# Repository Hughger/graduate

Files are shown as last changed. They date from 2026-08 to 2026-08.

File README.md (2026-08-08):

# FLOOD Accelerator — Graduate Workspace

`graduate` 是从现有 FLOOD 工作目录中提取的加速器维护副本，建立于 2026-08-07。原文件均保留在原位；这里不包含原仓库的 Git 历史、完整 SDK 工具链、IDE/综合缓存或历史压缩包。

> 当前内容来自带有本地提交和未提交改动的工作树，不是正式 release。首次提交或对外分发前，请先阅读 [SOURCE_STATE.md](./SOURCE_STATE.md)。

## 当前研究方向（2026-08-08）

本工作区当前以 **Stable Diffusion 1.5 U-Net ResNetBlock 的 AXKU15 FPGA 原型**为研究主线，复用 FLOOD 的 INT8 计算结构，重点研究片上驻留、算子融合和双缓冲数据流。目标不是一次性硬化完整 SD，而是先完成可验证、可综合、可上板的真实 ResNetBlock 加速器。

- 正式设计规格：[SD1.5 ResNetBlock 加速器设计](./docs/superpowers/specs/2026-08-08-sd15-resnetblock-accelerator-design.md)
- 实施计划：[SD1.5 ResNetBlock AXKU15 加速器实施计划](./docs/superpowers/plans/2026-08-08-sd15-resnetblock-accelerator-implementation.md)
- 板卡用户手册：[AXKU15 V1.2 用户手册](./AXKU15_V1.2_UG.pdf)
- 板级原理图：[AXKU15 扩展板原理图](./01_原理图PCB结构图等硬件资料/AXKU15原理图V1.0.pdf)、[ACKU15 核心板原理图](./01_原理图PCB结构图等硬件资料/ACKU15核心板.pdf)

现有 CNN Demo、MacMachine 和六周执行计划继续保留，作为 FLOOD 基线、接口审计和回归验证资料；其历史参数与任务优先级不覆盖上述正式设计规格。

## 目录

```text
graduate/
├─ accelerator/                  # FLOOD 加速器主体，保留原工程相对结构
│  ├─ src/                       # Chisel/Scala、Python、C 辅助代码与测试
│  ├─ rtl/                       # E203/FLOOD RTL
│  ├─ c/                         # APB/AXI/UART 测试与 CNN 示例
│  ├─ tb/                        # Verilog testbench 与测试向量
│  ├─ tests/                     # 单元/公共测试框架
│  ├─ tools/                     # 量化与数据生成工具
│  ├─ vsim/                      # 仿真入口
│  ├─ fpga/                      # FPGA 源码、约束和构建脚本
│  ├─ doc/                       # Sphinx/参考文档
│  └─ pics/                      # README/文档图片
├─ integrations/
│  ├─ chip-test-vivado/          # 精简后的 Vivado 芯片测试工程
│  ├─ hbird-sdk-overlay/         # 需要应用到指定 hbird-sdk 的本地定制层
│  └─ board-interface/           # 引脚、连接器、转接板和 PCB 约束输入
├─ validation/
│  ├─ plans/                     # HPCA/PyTorchSim 测试方案与结果清单
│  └─ netlists/                  # Fan-out 网络表
├─ docs/superpowers/{specs,plans}/ # 正式设计规格与实施计划
├─ 01_原理图PCB结构图等硬件资料/ # AXKU15/ACKU15 原理图与结构资料
└─ planning/                     # 历史计划与后续任务拆分
```

## 主要入口

- 当前正式设计规格：[docs/superpowers/specs/2026-08-08-sd15-resnetblock-accelerator-design.md](./docs/superpowers/specs/2026-08-08-sd15-resnetblock-accelerator-design.md)
- 当前实施计划：[docs/superpowers/plans/2026-08-08-sd15-resnetblock-accelerator-implementation.md](./docs/superpowers/plans/2026-08-08-sd15-resnetblock-accelerator-implementation.md)
- 加速器说明：[accelerator/README.md](./accelerator/README.md)
- Chisel/Scala 主源码：[accelerator/src/main](./accelerator/src/main/)
- RTL：[accelerator/rtl/e203](./accelerator/rtl/e203/)
- AXI 软件测试：[accelerator/c/axi_test](./accelerator/c/axi_test/)
- 仿真入口：[accelerator/vsim/README.md](./accelerator/vsim/README.md)
- FPGA 工程：[accelerator/fpga/README.md](./accelerator/fpga/README.md)
- AXKU15 集成：[accelerator/fpga/AXKU15](./accelerator/fpga/AXKU15/)
- Vivado 芯片测试工程：[integrations/chip-test-vivado/system_chip_test.xpr](./integrations/chip-test-vivado/system_chip_test.xpr)
- SDK 覆盖层：[integrations/hbird-sdk-overlay](./integrations/hbird-sdk-overlay/)
- PyTorchSim 测试执行方案：[validation/plans/FLOOD_PyTorchSim测试执行方案.md](./validation/plans/FLOOD_PyTorchSim测试执行方案.md)

## 使用方式

### 1. 加速器 RTL/Chisel

进入 `accelerator`，先阅读原工程 README、`build.sbt`、`e203_core.core` 和 `e203_soc.core`。本副本保留了当前工作树中的 Scala、RTL、C、测试和工具文件，但没有复制原来的 `.git` 和 SBT/IDE 缓存。

### 2. 软件与 SDK

完整 hbird-sdk 未复制。请准备远端 `https://gitee.com/riscv-mcu/hbird-sdk.git` 在提交 `321ecb29f64197748a4a4bdb9f42c0961cb8145b` 附近的工作树，再审查并应用 `integrations/hbird-sdk-overlay/hbird-sdk` 中的覆盖文件。覆盖层包含当前本地修改，不能无审查覆盖到其他 SDK 版本。

### 3. FPGA/Vivado

`accelerator/fpga` 保留 FPGA 源码、约束和脚本，但删除了两个约 26.1 MB 的预生成 MCS。`integrations/chip-test-vivado` 保留 `.xpr`、约束、XCI、RTL、C 和初始化数据，未复制 Vivado cache/runs、可执行文件、DCP 和结果文本。工程原目录显示使用过 Vivado 2022.2；在其他版本打开时先备份并检查升级提示。

### 4. 验证

`validation/plans` 是测试目标和执行流程，`validation/netlists` 是板级网络数据。新增实验结果时建议按“日期—配置—提交—结果”命名，并记录对应 RTL、软件、bitstream 和模型版本。

## 维护规则

1. 将 `graduate` 视为独立维护副本；不要假设它会与原目录自动同步。
2. 首次建立 Git 历史前，先确认 `SOURCE_STATE.md` 中列出的本地改动均已纳入或明确放弃。
3. 不提交工具链、虚拟机、Vivado cache/runs、SBT target、波形和临时压缩包。
4. 生成物放入独立 `artifacts/<date-or-revision>/`，并附提交号、工具版本和校验值。
5. SDK 修改优先以 overlay/patch 维护，不再复制整套 3.47 GiB 工具链。
6. 对外发布时另建 release 包；本目录本身不是 PCB/SMT 或 FPGA 生产交付包。

## 本次未复制

- 所有 `.git` 历史及 Git 对象。
- 完整 `hybird_sdk`/`NUCLEI_TOOL_ROOT`。
- Vivado `.Xil`、cache、runs、gen、hw、sim、IP user files 和既有 bitstream。
- `fpga.zip`、`src/main/scala.zip`、根目录工程压缩包及虚拟机/IDE 环境。
- 两个 `prebuilt_mcs/system.mcs`。
- HPCA 论文调研模板、旧版周任务、旧执行计划和与加速器维护无直接关系的历史材料。

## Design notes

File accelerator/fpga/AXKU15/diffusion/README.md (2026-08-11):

# AXKU15 board flow

This folder separates two bring-up stages deliberately:

1. `rtl/axku15_diffusion_bringup.v` + `constrs/axku15_bringup.xdc` creates a
   no-DDR smoke bitstream.  It proves the selected XCKU15P part, JTAG download,
   200 MHz system clock (`G12/G11`), reset and four LEDs before a large design
   is introduced.
2. `scripts/extract_ddr4_pins.py` emits the DDR4 package-pin XDC from the
   checked-in AXKU15 manual.  It captures the complete 80-bit memory interface
   without hand-copying pins.  A future Vivado DDR4 MIG must provide the same
   port names and own IOSTANDARD/termination settings.

## Build the smoke bitstream

From this directory, run:

```powershell
vivado -mode batch -source scripts/build_bringup.tcl
```

The bitstream is written below `build/bringup_nonproject/`.  Program it through
Vivado Hardware Manager.  LED2 stays on after configuration; LED1 and LED4
blink, and LED3 reflects release of `KEY1` reset.

## Generate and verify DDR4 pin constraints

```powershell
python scripts/extract_ddr4_pins.py --output constrs/axku15_ddr4_pins.xdc
python -m unittest discover -s tests -v
```

The script requires exactly 80 distinct DQ pins and emits all DQ, DM/DBI,
DQS, address, bank and command pins.  It intentionally does **not** generate a
MIG `.xci`: MIG electrical settings and board timing must be created and
validated with the installed Vivado version before synthesis.  The documented
DDR4 reference clock is `AR32/AT32`; it is emitted as `ddr4_ref_clk_p/n` and is separate from the bring-up logic clock at `G12/G11`.

## Verified implementation evidence

The bring-up flow was run with Vivado 2024.2 on this repository revision. It completed synthesis, implementation and bitstream generation for `xcku15p-ffve1517-2-i` with zero DRC errors. At a 200 MHz constraint, the post-route setup WNS was **4.220 ns** (TNS 0.000 ns); the generated bitstream was 36,343,241 bytes. These numbers apply only to the small clock/LED smoke top, not to the future DDR4/MIG accelerator implementation. See [DDR4 MIG compatibility](docs/ddr4_mig_compatibility.md) before using the 64-bit candidate constraints; an 80-bit AXKU15 MIG remains unclosed. See also [the official DDR4 demo assessment](docs/OFFICIAL_DDR4_DEMO_ASSESSMENT.md): its vendor bitstream is a useful 64-bit baseline, not proof of 80-bit closure.
## Actual accelerator RTL validation

`GenerateDiffusionAccelTopVerilog` emits the real `DiffusionAccelTop` rather
than the lightweight `DiffusionContractTop`. The resulting Verilog keeps the
AXI-Lite, DMA and MIG application-port seams and is intended for the board
wrapper once the physical DDR4 controller is qualified.

A bounded Vivado 2024.2 `synth_design -rtl` check on
`xcku15p-ffve1517-2-i` completed RTL elaboration in 7 minutes 08 seconds at a
5,256 MB peak memory footprint, then entered RTL optimization. It was stopped
at the 10-minute safety limit, so it is evidence of successful RTL parsing and
hierarchy elaboration only—not a completed synthesis, timing result or resource
closure. The corresponding full OOC synthesis reached RTL component statistics
but did not finish within a 30-minute limit. Use the checked-in scripts to
repeat those bounded checks; do not claim AXKU15 implementation closure from
these partial results.

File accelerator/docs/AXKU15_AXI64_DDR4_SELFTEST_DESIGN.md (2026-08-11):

# AXKU15 AXI64 DDR4 self-test harness design

## Objective

Create a board-oriented harness that tests the newly integrated 512-bit to
64-bit AXI bridge through the official DDR4 core without modifying the vendor
demo.  The harness runs autonomously after DDR4 calibration: it writes one
known 512-bit word, reads the same address back, and exposes calibration,
active, pass, and fail status for LEDs or external observation.

This is a DDR4 transport-validation increment, not a Stable Diffusion inference
demo.  It deliberately avoids pretending that the official demo has a host
control plane for the full accelerator.

## Architecture

1. `Axi64DdrSelfTest` is a small Chisel module.  It instantiates the existing
   `MigAppToAxi64Bridge`, waits for `calibrated`, issues one 512-bit write,
   waits for an OKAY B response, issues the matching 512-bit read, and compares
   all 512 bits.
2. It has no external request input.  The fixed address is 64-byte aligned and
   the fixed data contains eight distinct 64-bit words, so both AXI burst order
   and bridge read reassembly are exercised.
3. `GenerateAxi64DdrSelfTestVerilog` emits that module independently of
   `DiffusionAccelTop`.
4. `axku15_axi64_ddr4_selftest.v` is a thin SystemVerilog wrapper.  It
   instantiates the unmodified vendor `ddr4_core` and the generated self-test,
   maps the complete AXI channels, and maps statuses to the existing four LED
   pins: `led[0]=calibrated`, `led[1]=active`, `led[2]=passed`,
   `led[3]=failed`.
5. A parameterized non-project Vivado Tcl flow reads the user-selected vendor
   XCI and its matching XDC by path; it writes outputs only under this
   repository's `build/` directory.

## Reset and calibration rules

- The harness clock is `c0_ddr4_ui_clk`; reset is asserted by
  `c0_ddr4_ui_clk_sync_rst` or deasserted `c0_ddr4_aresetn`.
- `c0_init_calib_complete` is an input to the harness state machine.  No AXI
  request is issued until it is high.
- A non-OKAY B/R response or a 512-bit read mismatch sets sticky `failed`.
- `passed` and `failed` are mutually exclusive and remain asserted until reset.
- The vendor core's `c0_alert_n` is exposed by the wrapper but is not treated as
  a substitute for an AXI data-integrity result.

## Source ownership and constraints

The wrapper never edits, copies into place, or regenerates the official demo's
XCI/RTL/XDC.  The build command takes absolute or relative paths to those
artifacts.  The existing 64/80-bit and DRAM-part mismatch remains a physical
validation risk; a successful tool build alone is not a calibration or memory
test result.

## Acceptance tests

1. Unit simulation demonstrates no request before `calibrated`, eight ordered
   write beats, eight ordered read beats, and sticky pass after a matching read.
2. Separate simulations demonstrate sticky fail for a read mismatch and an
   AXI error response.
3. The self-test Verilog generator exits successfully and its output contains
   all AXI64 channel groups plus status outputs.
4. The wrapper is linted/elaborated only when the user supplies a matching
   vendor XCI/XDC.  A successful bitstream is documented as implementation
   evidence, while physical programming/calibration is a separately authorized
   lab action.

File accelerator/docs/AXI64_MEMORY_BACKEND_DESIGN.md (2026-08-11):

# AXI64 memory-backend integration design

## Goal

Allow the existing diffusion top to use either its current 512-bit MIG
application-port backend or the new 64-bit AXI4 bridge.  The default generated
top must preserve the current MIG seam and behavior.  A second generated top
must expose AXI64 so it can be connected to the official AXKU15 DDR4 demo in a
later Verilog wrapper.

## Confirmed interface boundary

`DiffusionAccelTop` currently connects `MigAppRequestArbiter` to a single
`MigAppTransfer`, then exposes the transfer's raw `MigAppPort`.  In contrast,
`MigAppToAxi64Bridge` consumes the request/response/done side of that
connection.  Therefore the bridge must replace `MigAppTransfer` *inside* the
diffusion top; placing it after `io.mig` would mismatch protocols and duplicate
serialization.

The official demo supplies a 64-bit AXI4 slave with `AW`, `W`, `B`, `AR`, and
`R`, a UI clock/reset pair (`c0_ddr4_ui_clk`, `c0_ddr4_aresetn`), and
`c0_init_calib_complete`.

## Alternatives

1. Add a raw `MigAppPort` to AXI converter outside the top.  It would retain
   the current serializer, but duplicates the already tested request-level
   bridge and creates two incompatible conversion boundaries.  Not selected.
2. Fork the complete diffusion top for the AXI path.  This gives a direct
   interface but would duplicate a large evolving data path.  Not selected.
3. Select the backend at `DiffusionAccelTop` construction.  Both backend
   choices share one `MigAppRequestArbiter`; the original is the default and
   the alternate instantiates `MigAppToAxi64Bridge`.  This is selected.

## Selected architecture

`DiffusionAccelTop` receives a constructor parameter:

```scala
class DiffusionAccelTop(
    resultDepth: Int = 128,
    memoryBackend: DiffusionMemoryBackend = DiffusionMemoryBackend.MigApp
) extends Module
```

`DiffusionMemoryBackend` has exactly `MigApp` and `Axi64` values.  The IO keeps
both named seams (`mig` and `axi64`) so either generated RTL variant has stable
port names.  Only the selected backend is live:

- `MigApp`: preserve the current `MigAppTransfer` connections and tie AXI64
  master outputs inactive; AXI64 return channels are ignored.
- `Axi64`: connect the arbiter's request/response/done interface directly to
  `MigAppToAxi64Bridge`; tie MIG command outputs inactive and ignore its return
  inputs.

The performance monitor's memory-stall term is selected with the backend:
MIG uses app ready signals; AXI64 uses any active AXI channel with its ready
low, including B/R response waiting.  The existing one-cycle-per-cycle stall
definition remains unchanged.

`GenerateDiffusionAccelTopVerilog` continues to emit the default MIG variant.
`GenerateDiffusionAccelAxi64TopVerilog` emits the alternate variant to
`target/generated/diffusion-accel-axi64-top`.

## Board-wrapper boundary

The follow-on SystemVerilog wrapper will instantiate the vendor `ddr4_core`
unchanged and an AXI64 generated top.  It uses the MIG UI clock as the
accelerator clock and asserts accelerator reset until both `c0_ddr4_aresetn`
and `c0_init_calib_complete` are high.  The wrapper maps only the complete
official AXI4 channel fields, adding fixed AXI fields (`burst=INCR`, cache/prot/
qos/user zero) that are not modelled by the Chisel bridge.

This design does not copy vendor files, regenerate an XCI, connect physical
DDR pins, or claim DDR4 calibration.  Those activities occur only after the
alternate top passes its simulation and generation tests.

## Acceptance tests

1. Existing `DiffusionAccelTop` tests and default Verilog generation preserve
   MIG behavior.
2. An AXI64-backend top test submits a request through the existing external
   memory port and observes the eight-beat bridge transaction.
3. AXI64-backend tests prove that MIG outputs remain inactive and that an AXI
   response drives the existing memory response/done path.
4. The AXI64 generated RTL contains the `axi64_aw`, `axi64_w`, `axi64_b`,
   `axi64_ar`, and `axi64_r` signals.
5. No test, source file, XCI, or constraint is written under the user-provided
   official demo directory.

## Verification record

On 2026-08-11, `DiffusionAccelTopAxi64Spec` verified that the default top still
uses MIG with AXI64 idle and that the AXI64 variant keeps MIG commands inactive
while reassembling an eight-beat read into the existing memory response.  The
selected default-top, AXI64-top, and bridge test scope passed 10/10 cases.

Both `GenerateDiffusionAccelTopVerilog` and
`GenerateDiffusionAccelAxi64TopVerilog` completed successfully.  The latter
emits all five AXI64 channel groups (`axi64_aw`, `axi64_w`, `axi64_b`,
`axi64_ar`, and `axi64_r`).  No vendor source, XCI, constraint, physical pin,
or board-calibration claim is included in this result.

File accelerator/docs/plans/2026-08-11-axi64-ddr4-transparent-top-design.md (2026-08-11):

# AXKU15 AXI64 DDR4 Transparent Accelerator Top Design

**Date:** 2026-08-11  
**Status:** Approved design; implementation deferred pending accelerator verification

## Goal

Define a project-owned AXKU15 top-level integration that will connect the
`DiffusionAccelTop` AXI64 memory backend to the already validated, project-owned
copy of the official DDR4 controller IP.  This milestone proves that the
accelerator's 64-bit AXI4 memory boundary can be elaborated with the board DDR4
controller without modifying the official demo or its source IP.  The user has
chosen to defer this integration until the accelerator design and verification
work is complete.

## Deferred implementation scope

The integration adds:

- a Chisel generation entry point that instantiates
  `DiffusionAccelTop(memoryBackend = DiffusionMemoryBackend.Axi64)`;
- a transparent Verilog board wrapper that instantiates that generated module
  and `ddr4_core`;
- a Vivado RTL-elaboration Tcl script that attaches the project-owned DDR4 DCP
  and generated DDR4 constraints explicitly; and
- build and design documentation.

The wrapper connects the accelerator AXI4 master channels directly to
`ddr4_core`'s 64-bit AXI4 slave interface:

| Accelerator channel | DDR4 IP channel |
| --- | --- |
| AW | `c0_ddr4_s_axi_aw*` |
| W | `c0_ddr4_s_axi_w*` |
| B | `c0_ddr4_s_axi_b*` |
| AR | `c0_ddr4_s_axi_ar*` |
| R | `c0_ddr4_s_axi_r*` |

All accelerator controls and data-plane interfaces that do not belong to DDR4
remain wrapper top-level ports.  They are deliberately neither tied off nor
replaced by an autonomous controller.

## Clock and reset

`c0_ddr4_ui_clk` clocks the generated accelerator.  The accelerator reset is
asserted while the DDR4 UI reset is asserted or its active-low UI reset output
is inactive.  `c0_init_calib_complete` is exported as an observation signal;
the integration does not claim memory is usable before calibration completes.

The board-facing DDR4 clock, reset, pin signals, and board XDC remain those of
the official AXKU15 DDR4 demo.  The integration uses the repository-owned
upgraded controller copy and its matching DCP/XDC artifacts.

## Deferred validation

The implementation must:

1. pass the focused Scala/Chisel tests for the AXI64 backend;
2. generate the AXI64-backend accelerator Verilog;
3. complete Vivado `synth_design -rtl` with the project-owned controller DCP
   attached explicitly; and
4. leave the official demo and official source IP unmodified.

The existing autonomous DDR4 self-test remains the physical-link baseline.  It
is not replaced by this structural integration test.

## Explicit exclusions

This milestone does not add UART, PCIe, a soft processor, or another host
control plane.  It does not execute a complete SD1.5 workload, run placement or
routing, generate a bitstream, or program the FPGA.

The official demo's 64-bit DDR4 configuration is accepted as the current
project baseline.  The separately observed 64/80-bit board-document mismatch
is deferred to hardware-validation and thesis-limitations work; acceptance of
this baseline is not evidence that 80-bit hardware operation has been proven.

## Prerequisite and follow-on work

Before implementation of this wrapper, the project will complete functional
design and simulation-based verification of one SD1.5 ResNetBlock, including
its scheduler, convolution, GroupNorm, residual path, DMA, and AXI64
behavioural-memory interactions.  The resulting verification evidence becomes
the prerequisite for restoring this board-integration milestone.

Host control, SD1.5 workload submission, and implementation/timing/bitstream
work are separate follow-on milestones.  Keeping them separate preserves this
milestone as a narrow, reproducible accelerator-to-DDR4 integration boundary.

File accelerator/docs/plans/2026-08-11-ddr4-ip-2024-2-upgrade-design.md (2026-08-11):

# AXKU15 DDR4 IP 2024.2 upgrade-copy design

## Objective

Create a project-owned Vivado 2024.2-compatible copy of the official AXKU15
DDR4 IP so the AXI64 DDR4 self-test can be built reproducibly without editing
the vendor demo.

## Scope and ownership

- Copy, never modify, the official `ddr4_core.xci` and only the generated
  artifacts Vivado requires for the project copy.
- Keep the vendor demo directory read-only throughout the workflow.
- Place the owned IP and a manifest under `accelerator/fpga/AXKU15/diffusion`.
- Update the self-test Tcl flow to consume only the owned 2024.2 XCI.
- Do not run implementation, generate a bitstream, or program the board in
  this slice.

## Architecture

The existing `axku15_axi64_ddr4_selftest` wrapper remains the only RTL client.
It exposes the self-test's 64-bit AXI4 master directly to the copied DDR4 IP.
The copied IP preserves the official 64-bit DQ and eight-DQS interface plus
the existing 64-bit AXI4 interface. Vivado 2024.2 upgrades and generates the
project copy; its upgraded XCI becomes the build input. The official 2022.2
XCI and DCP are provenance artifacts only and are not read by the upgraded
build path.

## Validation and failure handling

The build performs RTL elaboration and a synthesis pass only. It fails if the
copied XCI remains locked, if the wrapper/IP interfaces do not elaborate, or
if synthesis reports errors or critical warnings. The build report records the
source and generated tool versions, part, IP configuration, and generated
file hashes so the copy is auditable.

The known physical-interface discrepancy is deliberately not hidden: the
official core has `c0_ddr4_dq[63:0]` and eight DQS pairs, while the currently
available board constraint references 80 DQ bits and ten DQS pairs. Therefore
implementation and programming remain prohibited until the AXKU15 schematic
and DDR4 topology are reconciled.

## Acceptance criteria

1. The official demo directory is unchanged.
2. Vivado 2024.2 reports the project-owned IP as unlocked after upgrade.
3. The AXI64 DDR4 self-test elaborates and synthesizes against the owned IP
   without errors or critical warnings.
4. A checked-in manifest makes the source, version, configuration, and hashes
   of the copied IP explicit.
5. No bitstream is written and no board is programmed.
## Execution update

The project-owned copy was upgraded by Vivado 2024.2 from DDR4 IP revision 17
to revision 24. Its local OOC DCP was generated with `synth_ip`; the generated
files are ignored while the XCI and manifest remain versioned. The official
demo directory was not modified.

Vivado 2024.2 stalled when the non-project self-test flow used `read_ip` to
automatically attach the upgraded DCP. The accepted elaboration-only path now
requires the co-located manifest, DCP, and generated IP XDC, explicitly
attaches the DCP to `u_ddr4_core/inst`, and reads the IP XDC after the board
XDC. It has completed RTL elaboration with zero critical warnings and zero
errors. This does not authorize implementation, bitstream generation, or board
programming, and it does not resolve the physical 64/80-bit mismatch.

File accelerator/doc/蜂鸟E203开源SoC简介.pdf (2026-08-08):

# 蜂鸟 E203 开源 SoC 介绍

蜂鸟 E203 开源 SoC 简介

2

## Content

3

4

## Tables

5

## Figures

- 6 -

## 1 Preface

## 1.1 Revision History

Date | Version | Author | Change Summary
Oct 20,2018 | 1.0 | Bob Hu | Initial Version

## 1.2 Reference Documentation

https://github.com/SI-RISCV/e200_opensource/tree/master/doc/SiFive-E300-platform-reference-manual-v1.0.1. pdf
https://github.com/SI-RISCV/e200_opensource/tree/master/doc/SiFive-E310-G000-manual-v1.0.1.pdfhttps://github.com/SI-RISCV/e200_opensource/tree/master/doc/SiFive-E3-C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 mentation.pdf
中文书籍《手把手教你设计 CPU：RISC-V 处理器篇》
中文书籍《RISC-V 架构与嵌入式开发快速入门》

- 7 -

## 2 总体介绍

本文介绍全开源的蜂鸟 E203 RISC-V 处理器核以及配套开源 SoC，为了方便描述，本文档中将此 SoC 简称为“蜂鸟 E203 SoC”。
注意：
■ | 本文档对蜂鸟 E203 内核以及 RISC-V 指令集架构的介绍尚不够详细，在中文书籍《手把手教你设
| 计 CPU：RISC-V 处理器篇》或者《RISC-V 架构与嵌入式开发快速入门》中对其进行深入浅出地系
| 统的讲解，感兴趣的用户可以自行搜索书籍。
■ | 本文档对 SoC 的各外设的介绍尚不够详细，在中文书籍《RISC-V 架构与嵌入式开发快速入门》
| 中进行了深入浅出的系统讲解。感兴趣的用户可以自行搜索此书。

注意：
■ | 本 SoC 的代码全开源，有关其代码结构的详情，请参见《蜂鸟 E203 快速上手介绍》。
■ | 本开源 SoC 主要面向教育教学和爱好者领域，源代码全部开放。理论上可以用于商业目的，但
| 是不保证其商用质量和服务。
■ | The main purpose of this open-sourced core is to be used by students/university/research and entry-level-beginners, hence, the commercial quality (bug-free) and service of this core is not not not warranted!!!

## 2.1 总体特性

本 SoC 总体特性如下：
■ | 使用全开源的蜂鸟 E203 处理器核，此处理器核包括如下特性：
| 超低功耗 2 级流水线处理器核
| 64KB ITCM，64KB DTCM
| 有关蜂鸟 E203 的更多信息参见第 3 章
■ | 为了尽量的共享当前 RISC-V 的软件生态，将尽可能的复用 SiFive 公司开源的 Freedom 310（HiFive1
| 开发板所使用）SoC，包括：
| 对其已有的 IP 进行复用兼容
| 对其总线地址分配进行兼容
■ | 在兼容 Freedom 310 SoC 的基础上，增加如下 IP，使其 SoC 功能更加丰富：
| I2C Master

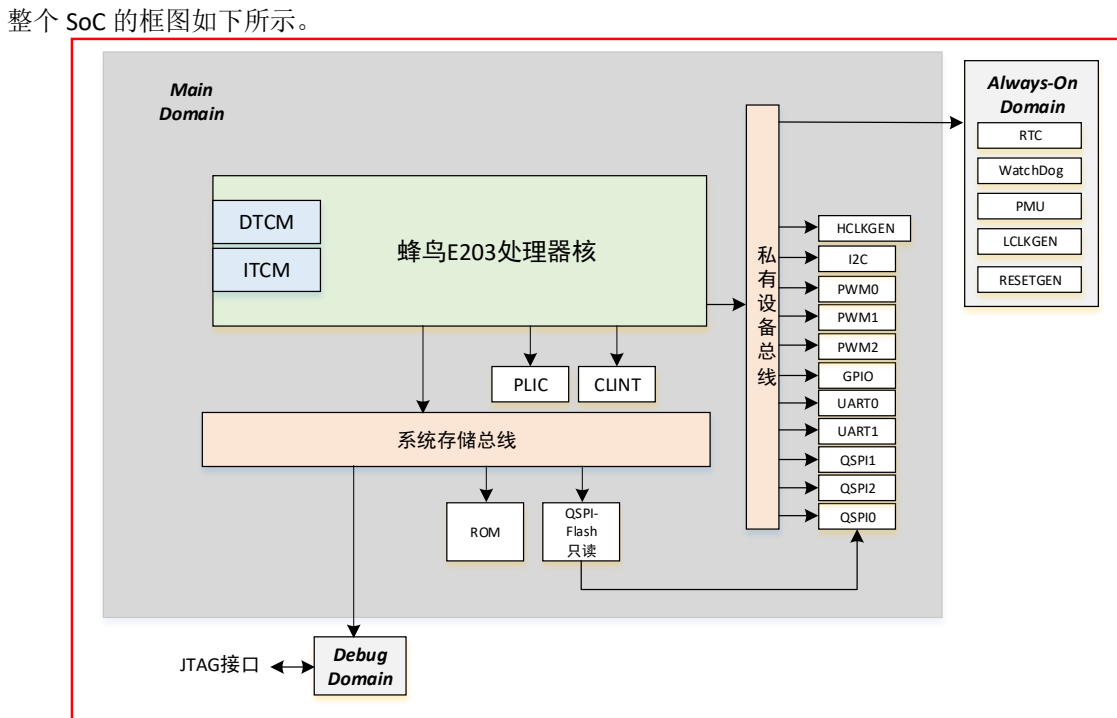
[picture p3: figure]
整个 SoC 的框图如下所示。; 系统存储总线; ROM; Debug Domain; 蜂鸟E203处理器核; DTCM; ITCM; QSPI- Flash 只读; GPIO; QSPI0; UART0; UART1; QSPI1; QSPI2; PWM2; PWM1; PWM0; Always-On Domain; PLIC; CLINT; JTAG接口; Main Domain; RTC; WatchDog; PMU; HCLKGEN; LCLKGEN; RESETGEN

- 8 -

## 2.2 SoC 整体框图

Figure 2-1 SoC 整体框图

上图中除了蜂鸟 E203 处理器核和总线之外，其他的主要外部设备 IP 模块均复用来自 Freedom E310 SoC 平台。图中用红色线框包含的模块为开源 Freedom E310 SoC 平台所不具备的（因为其开源的是 FPGA 平台源代码），需要我们自己设计添加，包括：

■ | I2C Master：使用开源的 I2C Master IP。
■ | HCLKGEN：用于使用 PLL 生成高速时钟（用于 Main Domain）。
■ | LCLKGEN：生成低速时钟（用于 Always-onDomain）。
■ | RESETGEN：用于为 SoC 生成复位逻辑。

## 2.3 总线地址分配

本 SoC 的总线地址分配如下表所示。注意，下表中：

■ | 普通部分为与 Freedom E310 兼容且已经存在的 IP 及其地址分配。
■ | 绿色高亮部分为本项目自研 RISC-V 核特有的部分。

- 9 -
■ | 黄色高亮部分为本项目新定义的系统 IP 及其地址分配区间。
■ | 蓝色高亮部分为 Freedom E310 芯片中存在的 IP 及其地址分配，但是目前本 SoC 中还没有的 IP。

Table 2-1 SoC 地址分配表

总线分组 | 组件 | 地址区间 | 描述
Core 直属 | CLINT | 0x0200_0000 ~ 0x0200_FFFF | Core Local Interrupt Controller 模块寄存器地址 区间
| PLIC | 0x0C00_0000 ~ 0x0CFF_FFFF | Platform Level Interrupt Controller 模块寄存器地址 区间
| ITCM | 0x8000_0000 ~ 0x8001_FFFF | ITCM 地址区间
| DTCM | 0x9000_0000 ~ 0x8001_FFFF | DTCM 地址区间
系统存储总线接口 | Debug Module | 0x0000_0000 ~ 0x0000_0FFF | 注意：Debug Module 主要 用于调试器使用，普通软件 程序不应该使用此区间
| ROM | 0x0000_1000 ~ 0x0000_1FFF | 注意：开源的 E203 项目由 于是 FPGA 原型，因此 Mask-ROM 代码为一行为 模型。 在本 SoC 中考虑将其固化 成为逻辑，而不是真的使用 ROM IP。
| Off-Chip QSPI0 Flash Read | 0x2000_0000 ~ 0x3FFF_FFFF | 外部 SPI Flash 只读地址区 间。 有关 SPI Flash，详见后文介 绍。
私有设备总线接口 （总区间为 0x1000_0000 ~ 0x1FFF_FFFF） | Always-On | 0x1000_0000 ~ 0x1000_7FFF | Always-on 模块包含 PMU，RTC，WatchDog， LCLKGEN。
| HCLKGEN | 0x1000_8000 ~ 0x1000_8FFF | 高速时钟生成模块

- 10 -
GPIO | 0x1001_2000 ~ 0x1001_2FFF | GPIO 地址区间。

有关 GPIO，详见后文介绍。

UART0 | 0x1001_3000 ~ 0x1001_3FFF | 第一个 UART 模块地址区 间。有关 UART，详见后文 介绍。
QSPI0 | 0x1001_4000 ~ 0x1001_4FFF | 第一个 QSPI 模块地址区 间。有关 SPI，详见后文介 绍。
PWM0 | 0x1001_5000 ~ 0x1001_5FFF | 第一个 PWM 模块地址区 间。有关 PWM，详见后文 介绍。
UART1 | 0x1002_3000 ~ 0x1002_3FFF | 第二个 UART 模块地址区 间。
QSPI1 | 0x1002_4000 ~ 0x1002_4FFF | 第二个 QSPI 模块地址区 间。
PWM1 | 0x1002_5000 ~ 0x1002_5FFF | 第二个 PWM 模块地址区 间。
QSPI2 | 0x1003_4000 ~ 0x1003_4FFF | 第三个 QSPI 模块地址区 间。
PWM2 | 0x1003_5000 ~ 0x1003_5FFF | 第三个 PWM 模块地址区 间。
I2C Master | 0x1004_2000 ~ 0x1004_2FFF | IC2 Master
其他地址区间 | 上表中未使用到的地址区间，则均为写忽略，读返回 0

- 11 -

## 3 RISC-V 核介绍

注意：
■ | 本文档对蜂鸟 E203 处理器内核以及 RISC-V 指令集架构的介绍尚不够详细，在中文书籍《手把手
| 教你设计 CPU：RISC-V 处理器篇》中对其进行深入浅出地系统的讲解。感兴趣的用户可以自行
| 搜索此书。

## 3.1 处理器核简介

本 SoC 使用的处理器核为开源的蜂鸟 E203 RISC-V 处理器核。

蜂鸟 E203 内核的特性简介如下：

■ | E203 内核采用 2 级流水线结构，通过一流的处理器架构设计，该 CPU 核的功耗与面积均优于同
| 级 ARM Cortex-M 核，实现业界最高的能效比与最低的成本。
■ | E203 内核能够运行 RISC-V 指令集，支持 RV32IMAC 等指令子集的配置组合，仅支持机器模式
| （Machine Mode Only）。
■ | E203 内核提供标准的 JTAG 调试接口，以及成熟的软件调试工具。
■ | E203 内核提供成熟的 GCC 编译工具链。
参见《手把手教你设计 CPU——RISC-V 处理器篇》了解开源蜂鸟 E203 的详情。

## 3.2 处理器核中断

蜂鸟 E203 内核的中断分为三种类型：

■ | 计时器中断，由 CLINT 模块产生。
■ | 软件中断，由 CLINT 模块产生。
■ | 外部中断，由 PLIC 管理产生。
对于 RISC-V 架构中断的详细介绍，本文档在此不展开赘述，用户参见中文书籍《手把手教你设计 CPU：RISC-V 处理器篇》第 13 章中对其进行深入浅出地系统的讲解。

### 3.2.1 CLINT

本文在此仅对 CLINT 进行中文简述。

有关 CLINT 的详细，用户可以选择中文书籍《手把手教你设计 CPU：RISC-V 处理器篇》第 13 章中 对其进行深入浅出地系统的讲解。

- 12 -

CLINT 全称为 Core Local Interrupts Controller。CLINT 是一个存储器地址映射（Memory Address Mapped）的模块，挂载在处理器核为其实现的专用总线接口上，在蜂鸟 E203 内核配套的 SoC 中其寄存 器的地址区间如下表所示。CLINT 的寄存器只支持 size 为 32 位的读写访问。

Table 3-1 CLINT 寄存器的 Memory Mapped Address

地址 | 寄存器名称 | 功能描述
0x0200_0000 | msip | 生成软件中断
0x0200_4000 | mtimecmp | 配置计时器的比较值
0x0200_BFF8 | mtime | 反映计时器的值

CLINT 可以用于生成软件中断，其要点如下：

■ | CLINT 中实现了一个 32 位的 msip 寄存器，该寄存器只有最低位为有效位，该寄存器有效位直
| 接作为软件中断（Software Interrupt）信号通给处理器核。
■ | 当软件写 1 至 msip 寄存器触发了软件中断之后，前文中介绍的 CSR 寄存器 mip 中的 MSIP 域便
| 会置高指示当前中断 pending 状态。
■ | 软件可通过写 0 至 msip 寄存器来清除该软件中断。

CLINT 可以用于生成计时器中断，其要点如下：

■ | CLINT 中实现了一个 64 位的 mtime 寄存器，该寄存器反映了 64 位计时器的值。计时器根据低
| 速的输入节拍信号进行计时。
■ | CLINT 中实现了一个 64 位的 mtimecmp 寄存器，该寄存器作为计时器的比较值，假设计时器的
| 值 mtime 大于或者等于 mtimecmp 的值时，则产生计时器中断。软件可以通过改写 mtimecmp 的
| 值来清除计时器中断。

### 3.2.2 PLIC

本文在此仅对 PLIC 进行中文简述。

有关 PLIC 的详细，用户可以参见中文书籍《手把手教你设计 CPU：RISC-V 处理器篇》第 13 章中 对其进行深入浅出地系统的讲解。

PLIC 全称为 Platform Level Interrupt Controller。PLIC 是 RISC-V 架构标准定义的系统中断控制器， 主要用于多个外部中断源的优先级仲裁和派发。

- 13 -

如图 2-1 中所示，PLIC 是一个存储器地址映射（Memory Address Mapped）的模块，挂载在处理器核 为其实现的专用总线接口上，在蜂鸟 E203 内核配套的 SoC 中其寄存器的地址区间如下表所示。PLIC 的 寄存器只支持 size 为 32 位的读写访问。

Table 3-2 PLIC 寄存器的 Memory Mapped Address

地址 | 寄存器名称 | 功能描述
0x0C00_0004 | Source 1 priority | 中断源 1 的优先级
0x0C00_0008 | Source 2 priority | 中断源 2 的优先级
…… | …… | ……
0x0C00_0FFC | Source 1023 priority | 中断源 1023 的优先级
…… | …… | ……
0x0C00_1000 | Start of pending array （read-only） | 中断等待标志的起始地址
…… | …… | ……
0x0C00_107C | End of pending array | 中断等待标志的结束地址
0x0C00_2000 | Target 0 enables | Target 0 的使能位
…… | …… | ……
0x0C20_0000 | Target 0 priority threshold | Target 0 的优先级门槛

注意：
- 该 PLIC 理论上可以支持多大 1024 个中断源。
- 该 PLIC 理论上可以支持多个中断目标（Target）。由于蜂鸟 E203 内核是一个单核处理器， 且仅实现了 Machine Mode，因此仅用到 PLIC 的 Target0，表中的 Target0 即为蜂鸟 E203 内核。

PLIC 理论上可以支持高达 1024 个外部中断源，在具体的 SoC 中连接的中断源个数可以不一样。蜂

鸟 E203 内核的 SoC 系统是基于 Sifive 公司开源的 Freedom E310 SoC 开发所得。PLIC 在此 SoC 中连接了 GIPO，UART，PWM 等等多个外部中断源，其中断分配如下表所示。PLIC 将多个外部中断源仲裁为一 个单比特的中断信号送入蜂鸟 E203 内核。

注意：由于本 SoC 增加了 I2C Master，因此增加了 I2C 的中断。

Table 3-3 PLIC 中断分配表

PLIC 源中断号 | 来源
0 | 预留为表示没有中断
1 | wdogcmp
2 | rtccmp

- 14 -

3

4

uart0

uart1

5 6 7 | qspi0 qspi1 qspi2
8 …… 39 | gpio0 …… gpio31
40 …… 43 | pwm0cmp0 …… pwm0cmp3
44 …… 47 | pwm1cmp0 …… pwm1cmp3
48 …… 51 | pwm2cmp0 …… pwm2cmp3
52 | i2c

## 3.3 JTAG 调试模块

蜂鸟 E203 内核采用标准（1149.1）JTAG 连接模块用于连接系统外部调试器（Debugger）与内部的 调试模块（Debug Module）。

如图 2-1 中所示，Debug Module 调试模块，用于支持外部 JTAG 通过该模块调试处理器核，是的处 理器核能够通过 GDB 对其进行交互式调试，譬如设置断点，单步执行等调试功能。

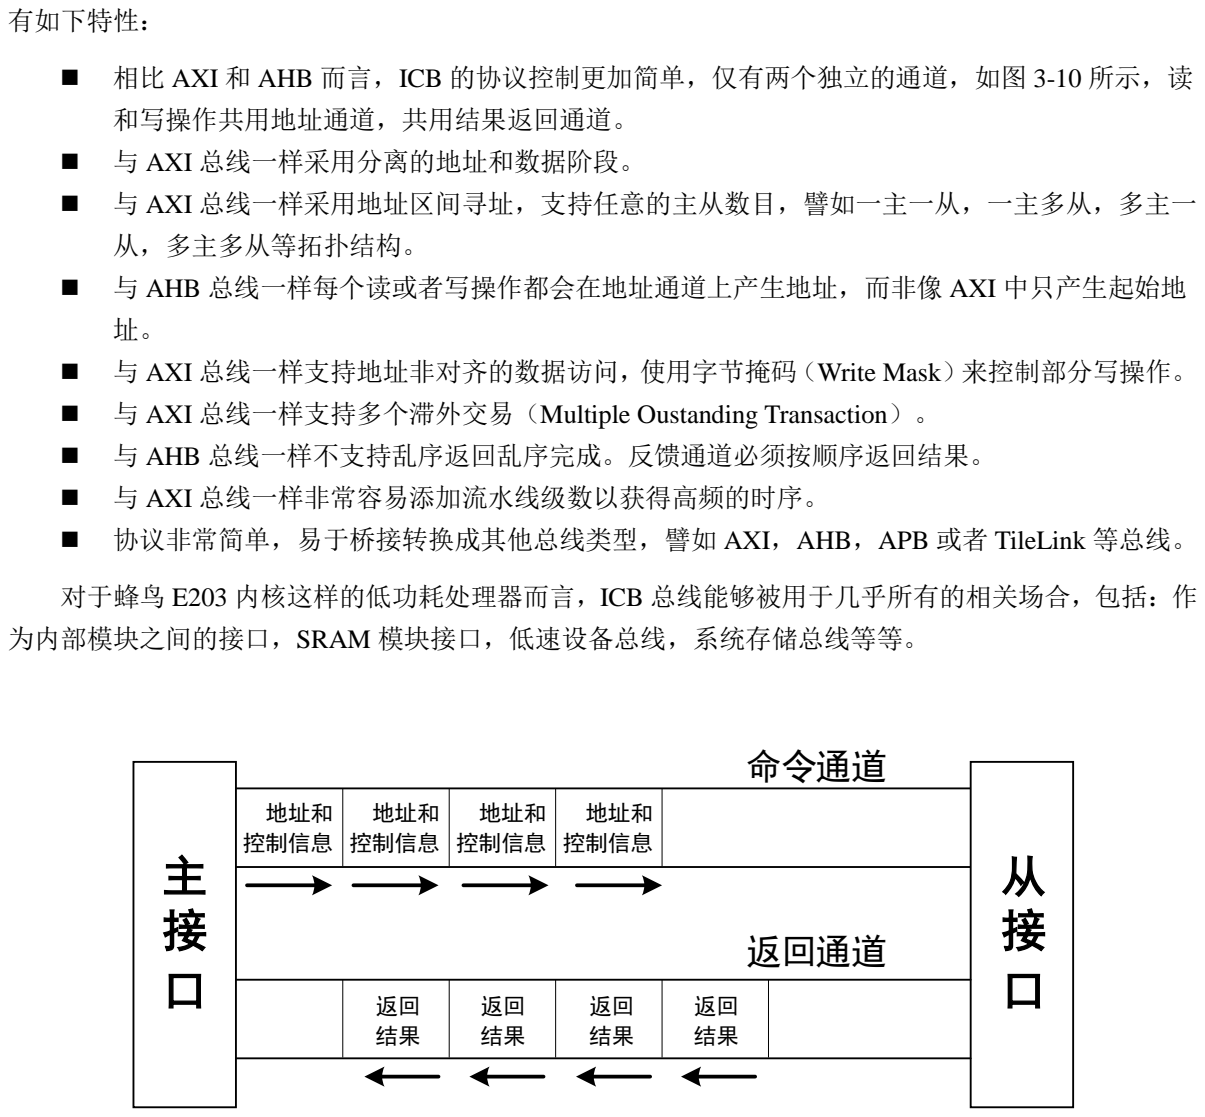
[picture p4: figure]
有如下特性：; 和写操作共用地址通道，共用结果返回通道。; 与 AXI 总线一样采用分离的地址和数据阶段。; 与 AXI 总线一样采用地址区间寻址，支持任意的主从数目，譬如一主一从，一主多从，多主一; 从，多主多从等拓扑结构。; 与 AHB 总线一样每个读或者写操作都会在地址通道上产生地址，而非像 AXI 中只产生起始地; 与 AXI 总线一样支持地址非对齐的数据访问，使用字节掩码（Write Mask）来控制部分写操作。; 与 AXI 总线一样支持多个滞外交易（Multiple Oustanding Transaction）。; 与 AHB 总线一样不支持乱序返回乱序完成。反馈通道必须按顺序返回结果。; 与 AXI 总线一样非常容易添加流水线级数以获得高频的时序。; 协议非常简单，易于桥接转换成其他总线类型，譬如 AXI，AHB，APB 或者 TileLink 等总线。; 对于蜂鸟 E203 内核这样的低功耗处理器而言，ICB 总线能够被用于几乎所有的相关场合，包括：作; 为内部模块之间的接口，SRAM 模块接口，低速设备总线，系统存储总线等等。; 地址和 控制信息; 命令通道; 返回通道

- 15 -

## 4 SoC 总线介绍

本 SoC 采用蜂鸟 E203 内核开发过程中定义了一种自定义总线协议 ICB（Internal Chip Bus），该总线 用于蜂鸟 E203 内核内部使用，同时也可作为 SoC 中的总线使用。

ICB 总线的初衷是为了能够尽可能地结合 AXI 总线和 AHB 总线的优点，兼具高速性和易用性，它具

■ 相比 AXI 和 AHB 而言，ICB 的协议控制更加简单，仅有两个独立的通道，如图 3-10 所示，读

Figure 4-1 ICB 总线通道结构

- 16 -

## 4.1 ICB 总线协议信号

ICB 总线主要包含 2 个通道，如图 4-1 所示。ICB 总线信号列表如下表所示：

■ 命令通道（Command Channel）
Command Channel 主要用于主设备向从设备发起读写请求。

■ 返回通道（Response Channel）
Response Channel 主要用于从设备向主设备返回读写结果。

Table 4-1 ICB 总线信号

通道 | 方向 | 宽度 | 信号名 | 介绍
Command Channel | Output | 1 | icb_cmd_valid | 主设备向从设备发送读写请求信号
| Input | 1 | icb_cmd_ready | 从设备向主设备返回读写接受信号
| Output | 32 | icb_cmd_addr | 读写地址
| Output | 1 | icb_cmd_read | 读或是写操作的指示。读则以总线宽度 （譬如 32 位）为单位读回一个数据。写 则靠字节掩码（icb_cmd_wmask）控制写 数据的大小（Size）。
| Output | 32 | icb_cmd_wdata | 写操作的数据，数据的摆放格式与 AXI 协议一致
| Output | 4 | icb_cmd_wmask | 写操作的字节掩码，掩码的摆放格式与 AXI 协议一致
Reponse Channel | Input | 1 | icb_rsp_valid | 从设备向主设备发送读写反馈请求信号
| Output | 1 | icb_rsp_ready | 主设备向从设备返回读写反馈接受信号
| Input | 32 | icb_rsp_rdata | 读反馈的数据，数据的摆放格式与 AXI 协议一致
| Input | 1 | icb_rsp_err | 读或者写反馈的错误标志

## 4.2 ICB 总线协议时序

本节将描述 ICB 总线的若干典型时序。

■ 如下图所示：主设备向从设备通过 ICB 的 Command Channel 发送写操作请求（icb_cmd_read 为 低），从设备立即接收该请求（icb_cmd_ready 为高）。从设备在同一个周期返回读结果且结果

| 正确（icb_rsp_err 为低），主设备立即接收该结果（icb_rsp_ready 为高）。

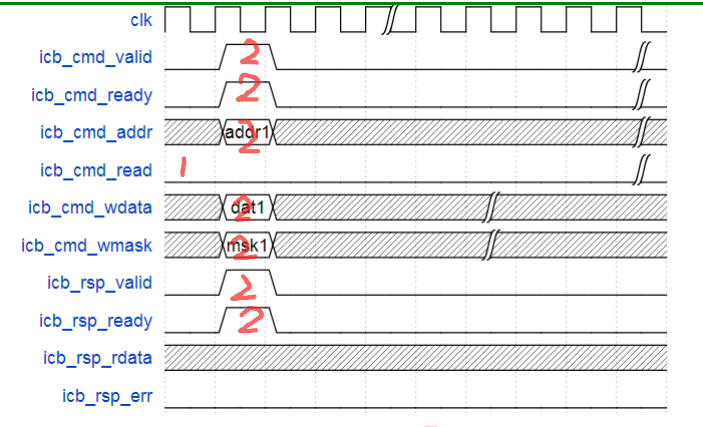
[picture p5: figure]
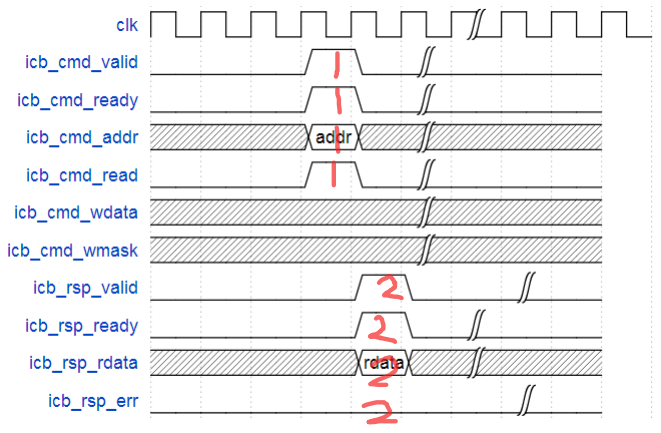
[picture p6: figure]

- 17 -

Figure 4-2 写操作同一周期返回结果

■ 如下图所示：主设备向从设备通过 ICB 的 Command Channel 发送读操作请求（icb_cmd_read 为 高），从设备立即接收该请求（icb_cmd_ready 为高）。从设备在下一个周期返回读结果且结果

| 正确（icb_rsp_err 为低），主设备立即接收该结果（icb_rsp_ready 为高）。

Figure 4-3 读操作下一周期返回结果

■ 如下图所示：主设备向从设备通过 ICB 的 Command Channel 发送写操作请求（icb_cmd_read 为 低），从设备立即接收该请求（icb_cmd_ready 为高）。从设备在下一个周期返回读结果且结果

| 正确（icb_rsp_err 为低），主设备立即接收该结果（icb_rsp_ready 为高）。

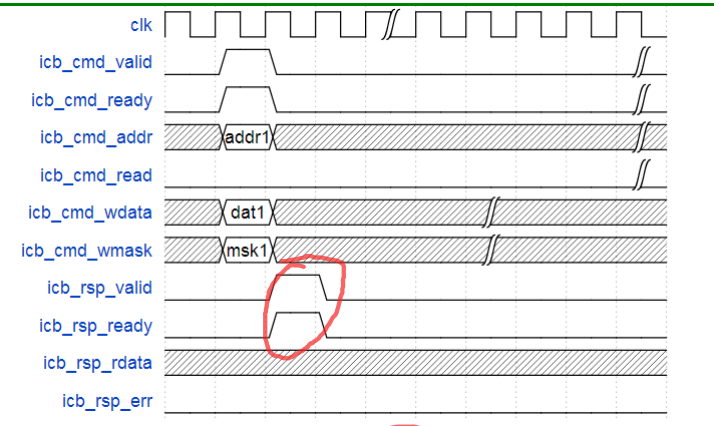
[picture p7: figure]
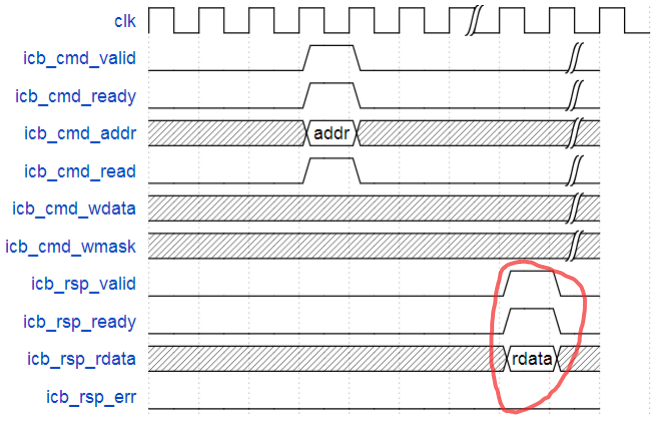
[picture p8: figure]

- 18 -

Figure 4-4 写操作下一周期返回结果

■ 如下图所示：主设备向从设备通过 ICB 的 Command Channel 发送读操作请求（icb_cmd_read 为 高），从设备立即接收该请求（icb_cmd_ready 为高）。从设备在四个周期后返回读结果且结果

| 正确（icb_rsp_err 为低），主设备立即接收该结果（icb_rsp_ready 为高）。

Figure 4-5 读操作四个周期返回结果

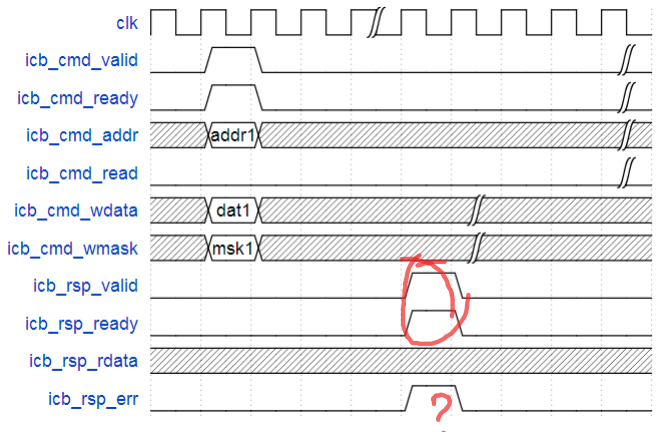
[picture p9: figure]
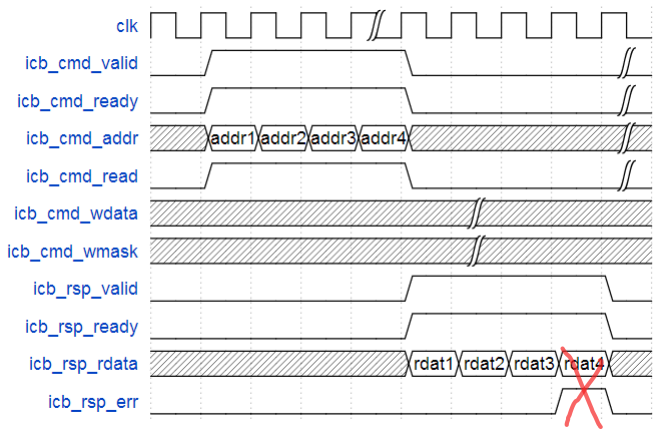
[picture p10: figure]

- 19 -

■ 如下图所示：主设备向从设备通过 ICB 的 Command Channel 发送写操作请求（icb_cmd_read 为 低），从设备立即接收该请求（icb_cmd_ready 为高）。从设备在四个周期后返回结果且结果正

| 确（icb_rsp_err 为低），主设备立即接收该结果（icb_rsp_ready 为高）。

Figure 4-6 写操作四个周期返回结果

■ | 如下图所示：主设备向从设备通过 ICB 的 Command Channel 连续发送四个读操作请求
| （icb_cmd_read 为高），从设备均立即接收该请求（icb_cmd_ready 为高）。从设备在四个周期
| 后连续返回四个读结果，其中前三个结果正确（icb_rsp_err 为低），第四个结果错误（icb_rsp_err
| 为高），主设备均立即接收此四个结果（icb_rsp_ready 为高）。

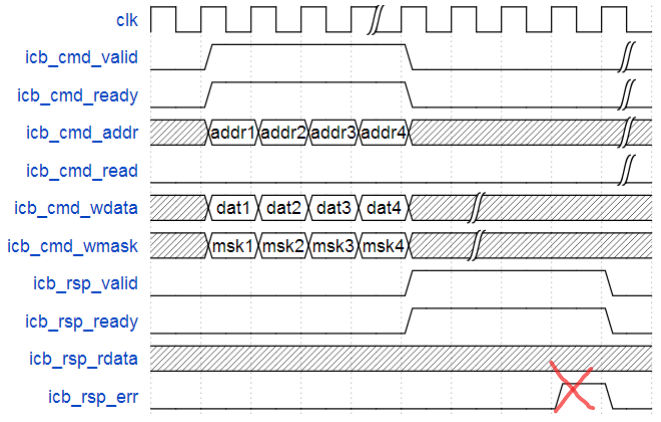
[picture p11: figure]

- 20 -

Figure 4-7 连续四个读操作均四个周期返回结果

■ | 如下图所示：主设备向从设备通过 ICB 的 Command Channel 连续发送四个写操作请求
| （icb_cmd_read 为低），从设备均立即接收该请求（icb_cmd_ready 为高）。从设备在四个周期
| 后连续返回四个写结果，其中前三个结果正确（icb_rsp_err 为低），第四个结果错误（icb_rsp_err
| 为高），主设备均立即接收此四个结果（icb_rsp_ready 为高）。

Figure 4-8 连续四个写操作均四个周期返回结果

■ | 如下图所示：主设备向从设备通过 ICB 的 Command Channel 相继连续发送三个读和写操作请求。
| 从设备立即接收了第一个和第三个请求，但是第二个请求第一个周期并没有立即接受
| （icb_cmd_ready 为低），因此主设备一直将地址控制和写数据信号保持不变，直到下一周期该
| 请求被从设备接受（icb_cmd_ready 为高）。从设备对于第一个和第二个请求都是在同一个周期
| 就返回结果且被主设备立即接受，但是对于第三个请求则是在下一个周期才返回结果，并且主
| 设备还没有立即接受（icb_rsp_ready 为低），因此从设备一直将返回信号保持不变，知道下一周
| 期该返回结果被主设备接受。

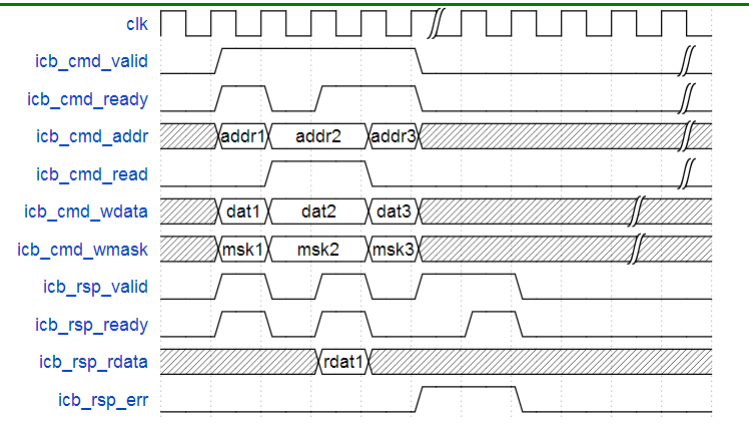
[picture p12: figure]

- 21 -

Figure 4-9 读写混合发生

## 4.3 SoC 总线结构

本 SoC 总线结构如下图所示：

■ | 蜂鸟 E203 内核 BIU 的系统存储接口 ICB 连接系统存储总线，通过其访问 SoC 中的若干存储组
| 件，譬如 ROM，Flash 的只读区间等。
■ | 蜂鸟 E203 内核 BIU 的私有设备接口 ICB 连接私有设备总线，通过其访问 SoC 中的若干设备，
| 譬如 UART，GPIO 等等。

有关 SoC 的结构和组件以及地址分配，请参见第 2.3 节。

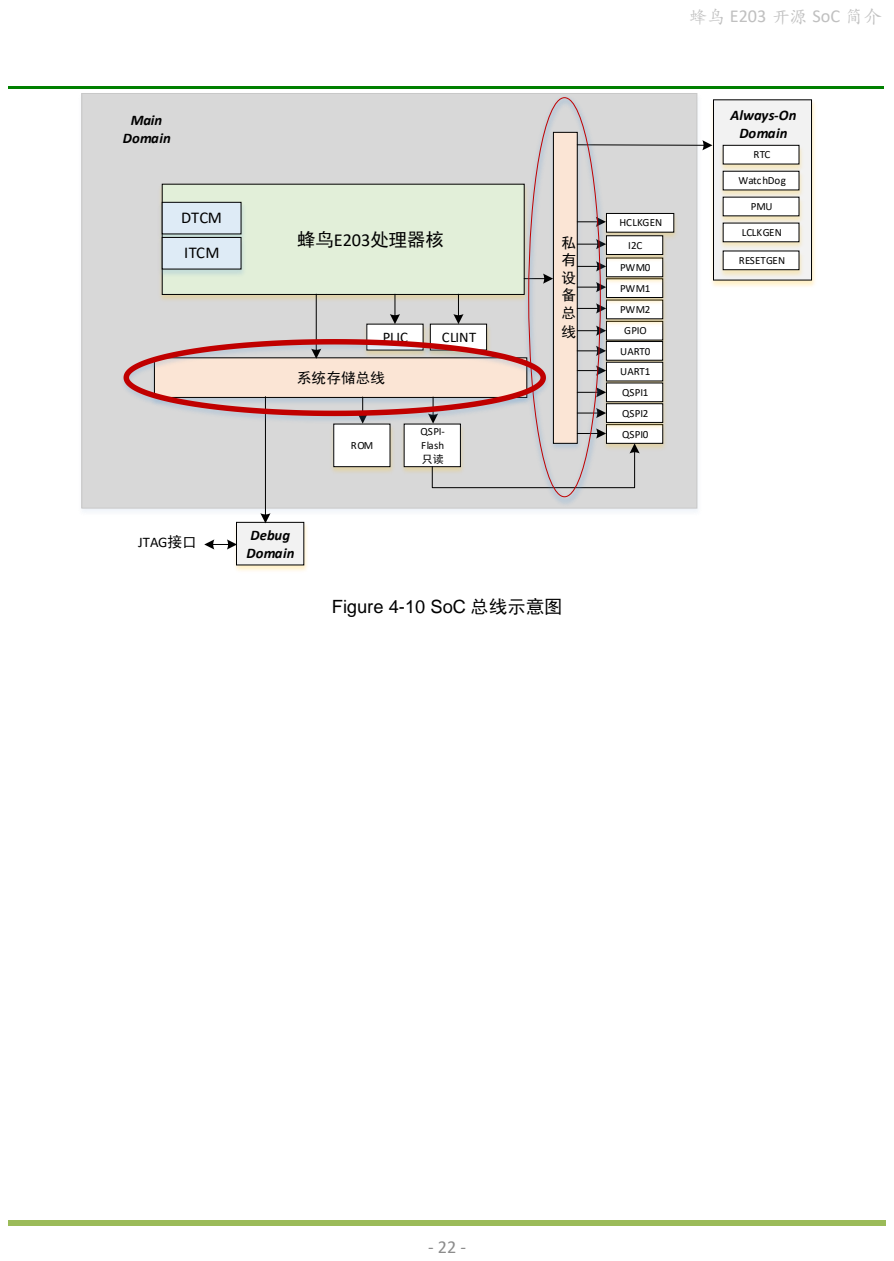
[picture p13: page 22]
系统存储总线; ROM; Debug Domain; 蜂鸟E203处理器核; DTCM; ITCM; QSPI- Flash 只读; GPIO; QSPI0; UART0; UART1; QSPI1; QSPI2; PWM2; PWM1; PWM0; Always-On Domain; PLIC; CLINT; JTAG接口; Main Domain; RTC; WatchDog; PMU; HCLKGEN; LCLKGEN; RESETGEN

Figure 4-10 SoC 总线示意图

- 23 -

## 5 SoC 外设介绍

本章将对挂载在私有设备总线上的外设模块进行介绍。本文在此仅对每个模块功能进行极为简略的 描述。
注意：
■ | 本文档对 SoC 的各外设的介绍尚不够详细，由于本 SoC 中外设模块重用自 Freedom E310 SoC 且软件完全兼容，可以参阅 Freedom E310 SoC 的技术文档了解其细节。分别为 SiFive-E300-platform-reference-manual-v1.0.1.pdf 与 SiFive-E310-G000-manual-v1.0.1.pdf，其中有 对每个模块的详细功能描述与详细配置寄存器描述供参阅。
■ | 或者，在中文书籍《RISC-V 架构与嵌入式开发快速入门》中对英文 SoC 的材料进行了通俗化翻 译，并进行深入浅出的系统讲解。感兴趣的用户可以自行搜索此书。

## 5.1 QSPI Master

有关 QSPI 的详细介绍请参见文档《SiFive-E300-platform-reference-manual-v1.0.1.pdf》或者中文书籍 《RISC-V 架构与嵌入式开发快速入门》。本文在此进行中文简述。

在本 SoC 中，有三个 QSPI Master，分别是 QSPI0，QSPI1 和 QSPI2，均是直接复用来自 Freedom E310 SoC 平台。其中 QSPI0 专用于外部的 Flash，有专用的 Pad 接口，而 QSPI1 和 QSPI2 则通过 GPIO 复用管脚。

■ | Quad-SPI Flash：
| 专用于连接外部 Flash 的 Quad-SPI（QSPI）接口。
- 并且该 QSPI 接口还可以被软件配置成为 eXecute-In-Place 模式，在此模式下，Flash 可以被 当作一段只读区间直接被当做存储器读取。在默认上电之后，QSPI即处于该模式之下，由 于 Flash 掉电不丢失的特性，因此可以将系统的启动程序存放于外部的 Flash 中，然后处理
| 器核通过 eXecute-In-Place 模式的 QSPI 接口直接访问外部 Flash 加载启动程序启动。
■ | QSPI：
- 除了上述专用于 Flash 的 QSPI 接口之外，SoC 还有两个独立的 QSPI 接口控制器。一个 QSPI 使用四个片选信号（Chip Selects），一个 QSPI 使用一个片选信号。两个 QSPI 均使用 GPIO 的 IOF 功能与外界通信。

## 5.2 GPIO

有关 GPIO 的详细介绍请参见文档《SiFive-E300-platform-reference-manual-v1.0.1.pdf》或者中文书籍 《RISC-V 架构与嵌入式开发快速入门》。本文在此进行中文简述。

- 24 -

GPIO 全称为 General Purpose I/O，其要点如下：

■ | GPIO 用于提供一组 32 I/O 的通用输入输出接口。每个 I/O 可用被软件配置为输入或者输出，如 果是输出可以设置具体的输出值。
■ | 每个 I/O 还可以被配置为 IOF（Hardware I/O Functions），也就是将 I/O 供 SoC 内部的其他模块 复用，譬如 SPI，UART，PWM 等等。
■ | 另外，每个 GPIO 的 I/O 均作为一个中断源连接到 PLIC 的中断源上。
■ | GPIO 的 32 个 I/O 被 SoC 内部模块的复用分配如下表所示，其中每个 I/O 均可以供两个内部模 块复用，软件可以通过配置每个 I/O 使其选择 IOF0 或者 IOF1 来选择信号来源。注意：表中黄 色高亮部分为本 SoC 新添加的 IO 映射，其他 IO 均与 Freedom E310 I/O 映射相同。

Table 5-1 GPIO 的接口分配表

GPIO Pin 编号 | IOF0 | IOF1
0 | | PWM0_0
1 | | PWM0_1
2 | QSPI1:SS0 | PWM0_2
3 | QSPI1:SD0/MOSI | PWM0_3
4 | QSPI1:SD1/MISO
5 | QSPI1:SCK
6 | QSPI1:SD2
7 | QSPI1:SD3
8 | QSPI1:SS1
9 | QSPI1:SS2
10 | QSPI1:SS3 | PWM2_0
11 | | PWM2_1
12 | I2C:SDA | PWM2_2
13 | I2C:SCL | PWM2_3
14
15
16 | UART0:RX
17 | UART0:TX
18
19 | | PWM1_1
20 | | PWM1_0
21 | | PWM1_2
22 | | PWM1_3
23
24 | UART1:RX
25 | UART1:TX
26 | QSPI2:SS
27 | QSPI2:SD0/MOSI

- 25 -
28 | QSPI2:SD1/MISO
29 | QSPI2:SCK
30 | QSPI2:SD2
31 | QSPI2:SD3

## 5.3 UART

有关 UART 的详细介绍请参见文档《SiFive-E300-platform-reference-manual-v1.0.1.pdf》或者中文书籍 《RISC-V 架构与嵌入式开发快速入门》。本文在此进行中文简述。
UART 全称为 Universal Asynchronous Receiver-Transmitter（通用异步接收-发射器），本 SoC 有两个 独立的 UART，两个 UART 均使用 GPIO 的 IOF 功能与外界通信。

## 5.4 PWM

有关 PWM 的详细介绍请参见文档《SiFive-E300-platform-reference-manual-v1.0.1.pdf》或者中文书籍 《RISC-V 架构与嵌入式开发快速入门》。本文在此进行中文简述。
PWM 全称为 Pulse-Width Modulator（脉宽调节器）。本 SoC 有三个独立的 PWM，其中两个是 16 比 特的精度，另外一个是 8 比特的精度，均使用 GPIO 的 IOF 功能与外界通信。

## 5.5 Always-On 模块

有关 Always-On 模块的详细介绍请参见文档《SiFive-E300-platform-reference-manual-v1.0.1.pdf》或者 中文书籍《RISC-V 架构与嵌入式开发快速入门》。本文在此进行中文简述。
Always-ON 模块包含了三个主要子模块，分别是 WatchDog，RTC 和 PMU。

### 5.5.1 WatchDog

有关 WatchDog 模块的详细介绍请参见文档《SiFive-E300-platform-reference-manual-v1.0.1.pdf》或者 中文书籍《RISC-V 架构与嵌入式开发快速入门》。本文在此进行中文简述。

WatchDog 全称为 Watch Dog Timer（看门狗计数器），该计数器位于 Always-on Domain 中，因此使用 低速时钟进行计数，并且可以通过配置其计数的目标值产生中断。

- 26 -

### 5.5.2 RTC

有关 RTC 模块的详细介绍请参见文档《SiFive-E300-platform-reference-manual-v1.0.1.pdf》或者中文 书籍《RISC-V 架构与嵌入式开发快速入门》。本文在此进行中文简述。

RTC 全称为 Real-Time Counter（实时计数器），该计数器位于 Always-on Domain 中，因此使用低速 时钟进行计数，并且还能产生中断。

### 5.5.3 PMU

有关 PMU 模块的详细介绍请参见文档《SiFive-E300-platform-reference-manual-v1.0.1.pdf》或者中文 书籍《RISC-V 架构与嵌入式开发快速入门》。本文在此进行中文简述。
PMU 全称为 Power Management Unit（电源管理单元），用于控制 SoC 的电源管理。整个 SoC 除了 WatchDog、RTC、PMU 等模块处于 Always-on Domain 之外，其他 Main Domain 可以在 PMU 的控制下被 置于断电状态以节省功耗，或者重新唤醒等等。

### 5.5.4 LCLKGEN

LCLKGEN 全称为 Low-Speed Clock Generation。LCLKGEN 主要为 Always-On Domain 生成时钟。 Always-On Domain 主要使用低速的实时时钟，频率应为 32.768KHz，可以选择来自片上振荡器、外部晶 振或者直接通过芯片引脚输入。

LCLKGEN 模块的结构取决于具体芯片的工艺和 IP，因此本文在此不做介绍。

注意：在 FPGA 开发板中，LCLKGEN 模块为空模块，直接输出由 FPGA 产生的 32.768KHz 时钟。

### 5.5.5 RESETGEN

RESETGEN 模块主要为整个 SoC 模块产生复位信号，请参见第 9 章了解 SoC 复位管理。

## 5.6 I2C Master

I2C Master 模块是采用开源的并经过测试验证后的 IP core；内部采用 wishbone 总线通信。寄存器列 表如下，关于寄存器的详细介绍请参考《I2CMasterwithWISHBONEBusInterface-Documentation.pdf》或者 中文书籍《RISC-V 架构与嵌入式开发快速入门》。

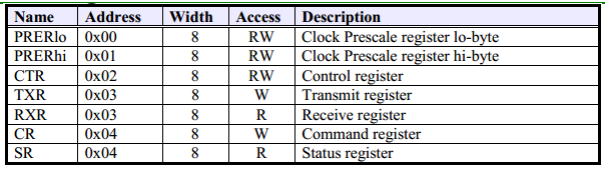
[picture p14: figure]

- 27 -

注意，上表中地址为偏移地址，总线分配的基地址为 0x1004_2000。

## 5.7 HCLKGEN

HCLKGEN 全称为 High-Speed Clock Generation。HCLKGEN 其主要为 Main Domain 生成高速时钟 （譬如频率为 100MHz）。HCLKGEN 可以使用片上振荡器、外部晶振和片上 PLL 产生高速时钟，PLL 也可以通过软件配置将其旁路。HCLKGEN 模块的结构取决于具体芯片的工艺和 IP，因此本文在此不做 介绍。

注意：在 FPGA 开发板中，HCLKGEN 模块为空模块，直接输出由 FPGA 产生的 16MHz 时钟。

HCLKGEN 模块有若干可编程寄存器（地址区间为 0x1000_8000~0x1000_8FFF），其用于控制 HCLKGEN 相关功能。由于 HCLKGEN 模块的结构取决于具体芯片的工艺和 IP，因此本文在此对相关寄 存器不做介绍。

- 28 -

## 6 SoC 片上存储器介绍

## 6.1 ITCM

ITCM 为 RISC-V Core 私有的指令存储器，其特性如下：

■ | 大小为 64KB。
■ | ITCM 数据宽度为 64 位。
■ | ITCM SRAM 虽然主要用于存放指令，但是其地址区间也可以被 Load、Store 指令访问，从而用 来存放数据。

## 6.2 DTCM

DTCM 为 RISC-V Core 私有的数据存储器，其特性如下：

■ | 大小为 64KB。
■ | DTCM SRAM 数据宽度为 32 位。

## 6.3 ROM

在本 SoC 中使用 Verilog 常数逻辑化的 ROM，本质上就是常数逻辑。

- 29 -

## 7 SoC 电源域管理

## 7.1 电源域划分

为了保证芯片能够进入低功耗模式，将整个芯片划分为两个主要的电源域：

■ | Always-On Domain：
| 此 Domain 即第 5 章中介绍的 Always-on 模块，包括子模块 WatchDog，RTC，和 PMU，还 有 Always-On 时钟生成电路。
■ | MOFF Domain：
| MOFF 是 Most-Off 的简称，即芯片中除了 Always-On Domain 之外的所有其他主体部分。

注意：在 FPGA 平台上没有真正的电源域。

## 7.2 低功耗模式

整个芯片分为三个工作模式：

■ | 正常模式：Always-On 和 MOFF 均处于正常供电状态。
■ | 等待模式：Always-On 和 MOFF 均处于正常供电状态。但是 Core 执行了一条 WFI 指令，因此 处理器停止执行，时钟被关闭。直到下次被中断唤醒。
■ | 休眠模式：Always-On 正常供电，但是 MOFF 的外部电源切断。
| 进入休眠模式由 Always-On 的 PMU 模块控制，PMU 模块会通过芯片的 Pad 输出一根控制 信号 AON_PMU_VDDPADEN，该信号会控制芯片外部的 MOFF 供电电路使其切断电源。 注意：在 FPGA 平台上没有真正的电源域和切断电源。
| 退出休眠模式由 PMU 定义的若干唤醒条件唤醒，具体的唤醒条件请参见有关 PMU 模块的 详细介绍请参见文档《SiFive-E300-platform-reference-manual-v1.0.1.pdf》或者中文书籍 《RISC-V 架构与嵌入式开发快速入门》。

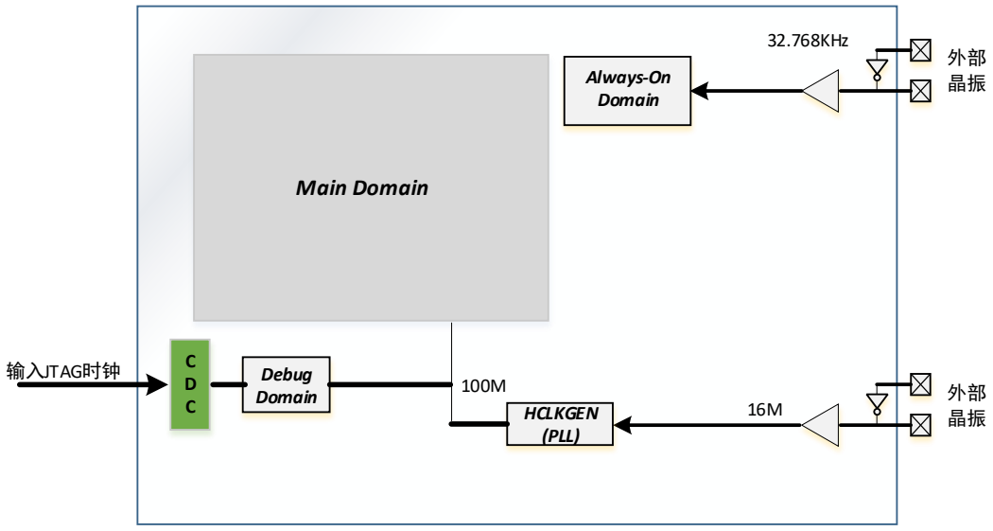
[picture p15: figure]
Debug Domain; Always-On Domain; Main Domain; 32.768KHz; 输入JTAG时钟; HCLKGEN; (PLL)

- 30 -

## 8 SoC 时钟管理

## 8.1 时钟域划分

Figure 8-1 SoC 时钟域划分

如上图所示，将整个芯片划分为三个主要的时钟域：

■ | Always-On Domain：
| 此 Domain 主要使用低速的 Always-on 时钟，频率为 32.768KHz。
- 时钟可以选择来自外部的晶振或者直接通过芯片引脚输入。

■ Main Domain：

- 此 Domain 包含了芯片的主体，在此 Domain 中没有再划分时钟域，因此处理器核和总线以 及外设 IP 均使用同样的时钟。
- 此 Domain 自带 HCLKGEN 时钟生成模块，使用片上 PLL 产生高速时钟。PLL 也可以通过 软件配置旁路其时钟，请参见第 5 章对于 HCLKGEN 模块的详细介绍。

■ Debug Domain：

- 此 Domain 包含了为了支持 JTAG 对 RISC-V 调试功能而添加的相关逻辑。
- 此模块由两个不同的时钟域组成，分别是 JTAG 时钟和 RISC-V Core 时钟（即 Main Domain 的时钟），因此其内部有时钟跨越异步处理。

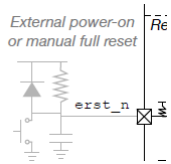
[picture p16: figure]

- 31 -

## 9 SoC 复位管理

## 9.1 芯片复位策略

首先，Always-On Domain 的复位可以来源于三个来源：

■ | 来自于 POR（Power-On-Reset）电路；
■ | 来自于芯片引脚 AON_ERST_N；
■ | 来自于 WatchDog 生成的 Reset；

### 9.1.1 POR 电路 Reset

### 9.1.2 WatchDog Reset

有关 Watchdog 模块的详细介绍请参见文档《SiFive-E300-platform-reference-manual-v1.0.1.pdf》或者 中文书籍《RISC-V 架构与嵌入式开发快速入门》。

### 9.1.3 芯片引脚 AON_ERST_N

此部分与 Freedom E310 完全相同：

Figure 9-1 外部复位电路

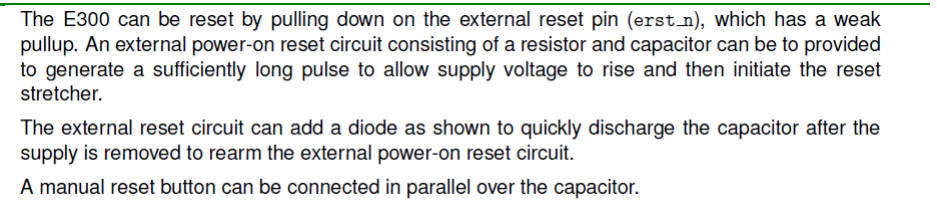
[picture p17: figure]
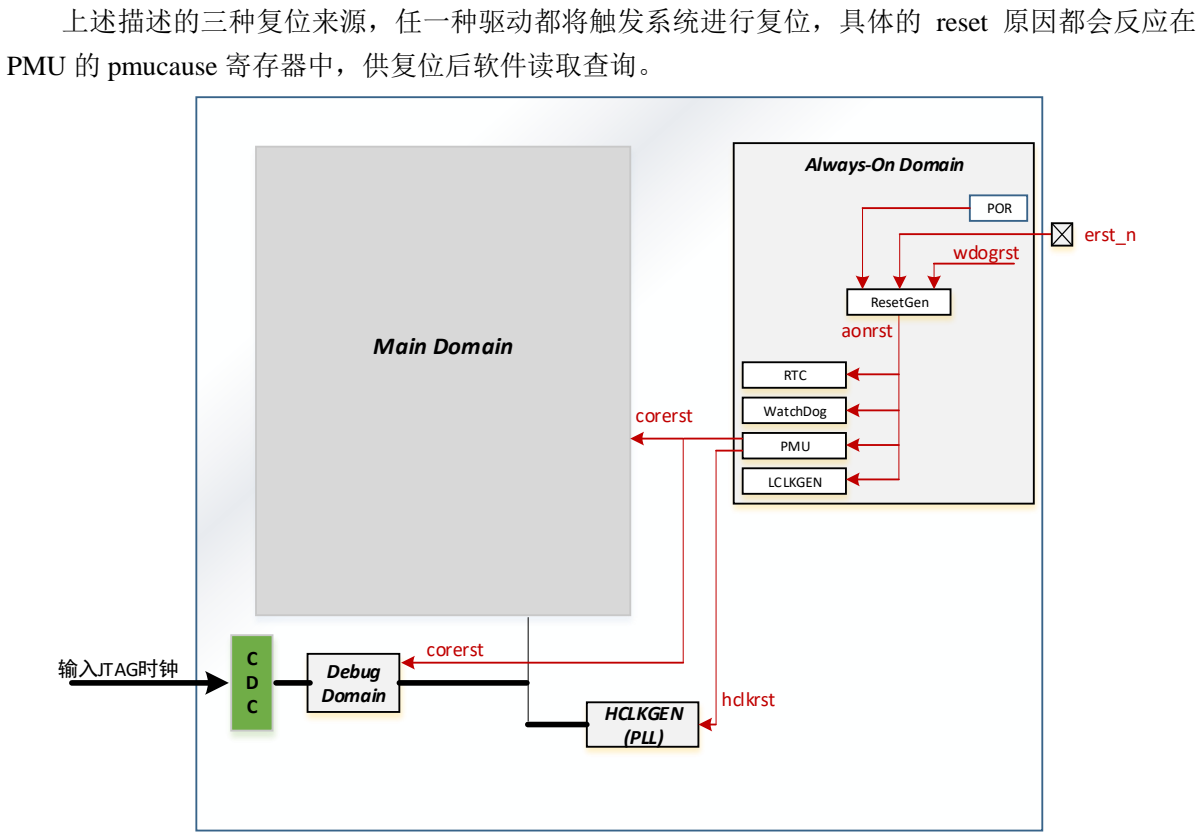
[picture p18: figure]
上述描述的三种复位来源，任一种驱动都将触发系统进行复位，具体的 reset 原因都会反应在; PMU 的 pmucause 寄存器中，供复位后软件读取查询。; Debug Domain; Main Domain; 输入JTAG时钟; D C HCLKGEN (PLL); hclkrst; erst_n; Always-On Domain; RTC; WatchDog; PMU; LCLKGEN; POR; aonrst; wdogrst; ResetGen; corerst

- 32 -

### 9.1.4 复位树关系

Figure 9-2 SoC 复位结构图

经三个来源最终生成的 reset 经过 Always-On Clock 同步成为异步置位、同步释放的 aonrst 信号， 由 aonrst 信号进一步驱动 PMU 复位芯片的其他部分，其复位树的关系如上图所示，要点如下：

■ aonrst 信号将作为 Always-On 模块本身的主复位信号，复位 Always-On 模块的 PMU，WatchDog， RTC 等。

- 33 -

■ PMU 被 aonrst 复位之后，将进入默认的 wakeup sequence，生成 hclkrst 和 corerst 信号：
- hclkrst 信号用于驱动 HCLKGEN 模块（主要包含 PLL 时钟生成）。
| corerst 将用于除了 HCLKGEN 模块之外的所有 Main Domain 中的复位。
注意：每个复位信号都应该在相应的时钟域内进行同步，使之成为异步置位同步释放的复位信 号。

- 34 -

## 10 上电流程控制

## 10.1上电流程

本 SoC 中处理器核上电复位之后，可以从两个不同的地址进行执行程序，分别为：

■ | 从外部 Flash 开始执行。
■ | 从内部 ROM 开始执行。

下文分别予以论述。

### 10.1.1 从外部 Flash 开始执行

如 2.3 节中所述，由于在本 SoC 中外部 Flash 的地址区间位于 0x2000_0000 ~ 0x3FFF_FFFF，因此，如果

从外部 Flash 开始执行，则 RISC-V 处理器核的 PC 复位值为 0x20000000。

如果从 Flash 中启动，软件应该设置上电启动引导程序，将 Flash 中的代码和数据搬运到片上 ITCM 和 DTCM 中，然后跳转到 ITCM 中开始执行。

### 10.1.2 从内部 ROM 开始执行

如 2.3 节中所述，由于在本 SoC 中内部 ROM 的地址区间位于 0x0000_1000 ~ 0x0000_1FFF，因此，

如果从内部 ROM 开始执行，则 RISC-V 处理器核的 PC 复位值为 0x0000_1000。

在 ROM 中存放的代码为固定代码，其直接跳转至 ITCM（地址为 0x8000_0000）中继续执行。

从内部 ROM（继而从 ITCM）开始执行的方式，只有在调试阶段（调试器初始化了 ITCM 之后）才 有意义，否则由于 ITCM 中没有初始化程序，将无法正常执行。

## 10.2 上电地址选择

本 SoC 可以通过顶层引脚的值来选择上电地址，如下表所示。

Table 10-1 SoC 上电控制

芯片引脚 | 值 | 地址区间
BOOTROM_N | 0 | 从内部 ROM 上电执行
| 1 | 从外部 QSPI 上电执行

- 35 -

## 11 SoC 顶层引脚

## 11.1 SoC 顶层引脚分配

本 SoC 的顶层引脚分布如下表所示。

Table 11-1 SoC 顶层引脚分配表

类型 | 方向 | 名称 | 描述
MOFFClock | Input | hfextclk | High speed clock input
Always-On Clock | Input | lfextclk | 32.768KHz clock input
Always-On I/O Connections | Output | PMU_VDDPADEN | Programmable SLEEP control.
| Output | PMU_PADRST | Programmable SLEEP control.
| Input | PMU_DWAKEUP_N | Digital Wake-from-sleep. Activelow.
| Input | AON_ERST_N | External System Reset. Activelow.
上电地址选择 | Input | BOOTROM_N | The boot up PC address selector. When driven low,RISC-V Core boot up from internal ROM (0x00001000). When left unconnected ordriven high, RISC-V Core boot up from QSPI flash (0x20000000).
JTAG 调试 | Input | JTAG TCK | JTAG Clock line for debug interface
| Output | JTAG TDO | JTAG Data Out for debug interface
| Input | JTAG TMS | JTAG Test Mode Select fordebug interface
| Input | JTAG TDI | JTAG Data In for debug interface
QSPI0 外部 Flash | Bidir | QSPI DQ 3 | Quad SPI Data Line
| Bidir | QSPI DQ 2 | Quad SPI Data Line
| Bidir | QSPI DQ 1 | Quad SPI Data Line
| Bidir | QSPI DQ 0 | Quad SPI Data Line
| Output | QSPI CS | Quad SPI Chip Select. ActiveLow.
| Output | QSPI SCK | Quad SPI Clock Signal.
GPIO | Bidir | GPIO_0 | 32 根 GPIO 管脚
| Bidir | GPIO_1
| Bidir | GPIO_2
| Bidir | GPIO_3
| Bidir | GPIO_4
| Bidir | GPIO_5
| Bidir | GPIO_6

- 36 -
Bidir | GPIO_7
Bidir | GPIO_8
Bidir | GPIO_9
Bidir | GPIO_10
Bidir | GPIO_11
Bidir | GPIO_12
Bidir | GPIO_13
Bidir | GPIO_14
Bidir | GPIO_15
Bidir | GPIO_16
Bidir | GPIO_17
Bidir | GPIO_18
Bidir | GPIO_19
Bidir | GPIO_20
Bidir | GPIO_21
Bidir | GPIO_22
Bidir | GPIO_23
Bidir | GPIO_24
Bidir | GPIO_25
Bidir | GPIO_26
Bidir | GPIO_27
Bidir | GPIO_28
Bidir | GPIO_29
Bidir | GPIO_30
Bidir | GPIO_31

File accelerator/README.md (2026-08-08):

# FLOOD 加速器基线说明

> **文档定位（2026-08-08）**：本文描述现有 FLOOD CNN/MacMachine 基线，供代码理解、复用和回归验证使用。当前研究主线是 AXKU15 上的 Stable Diffusion 1.5 ResNetBlock 加速器，范围、接口、精度和完成判据以[正式设计规格](../docs/superpowers/specs/2026-08-08-sd15-resnetblock-accelerator-design.md)为准。

> **参数提示**：下方 `Config` 示例为历史快照，可能落后于源码。当前 `src/main/scala/core/Config.scala` 的关键值为 `rowSize=32`、`colSize=32`、`dataWidth=8`、`pipeline=2`、`tLatency=4`、`compressionFactor=4`、`tileSize=16`。新的 Diffusion 原型首版按 8 Tile 进行综合评估，不能把旧 16 Tile 配置直接视作 AXKU15 可实现结论。

## 项目概述

FLOOD_Accelerator 是一个高效的计算加速器项目，采用多核架构设计，旨在实现高性能的乘累加计算和数据存储管理。该项目采用分层设计，包含以下核心模块：

- **MacMachine**: 多核架构的完整封装结构，集成FSM、Cluster、OutRouter三个模块
- **MacMachineWrapper**: MacMachine的封装层，提供乒乓缓冲和SRAM管理
- **Cluster**: 多核架构的完整封装结构，管理多个Tile和InterNoC
- **Tile**: 多核架构的基本计算单元，封装CIMCore并提供核间通信
- **OutRouterPlanePost**: 带嵌入平面处理功能的Router模块，支持BN、激活函数、池化等后处理
- **DynamicTruncateData**: 动态截位数据模块，支持运行时动态控制截位位数
- **CIMCore**: 计算内存核心，实现乘累加计算
- **SRAM**: 存储管理模块，包括权重SRAM、特征图SRAM、输出SRAM等

## 全局配置

### Config对象配置参数

Config对象定义了整个系统的全局配置参数，位于`src/main/scala/core/Config.scala`：

```scala
object Config {
  // CIMCore参数
  val rowSize = 32        // CIMCore行数
  val colSize = 32        // CIMCore列数

  // 基础参数
  val dataWidth = 8       // 输入数据位宽
  val outputWidth = 2*dataWidth+log2Ceil(rowSize)  // 输出数据位宽
  val weightBandWidth = colSize * dataWidth // CIMCore的权重总线位宽
  val featureMapBandWidth = weightBandWidth // MacMachine的特征图总线位宽
  
  // MACTree参数
  val pipeline = 5        // 流水线级数
  val tLatency = 1        // 每级流水线延迟
  val compressionFactor = 2 // 除乘法流水级之外，每个流水级输入结果相邻与前一级的输入结果的压缩比
  
  // Tile参数
  val maxKernelSize = colSize // Tile内支持的最大卷积2D尺寸k
  val maxWorkMode = 5     // Tile最大的可重构工作模式数量
  
  // Cluster参数
  val tileSize = 16       // Cluster内Tile的总数
  val finalWidth = outputWidth+log2Ceil(tileSize)+log2Ceil(colSize) // 最终Cluster的输出数据位宽

  // 配置总线参数
  val configDataWidth = 32 // 配置数据位宽
  val configAddrWidth = 32 // 配置地址位宽

  // FSM/OutRouter参数
  val maxKernelBlockK = maxKernelSize // 卷积核Block的最大2D尺寸k值
  val maxKernelBlockCout = 32 // 一轮计算中，结果图Block的通道数
  val maxKernelBlockCin = 1024 // 卷积核Block的最大输入通道数
  val maxGroupSize = tileSize // Cluster中，最大可能实现的组内Tile数
  val maxGroupNum = tileSize // Cluster中，最大可能实现的组内Tile数
  val maxResolutionCol = 768 // 特征图的最大W坐标

  // SRAM参数
  val weightSramDataWidth = 8
  val weightSramAddrWidth = 18
  val featureMapSramDataWidth = 8
  val featureMapSramAddrWidth = 18
  val outputBufferDataWidth = 8
  val outputBufferAddrWidth = 18
}
```

### 配置寄存器说明

系统使用32位配置寄存器，包含以下信息域：

1. **Tile配置寄存器**（地址：0-15，32位）：
   ```
   [31:16] - remain (16位) - 预留扩展位
   [15:8]  - featureMapLine (8位) - 特征图行索引
   [7:4]   - workMode (4位) - 工作模式
   [3:0]   - inputId (4位) - 输入ID
   [2:0]   - kernelSize (3位) - 卷积核大小(k-1)
   ```

2. **InterNoC配置寄存器**（地址：16-30，32位）：
   ```
   [31:24] - remain (8位) - 预留扩展位
   [23:16] - workMode (8位) - 工作模式
   [15:8]  - inputId (8位) - 输入ID
   [7:4]   - 预留位
   [3]     - deliver (1位) - 是否发送数据
   [2]     - systolic (1位) - 是否使用systolic模式
   [1:0]   - 预留位
   ```

3. **FSM/OutRouter配置寄存器**：
   - **Normal配置寄存器**（地址：31）：
     ```
     [31:0] - k (5位) + groupSize (4位) + groupNum (4位) + cout (5位) + 预留位
     ```
   - **Special配置寄存器**（地址：32）：
     ```
     [31:28] - truncateBits (4位) - 截位位数控制
     [27:25] - workMode (3位) - 工作模式
     [24:14] - colIdx (11位) - 列索引
     [13:3]  - cinIdx (11位) - 输入通道索引
     [2:0]   - 预留位
     ```

4. **BN参数寄存器**（地址：33-64，32位）：
   ```
   [31:16] - bnMulParam (16位) - BN乘法参数（有符号）
   [15:0]  - bnAddParam (16位) - BN加法参数（有符号）
   ```

5. **全局配置寄存器**（地址：65，32位）：
   ```
   [31]    - pingpong (1位) - 全局乒乓标志
   [30]    - weightPingpong (1位) - 权重乒乓标志
   [29]    - outputPingpong (1位) - 输出乒乓标志
   [7:0]   - actionMode (8位) - 动作模式控制
     [0]   - dataFlowMode - 数据流模式 (0:FLOOD, 1:NVIDIA)
     [1]   - isFinalCinIdx - 是否为最终输入通道索引
     [2]   - bnEn - BN使能
     [3]   - actEn - 激活函数使能
     [4]   - poolEn - 池化使能
   ```

6. **运行控制寄存器**：
   - **runProcess寄存器**（地址：48）：启动一轮计算
   - **interruptFresh寄存器**（地址：49）：清空MacMachine内的中断标志

## 系统架构

### MacMachine（多核架构完整封装）

MacMachine是多核架构的完整封装结构，位于`src/main/scala/machine/MacMachine.scala`，主要功能：

- **模块集成**：集成FSM、Cluster、OutRouter三个核心模块
- **乒乓控制**：提供全局乒乓控制信号
- **SRAM接口**：提供权重SRAM、输出SRAM、Joint SRAM的读写接口
- **配置总线**：统一的配置总线接口
- **特征图总线**：用于特征图数据传输
- **启动控制**：支持启动/完成握手协议

### MacMachineWrapper（封装层）

MacMachineWrapper是MacMachine的封装层，位于`src/main/scala/machine/MacMachineWrapper.scala`，主要功能：

- **乒乓缓冲管理**：
  - 权重SRAM乒乓缓冲（ping/pong）
  - 输出SRAM乒乓缓冲（ping/pong）
  - Joint SRAM独立管理
- **地址映射**：根据地址边界自动选择SRAM
- **中断管理**：done和error中断标志
- **运行控制**：通过配置寄存器控制启动和中断清除

### Cluster（多核架构管理）

Cluster是多核架构的完整封装结构，位于`src/main/scala/cluster/Cluster.scala`，主要功能：

- **Tile管理**：管理16个Tile实例
- **InterNoC管理**：管理15个InterNoC实例，实现Tile间通信
- **输出仲裁**：使用Round-Robin仲裁器管理Tile输出
- **配置分发**：将配置总线和权重总线分发给各个Tile和InterNoC

### Tile（基本计算单元）

Tile是多核架构的基本计算单元，位于`src/main/scala/core/Tile.scala`，主要功能：

- **CIMCore封装**：封装计算内存核心
- **移位相加**：根据kernelSize执行移位相加操作
- **核间通信**：通过InterNoC实现Tile间数据传递
- **状态管理**：管理计算状态和输出状态
- **配置支持**：支持动态配置kernelSize、inputId、workMode等参数

### OutRouterPlanePost（后处理Router）

OutRouterPlanePost是带嵌入平面处理功能的Router模块，位于`src/main/scala/machine/OutRouterPlanePost.scala`，主要功能：

- **平面处理**：支持输入通道补齐、列向拼接、高向拼接
- **后处理流水线**：
  - BN（Batch Normalization）：乘法和加法操作
  - 激活函数：ReLU激活
  - 池化：2x2最大池化
- **动态截位控制**：集成DynamicTruncateData模块，支持运行时动态控制截位位数
- **工作模式**：
  - 初始列向拼接（001）
  - 一般列向拼接（010）
  - 仅输入通道补齐（011/100）
  - 默认模式（000）
- **双SRAM管理**：outputSram和jointSram的读写管理

### DynamicTruncateData（动态截位模块）

DynamicTruncateData是动态截位数据模块，位于`src/main/scala/tools/DynamicTruncateData.scala`，主要功能：

- **动态截位控制**：支持运行时通过寄存器动态控制截位位数
- **位宽自适应**：根据输入输出位宽自动选择处理策略
- **四舍五入**：支持精确的四舍五入算法
- **饱和处理**：防止数据溢出，确保数值稳定性
- **向量化处理**：支持多路数据并行处理

#### 接口定义
```scala
val io = IO(new Bundle {
  val inputData = Input(Vec(vecSize, SInt(inputWidth.W)))
  val outputData = Output(Vec(vecSize, SInt(inputWidth.W)))  // 输出位宽与输入一致
  val truncateBits = Input(UInt(truncateBitsWidth.W))
})
```

#### 位宽处理策略
**重要说明**：`DynamicTruncateData` 的输出位宽与输入位宽一致，`outputWidth` 参数表示有效位宽（只有低 `outputWidth` 位有效）。

1. **inputWidth > outputWidth**：饱和截位，需要截断高位并进行饱和处理，输出位宽保持与输入一致
2. **inputWidth == outputWidth**：直接截位，根据truncateBits进行右移，输出位宽与输入一致
3. **inputWidth < outputWidth**：符号位扩展，补足到目标位宽，输出位宽与输入一致

**参数语义**：
- `inputWidth`：输入数据位宽
- `outputWidth`：有效位宽（只有低 `outputWidth` 位有效，其余位为零或符号扩展）
- `outputData`：输出数据位宽与 `inputData` 一致，但只有低 `outputWidth` 位有效

#### 性能特性
- **时钟频率**：在28nm工艺下可达625MHz
- **硬件资源**：优化的组合逻辑，减少MUX开销
- **延迟**：单周期完成截位操作

#### 使用示例
```scala
val truncateModule = Module(new DynamicTruncateData(
  inputWidth = 16,           // 输入数据位宽
  outputWidth = 8,           // 有效位宽（只有低8位有效）
  vecSize = 4,               // 向量大小
  truncateBitsWidth = 4      // 截位位数寄存器位宽
))

truncateModule.io.inputData := inputData
truncateModule.io.truncateBits := truncateBits
val outputData = truncateModule.io.outputData  // 输出位宽为16位，但只有低8位有效
```

### 配置示例

以下是配置系统的伪代码示例：

```scala
// 1. 配置Tile
def configureTile(tileId: Int, kernelSize: Int, inputId: Int, workMode: Int, featureMapLine: Int) {
  // 设置乒乓信号为false
  pingpong = false
  
  // 配置Tile
  configBus.addr = tileId
  configBus.data = (remain << 16) | (featureMapLine << 8) | (workMode << 4) | inputId
  configBus.en = true
  
  // 写入权重
  for (addr <- 0 until rowSize*colSize) {
    weightBus.tileId = tileId
    weightBus.addr = addr
    weightBus.data = weights(addr)
    weightBus.en = true
  }
  
  // 设置乒乓信号为true使配置生效
  pingpong = true
  wait(5 cycles)
}

// 2. 配置InterNoC
def configureInterNoC(nocId: Int, deliver: Boolean, systolic: Boolean) {
  // 设置乒乓信号为false
  pingpong = false
  
  // 配置InterNoC
  configBus.addr = nocId
  configBus.data = (remain << 24) | (workMode << 16) | (inputId << 8) |
                   (deliver << 3) | (systolic << 2)
  configBus.en = true
  
  // 设置乒乓信号为true使配置生效
  pingpong = true
}

// 3. 配置OutRouterPlanePost
def configureOutRouter(k: Int, groupSize: Int, groupNum: Int, cout: Int, 
                      cinIdx: Int, colIdx: Int, workMode: Int, truncateBits: Int = 0) {
  // 配置Normal寄存器
  configBus.addr = 31 // FSMRouterConfIdStart
  configBus.data = (k << 0) | (groupSize << 5) | (groupNum << 9) | (cout << 13)
  configBus.en = true
  
  // 配置Special寄存器（包含truncateBits字段）
  configBus.addr = 32 // FSMRouterConfIdEnd
  configBus.data = (truncateBits << 24) | (workMode << 21) | (colIdx << 11) | (cinIdx << 0)
  configBus.en = true
}

// 4. 配置BN参数
def configureBNParams(bnParams: Array[(Int, Int)]) {
  for (i <- 0 until colSize) {
    val (mulParam, addParam) = bnParams(i)
    configBus.addr = 33 + i // bnConfIdStart + i
    configBus.data = (mulParam << 16) | addParam
    configBus.en = true
  }
}

// 5. 配置全局参数
def configureGlobal(dataFlowMode: Boolean, isFinalCinIdx: Boolean, 
                   bnEn: Boolean, actEn: Boolean, poolEn: Boolean) {
  configBus.addr = 65 // globalConfId
  configBus.data = (pingpong << 31) | (weightPingpong << 30) | (outputPingpong << 29) |
                   (poolEn << 4) | (actEn << 3) | (bnEn << 2) | (isFinalCinIdx << 1) | dataFlowMode
  configBus.en = true
}

// 6. 启动计算
def startComputation() {
  configBus.addr = 48 // runProcessId
  configBus.data = 1
  configBus.en = true
  
  // 等待计算完成
  while (!interrupts.doneInterrupt) {
    wait(1 cycle)
  }
  
  // 清除中断
  configBus.addr = 49 // interruptFreshId
  configBus.data = 1
  configBus.en = true
}

// 7. 使用示例
// 配置全systolic模式
for (i <- 0 until tileSize) {
  configureTile(i, kernelSize=2, inputId=i, workMode=0, featureMapLine=i)
}

for (i <- 0 until tileSize-1) {
  configureInterNoC(i, deliver=true, systolic=true)
}

// 配置OutRouter（包含截位控制）
configureOutRouter(k=3, groupSize=4, groupNum=4, cout=32, cinIdx=0, colIdx=0, workMode=0, truncateBits=1)

// 配置BN参数（示例）
val bnParams = Array.fill(colSize)((0x1000, 0x0100)) // (mulParam, addParam)
configureBNParams(bnParams)

// 配置全局参数
configureGlobal(dataFlowMode=false, isFinalCinIdx=true, bnEn=true, actEn=true, poolEn=false)

// 启动计算
startComputation()
```

### 配置注意事项

1. **乒乓机制**：
   - 配置前必须设置乒乓信号为false
   - 配置完成后设置乒乓信号为true使配置生效
   - 支持权重SRAM和输出SRAM的独立乒乓控制

2. **地址映射**：
   - Tile配置寄存器地址：0-15
   - InterNoC配置寄存器地址：16-30
   - FSM/OutRouter配置寄存器地址：31-32
   - BN参数寄存器地址：33-64
   - 全局配置寄存器地址：65
   - 运行控制寄存器地址：48-49

3. **工作模式**：
   - OutRouterPlanePost支持5种工作模式（0-4）
   - 模式0：默认情况（不补齐也不拼接）
   - 模式1：初始列向拼接
   - 模式2：一般列向拼接
   - 模式3/4：仅输入通道补齐

4. **数据流模式**：
   - FLOOD模式（dataFlowMode=0）：使用index 0的BN参数应用到所有列
   - NVIDIA模式（dataFlowMode=1）：为每列使用对应的BN参数

5. **后处理流水线**：
   - BN、激活函数、池化仅在isFinalCinIdx有效时执行
   - 池化操作仅在count=0的数据上执行
   - 支持2x2最大池化，stride=2

6. **中断管理**：
   - done中断：计算完成时触发
   - error中断：发生错误时触发
   - 通过interruptFresh寄存器清除中断标志

## 总结

FLOOD_Accelerator是一个高性能的多核计算加速器，采用分层架构设计，支持：

- **多核并行计算**：16个Tile并行处理，支持灵活的核间通信
- **乒乓缓冲机制**：提高数据吞吐量，支持连续计算
- **后处理流水线**：集成BN、激活函数、池化等深度学习后处理操作
- **可重构架构**：支持多种工作模式和通信方式
- **高效存储管理**：多级SRAM管理，优化数据访问模式

该加速器特别适用于深度学习推理任务，能够高效处理卷积、全连接等计算密集型操作。
    4. 精确的握手机制
    5. 可扩展的路由信息

### 5. Cluster 模块

#### 文件: `src/main/scala/cluster/cluster.scala`

- **Cluster 类**
  - 功能: 实现Tile集群的集成管理
  - 参数: 继承Config对象的所有配置参数
  - 接口信息:

    ```scala
    val io = IO(new Bundle {
      // 乒乓控制信号
      val pingpong = Input(Bool())

      // 输入NoC接口
      val inputNoc = Flipped(Decoupled(new Bundle {
        val data = Vec(rowSize, SInt(dataWidth.W))
        val writeId = UInt(tileIdWidth.W)
        val count = UInt(8.W)
        val remain = UInt(16.W)
      }))

      // 输出NoC接口
      val outputNoc = Decoupled(new Bundle {
        val data = Vec(colSize*2, SInt((outputWidth+log2Ceil(tileSize)).W))
        val tileId = UInt(tileIdWidth.W)
        val count = UInt(8.W)
        val remain = UInt(16.W)
      })

      // 配置总线接口
      val configBus = new Bundle {
        val data = Input(UInt(configBusWidth.W))
        val tileId = Input(UInt(tileIdWidth.W))
      }

      // 权重总线接口
      val weightBus = new Bundle {
        val data = Input(UInt(weightBandWidth.W))
        val tileId = Input(UInt(tileIdWidth.W))
        val addr = Input(UInt(log2Ceil(colSize * rowSize).W))
      }
    })
    ```
  - 电路工作原理:

    1. 模块实例化

       - 实例化 `tileSize`个Tile模块，ID从0开始顺序分配
       - 实例化 `tileSize-1`个InterNoC模块，ID从 `tileSize`开始顺序分配
    2. 信号连接

       - 输入NoC广播到所有Tile
       - 输出NoC通过仲裁器(Arbiter)集成多个Tile的输出
       - 配置总线和权重总线并行连接到所有Tile
       - 乒乓控制信号全局广播
    3. 互联逻辑

       - 相邻Tile通过InterNoC模块连接
       - 最下方Tile的nocDown接口保持就绪状态
       - 最上方Tile的nocUp接口保持非就绪状态
    4. 特殊处理

       - 输入NoC的ready信号由目标Tile的ready信号决定
       - 输出NoC使用优先级仲裁器处理多Tile并发输出
  - 关键特性:

    1. 支持大规模Tile集群扩展
    2. 智能总线仲裁机制
    3. 灵活的拓扑结构配置
    4. 统一的全局接口管理
    5. 可靠的边界条件处理

### 6. FSM 模块

#### 文件: `src/main/scala/machine/FSM.scala`

- **FSM 类**
  - 功能: 实现多层嵌套循环的卷积核调度与数据流控制，负责根据配置参数自动完成权重与输入数据的分发、状态管理和异常检测。
  - 参数:
    - `tileId`: 当前FSM的唯一ID号
    - 继承全局Config对象的所有配置参数
  - 接口信息:
    ```scala
    val io = IO(new Bundle {
      val pingpong = Input(Bool())
      val configBus = new Bundle {
        val data = Input(UInt(configBusWidth.W))
        val tileId = Input(UInt(tileIdWidth.W))
      }
      val inputNoc = Decoupled(new Bundle {
        val data = Vec(rowSize, SInt(dataWidth.W))
        val writeId = UInt(tileIdWidth.W)
        val count = UInt(8.W)
        val inputMode = UInt(8.W)
        val cout = UInt(kernelBlockCoutWidth.W)
        val kernelRow = UInt(kernelBlockKWidth.W)
        val remain = UInt(8.W)
      })
      val weightSramRead = new Bundle {
        val readEnable = Output(Bool())
        val readAddress = Output(UInt(log2Ceil(Config.weightSramLength).W))
        val readData = Input(UInt((rowSize * dataWidth).W))
      }
      val error = Output(Bool())
      val start = Flipped(Decoupled(Bool()))
      val done = Decoupled(Bool())
    })
    ```
  - **配置寄存器分配方式（最新版）**：
    - 使用1个配置寄存器，通过`configBus.tileId = tileId`写入。
    - 寄存器参数分配如下：
      **kernelConfig**：
        - `[kernelBlockKWidth-1:0]`：k（卷积核尺寸）
        - `[kernelBlockKWidth+groupSizeWidth-1:kernelBlockKWidth]`：groupSize（每组Tile数量）
        - `[kernelBlockKWidth+groupSizeWidth+groupNumWidth-1:kernelBlockKWidth+groupSizeWidth]`：groupNum（组数）
        - `[kernelBlockKWidth+groupSizeWidth+groupNumWidth+kernelBlockCinWidth-1:kernelBlockKWidth+groupSizeWidth+groupNumWidth]`：cinIdx（当前输入通道组的序号）
        - `[kernelBlockKWidth+groupSizeWidth+groupNumWidth+kernelBlockCinWidth+kernelBlockCoutWidth-1:kernelBlockKWidth+groupSizeWidth+groupNumWidth+kernelBlockCinWidth]`：cout（输出通道数）
        - 其他位预留扩展
    - **注意**：各参数位宽由Config对象定义，需保证configBusWidth足够容纳所有参数。
  - **典型用法**：
    1. 写入kernel配置寄存器：
       ```scala
       // kernelConfig: k, groupSize, groupNum, cinIdx, cout
       val kernelConfig = (cout << (kernelBlockKWidth + groupSizeWidth + groupNumWidth + kernelBlockCinWidth)) |
                          (cinIdx << (kernelBlockKWidth + groupSizeWidth + groupNumWidth)) |
                          (groupNum << (kernelBlockKWidth + groupSizeWidth)) |
                          (groupSize << kernelBlockKWidth) |
                          k
       writeConfig(dut, tileId, kernelConfig)
       ```
    2. 拉高start.valid启动FSM，在FSM拉起start.ready信号后才有效
    3. FSM自动完成多层循环调度，期间自动分发权重和输入数据
    4. 运算完成后拉高done.valid（done.bits恒为true），外部必须拉高done.ready信号完成握手，否则无法发起下一次start握手
    5. 若发生异常，error信号拉高
  - **多层嵌套循环结构**：
    1. **第一层（最内层）循环**：Cluster结构的输入写满（groupSize次写入），对应卷积核参数的输入通道
    2. **第二层循环**：卷积核2D结构一行的遍历（k次写满）
    3. **第三层循环**：卷积核所有行的遍历（k次行遍历）
    4. **第四层循环**：卷积核块的遍历（cout次行遍历）
    5. **特殊处理**：k=1时跳过第2、3层循环结构
  - **注意事项**：
    1. 配置参数必须严格按照上述分配方式拼接和分段，否则FSM无法正确解析
    2. pingpong机制：配置前必须先将pingpong信号设置为false，配置完成后拉高为true，等待2个周期生效
    3. 权重SRAM为同步读，地址提前一拍，FSM内部已自动处理
    4. inputNoc.valid为寄存器结构，ready拉低时valid也拉低，确保数据时序安全
    5. 超时检测：若inputNoc.ready长时间未响应，FSM自动进入error状态
    6. 错误检查：k不能大于2倍groupNum，否则触发errorFlag1
  - **关键特性**：
    1. 支持多层嵌套循环的自动调度
    2. 灵活的可重构参数配置
    3. 乒乓配置寄存器机制
    4. 完善的异常检测与恢复
    5. 兼容Cluster与SRAM等模块的标准接口
    6. 支持卷积核尺寸可重构（1-16）
    7. 权重缓存与输出缓存的乒乓更新解耦合

### 7. MultipleDetector 模块

#### 文件: `src/main/scala/machine/MultipleDetector.scala`

- **MultipleDetector 类**
  - 功能: 快速检测数A+1是否是数B的整数倍的专用模块，用于优化Tile调度和资源分配
  - 参数: 继承全局Config对象的tileSize参数
  - 接口信息:
    ```scala
    val io = IO(new Bundle {
      val A = Input(UInt(tileIdWidth.W))  // 输入数A
      val B = Input(UInt(tileIdWidth.W))  // 输入数B
      val isValid = Output(Bool())      // A+1是否是B的整数倍
      val multiple = Output(UInt(tileIdWidth.W))  // A=1与B之间的倍数关系（如果isValid为true）
    })
    ```
  - **算法原理**：
    1. **特殊情况处理**：
       - B=0时：非法输入，返回false
       - B=1时：任何数都是1的倍数，返回true，倍数为A+1
       - B=2时：检查A+1是否为偶数，通过检查A的第0位实现
    2. **一般情况处理（B≥3）**：
       - 计算TileSize内B的所有倍数
       - 与A+1进行比较
       - 使用优先级编码器找到匹配的倍数
  - **电路工作原理**：
    1. **输入处理**：
       - 计算A+1作为比较基准
       - 根据B的值选择不同的处理路径
    2. **特殊情况检测**：
       - 使用when-elsewhen-otherwise结构处理B=0、B=1、B=2的情况
       - B=2时通过位操作检查奇偶性
    3. **倍数计算**：
       - 生成tileSize个比较器，每个检查一个倍数
       - 使用VecInit创建比较结果向量
    4. **优先级编码**：
       - 使用PriorityEncoder模块找到最高优先级的匹配
       - 输出匹配的倍数和有效性标志
  - **位宽计算**：
    - tileIdWidth = 2 * log2Ceil(tileSize)
    - 高半表示NoCId，低半表示TileId
    - 与Cluster模块的tileIdWidth定义保持一致
  - **关键特性**：
    1. 高效的硬件实现，支持单周期检测
    2. 完整的边界条件处理
    3. 优化的倍数计算算法
    4. 与系统其他模块的位宽兼容
    5. 支持大规模Tile集群的调度优化

- **PriorityEncoder 类**
  - 功能: 优先级编码器，输入n位向量，输出最高位1的位置
  - 参数: n - 输入向量长度
  - 接口信息:
    ```scala
    val io = IO(new Bundle {
      val in = Input(Vec(n, Bool()))
      val out = Output(UInt(log2Ceil(n).W))
    })
    ```
  - **实现方式**：
    - 使用chisel3.util.PriorityEncoder
    - 自动处理位宽计算
    - 支持任意长度的输入向量

### 8. OutRouterPlane 模块

#### 文件: `src/main/scala/machine/OutRouterPlane.scala`

- **OutRouterPlane 类**
  - 功能: 引入嵌入平面处理功能的高级路由模块，使用3级流水线架构进行数据（输入通道）补齐与（列、行向拼接），支持复杂的特征图Block拼接操作。
  - 参数:
    - `tileId`: 当前OutRouterPlane的唯一ID号，与FSM的ID号相同
    - 继承全局Config对象的所有配置参数
  - 接口信息:

    ```scala
    val io = IO(new Bundle {
      val pingpong = Input(Bool())
      val configBus = new Bundle {
        val data = Input(UInt(configBusWidth.W))
        val tileId = Input(UInt(tileIdWidth.W))
      }
      val outputNoc = Flipped(Decoupled(new Bundle {
        val data = Vec(colSize, SInt((outputWidth+log2Ceil(tileSize)+log2Ceil(colSize)).W))
        val featureMapLine = UInt(tileIdWidth.W)
        val count = UInt(8.W)
        val cout = UInt(kernelBlockCoutWidth.W)
        val kernelRow = UInt(kernelBlockKWidth.W)
        val remain = UInt(16.W)
      }))
      val done = Decoupled(Bool())
      
      // 双SRAM接口
      val outputSramWrite = new Bundle {
        val enable = Output(Bool())
        val address = Output(UInt(outputAddrWidth.W))
        val data = Output(Vec(colSize, UInt(outputBufferDataWidth.W))) // 使用Vec格式，数据位宽为outputBufferDataWidth
      }
      val outputSramRead = new Bundle {
        val enable = Output(Bool())
        val address = Output(UInt(outputAddrWidth.W))
        val data = Input(Vec(colSize, UInt(outputBufferDataWidth.W))) // 使用Vec格式，数据位宽为outputBufferDataWidth
      }
      val jointSramWrite = new Bundle {
        val enable = Output(Bool())
        val address = Output(UInt(log2Ceil(Config.jointSramLength).W))
        val writeData = Output(Vec(colSize, UInt(outputBufferDataWidth.W))) // 使用Vec格式，数据位宽为outputBufferDataWidth
      }
      val jointSramRead = new Bundle {
        val enable = Output(Bool())
        val address = Output(UInt(log2Ceil(Config.jointSramLength).W))
        val readData = Input(Vec(colSize, UInt(outputBufferDataWidth.W))) // 使用Vec格式，数据位宽为outputBufferDataWidth
      }
    })
    ```

  - **配置寄存器信息域划分（最新版）**
    
    配置寄存器（32位）按照从低位到高位的顺序包含以下信息域：

    | 位段范围                                                               | 字段名            | 位宽                  | 功能说明                                        |
    |-------------------------------------------------------------------------|------------------|-----------------------|------------------------------------------------|
    | [kernelBlockKWidth-1:0]                                                | k                | kernelBlockKWidth     | 卷积核窗口尺寸，决定高向拼接范围                |
    | [kernelBlockKWidth+groupSizeWidth-1:kernelBlockKWidth]                 | groupSize        | groupSizeWidth        | 一组内的Tile数量，影响输入通道分组                |
    | [kernelBlockKWidth+groupSizeWidth+groupNumWidth-1:kernelBlockKWidth+groupSizeWidth] | groupNum | groupNumWidth | Cluster内组数，决定outputSram存储范围           |
    | [+cinIdxWidth-1:+groupNumWidth]                                        | cinIdx           | cinIdxWidth           | 当前特征图Block的起始通道索引，用于通道补齐      |
    | [+kernelBlockCoutWidth-1:+cinIdxWidth]                                 | cout             | kernelBlockCoutWidth  | 输出结果图Block的通道数，影响地址计算            |
    | [+resolutionColIdxWidth-1:+kernelBlockCoutWidth]                       | resolutionColIdx | resolutionColIdxWidth | 特征图Block在整个图像分辨率中的列索引，用于列向拼接 |
    | [+workModeWidth-1:+resolutionColIdxWidth]                              | workMode         | workModeWidth(=2)     | 工作模式，控制拼接和补齐行为                     |

    **配置寄存器打包示例**：
    ```scala
    val kernelConfig = (workMode << (kernelBlockKWidth + groupSizeWidth + groupNumWidth + cinIdxWidth + kernelBlockCoutWidth + resolutionColIdxWidth)) |
                      (resolutionColIdx << (kernelBlockKWidth + groupSizeWidth + groupNumWidth + cinIdxWidth + kernelBlockCoutWidth)) |
                      (cout << (kernelBlockKWidth + groupSizeWidth + groupNumWidth + cinIdxWidth)) |
                      (cinIdx << (kernelBlockKWidth + groupSizeWidth + groupNumWidth)) |
                      (groupNum << (kernelBlockKWidth + groupSizeWidth)) |
                      (groupSize << kernelBlockKWidth) |
                      k
    ```

  - **工作模式详细说明**
    - **workMode=0**: 默认模式，不进行任何补齐或拼接操作
      - 适用场景：特征图Block为顶端最左侧，且cin=0的Block
      - 数据处理：直接将outputNoc数据写入对应的SRAM
    - **workMode=1**: 初始列向拼接模式
      - 适用场景：特征图Block为非顶端但是最左侧的Block
      - 数据处理：需要进行高向拼接，不进行列向拼接
    - **workMode=2**: 一般列向拼接模式
      - 适用场景：特征图Block为非顶端且非左侧的Block
      - 数据处理：同时进行高向拼接和列向拼接
    - **workMode=3**: 仅输入通道补齐模式
      - 适用场景：特征图Block为cin!=0的Block，需要与之前通道的结果累加
      - 数据处理：从对应位置读取已有数据进行累加

  - **双SRAM缓存结构详细设计**
    
    **outputSram（主要结果缓存）**：
    - **存储内容**: 结果图Block的主体部分（第0~groupNum行）
    - **地址计算**: `outputBaseAddr = (cout * (groupNum + 1)) << 1`
    - **写地址**: `outputWriteAddr = outputBaseAddr + ((k - kernelRow) << 1) + (featureMapLine << 1) + count`
    - **写使能条件**: `position <= groupNum`，其中`position = featureMapLine + (k - kernelRow)`
    - **存储器结构**: `colSize`个SRAM阵列，每个单元32bit位宽，共享地址映射
    - **数据接口**: 使用Vec格式，`Vec(colSize, UInt(outputBufferDataWidth.W))`，数据位宽为outputBufferDataWidth（32位）

    **jointSram（边界拼接缓存）**：
    - **存储内容**: 结果图Block的高向冗余部分（第groupNum+1~groupNum+k行）和列向拼接缓存区
    - **基地址**: `jointBaseAddr = resolutionColIdx * (cout+1) * k + cout * k`
    - **拼接缓存偏移**: `jointBufferBias = (maxResolutionCol/colSize + 1) * (cout + 1) * k`
    - **写地址**: `jointWriteAddr = jointBaseAddr + (position-groupNum-1) + Mux(count === 0, 0, jointBufferBias)`
    - **写使能条件**: `position > groupNum`
    - **双区域设计**: 结果区域和拼接缓存区，支持复杂的列向拼接操作
    - **数据接口**: 使用Vec格式，`Vec(colSize, UInt(outputBufferDataWidth.W))`，数据位宽为outputBufferDataWidth（32位）

  - **3级流水线架构详细功能**
    
    **Stage 0（地址计算与信号缓存级）**：
    - **主要功能**: 
      - 缓存outputNoc输入数据和控制信号
      - 计算所有读写地址（outputWriteAddr, jointWriteAddr, outputReadAddr等）
      - 生成读写使能信号（outputWriteEn, jointWriteEn, outputReadEn等）
      - 数据量化截断（truncateData函数，截断为finalWidth位宽）
    - **关键操作**: 规避行读与列读地址冲突，为后续级准备地址信息
    - **信号传递**: 使用RegNext实现所有信号的时序传递

    **Stage 1（高向拼接读取与累加级）**：
    - **主要功能**:
      - 执行通道补齐和高向拼接的SRAM读取操作
      - 完成高向拼接数据的累加运算
      - 为Stage 2的列向拼接读取做准备
    - **累加逻辑**: `s1_mergedData(i) = s1_currentData(i) + s1_jointReadElements(i) + s1_outputReadElements(i)`
    - **读取条件**:
      - outputSram读取：workMode=3（通道补齐）或workMode=2且position≤groupNum且count=0（列向拼接）
      - jointSram高向读取：workMode=3且position>groupNum（通道补齐）或workMode=1/2且position<k（高向拼接）
    - **数据处理**: 将读取的32bit×colSize数据拆分为独立元素进行累加

    **Stage 2（列向拼接累加与写回级）**：
    - **主要功能**:
      - 执行列向拼接的SRAM读取和累加运算  
      - 完成最终数据的SRAM写回操作
      - 处理数据格式转换（SInt到UInt，向量到总线）
    - **列向拼接逻辑**: `s2_mergedData(i) = s2_currentData(i) + s2_jointReadElements(i)`
    - **列向拼接条件**: workMode=2且position>groupNum且count=0
    - **写回操作**:
      - outputSram写回：s2_valid && s2_outputWriteEn
      - jointSram写回：s2_valid && s2_jointWriteEn
    - **数据转换**: 通过Cat函数将Vec格式转换为总线格式

  - **关键地址计算算法**
    
    **position计算**：`position = featureMapLine + (k - kernelRow)`
    - 作用：确定当前数据在结果图中的绝对行位置
    - 用途：判断数据应写入outputSram还是jointSram

    **读地址计算**：
    - **outputReadAddr**: 用于列向拼接，读取相邻Block的数据
    - **jointHeightReadAddr**: 用于高向拼接和通道补齐
    - **jointWidthReadAddr**: 用于列向拼接的缓存区读取

  - **数据流控制与时序**
    - **流水线特性**: 始终运行，不依赖valid信号驱动
    - **使能控制**: 通过En信号掩码控制有效数据处理
    - **握手机制**: outputNoc.ready始终为true，支持连续数据流
    - **完成检测**: 基于count、kernelRow、cout、featureMapLine的综合判断

  - **优化特性**
    1. **并行处理**: colSize个数据元素同时处理
    2. **流水线化**: 3级流水线支持高吞吐量数据处理
    3. **灵活拼接**: 支持高向和列向的复杂拼接模式
    4. **地址优化**: 预计算地址减少运行时延迟
    5. **错误避免**: Stage 0空级避免读写冲突

---

### MacMachine 模块

#### 文件: `src/main/scala/machine/MacMachine.scala`

- **MacMachine 类**
  - 功能: 实现多核加速器的顶层集成，封装 FSM、Cluster、OutRouterPlane 三大模块，统一管理配置、特征图、权重、输入输出等全流程数据流。
  - 接口信息:

    ```scala
    val io = IO(new Bundle {
      val pingpong = Input(Bool())
      val configBus = new Bundle {
        val data = Input(UInt(Config.configDataWidth.W))
        val addr = Input(UInt(Config.configAddrWidth.W))
        val en = Input(Bool())
      }
      val featureMapBus = new Bundle {
        val data = Input(UInt(Config.featureMapBandWidth.W))
        val tileId = Input(UInt((2*log2Ceil(Config.tileSize)).W))
        val addr = Input(UInt(log2Ceil(Config.colSize * Config.rowSize).W))
        val en = Input(Bool())
      }
      val start = Flipped(Decoupled(Bool())) // 启动信号
      val FSMdone = Decoupled(Bool())        // FSM完成信号
      val OutRouterdone = Decoupled(Bool())  // OutRouter完成信号
      val weightSramRead = new Bundle {
        val readEnable = Output(Bool())
        val readAddress = Output(UInt(weightAddrWidth.W))
        val readData = Input(UInt((rowSize * dataWidth).W))
      }
      val outputSramWrite = new Bundle {
        val writeEnable = Output(Bool())
        val writeAddress = Output(UInt(outputAddrWidth.W))
        val writeData = Output(UInt((colSize * outputBufferDataWidth).W))
      }
      val outputSramRead = new Bundle {
        val readEnable = Output(Bool())
        val readAddress = Output(UInt(outputAddrWidth.W))
        val readData = Input(UInt((colSize * outputBufferDataWidth).W))
      }
      val jointSramWrite = new Bundle {
        val writeEnable = Output(Bool())
        val writeAddress = Output(UInt(log2Ceil(Config.jointSramLength).W))
        val writeData = Output(UInt((colSize * outputBufferDataWidth).W))
      }
      val jointSramRead = new Bundle {
        val readEnable = Output(Bool())
        val readAddress = Output(UInt(log2Ceil(Config.jointSramLength).W))
        val readData = Input(UInt((colSize * outputBufferDataWidth).W))
      }
      val error = Output(Bool())
    })
    ```

  - **全局配置寄存器（非乒乓）**
    
    MacMachine 模块包含一个全局配置寄存器，用于控制整个系统的行为模式。**注意：此寄存器为非乒乓寄存器，与FSM、Cluster、OutRouter等模块的乒乓配置寄存器不同。**

    **寄存器地址**: `Config.maxMachineApbEnd` (0x00411FFF)
    
    **寄存器位域分配（32位）**:
    
    | 位段范围 | 字段名     | 位宽 | 功能说明                           |
    |----------|------------|------|-----------------------------------|
    | [7:0]    | actionMode | 8位  | 全局行为模式控制，用于控制整个系统的计算模式 |
    | [31:8]   | remain     | 24位 | 预留扩展位                         |

    **配置示例**:
    ```scala
    // 写入全局配置寄存器
    configBus.addr := 0x00411FFF.U
    configBus.data := actionModeValue
    configBus.en := true.B
    ```

    **与乒乓配置寄存器的区别**:
    - **乒乓配置寄存器**: 用于FSM、Cluster、OutRouter等子模块的配置，需要先设置pingpong=false，配置完成后设置pingpong=true生效
    - **全局配置寄存器**: 直接写入生效，无需乒乓机制，用于全局行为控制

  - **时序与模块协同**
    - start信号同时驱动FSM和OutRouterPlane，二者均需握手后进入工作状态
    - FSMdone和OutRouterdone分别由FSM和OutRouterPlane拉起
    - 错误信号为FSM和OutRouterPlane的或
    - 配置、特征图、权重、SRAM接口均为直连
    - 全局配置寄存器通过configBus直接写入，无需乒乓机制

---

（其它模块如Cluster、FSM等如无接口/寄存器/时序重大变化可保持原文档描述）

## 测试

测试文件位于 `src/test/scala/core/` 目录下，包括 `CIMCoreTest.scala` 和 `MACTreeTest.scala`，用于验证核心模块的功能和性能。

## 使用说明

1. 克隆项目到本地。
2. 使用 `sbt` 构建工具编译和运行项目。
3. 运行测试以验证模块功能
4. 各个模块的测试代码的命名规则为<模块名>Test.scala
5. 从tmp中拉取对应的测试代码运行run test进行仿真
6. 在顶层目录下执行 sbt相关指令
7. 仿真波形位于test_run_dir目录下
8. 统一：valiid-ready信号，均常闭，一般情况下，ready在识别到valid后才能被拉起，valid识别到ready信号后才能拉低

## 联系信息

- 作者: 陈挺然
- 邮箱: 18073369150@buaa.edu.cn

## 模块更新说明

### SRAM接口格式更新（最新版本）

在最新版本中，所有SRAM接口的数据字段已从UInt格式更新为Vec格式，以提供更好的类型安全性和代码可读性：

#### 主要变化
1. **数据格式统一**: 所有SRAM接口的data字段现在使用`Vec(colSize, UInt(outputBufferDataWidth.W))`格式
2. **位宽标准化**: 数据位宽统一为`outputBufferDataWidth`（32位）
3. **类型安全**: 使用Vec类型提供编译时类型检查，避免运行时错误

#### 受影响的模块
- **OutRouterPlane**: outputSram和jointSram接口
- **MacMachine**: 顶层SRAM接口封装
- **测试代码**: MacMachineTest等测试文件已相应更新

#### 接口示例
```scala
// 旧格式（已废弃）
val data = Output(UInt((outputBufferDataWidth * colSize).W))

// 新格式（当前使用）
val data = Output(Vec(colSize, UInt(outputBufferDataWidth.W)))
```

#### 优势
- **类型安全**: 编译时检查数据类型匹配
- **代码清晰**: 直接反映数据的向量特性
- **性能提升**: 避免不必要的数据打包/解包操作
- **维护性**: 更容易理解和维护的代码结构

### DynamicTruncateData 模块集成

在最新版本中，`OutRouterPlanePost` 模块集成了优化后的 `DynamicTruncateData` 模块，用于动态截位控制：

#### 主要特性
1. **动态截位控制**：通过 `truncateBits` 寄存器字段实现运行时截位位数控制
2. **位宽自适应**：根据输入输出位宽自动选择最优处理策略
3. **性能优化**：在28nm工艺下时钟频率从526MHz提升到625MHz
4. **硬件资源优化**：简化四舍五入逻辑，减少MUX开销

#### 配置寄存器更新
- **Special配置寄存器**新增 `truncateBits` 字段（4位）
- 位域分配：`[31:28] - truncateBits (4位) + [27:25] - workMode (3位) + [24:14] - colIdx (11位) + [13:3] - cinIdx (11位) + [2:0] - 预留位`
- **参数语义更新**：`DynamicTruncateData` 的输出位宽与输入位宽一致，`outputWidth` 表示有效位宽

#### 使用方式
```scala
// 设置截位位数为1
val specialConfig = (BigInt(1) << 24) | (workMode << 21) | (colIdx << 11) | cinIdx
writeConfig(dut, specialConfig, Config.FSMRouterConfIdEnd)
```

### OutRouterPlane 替换 OutRouter

在最新版本中，原始的 `OutRouter` 模块已被功能更强大的 `OutRouterPlane` 模块所替代。主要改进包括：

1. **增强的平面处理功能**：支持输入通道补齐与列、行向拼接操作
   - 高向拼接：处理卷积边界重叠区域的数据累加
   - 列向拼接：实现相邻特征图Block的水平拼接
   - 通道补齐：支持多输入通道的数据累加操作

2. **双SRAM缓存架构**：引入专门设计的双缓存结构
   - **outputSram**：存储主要结果数据（0~groupNum行）
   - **jointSram**：处理边界数据和拼接缓存（groupNum+1~groupNum+k行）
   - 每个SRAM支持colSize个并行存储单元，32bit位宽

3. **3级流水线处理**：采用精心设计的流水线架构
   - **Stage 0**：地址计算与信号缓存，避免读写冲突
   - **Stage 1**：高向拼接读取与累加，处理垂直方向数据融合
   - **Stage 2**：列向拼接累加与写回，完成水平方向数据融合和最终写回

4. **灵活的工作模式**：支持4种精确定义的工作模式
   - **Mode 0**：默认模式，直接数据传递
   - **Mode 1**：初始列向拼接，处理左边界Block
   - **Mode 2**：一般列向拼接，处理中间Block的复杂拼接
   - **Mode 3**：通道补齐模式，处理多通道累加

5. **扩展的配置接口**：增强的配置寄存器设计
   - 新增 `resolutionColIdx` 字段：支持全局坐标定位
   - 新增 `workMode` 字段：精确控制处理模式
   - 完整的 `cout` 和 `kernelRow` 信号：支持复杂卷积操作
   - 32位配置寄存器的精确位域划分

6. **高性能特性**：
   - 并行数据处理：colSize个元素同时处理
   - 预计算地址：减少运行时延迟
   - 连续数据流：支持无暂停的数据处理
   - 智能使能控制：基于工作模式的精确控制逻辑

### FSM 模块接口更新

FSM模块的接口也进行了相应更新：
1. 增加了 `cout` 和 `kernelRow` 信号域
2. 配置寄存器参数扩展，支持 `groupNum` 和 `cinIdx` 参数
3. 权重SRAM接口信号名称统一化

### MacMachine 模块全局配置寄存器

在最新版本中，MacMachine 模块新增了全局配置寄存器功能：

#### 主要变化
1. **新增全局配置寄存器**: 地址为 `Config.maxMachineApbEnd` (0x00411FFF)
2. **非乒乓机制**: 与子模块的乒乓配置寄存器不同，全局配置寄存器直接写入生效
3. **行为模式控制**: 通过 `actionMode` 字段控制整个系统的计算模式
4. **配置总线接口更新**: 增加了 `addr` 和 `en` 信号，支持地址寻址和使能控制

#### 接口变化
```scala
// 旧接口
val configBus = new Bundle {
  val data = Input(UInt(Config.configBusWidth.W))
  val tileId = Input(UInt((2*log2Ceil(Config.tileSize)).W))
}

// 新接口
val configBus = new Bundle {
  val data = Input(UInt(Config.configDataWidth.W))
  val addr = Input(UInt(Config.configAddrWidth.W))
  val en = Input(Bool())
}
```

#### 使用方式
- **全局配置寄存器**: 直接通过 `configBus` 写入，无需乒乓机制
- **子模块配置**: 仍使用乒乓机制，先设置 `pingpong=false`，配置完成后设置 `pingpong=true`

#### 优势
- **简化配置流程**: 全局配置无需乒乓机制，配置更简单
- **灵活控制**: 支持运行时动态调整系统行为模式
- **统一管理**: 在顶层统一管理全局配置，便于系统级控制

## 可能存在的问题

### 1. Cluster的inputNoc.ready逻辑问题

当前Cluster模块中inputNoc.ready信号的生成逻辑为：
```scala
io.inputNoc.ready := tiles.map(tile => tile.io.inputNoc.ready && (tile.io.inputId === io.inputNoc.bits.writeId)).reduce(_ || _)
```

这种实现存在以下潜在问题：
1. 使用或逻辑（`reduce(_ || _)`）可能导致数据丢失
   - 当多个Tile的inputId与writeId匹配时，只要有一个Tile ready就会拉高inputNoc.ready
   - 这可能导致数据被发送到未完全准备好的Tile
2. 可能引发数据竞争
   - 不同Tile的ready信号状态可能不一致
   - 使用或逻辑可能导致数据在错误的时机被发送
3. 建议修改为与逻辑
   - 只有当所有匹配的Tile都ready时，才拉高inputNoc.ready
   - 确保数据能够被所有目标Tile正确接收

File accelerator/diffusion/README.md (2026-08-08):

# SD1.5 ResNetBlock Accelerator Tooling

This directory contains the Python-side reference tooling for the AXKU15
Stable Diffusion 1.5 U-Net ResNetBlock accelerator. Task 1 freezes the
legacy FLOOD configuration and records the local toolchain rather than
changing the existing CNN accelerator behavior.

## Environment baseline

Use Python 3.10 or newer. Install the base test/runtime dependencies and,
when local SD1.5 tensor capture is required, the optional model dependencies:

```powershell
python -m pip install -e .
python -m pip install -e ".[model]"
```

Run the environment contract test and write the local baseline report:

```powershell
python -m pytest tests/test_environment.py -v
python scripts/check_environment.py
```

The report is written to `results/baseline/environment.json`. It captures
Python, NumPy, PyTorch, Java, SBT, and Vivado versions. Missing external
tools are represented as `"unavailable"`; they do not make the collector
non-deterministic or prevent later software-only work.

The frozen legacy FLOOD settings are read directly from
`../src/main/scala/core/Config.scala`: `rowSize=32`, `colSize=32`,
`dataWidth=8`, `pipeline=2`, `tLatency=4`, `compressionFactor=4`, and
`tileSize=16`.

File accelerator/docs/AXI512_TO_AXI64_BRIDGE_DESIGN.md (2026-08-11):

# 512-bit MIG application to 64-bit AXI4 bridge design

## Purpose and scope

This document defines the first integration seam between the diffusion
accelerator's 512-bit `MigAppPort` and the official AXKU15 DDR4 demo's 64-bit
AXI4 slave.  It is a simulation-first bridge: it neither changes the vendor
`ddr4_core.xci` nor asserts that the board's physical DDR4 interface has
already passed calibration.

The bridge accepts one `MigAppRequest` at a time, which matches the existing
`MigAppTransfer` serialization contract.  It expands a 512-bit request into
eight 64-bit AXI beats and returns one 512-bit response for a read.

## Alternatives considered

1. **Directly modify the vendor demo's `mem_test` traffic generator.** This
   would make early hardware experiments quick, but mixes board-specific
   vendor sources with accelerator protocol logic and is difficult to unit
   test.  It is not selected.
2. **Use the vendor IP's 512-bit app interface.** The generated demo exposes a
   64-bit AXI4 slave at its top level; reaching a private/generated app port
   would bind the accelerator to IP internals and prevent use of the known
   wrapper.  It is not selected.
3. **Create a standalone, Chisel-tested 512-to-64 AXI4 master bridge.** This
   isolates protocol conversion, allows deterministic simulation with AXI
   handshakes, and leaves the vendor project intact.  This is the selected
   approach.

## Interface and transfer rules

- The bridge input is `Decoupled[MigAppRequest]`; it is ready only while no
  request is active.
- A write accepts exactly one 512-bit request and issues one AXI write address
  plus eight 64-bit write-data beats.  Byte strobes are the corresponding
  eight slices of `writeMask`; an asserted MIG mask bit disables the matching
  AXI byte strobe.
- A read issues one AXI read address for eight 64-bit beats and collects them
  in increasing beat order: AXI beat 0 becomes response bits `[63:0]`, and
  beat 7 becomes `[511:448]`.
- The accelerator's current 29-bit app address is treated as a byte address;
  the eight AXI beats use `address + 8 * beatIndex`.  The bridge rejects no
  address in the first version, but test vectors will use 64-byte-aligned
  inputs.
- AXI `AW`, `W`, `B`, `AR`, and `R` each obey Decoupled semantics.  Address,
  data, and response state must remain stable while the corresponding ready
  signal is low.
- Exactly one request is outstanding.  This preserves the ordering and
  completion behavior expected by `MigAppRequestArbiter` and avoids assigning
  AXI IDs or reordering rules in the initial milestone.

## Error and reset handling

- The first bridge milestone treats non-OKAY AXI `BRESP`/`RRESP` as a sticky
  error output while still draining the response channel.  It must not report
  a successful `done` for a failed write, nor a valid read response for a
  failed read.
- Reset drops an unfinished transaction and returns the request port to idle.
- Board traffic must remain externally gated by the vendor
  `c0_init_calib_complete` signal; that signal is outside this unit and is
  connected in the later AXKU15 wrapper milestone.

## Tests and acceptance criteria

The implementation is test-first and must demonstrate each of the following:

1. A 512-bit write produces one aligned AXI write address and eight ordered
   64-bit data beats with correctly inverted byte-enable bits.
2. Independent `AWREADY` and `WREADY` backpressure does not duplicate or drop
   an address or data beat.
3. Eight ordered AXI read beats are reassembled into the original 512-bit
   word and presented through a retained response handshake.
4. A response error prevents normal completion and raises the sticky error.
5. The focused Chisel test suite and Verilog generation both pass before the
   bridge is connected to the vendor project.

## Deferred work

- Copying or regenerating the vendor XCI/constraints.
- A board wrapper that connects `c0_init_calib_complete`, clocks, resets, and
  AXI physical pins.
- On-board calibration and read/write validation, which are required before
  treating the 64-bit demo configuration as usable hardware.
- Multiple outstanding transactions and bandwidth optimization.

## Verification record

The standalone bridge was verified in simulation on 2026-08-11 with six
`MigAppToAxi64BridgeSpec` cases: write split/masking, independent write-channel
backpressure, AXI write error, eight-beat read reassembly with a retained
response, AXI read error, and read-error draining through RLAST.  The combined
bridge, `MigAppTransfer`, and `MigAppRequestArbiter` scope passed 10/10 tests.  The real
`GenerateDiffusionAccelTopVerilog` generator also completed successfully.

This evidence covers the Chisel bridge only.  It does not modify the vendor
XCI, establish a board clock/reset wrapper, or prove DDR4 calibration or data
integrity on AXKU15 hardware.

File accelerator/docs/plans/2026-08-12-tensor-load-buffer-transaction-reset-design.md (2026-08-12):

# Tensor Load Buffer Transaction Reset Design

**Date:** 2026-08-12  
**Status:** Implemented and simulation-validated

## Problem

`TensorLoadBuffer` resets its write address when a new DMA load begins, but
does not clear the underlying `TensorTileBuffer` occupancy counter.  Tensor
reads also do not decrement that counter.  Consequently, a completed
ResNetBlock transaction can leave a nonzero `tensorBufferOccupancy`, which
makes its transaction boundary ambiguous and eventually risks artificial
buffer-full backpressure across repeated runs.

## Goal

Give every accepted tensor-DMA transaction a fresh logical tile-buffer state.
When `TensorLoadBuffer.io.start` begins a new load, the tile buffer's write
address and occupancy must be reset before the first incoming lane is stored.
The first transaction's data need not be physically erased because the next
load overwrites the addressed range; only its logical visibility and capacity
must reset.

## Design

Add a synchronous `clear` input to `TensorTileBuffer`.  On `clear`, it resets
its write address and occupancy to zero; it must not issue a read or write
handshake in that cycle.  Connect `TensorLoadBuffer.io.start` directly to this
new `clear` input.

`TensorLoadBuffer` already resets `address` to zero on `start` and does not
accept DMA data until its following active cycle.  Thus the clear cycle cannot
drop an accepted input lane.  The existing buffer RAM contents remain intact
and become inaccessible until rewritten by the new transaction.

No external port on `DiffusionAccelTop` changes.  The visible effect is that
`tensorBufferOccupancy` becomes zero in the clear cycle induced by an accepted
new tensor-DMA transaction, before its first DMA beat is stored, then begins
counting only that transaction's lanes.

## Verification

1. Extend `TensorTileBufferSpec` with a failing test that writes data, asserts
   nonzero occupancy, pulses `clear`, then requires zero occupancy and no
   data handshake during clear.
2. Extend `TensorLoadBufferSpec` with a failing test that completes one load,
   starts a second load, and requires occupancy to return to zero before the
   second DMA beat is accepted.
3. Complete the consecutive AXI64 ResNetBlock E2E test.  It must require zero
   `tensorBufferOccupancy` between the two runs, verify transaction B's
   distinct statistics/output/writeback, preserve transaction A writeback,
   and observe all four read and write burst bases in order.
4. Run focused buffer, E2E, AXI64, compute, and rsqrt regressions, then
   elaborate the unchanged AXI64 top through Chisel.

## Recorded evidence

On 2026-08-12, the focused command below completed with 26 passing tests in
11 suites and no failures:

```powershell
sbt 'testOnly FLOOD_Accelerator.diffusion.TensorTileBufferSpec FLOOD_Accelerator.diffusion.TensorLoadBufferSpec FLOOD_Accelerator.diffusion.ResNetBlockE2ETestSupportSpec FLOOD_Accelerator.diffusion.DiffusionAccelTopResNetBlockE2ESpec FLOOD_Accelerator.diffusion.Axi64MemoryModelSpec FLOOD_Accelerator.diffusion.DiffusionAccelTopAxi64Spec FLOOD_Accelerator.diffusion.MigAppToAxi64BridgeSpec FLOOD_Accelerator.diffusion.ConvToGroupNormStatsPathSpec FLOOD_Accelerator.diffusion.Conv2ResidualPathSpec FLOOD_Accelerator.diffusion.GroupNormActivationPathSpec FLOOD_Accelerator.diffusion.RsqrtUnitReferenceSpec'
```

The direct tile-buffer test confirms that `clear` accepts neither a read nor a
write, clears logical valid/occupancy/high-water/pending state, and lets the
same address be written again as the first lane of a new transaction.  The
load-buffer test confirms that the `start`/clear cycle holds DMA input
`ready` low, exposes zero occupancy, and then accepts the second load; its
32 lanes become the new logical contents.

The consecutive top-level test checks the same boundary after the second
transaction's tensor-read command is accepted and before its first payload is
accepted.  At that point `tensorBufferOccupancy` is zero.  It does not claim
that occupancy is zero during the idle interval before the new command.

`sbt 'runMain FLOOD_Accelerator.diffusion.GenerateDiffusionAccelAxi64TopVerilog'`
also completed successfully.  The elaboration generated no tracked source
change.
## Constraints and exclusions

- The change is restricted to `TensorTileBuffer`, its direct
  `TensorLoadBuffer` connection, and tests/evidence.
- It must not alter AXI64 protocol, fixed-point arithmetic, compute phase
  ordering, vendor AXKU15 demo/IP, Vivado flow, bitstream generation, or FPGA
  programming.
- This establishes a resettable logical tensor-buffer boundary, not RAM data
  sanitization, floating-point SD1.5 equivalence, arbitrary-shape support, or
  hardware performance/timing closure.

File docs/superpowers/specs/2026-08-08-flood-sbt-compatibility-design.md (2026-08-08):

# FLOOD SBT 兼容性与动态验证修复设计

## 背景

FLOOD 基线仅包含 `build.sbt`，没有 `project/build.properties`。安装的 SBT 2.0.6 因此在首次运行时自动创建 `sbt.version=2.0.6`，并在 Windows 的 `(Compile / packageBin)` 阶段持续失败：临时 JAR 无法原子替换为 `accelerator_2.12-0.1.0-SNAPSHOT.jar`。该失败发生在 `MACTreeFloodSpec` 仿真启动前，导致 RTL 动态验证无法执行。

工程依赖 Scala 2.12.13、Chisel 3.5.3 和 chiseltest 0.5.3，属于 SBT 1.x 时代的构建组合。

## 目标

为 FLOOD 工程加入显式、可复现的 SBT 1.12.15 版本锁定，并在 JDK 17 下重新运行已新增的 `MACTreeFloodSpec` 动态回归。

## 非目标

- 不修改 RTL、测试逻辑、默认 Config 或 Diffusion 设计。
- 不卸载系统 SBT 2.0.6；SBT runner 根据工程锁定文件选择 1.12.15。
- 不修改全局 SBT 安装目录或用户级 JVM 配置。

## 方案比较

1. **推荐：提交 `accelerator/project/build.properties`，内容仅为 `sbt.version=1.12.15`。** 让每个开发者和 CI 使用同一兼容 SBT 1.x，变更最小且可审计。
2. 保持 SBT 2.0.6 并绕过 `packageBin`。需要临时 SBT 2 设置或复杂的 Windows 转义，构建不可复现，且未解决默认路径失败。
3. 卸载并全局降级 SBT。会影响其他项目，且仍无法在仓库中表达版本契约。

采用方案 1。

## 实施与验证

- 新增 `accelerator/project/build.properties`，UTF-8 文本且仅一行：`sbt.version=1.12.15`。
- 以 JDK 17、8 GB 临时 `JAVA_OPTS` 在前台运行 `testOnly MACTreeFloodSpec`。
- 成功标准：SBT 报告 1.12.15；新的 FIFO 满载回归通过；不出现 `packageBin` 的 JAR `AccessDeniedException`。
- 若首次启动需下载 SBT 1.12.15，允许下载官方构建组件；不得添加未审查依赖。
- 若仍失败，保留完整命令与输出，将问题归类为 Windows 文件锁而非 RTL 失败。

## 风险控制

`build.properties` 是项目本地锁定文件，不影响系统的 SBT 2.0.6。固定版本后先只运行单一 MACTreeFlood 回归；确认通过后再考虑扩展到 CIMCoreSpec 或全量测试。

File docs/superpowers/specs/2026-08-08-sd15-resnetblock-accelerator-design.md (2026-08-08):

# 基于 FLOOD 与 AXKU15 的 Stable Diffusion 1.5 ResNetBlock 加速器设计

## 文档状态

- 日期：2026-08-08
- 状态：正式规格已于 2026-08-08 确认；实施计划已建立，尚未开始 RTL 修改
- 目标：研究生毕业设计与 AXKU15 FPGA 原型
- 设计主线：以片上驻留、跨算子融合和双缓冲调度降低 Stable Diffusion U-Net ResNetBlock 的 DDR 访问

本文档是当前 Diffusion 加速器研究方向的正式设计规格。原 FLOOD CNN 文档继续作为基线架构和历史验证资料保留；二者发生差异时，FLOOD 现有实现以源码为准，Diffusion 扩展以本文档为准。

## 1. 研究问题与论证链

Stable Diffusion 1.5 在潜空间中迭代执行 U-Net。ResNetBlock 内连续出现 GroupNorm、SiLU、卷积、时间步嵌入和残差相加。若每个算子都把中间特征写回 DDR，再由下一个算子读回，数据搬运会削弱 MAC 阵列带来的收益。

本设计要回答的问题是：

> 在 AXKU15 的片上存储和 DSP 约束下，能否复用 FLOOD 的可重构 INT8 MAC 阵列，通过分块映射、跨算子片上驻留与 DMA/计算重叠，显著减少 SD 1.5 ResNetBlock 的 DDR 流量并提高阵列利用率？

论文证据链为：

```text
真实工作负载分析
  -> 分块与融合数据流
  -> 定点黄金模型和 RTL
  -> AXKU15 原型
  -> 正确性、流量、性能、资源与功耗实验
  -> 消融与局限性分析
```

## 2. 已确认范围

### 2.1 目标工作负载

- 模型：Stable Diffusion 1.5。
- 硬件对象：U-Net 中的 ResNetBlock。
- 第一阶段不硬化 Cross-Attention；进度允许时将其作为扩展。
- 主验证形状：
  - `64 x 64 x 320`
  - `32 x 32 x 640`
  - `16 x 16 x 1280`
  - `8 x 8 x 1280`
- GroupNorm 组数固定为 32，激活函数为 SiLU。
- 第一阶段优先支持 `Cin == Cout` 的 Block；通道变化时的 `1 x 1` 残差投影作为扩展，复用同一卷积引擎。

### 2.2 目标平台与协同方式

- FPGA：ALINX AXKU15，核心板器件为 `XCKU15P-FFVE1517-2-I`（手册写作 `XCKU15PFFVE1517`，速度等级 `-2`、工业级；建工程时以 Vivado 完整器件名为准）。
- 外部存储：5 片 Micron `MT40A512M16LY-062E`，每片 1 GB，合计 5 GB，组成 80-bit DDR4 数据总线；标称数据速率 2666 Mbps。
- 执行方式：主机与 FPGA 协同。
- 主机负责模型加载、真实张量捕获、量化、数据布局转换、任务下发和结果检查。
- FPGA 负责 ResNetBlock 的核心计算与片上调度。
- 扩展板提供 PCIe Gen3 x16 机械连接器，但 FPGA 侧只连接 8 路 GT，因此本项目按 **Gen3 x8 电气链路**设计与报告，禁止把 x16 插槽写成 x16 有效链路。
- PCIe/XDMA 不是计算核心的硬依赖。核心内部统一使用 AXI4-Lite、AXI4-MM 和中断接口；若 XDMA 环境不可用，可先使用仿真、JTAG 或板上控制路径验证。

板级资料核对结果及设计约束：

| 板级事实 | 设计约束 |
|---|---|
| DDR4 位于 FPGA HP Bank 66、67、68、69、70，数据总线为 80 bit | MIG 必须按手册引脚表和本地原理图重新生成；不得直接套用 64-bit DDR 或 ECC 板卡预设 |
| 核心板有两个 200 MHz 晶振，分别供 FPGA 逻辑和 DDR 控制参考时钟 | 时钟向导/MIG 以实际差分时钟引脚为准；150 MHz 是加速器核心目标频率，不等于板级输入时钟 |
| PCIe 参考时钟由连接器输入，存在 `PCIE_PERST_n`，仅连接 8 路 GT | XDMA 集成按 x8 配置，复位同步、参考时钟域跨越和链路降级状态必须进入板级测试 |
| JTAG 与 USB-UART 可用 | 在 PCIe 未就绪时，保留配置、状态读取和最小板上诊断路径 |

本地板级资料是器件、接口拓扑和引脚约束的权威来源：

- [AXKU15 V1.2 用户手册](../../../AXKU15_V1.2_UG.pdf)
- [AXKU15 扩展板原理图 V1.0](../../../01_原理图PCB结构图等硬件资料/AXKU15原理图V1.0.pdf)
- [ACKU15 核心板原理图 V1.0](../../../01_原理图PCB结构图等硬件资料/ACKU15核心板.pdf)

### 2.3 非目标

- 不在第一阶段实现 CLIP、VAE、采样器或完整 Stable Diffusion 端到端硬件。
- 不把 Cross-Attention、Softmax 和 QKV 作为最低交付要求。
- 不以提出新的量化算法为主要贡献。
- 不以 AXKU15 对高端 GPU 的绝对延迟比较作为主要结论。
- 不直接把现有 16 Tile FLOOD 配置视为已经满足 XCKU15P 资源约束。

## 3. 现有 FLOOD 基线与复用边界

### 3.1 可复用模块

- Chisel/Scala 生成 RTL 的工程框架。
- `CIMCore`、`Tile`、`Cluster` 和 `MacMachine` 的层次结构。
- INT8 乘累加数据通路。
- SRAM Ping/Pong 选择与 Wrapper 级运行/中断框架。
- E203、APB/AXI、DMA、Vivado 和软件测试资产。
- 输出截位、饱和与部分后处理经验。

关键入口：

- [Config.scala](../../../accelerator/src/main/scala/core/Config.scala)
- [CIMcore.scala](../../../accelerator/src/main/scala/core/CIMcore.scala)
- [Cluster.scala](../../../accelerator/src/main/scala/cluster/Cluster.scala)
- [MacMachine.scala](../../../accelerator/src/main/scala/Machine/MacMachine.scala)
- [MacMachineWrapper.scala](../../../accelerator/src/main/scala/Machine/MacMachineWrapper.scala)

### 3.2 必须修改或新增的部分

- 将 FLOOD 计算阵列封装为规则的卷积 Tile 接口。
- 参数化 Tile 数量和每拍乘法并行度，使设计能够在 XCKU15P 上收敛。
- 新增面向 `Tci = 32`、`Tco = 32` 的二维空间分块控制器。
- 新增 GroupNorm、SiLU、时间步嵌入和残差融合单元。
- 新增面向完整 ResNetBlock 的片上 Residual/Mid/Accumulator Buffer。
- 新增 AXI 任务接口、Tensor DMA、性能计数器和错误状态。
- 替换依赖旧 CNN 数据布局或旧配置寄存器语义的控制逻辑。

### 3.3 当前基线风险

- README 中部分参数落后于当前源码；现有源码为 `rowSize = 32`、`colSize = 32`、`pipeline = 2`、`tLatency = 4`、`compressionFactor = 4`、`tileSize = 16`。
- 现有 `MacMachine_top.v` 将内部较宽权重地址连接到 11 位 BRAM 地址，需要在 Diffusion 原型中重新定义容量与地址映射。
- 原 16 Tile 配置的乘法器规模可能超过 XCKU15P 可用 DSP，不能跳过首次综合与缩减步骤。
- 原文档存在逻辑配置 ID 与物理 APB 地址混用；新接口必须把两者分开。

## 4. 系统架构

```text
Host / PyTorch
  |-- SD 1.5 张量捕获与定点黄金模型
  |-- 量化、Blocked Layout、任务描述符
  |-- 结果回读与指标统计
  |
  +--> 可替换 Host Bridge（XDMA / JTAG / E203）
          |-- AXI4-Lite 控制
          |-- AXI4-MM DDR 访问
          |-- Done / Error 中断
                  |
                  v
        ResNetBlock Accelerator
          |-- Command & Block Scheduler
          |-- Tensor DMA + Ping/Pong Buffer
          |-- GroupNorm Statistics / Normalize
          |-- SiLU Approximation
          |-- FLOOD Compute Adapter
          |-- Time Embedding Add
          |-- Residual Add
          |-- Residual / Mid / Accumulator Buffer
          |-- Performance & Error Monitor
```

### 4.1 主机端

主机程序提供以下功能：

1. 从 SD 1.5 U-Net 捕获 Block 输入、权重、时间步投影向量和 FP16 参考输出。
2. 生成与硬件一致的 W8A8/INT16 定点参考结果。
3. 将 NCHW 张量转换为 32 通道成组的 Blocked Layout。
4. 分配 DDR 地址并生成任务描述符。
5. 下发、等待中断、回读结果并生成误差报告。

### 4.2 FPGA 控制与搬运层

`BlockScheduler` 根据任务描述符展开两个卷积、两次 GroupNorm、两次 SiLU、时间步加法和残差加法。`TensorDMA` 负责 DDR 突发访问并维护 Ping/Pong 状态。DDR 控制器必须从 AXKU15 的 80-bit 拓扑、200 MHz 参考时钟和手册引脚表生成；加速器只依赖 MIG 暴露的 AXI 用户接口，不绑定某个 PCIe IP。控制层不得依赖 PCIe 专用信号。

### 4.3 计算层

`FLOOD Compute Adapter` 将通道块和空间块转换为现有 Tile/CIMCore 可接受的数据形式。第一版采用 8 Tile 保守配置；只有当综合后 DSP、布线、时序和片上存储均满足目标时，才扩大到 16 Tile 或启用 INT8 DSP 打包。

## 5. 分块与数据布局

### 5.1 基本粒度

- 输入通道块：`Tci = 32`。
- 输出通道块：`Tco = 32`。
- 空间块：`Th x Tw`，由设计空间探索选择。
- 3x3 卷积输入块包含一圈 Halo。
- 权重按 `CoutBlock -> CinBlock -> Ky -> Kx -> lane` 排列。
- 激活按 32 通道成组排列，主机端负责重排。

### 5.2 空间块选择规则

候选 `Th x Tw` 通过综合前模型和板上实验共同选择。选取规则依次为：

1. Residual、Mid、Accumulator、权重和双缓冲总量不超过可分配片上存储。
2. DDR 突发长度足够大，Halo 重复流量可接受。
3. FLOOD 阵列有效周期占比最高。
4. 路由与时序能够收敛。

设计文档不预先固定唯一空间块，避免在首次综合前把未经验证的尺寸写成硬约束。

## 6. 融合执行流程

### 阶段 A：GN1 统计与输入驻留

从 DDR 读取 Block 输入，计算 32 组 `sum` 和 `sum-square`，同时保存到片上 Residual Buffer。该 Buffer 后续同时作为 GN1 输入和残差旁路。

### 阶段 B：GN1—SiLU—Conv1—Time Embedding

Residual Buffer 中的数据经过 GN1 和 SiLU 后直接送入卷积阵列。归一化和激活结果不写 DDR。Conv1 使用 INT32 累加，重定标为 INT16 后与主机预投影的时间步向量按通道相加，结果写入 Mid Buffer。

### 阶段 C：GN2 统计

直接扫描片上 Mid Buffer 计算 GN2 统计量，不访问 DDR。

### 阶段 D：GN2—SiLU—Conv2—Residual Add

Mid Buffer 经 GN2 和 SiLU 后进入 Conv2。Conv2 输出与 Residual Buffer 相加，完成饱和和重定标后写回 DDR。

目标是 Block 级中间特征不离开 FPGA 片上存储。外部流量主要由输入、两个卷积的权重、时间步向量和最终输出组成。

## 7. 数值方案

| 对象 | 格式 |
|---|---|
| 卷积权重 | INT8，对称、按输出通道缩放 |
| 卷积输入 | INT8 |
| 乘法 | INT8 x INT8 |
| 卷积累加 | INT32 |
| Mid Buffer | INT16 |
| GroupNorm 输入/输出 | INT16 |
| GroupNorm 求和 | 不低于 32 bit |
| GroupNorm 平方和 | 不低于 48 bit |
| 时间步投影向量 | INT16 |
| 最终输出 | INT16，或按任务配置重定标为 INT8 |

### 7.1 GroupNorm

GroupNorm 固定支持 32 组：

```text
mean = sum(x) / M
variance = sum(x^2) / M - mean^2
y = gamma * (x - mean) / sqrt(variance + epsilon) + beta
```

倒数平方根使用 LUT 初值，可选择一次 Newton 迭代。具体实现必须与定点黄金模型使用相同的舍入、截断和饱和规则。

### 7.2 SiLU

SiLU 采用 16 段或 32 段分段线性近似。段数通过误差和资源消融实验选择；选择标准是满足 Block 级数值要求时使用资源更少的实现。

### 7.3 时间步嵌入

正弦编码和时间步 MLP 保留在主机端。FPGA 接收已投影到当前通道数的 INT16 向量，在 Conv1 后广播相加。

## 8. 控制接口

### 8.1 AXI4-Lite 寄存器组

至少包含：

- 控制：`start`、`abort`、`interrupt_clear`。
- 状态：`busy`、`done`、`error`、错误码。
- 形状：`H`、`W`、`Cin`、`Cout`、Group 数。
- 分块：`Th`、`Tw`、`Tci`、`Tco`。
- 地址：输入、两组权重、GN 参数、时间步向量、输出。
- 量化：输入、权重、中间和输出缩放参数。
- 性能：总周期、计算周期、DMA 等待周期、读写字节数、饱和计数。

### 8.2 任务约束

- `Cin` 和 `Cout` 必须按 32 通道对齐；不对齐时由主机填零。
- 首版卷积核固定为 3x3、步长 1、保持空间尺寸。
- 输入和权重地址必须满足 AXI 突发对齐要求。
- Group 数首版固定为 32。
- 不支持的形状不得静默执行，必须返回明确错误码。

## 9. 错误处理与可观测性

硬件至少检测：

- 非法形状或未对齐地址。
- DMA 超时或响应错误。
- 命令在 Busy 状态下重复启动。
- 定点饱和次数和最大/最小值越界。
- 内部 FIFO 或任务状态异常。

所有错误均锁存到状态寄存器并触发 Error 中断。性能计数器用于区分计算受限和带宽受限状态，不能只报告总延迟。

## 10. 验证计划

### 10.1 黄金模型

建立与 RTL 完全一致的定点模型，覆盖量化、舍入、饱和、GroupNorm、SiLU、时间步和残差。RTL 与该模型必须逐元素一致。

### 10.2 单元验证

- DMA 与 Ping/Pong 控制。
- FLOOD 卷积适配器。
- GroupNorm 统计与归一化。
- SiLU 近似。
- 时间步与残差加法。
- 状态、中断、错误与性能计数器。

### 10.3 Block 验证

使用真实 SD 1.5 张量覆盖四个通道层级、多个扩散时间步和不同输入分布。对 FP16、定点软件、RTL 和板上输出进行逐级比较。

### 10.4 FPGA 验证

- 板上输出与 RTL 一致。
- 连续任务和 Ping/Pong 运行不死锁。
- DDR 压力下结果稳定。
- 中断、超时、错误清除和重复运行正确。
- 板上计数器与外部计时相互校验。

## 11. 实验设计

### 11.1 基线

1. FP16 PyTorch：精度参考。
2. W8A8/INT16 软件模型：量化参考。
3. 非融合 FPGA：每个算子结果均回写 DDR。
4. 融合 FPGA：本文方案。

### 11.2 指标

- 数值：MAE、MSE、最大绝对误差、余弦相似度、饱和比例。
- 流量：输入、权重、中间特征和输出的 DDR 字节数。
- 性能：Block 延迟、吞吐率、MAC 利用率、DMA 等待比例。
- 实现：LUT、FF、BRAM、UltraRAM、DSP、Fmax。
- 能效：板级功耗、GOP/s/W。

### 11.3 消融

- 单缓冲与双缓冲。
- 中间结果回 DDR 与片上驻留。
- 不同 `Th x Tw`。
- 8 Tile 与资源允许时的 16 Tile。
- SiLU 16 段与 32 段。
- 敏感算子的不同定点位宽。
- 四个 U-Net 空间/通道层级和多个时间步。

## 12. 工程目标与完成判据

以下是工程目标，不是预先宣称的实验结果：

- RTL 与定点黄金模型逐元素一致。
- 相对非融合基线，中间激活 DDR 流量降低不少于 50%。
- LUT、FF、BRAM、UltraRAM 和 DSP 的单项占用原则上不超过 80%。
- 第一版目标频率不低于 150 MHz；若未达到，论文必须给出关键路径与修正结果。
- 融合版本相对非融合版本取得可测量的延迟或能效改善。
- 至少一个真实 SD 1.5 ResNetBlock 在 AXKU15 上完成稳定重复运行。

最低可交付成果为：定点黄金模型、融合 Block RTL、真实张量仿真、AXKU15 综合结果、板上核心路径验证、流量/性能/资源消融。完整 XDMA 主机链路和 Cross-Attention 属于增强成果。

## 13. 里程碑

1. 第 1 月：环境审计、真实张量捕获、定点黄金模型。
2. 第 2 月：FLOOD 参数化、单层 3x3 卷积、首次 XCKU15P 综合。
3. 第 3 月：GroupNorm、SiLU、Residual/Mid Buffer 和 DMA。
4. 第 4 月：融合 ResNetBlock RTL、非融合流量基线、Block 级仿真。
5. 第 5 月：AXKU15 DDR 与板级运行；若环境成熟则接入 XDMA。
6. 第 6 月：时序/资源优化、消融实验、论文主体。
7. 余量阶段：Cross-Attention 或更完整的软件调度。

## 14. 风险与降级路径

| 风险 | 影响 | 降级或应对 |
|---|---|---|
| 现有 16 Tile 资源过大 | 无法布局布线 | 首版 8 Tile；提高时分复用；综合后再扩展 |
| Mid/Residual Buffer 占用过高 | 无法完整片上驻留 | 改为条带驻留；保持算子融合并量化额外流量 |
| GroupNorm 定点误差过大 | Block 输出偏差 | 增加统计位宽、Newton 迭代或局部更高精度 |
| SiLU 近似误差过大 | 生成质量下降 | 增加分段或使用 LUT 插值 |
| PCIe/XDMA 不可用 | 无法直接由主机高速下发 | 保持 AXI 核心；使用 JTAG/E203/预装 DDR 做板级验证 |
| DDR 或时序不收敛 | 性能不达目标 | 缩小 Tile 数和突发并行度，保留完整实验解释 |
| 完整 SD 集成工作量过大 | 论文延期 | 固守真实 ResNetBlock 原型，不扩展 CLIP/VAE/Attention |

## 15. 参考与相关文档

- Rombach et al., *High-Resolution Image Synthesis with Latent Diffusion Models*, CVPR 2022: <https://openaccess.thecvf.com/content/CVPR2022/html/Rombach_High-Resolution_Image_Synthesis_With_Latent_Diffusion_Models_CVPR_2022_paper.html>
- Stable Diffusion 1.5 U-Net 配置：<https://huggingface.co/stable-diffusion-v1-5/stable-diffusion-v1-5/blob/refs%2Fpr%2F22/unet/config.json>
- SDA, *Low-Bit Stable Diffusion Acceleration on Edge FPGAs*, FPL 2024: <https://zhenman.github.io/files/C41-FPL2024-SDA.pdf>
- [本地 AXKU15 V1.2 用户手册](../../../AXKU15_V1.2_UG.pdf)
- [本地 AXKU15 扩展板原理图 V1.0](../../../01_原理图PCB结构图等硬件资料/AXKU15原理图V1.0.pdf)
- [本地 ACKU15 核心板原理图 V1.0](../../../01_原理图PCB结构图等硬件资料/ACKU15核心板.pdf)
- [工作区 README](../../../README.md)
- [实施计划](../plans/2026-08-08-sd15-resnetblock-accelerator-implementation.md)
- [FLOOD 加速器 README](../../../accelerator/README.md)
- [FLOOD MacMachine 使用说明](../../../accelerator/MacMachine使用说明文档.md)
- [旧 CNN Demo 部署计划](../../../accelerator/CNN_Accelerator_Deployment_Plan.md)

## 16. 审阅检查点

书面规格已确认，实施计划已经生成。本检查点不授权直接修改 RTL；开始执行前应先选择执行模式并处理当前目录缺少 Git 元数据的问题。实施顺序固定为环境与资源基线、黄金模型、卷积适配器、融合算子、系统集成和板级实验。

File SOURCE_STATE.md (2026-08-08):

# Source State at Extraction

本文件记录 `graduate` 于 2026-08-07 从现有工作树提取时的来源状态。它用于保留溯源信息，不表示这些改动已经审核或形成正式 release。

## 1. 加速器主工程

- 来源：`e203_asic_c/e203_asic_c/flood_accelerator`
- Git 分支：`asic_flood`
- HEAD：`482970e`（2026-05-28，`Add c/demo/common directory`）
- 与远端关系：`asic_flood...origin/asic_flood [ahead 1]`
- 原 `.git` 目录：约 1.363 GiB，未复制

提取时已修改、且已复制其工作树内容：

- `c/axi_test/Makefile`
- `c/axi_test/mac_test_tb2.c`
- `src/main/scala/Machine/MacMachineWrapper.scala`
- `src/main/scala/core/CIMcore.scala`

提取时未跟踪、且已复制的主要工程文件：

- `CNN_Accelerator_Deployment_Plan.md`
- `FMC_Address_Decode_Table.md`
- `c/axi_test/cnn_demo.c`
- `c/axi_test/cnn_multilayer.c`
- `c/axi_test/cnn_multilayer.h`
- `c/axi_test/cnn_perf.c`
- `c/axi_test/cnn_perf.h`
- `c/demo/lenet/lenet_config.h`
- `chip_test_0601.v`、`chip_test_0602.v`、`chip_test_0603.v`
- `system_chip_test.v`
- `fpga/AXKU15` 下新增的约束和芯片测试 RTL
- `tests/common/test_framework.h`、`tests/unit/test_conv.c`
- `tools/data_gen/image_preprocess.py`、`tools/quantization/quantize_weights.py`
- `团队协作指南.md`

未复制的未跟踪内容包括完整内嵌 SDK、`fpga.zip`、`src/main/scala.zip`、HPCA 调研模板和部分旧任务草稿。当前候选执行计划与任务拆分已单独复制到 `planning`。

## 2. hbird-sdk 覆盖层

- 来源：`e203_asic_c/e203_asic_c/flood_accelerator/hybird_sdk/hbird-sdk`
- 远端：`https://gitee.com/riscv-mcu/hbird-sdk.git`
- 分支：`master`
- HEAD：`321ecb29f64197748a4a4bdb9f42c0961cb8145b`
- 与远端关系：`master...origin/master [ahead 2]`

覆盖层包含以下本地状态：

- 已修改：`application/custom/axi_test/Makefile`
- 已修改：`application/custom/axi_test/link.ld`
- 已修改：`application/custom/axi_test/main.c`
- 已修改：`setup.bat`
- 未跟踪：`application/custom/axi_test/tte.py`（提取时为空文件）
- 未跟踪：`软件编译工具及流程解读.md`
- 一并保留：`application/custom/axi_test/README.md` 与 `startup.S`

SDK 构建生成物 `axi_test.bin/.elf/.hex/.map/.verilog` 和 `.o` 未复制。

## 3. Vivado 芯片测试工程

- 来源：`chip_test/chip_test`
- 入口：`system_chip_test.xpr`
- 保留：`system_chip_test.srcs` 中的 XDC、XCI、RTL、C、MEM 和初始化数据
- 排除：`.Xil`、cache、runs、gen、hw、sim、ip_user_files、`.exe`、`.dcp` 和 `result_*.txt`

原工程已有多个 bitstream/ILA 输出，但未复制到本维护副本。需要可追溯产物时，应从 `graduate` 的明确提交重新生成并放入独立 artifacts 目录。

## 4. 数据与文档来源

- 板级接口：根目录 `引脚列表.xlsx`，以及 `流片` 下的连接器、转接板和 PCB 约束表。
- 验证计划：`论文/测试方案` 下 4 份 Markdown。
- 测试网络表：`测试` 下 3 份 CSV。
- 规划文档：主工程中的 `Project_Execution_Plan_v3.md`、`Week1_Code_Tasks_v2.md`、`Week1_Detailed_Tasks.md`。
- `转接板引脚.csv` 和 3 份 `Fan_Out_Netlabel` CSV 使用 UTF-16LE（带 BOM）；这是来源文件的 Excel 兼容编码，复制时保持不变。其余抽查的文本文件为有效 UTF-8。

## 5. 重要限制

1. FLOOD 根目录本身不是 Git 仓库。
2. 本副本包含来源工作树的未提交内容，但不包含其 Git 索引和历史。
3. 两份 hbird-sdk 在来源目录中表现为高度一致的工作副本；本次只从主加速器内嵌副本提取 overlay。
4. 本文件记录的是提取时事实，不替代代码审查、功能回归或 release 审核。

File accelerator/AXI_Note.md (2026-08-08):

# AXI4协议详解笔记

## 📋 概述

本文档记录了AXI4协议的核心概念，以及E203处理器与bus_top模块的信号匹配情况。

---

## 🆔 AXI ID机制详解

### ID的核心功能
```
┌─────────────┐    ID=0x1    ┌─────────────┐
│   Master A  ├─────────────→│   Memory    │
└─────────────┘              └─────────────┘
┌─────────────┐    ID=0x2    ┌─────────────┐
│   Master B  ├─────────────→│   Cache     │
└─────────────┘              └─────────────┘
```

### ID的主要用途
1. **事务标识：** 区分不同的数据传输事务
2. **乱序完成：** 允许后发起的事务先完成
3. **多主设备：** 支持多个master同时访问同一个slave
4. **性能优化：** 提高总线利用率和并发度

### E203的ID处理
- **不支持原因：** E203是简单的单发射处理器，不需要复杂的乱序执行
- **处理方式：**
  - 输入ID（`awid_m1`、`arid_m1`）→ 固定为 `4'b0000`
  - 输出ID（`bid_m1`、`rid_m1`）→ 端口悬空 `()`

---

## 🔄 AXI的5个独立通道

### 通道架构图
```
Master                           Slave
┌─────────────┐                 ┌─────────────┐
│             │──1. AW (写地址)──→│             │
│             │←─   awready   ─────             │
│             │──   awvalid   ──→│             │
│             │                 │             │
│             │──2. W (写数据)───→│             │
│   E203      │←─   wready    ─────   Memory   │
│   CPU       │──   wvalid    ──→│   Slave     │
│             │                 │             │
│             │←─3. B (写响应)─────             │
│             │──   bready    ──→│             │
│             │←─   bvalid    ─────             │
│             │                 │             │
│             │──4. AR (读地址)──→│             │
│             │←─   arready   ─────             │
│             │──   arvalid   ──→│             │
│             │                 │             │
│             │←─5. R (读数据)─────             │
│             │──   rready    ──→│             │
│             │←─   rvalid    ─────             │
└─────────────┘                 └─────────────┘
```

### 5个通道详细说明

| **通道** | **方向** | **握手信号** | **作用** |
|---|---|---|---|
| **AW (写地址)** | Master→Slave | `awvalid/awready` | 传输写操作的地址和控制信息 |
| **W (写数据)** | Master→Slave | `wvalid/wready` | 传输实际的写数据 |
| **B (写响应)** | Slave→Master | `bvalid/bready` | Slave响应写操作完成状态 |
| **AR (读地址)** | Master→Slave | `arvalid/arready` | 传输读操作的地址和控制信息 |
| **R (读数据)** | Slave→Master | `rvalid/rready` | 传输读取的数据和响应状态 |

### 多通道设计优势
1. **并行操作：** 写地址和写数据可以同时传输
2. **流水线：** 可以同时处理多个读写事务
3. **灵活性：** 每个通道独立控制，提高效率

---

## 📏 长度信号 (awlen/arlen)

### 突发传输概念
```
单次传输：  [地址] → [数据]
突发传输：  [地址] → [数据1][数据2][数据3][数据4]
                    ↑─────── len=3 (传输4个数据) ──────↑
```

### 长度信号规则
- `awlen/arlen = n` 表示传输 `n+1` 个数据
- 例如：`len=0` → 传输1个数据，`len=3` → 传输4个数据
- AXI4最大支持256个数据的突发传输

### 突发传输优势
1. **提高效率：** 一次地址传输，多个数据传输
2. **减少开销：** 减少地址传输的次数
3. **提高带宽：** 连续数据传输更高效

### E203的长度转换
```verilog
// E203输出：4位（支持最多16个数据突发）
wire [3:0] expl_axi_awlen;  // 0~15

// bus_top需要：8位（标准AXI4）
.awlen_m1({4'b0000, expl_axi_awlen})  // 扩展为8位
```

---

## 🔒 锁定信号 (awlock/arlock)

### 原子操作保护示例
```
正常访问：  CPU1 → [读]     → [写]
           CPU2 → [读] → [写]
           ❌ 可能发生竞争条件

原子访问：  CPU1 → [锁定] → [读+写] → [解锁]
           CPU2 → [等待]           → [访问]
           ✅ 保证原子性
```

### 锁定信号含义
- `lock=0`：正常访问
- `lock=1`：独占访问（原子操作）

### 应用场景
1. **信号量操作**
2. **计数器递增**
3. **链表节点插入**
4. **多核同步**

### E203的锁定转换
```verilog
// E203输出：2位AXI3格式
wire [1:0] expl_axi_awlock;  // [1:0] = {Locked, Normal}

// bus_top需要：1位AXI4格式  
.awlock_m1(expl_axi_awlock[0])  // 只取最低位
```

---

## 📊 E203与bus_top信号匹配表
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

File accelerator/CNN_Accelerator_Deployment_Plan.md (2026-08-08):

# FLOOD CNN加速器 Demo部署与验证计划

> **状态说明（2026-08-08）**：本计划作为 FLOOD 通用 CNN Demo 的历史基线保留，不再作为当前毕设主计划。当前主线为 Stable Diffusion 1.5 U-Net ResNetBlock 的 AXKU15 FPGA 原型，设计范围和工程判据见[正式设计规格](../docs/superpowers/specs/2026-08-08-sd15-resnetblock-accelerator-design.md)。本文中的 AKU15/Hybrid-SDK、人员分组和 Demo 周期不自动迁移到新项目。

## 项目背景

- **当前状态**: mac_test_tb2已完成单层卷积验证
- **目标**: 验证加速器作为通用CNN加速器的能力，部署多个Demo
- **硬件状态**: 芯片已流片回来，可使用AKU15 FPGA + Vivado + Hybrid-SDK进行验证
- **团队规模**: 6名本科生

---

## 一、整体架构与任务分组
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

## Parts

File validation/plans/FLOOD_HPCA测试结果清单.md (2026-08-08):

# FLOOD HPCA 重投 — 测试结果清单

> **用途**：按实验组逐项填写数据，支撑 HPCA 重投实验章节。  
> **论文定位**：FLOOD 作为 **Diffusion 加速器**（面向 LDM/DiT 推理），而非通用 DNN 加速器。  
> **工具链**：开源 PyTorchSim（端到端仿真）+ 固定 FLOOD 硬件参数。  
> **填写说明**：每项结果需注明数据来源（PyTorchSim / FPGA 实测 / RTL 仿真 / ASIC 综合 / P&R 估算）。

---

## 一、统一记录字段（每组实验必填）

| 字段 | 填写内容 |
|---|---|
| 实验组编号 | E1–E9 |
| 模型 | 如 SD v1.5 UNet、DiT-B/4 |
| 输入规模 | batch size、resolution、sequence length |
| 精度配置 | FP16 / INT8 / INT4 / mixed |
| FLOOD 硬件参数 | 频率、Tile/PE 数、buffer、SRAM/DRAM 带宽 |
| Baseline 名称 | 对比对象及配置摘要 |
| 数据来源 | PyTorchSim / FPGA / RTL / ASIC synthesis / P&R estimate |
| 备注 | 异常值、未完成项、待确认项 |

---

## 二、实验结果总表

| 编号 | 实验组 | 论文目的 | 建议模型 | 主要对比 | 需填写指标 | 优先级 | 对应审稿关切 |
|:---:|:---|:---|:---|:---|:---|:---:|:---|
| **E1** | 端到端主结果 | 证明 Full FLOOD 在 diffusion 推理上的系统级收益 | SD v1.5 UNet；VAE；DiT-B/4；DiT-S/4；完整 LDM pipeline | Base FLOOD；DiT-Accel-like；通用 diffusion baseline；Full FLOOD | latency；throughput；energy/power；compute utilization；DRAM/SRAM traffic；speedup | **P0** | 实验可信度、baseline 公平性 |
| **E2** | 细粒度稀疏 | 证明跳零与 GCSE 在 diffusion workload 上有效 | SD UNet；DiT-B/4；VAE | no skipping；zero skipping；+ adder pruning；+ GCSE | activation/weight sparsity；skipped MAC ratio；cycle reduction；energy reduction；utilization | **P0** | 跳零延迟收益、稀疏非已有技术堆砌 |
| **E3** | 混合量化 | 量化性能与生成质量 trade-off | SD UNet；LDM CelebA-HQ/FFHQ；DiT-B/4 | FP16；INT8 all；INT4 all；10%/30%/50% INT4 mixed；sensitivity-based mixed | throughput；peak memory；latency；FID；PSNR；SSIM；LPIPS；CLIP Score；quality drop | **P0** | 精度退化、量化收益 |
| **E4** | Outlier bypass | 证明低成本保精度，而非扩大主 MAC | SD UNet；LDM CelebA-HQ；DiT-B/4 | INT8 truncation；+ outlier bypass；mixed w/o outlier；wide-MAC baseline | outlier ratio；PSNR/SSIM/LPIPS；extra area/power/cycles | **P1** | 量化-精度权衡、硬件开销 |
| **E5** | Softmax 支持 | 证明 DiT attention 关键算子支持可信 | DiT-B/4；DiT-S/4；SD UNet attention 层 | standard Softmax；linear attention；I-BERT-like；FLOOD INT8 Softmax | vector length 32–2048；latency；approximation error；generation quality drop；area/power | **P0** | DiT 推理完整性、非单点优化 |
| **E6** | Dataflow 与存储 | 证明 FLOOD/PLANE 对 mixed Conv/Matrix diffusion 的必要性 | SD UNet；DiT-B/4；完整 LDM pipeline | FLOOD only；PLANE only；adaptive FLOOD+PLANE；固定 GEMM mapping | buffer usage；bandwidth demand；stall cycles；NoC traffic；ping-pong margin；utilization | **P0** | co-design、调度准则 |
| **E7** | 系统级消融 | 回应创新点是否只是拼装 | SD UNet；DiT-B/4；完整 LDM pipeline（可选） | Base；+ sparse；+ quant；+ outlier；+ Softmax；+ dataflow；Full FLOOD | latency；energy；utilization；memory traffic；quality/accuracy drop | **P0** | 组合必要性、收益分解 |
| **E8** | Diffusion 族内扩展 | 证明 FLOOD 覆盖 LDM 与 DiT 两类 diffusion 架构 | SD v1.5（LDM）；DiT-B/4；DiT-S/4；DiT-XL/2（可选） | Base FLOOD；Full FLOOD；DiT-Accel-like | throughput；latency；energy；PSNR/SSIM；generation quality | **P1** | 非单模型特例、diffusion 族适用性 |
| **E9** | Baseline 公平性 | 回应配置不明与比较不公平 | 覆盖 E1–E7 所有 diffusion 主实验 | Base FLOOD；DiT-Accel-like；通用 diffusion baseline；software reference（xDiT/PipeFusion 等，可选） | 工艺；频率；面积；精度；buffer；bandwidth；稀疏/dataflow/Softmax 支持；diffusion mapping 方法 | **P0** | baseline 配置透明 |

**优先级说明**：P0 = HPCA 必补；P1 = 强烈建议补；P2 = 时间允许再补。

---

## 三、分项填写模板

### E1 端到端主结果

| 模型 | 配置 | Latency | Throughput | Energy/Power | Utilization | DRAM Traffic | SRAM Traffic | Speedup vs Base | 数据来源 |
|:---|:---|:---:|:---:|:---:|:---:|:---:|:---:|:---:|:---|
| SD UNet | Base FLOOD | | | | | | | 1.00× | |
| SD UNet | Full FLOOD | | | | | | | | |
| SD UNet | DiT-Accel-like | | | | | | | | |
| SD UNet | 通用 diffusion baseline | | | | | | | | |
| VAE | Full FLOOD | | | | | | | | |
| DiT-B/4 | Full FLOOD | | | | | | | | |

**目标结论（待填）**：
- Full FLOOD 相对 Base：latency ↓ ___%，energy ↓ ___%，utilization ↑ ___%
- 相对 DiT-Accel-like / 通用 diffusion baseline 的优势：___

---

### E2 细粒度稀疏

| 模型 | 配置 | Act. Sparsity | Wt. Sparsity | Skipped MAC % | Cycle ↓ | Energy ↓ | Utilization ↑ | 数据来源 |
|:---|:---|:---:|:---:|:---:|:---:|:---:|:---:|:---|
| SD UNet | no skipping | | | | — | — | | |
| SD UNet | zero skipping | | | | | | | |
| SD UNet | + adder pruning | | | | | | | |
| SD UNet | + GCSE | | | | | | | |
| DiT-B/4 | + GCSE | | | | | | | |

**补充**：synthetic sparsity sweep（11×11 网格）热力图数据 — [ ] 已完成

---

### E3 混合量化

| 模型 | 精度配置 | Throughput | Peak Memory | Latency | FID | PSNR | SSIM | LPIPS | CLIP Score | 数据来源 |
|:---|:---|:---:|:---:|:---:|:---:|:---:|:---:|:---:|:---:|:---|
| SD UNet | FP16 | | | | | | | | | |
| SD UNet | INT8 all | | | | | | | | | |
| SD UNet | INT4 all | | | | | | | | | |
| SD UNet | 30% INT4 mixed | | | | | | | | | |
| SD UNet | sensitivity-based | | | | | | | | | |

**目标结论（待填）**：最优 mixed ratio = ___%，quality drop < ___%

---

### E4 Outlier bypass

| 模型 | 配置 | Outlier Ratio | PSNR | SSIM | LPIPS | Extra Area | Extra Power | Extra Cycles | 数据来源 |
|:---|:---|:---:|:---:|:---:|:---:|:---:|:---:|:---:|:---|
| SD UNet | INT8 truncation | | | | | — | — | — | |
| SD UNet | + outlier bypass | | | | | | | | |
| SD UNet | wide-MAC baseline | | | | | | | | |

---

### E5 Softmax 支持

| 模型 | Vector Length | 实现方式 | Latency | Approx. Error | Accuracy Drop | Area | Power | 数据来源 |
|:---|:---:|:---|:---:|:---:|:---:|:---:|:---:|:---|
| DiT-B/4 | 512 | standard Softmax | | | | | | |
| DiT-B/4 | 512 | FLOOD INT8 Softmax | | | | | | |
| DiT-S/4 | 256 | FLOOD INT8 Softmax | | | | | | |
| SD UNet | attention 层 | FLOOD INT8 Softmax | | | | | | |

---

### E6 Dataflow 与存储

| 模型 | Dataflow | Bandwidth | Buffer Size | Latency | Buffer Usage | Stall Cycles | Utilization | 数据来源 |
|:---|:---|:---:|:---:|:---:|:---:|:---:|:---:|:---|
| SD UNet | FLOOD only | 32B | — | | | | | |
| SD UNet | PLANE only | 32B | — | | | | | |
| SD UNet | adaptive | 32B | — | | | | | |
| SD UNet | adaptive | 8B/16B/32B/64B sweep | — | | | | | |

**目标结论（待填）**：adaptive 相对错误 dataflow 的 latency 代价 = ___%

---

### E7 系统级消融

| 配置 | Latency | Energy | Utilization | Memory Traffic | Quality Drop | 数据来源 |
|:---|:---:|:---:|:---:|:---:|:---:|:---|
| Base | | | | | — | |
| + zero skipping | | | | | | |
| + adder pruning | | | | | | |
| + GCSE | | | | | | |
| + INT8/INT4 mixed | | | | | | |
| + outlier bypass | | | | | | |
| + Softmax | | | | | | |
| + FLOOD/PLANE dataflow | | | | | | |
| **Full FLOOD** | | | | | | |

---

### E8 Diffusion 族内扩展

| 模型 | 架构类型 | 配置 | Throughput | Latency | Energy | PSNR/SSIM | Generation Quality | 数据来源 |
|:---|:---|:---|:---:|:---:|:---:|:---:|:---:|:---|
| SD v1.5 UNet | LDM | Full FLOOD | | | | | | |
| SD VAE | LDM | Full FLOOD | | | | | | |
| DiT-B/4 | DiT | Full FLOOD | | | | | | |
| DiT-S/4 | DiT | Full FLOOD | | | | | | |
| DiT-XL/2 | DiT | Full FLOOD（可选） | | | | | | |

---

### E9 Baseline 公平性配置表

| Baseline | 工艺 | 频率 | 面积 | 精度 | Buffer | Bandwidth | 稀疏支持 | Dataflow | Softmax | Outlier | Mapping | 数据来源 |
|:---|:---:|:---:|:---:|:---|:---:|:---:|:---:|:---:|:---:|:---:|:---|:---|
| Base FLOOD | | | | | | | | | | | | |
| DiT-Accel-like | | | | | | | | | | | | |
| 通用 diffusion baseline | | | | | | | | | | | | |
| Full FLOOD | | | | | | | | | | | | |

---

## 四、与论文图表的对应关系（建议）

| 论文图号 | 对应实验组 | 主要内容 |
|:---:|:---:|:---|
| Fig. 10 | E9 + 方法说明 | 实验平台、PyTorchSim 流程、数据来源标注 |
| Fig. 11 | E2 | 稀疏机制：热力图 + 真实层级统计 + 消融 |
| Fig. 12 | E3 | 混合量化 trade-off |
| Fig. 13 | E4 | Outlier bypass 质量恢复与硬件开销 |
| Fig. 14 | E5 + E6 | Softmax + dataflow/buffer/bandwidth |
| Fig. 15 | E1 | 端到端主结果（大图） |
| Fig. 16 | E7 | 系统级消融 |
| Fig. 17 | E8 | Diffusion 族内扩展（LDM vs DiT 多模型对比） |

---

## 五、进度跟踪

| 实验组 | 负责人 | 状态 | 预计完成 | 备注 |
|:---:|:---|:---:|:---:|:---|
| E1 | | ⬜ 未开始 | | |
| E2 | | ⬜ 未开始 | | |
| E3 | | ⬜ 未开始 | | |
| E4 | | ⬜ 未开始 | | |
| E5 | | ⬜ 未开始 | | |
| E6 | | ⬜ 未开始 | | |
| E7 | | ⬜ 未开始 | | |
| E8 | | ⬜ 未开始 | | |
| E9 | | ⬜ 未开始 | | |

状态：⬜ 未开始 / 🔄 进行中 / ✅ 已完成

---

*文档版本：v1.1 | 定位：Diffusion Accelerator | 生成日期：2026-06-23*

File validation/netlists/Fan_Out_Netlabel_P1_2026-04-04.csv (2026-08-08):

designator | symbolId | pinNumber | pinRotation | pinName | netname | wireOrBusLength | noConnect
U2.1 |  | C1 | L | 81 | VSS | 0.3 | No
U2.1 |  | C2 | L | 82 |  |  | No
U2.1 |  | C3 | L | 83 |  |  | No
U2.1 |  | C4 | L | 84 | VSS | 0.3 | No
U2.1 |  | C5 | L | 85 | VSS | 0.3 | No
U2.1 |  | C6 | L | 86 |  |  | No
U2.1 |  | C7 | L | 87 |  |  | No
U2.1 |  | C8 | L | 88 | VSS | 0.3 | No
U2.1 |  | C9 | L | 89 | VSS | 0.3 | No
U2.1 |  | C10 | L | 90 | DINOUT16 | 0.4 | No
U2.1 |  | C11 | L | 91 | DINOUT17 | 0.4 | No
U2.1 |  | C12 | L | 92 | VSS | 0.3 | No
U2.1 |  | C13 | L | 93 | VSS | 0.3 | No
U2.1 |  | C14 | L | 94 | DINOUT20 | 0.4 | No
U2.1 |  | C15 | L | 95 | DINOUT21 | 0.4 | No
U2.1 |  | C16 | L | 96 | VSS | 0.3 | No
U2.1 |  | C17 | L | 97 | VSS | 0.3 | No
U2.1 |  | C18 | L | 98 | DINOUT24 | 0.4 | No
U2.1 |  | C19 | L | 99 | DINOUT25 | 0.4 | No
U2.1 |  | C20 | L | 100 | VSS | 0.3 | No
U2.1 |  | C21 | L | 101 | VSS | 0.3 | No
U2.1 |  | C22 | L | 102 | DINOUT28 | 0.4 | No
U2.1 |  | C23 | L | 103 | DINOUT29 | 0.4 | No
U2.1 |  | C24 | L | 104 | VSS | 0.3 | No
U2.1 |  | C25 | L | 105 | VSS | 0.3 | No
U2.1 |  | C26 | L | 106 | DINOUT48 | 0.4 | No
U2.1 |  | C27 | L | 107 | DINOUT49 | 0.4 | No
U2.1 |  | C28 | L | 108 | VSS | 0.3 | No
U2.1 |  | C29 | L | 109 | VSS | 0.3 | No
U2.1 |  | C30 | L | 110 |  |  | No
U2.1 |  | C31 | L | 111 |  |  | No
U2.1 |  | C32 | L | 112 | VSS | 0.3 | No
U2.1 |  | C33 | L | 113 | VSS | 0.3 | No
U2.1 |  | C34 | L | 114 | VSS | 0.3 | No
U2.1 |  | C35 | L | 115 |  |  | No
U2.1 |  | C36 | L | 116 | VSS | 0.3 | No
U2.1 |  | C37 | L | 117 |  |  | No
U2.1 |  | C38 | L | 118 | VSS | 0.3 | No
U2.1 |  | C39 | L | 119 |  |  | No
U2.1 |  | C40 | L | 120 | VSS | 0.3 | No
U2.1 |  | D1 | L | 121 |  |  | No
U2.1 |  | D2 | L | 122 | VSS |  | No
U2.1 |  | D3 | L | 123 | VSS | 0.3 | No
U2.1 |  | D4 | L | 124 |  |  | No
U2.1 |  | D5 | L | 125 |  |  | No
U2.1 |  | D6 | L | 126 | VSS | 0.3 | No
U2.1 |  | D7 | L | 127 | VSS | 0.3 | No
U2.1 |  | D8 | L | 128 | CLK_IC0 | 0.65 | No
U2.1 |  | D9 | L | 129 | VSS | 0.3 | No
U2.1 |  | D10 | L | 130 | VSS | 0.3 | No
U2.1 |  | D11 | L | 131 | DINOUT18 | 0.65 | No
U2.1 |  | D12 | L | 132 | DINOUT19 | 0.65 | No
U2.1 |  | D13 | L | 133 | VSS | 0.3 | No
U2.1 |  | D14 | L | 134 | DINOUT22 | 0.65 | No
U2.1 |  | D15 | L | 135 | DINOUT23 | 0.65 | No
U2.1 |  | D16 | L | 136 | VSS | 0.3 | No
U2.1 |  | D17 | L | 137 | DINOUT26 | 0.65 | No
U2.1 |  | D18 | L | 138 | DINOUT27 | 0.65 | No
U2.1 |  | D19 | L | 139 | VSS | 0.3 | No
U2.1 |  | D20 | L | 140 | DINOUT30 | 0.65 | No
U2.1 |  | D21 | L | 141 | DINOUT31 | 0.65 | No
U2.1 |  | D22 | L | 142 | VSS | 0.3 | No
U2.1 |  | D23 | L | 143 | DINOUT50 | 0.65 | No
U2.1 |  | D24 | L | 144 | DINOUT51 | 0.65 | No
U2.1 |  | D25 | L | 145 | VSS | 0.3 | No
U2.1 |  | D26 | L | 146 | DINOUT54 | 0.65 | No
U2.1 |  | D27 | L | 147 | DINOUT55 | 0.65 | No
U2.1 |  | D28 | L | 148 | VSS | 0.3 | No
U2.1 |  | D29 | L | 149 |  |  | No
U2.1 |  | D30 | L | 150 |  |  | No
U2.1 |  | D31 | L | 151 |  |  | No
U2.1 |  | D32 | L | 152 |  |  | No
U2.1 |  | D33 | L | 153 |  |  | No
U2.1 |  | D34 | L | 154 |  |  | No
U2.1 |  | D35 | L | 155 | VSS | 0.3 | No
U2.1 |  | D36 | L | 156 |  |  | No
U2.1 |  | D37 | L | 157 | VSS | 0.3 | No
U2.1 |  | D38 | L | 158 |  |  | No
U2.1 |  | D39 | L | 159 | VSS | 0.3 | No
U2.1 |  | D40 | L | 160 |  |  | No
U2.1 |  | A1 | R | 1 | VSS | 0.3 | No
U2.1 |  | A2 | R | 2 |  |  | No
U2.1 |  | A3 | R | 3 |  |  | No
U2.1 |  | A4 | R | 4 | VSS | 0.3 | No
U2.1 |  | A5 | R | 5 | VSS | 0.3 | No
U2.1 |  | A6 | R | 6 |  |  | No
U2.1 |  | A7 | R | 7 |  |  | No
U2.1 |  | A8 | R | 8 | VSS | 0.3 | No
U2.1 |  | A9 | R | 9 | VSS | 0.3 | No
U2.1 |  | A10 | R | 10 |  |  | No
U2.1 |  | A11 | R | 11 |  |  | No
U2.1 |  | A12 | R | 12 | VSS | 0.3 | No
U2.1 |  | A13 | R | 13 | VSS | 0.3 | No
U2.1 |  | A14 | R | 14 |  |  | No
U2.1 |  | A15 | R | 15 |  |  | No
U2.1 |  | A16 | R | 16 | VSS | 0.3 | No
U2.1 |  | A17 | R | 17 | VSS | 0.3 | No
U2.1 |  | A18 | R | 18 |  |  | No
U2.1 |  | A19 | R | 19 |  |  | No
U2.1 |  | A20 | R | 20 | VSS | 0.3 | No
U2.1 |  | A21 | R | 21 | VSS | 0.3 | No
U2.1 |  | A22 | R | 22 |  |  | No
U2.1 |  | A23 | R | 23 |  |  | No
U2.1 |  | A24 | R | 24 | VSS | 0.3 | No
U2.1 |  | A25 | R | 25 | VSS | 0.3 | No
U2.1 |  | A26 | R | 26 |  |  | No
U2.1 |  | A27 | R | 27 |  |  | No
U2.1 |  | A28 | R | 28 | VSS | 0.3 | No
U2.1 |  | A29 | R | 29 | VSS | 0.3 | No
U2.1 |  | A30 | R | 30 |  |  | No
U2.1 |  | A31 | R | 31 |  |  | No
U2.1 |  | A32 | R | 32 | VSS | 0.3 | No
U2.1 |  | A33 | R | 33 | VSS | 0.3 | No
U2.1 |  | A34 | R | 34 |  |  | No
U2.1 |  | A35 | R | 35 |  |  | No
U2.1 |  | A36 | R | 36 | VSS | 0.3 | No
U2.1 |  | A37 | R | 37 | VSS | 0.3 | No
U2.1 |  | A38 | R | 38 |  |  | No
U2.1 |  | A39 | R | 39 |  |  | No
U2.1 |  | A40 | R | 40 | VSS | 0.3 | No
U2.1 |  | B1 | R | 41 |  |  | No
U2.1 |  | B2 | R | 42 | VSS | 0.3 | No
U2.1 |  | B3 | R | 43 | VSS | 0.3 | No
U2.1 |  | B4 | R | 44 |  |  | No
U2.1 |  | B5 | R | 45 |  |  | No
U2.1 |  | B6 | R | 46 | VSS | 0.3 | No
U2.1 |  | B7 | R | 47 | VSS | 0.3 | No
U2.1 |  | B8 | R | 48 |  |  | No
U2.1 |  | B9 | R | 49 |  |  | No
U2.1 |  | B10 | R | 50 | VSS | 0.3 | No
U2.1 |  | B11 | R | 51 | VSS | 0.3 | No
U2.1 |  | B12 | R | 52 |  |  | No
U2.1 |  | B13 | R | 53 |  |  | No
U2.1 |  | B14 | R | 54 | VSS | 0.3 | No
U2.1 |  | B15 | R | 55 | VSS | 0.3 | No
U2.1 |  | B16 | R | 56 |  |  | No
U2.1 |  | B17 | R | 57 |  |  | No
U2.1 |  | B18 | R | 58 | VSS | 0.3 | No
U2.1 |  | B19 | R | 59 | VSS | 0.3 | No
U2.1 |  | B20 | R | 60 |  |  | No
U2.1 |  | B21 | R | 61 |  |  | No
U2.1 |  | B22 | R | 62 | VSS | 0.3 | No
U2.1 |  | B23 | R | 63 | VSS | 0.3 | No
U2.1 |  | B24 | R | 64 |  |  | No
U2.1 |  | B25 | R | 65 |  |  | No
U2.1 |  | B26 | R | 66 | VSS | 0.3 | No
U2.1 |  | B27 | R | 67 | VSS | 0.3 | No
U2.1 |  | B28 | R | 68 |  |  | No
U2.1 |  | B29 | R | 69 |  |  | No
U2.1 |  | B30 | R | 70 | VSS | 0.3 | No
U2.1 |  | B31 | R | 71 | VSS | 0.3 | No
U2.1 |  | B32 | R | 72 |  |  | No
U2.1 |  | B33 | R | 73 |  |  | No
U2.1 |  | B34 | R | 74 | VSS | 0.3 | No
U2.1 |  | B35 | R | 75 | VSS | 0.3 | No
U2.1 |  | B36 | R | 76 |  |  | No
U2.1 |  | B37 | R | 77 |  |  | No
U2.1 |  | B38 | R | 78 | VSS | 0.3 | No
U2.1 |  | B39 | R | 79 | VSS | 0.3 | No
U2.1 |  | B40 | R | 80 |  |  | No

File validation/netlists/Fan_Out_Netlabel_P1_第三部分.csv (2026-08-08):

designator | symbolId | pinNumber | pinRotation | pinName | netname | wireOrBusLength | noConnect
U2.3 |  | J1 | L | 321 | VSS | 0.3 | No
U2.3 |  | J2 | L | 322 |  |  | No
U2.3 |  | J3 | L | 323 |  |  | No
U2.3 |  | J4 | L | 324 | VSS | 0.3 | No
U2.3 |  | J5 | L | 325 | VSS | 0.3 | No
U2.3 |  | J6 | L | 326 |  |  | No
U2.3 |  | J7 | L | 327 |  |  | No
U2.3 |  | J8 | L | 328 | VSS | 0.3 | No
U2.3 |  | J9 | L | 329 |  |  | No
U2.3 |  | J10 | L | 330 |  |  | No
U2.3 |  | J11 | L | 331 | VSS | 0.3 | No
U2.3 |  | J12 | L | 332 |  |  | No
U2.3 |  | J13 | L | 333 |  |  | No
U2.3 |  | J14 | L | 334 | VSS | 0.3 | No
U2.3 |  | J15 | L | 335 | EN | 0.4 | No
U2.3 |  | J16 | L | 336 | WR_EN | 0.4 | No
U2.3 |  | J17 | L | 337 | VSS | 0.3 | No
U2.3 |  | J18 | L | 338 |  |  | No
U2.3 |  | J19 | L | 339 |  |  | No
U2.3 |  | J20 | L | 340 | VSS | 0.3 | No
U2.3 |  | J21 | L | 341 |  |  | No
U2.3 |  | J22 | L | 342 |  |  | No
U2.3 |  | J23 | L | 343 | VSS | 0.3 | No
U2.3 |  | J24 | L | 344 |  |  | No
U2.3 |  | J25 | L | 345 |  |  | No
U2.3 |  | J26 | L | 346 | VSS | 0.3 | No
U2.3 |  | J27 | L | 347 |  |  | No
U2.3 |  | J28 | L | 348 |  |  | No
U2.3 |  | J29 | L | 349 | VSS | 0.3 | No
U2.3 |  | J30 | L | 350 |  |  | No
U2.3 |  | J31 | L | 351 |  |  | No
U2.3 |  | J32 | L | 352 | VSS | 0.3 | No
U2.3 |  | J33 | L | 353 |  |  | No
U2.3 |  | J34 | L | 354 |  |  | No
U2.3 |  | J35 | L | 355 | VSS | 0.3 | No
U2.3 |  | J36 | L | 356 |  |  | No
U2.3 |  | J37 | L | 357 |  |  | No
U2.3 |  | J38 | L | 358 | VSS | 0.3 | No
U2.3 |  | J39 | L | 359 |  |  | No
U2.3 |  | J40 | L | 360 | VSS | 0.3 | No
U2.3 |  | K1 | R | 361 |  |  | No
U2.3 |  | K2 | R | 362 | VSS | 0.3 | No
U2.3 |  | K3 | R | 363 | VSS | 0.3 | No
U2.3 |  | K4 | R | 364 |  |  | No
U2.3 |  | K5 | R | 365 |  |  | No
U2.3 |  | K6 | R | 366 | VSS | 0.3 | No
U2.3 |  | K7 | R | 367 |  |  | No
U2.3 |  | K8 | R | 368 |  |  | No
U2.3 |  | K9 | R | 369 | VSS | 0.3 | No
U2.3 |  | K10 | R | 370 |  |  | No
U2.3 |  | K11 | R | 371 |  |  | No
U2.3 |  | K12 | R | 372 | VSS | 0.3 | No
U2.3 |  | K13 | R | 373 |  |  | No
U2.3 |  | K14 | R | 374 |  |  | No
U2.3 |  | K15 | R | 375 | VSS | 0.3 | No
U2.3 |  | K16 | R | 376 |  |  | No
U2.3 |  | K17 | R | 377 |  |  | No
U2.3 |  | K18 | R | 378 | VSS | 0.3 | No
U2.3 |  | K19 | R | 379 |  |  | No
U2.3 |  | K20 | R | 380 |  |  | No
U2.3 |  | K21 | R | 381 | VSS | 0.3 | No
U2.3 |  | K22 | R | 382 |  |  | No
U2.3 |  | K23 | R | 383 |  |  | No
U2.3 |  | K24 | R | 384 | VSS | 0.3 | No
U2.3 |  | K25 | R | 385 |  |  | No
U2.3 |  | K26 | R | 386 |  |  | No
U2.3 |  | K27 | R | 387 | VSS | 0.3 | No
U2.3 |  | K28 | R | 388 |  |  | No
U2.3 |  | K29 | R | 389 |  |  | No
U2.3 |  | K30 | R | 390 | VSS | 0.3 | No
U2.3 |  | K31 | R | 391 |  |  | No
U2.3 |  | K32 | R | 392 |  |  | No
U2.3 |  | K33 | R | 393 | VSS | 0.3 | No
U2.3 |  | K34 | R | 394 |  |  | No
U2.3 |  | K35 | R | 395 |  |  | No
U2.3 |  | K36 | R | 396 | VSS | 0.3 | No
U2.3 |  | K37 | R | 397 |  |  | No
U2.3 |  | K38 | R | 398 |  |  | No
U2.3 |  | K39 | R | 399 | VSS | 0.3 | No
U2.3 |  | K40 | R | 400 |  |  | No

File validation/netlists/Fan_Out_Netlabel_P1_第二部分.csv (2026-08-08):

designator | symbolId | pinNumber | pinRotation | pinName | netname | wireOrBusLength | noConnect
U2.2 |  | G1 | L | 241 | VSS | 0.3 | No
U2.2 |  | G2 | L | 242 |  |  | No
U2.2 |  | G3 | L | 243 |  |  | No
U2.2 |  | G4 | L | 244 | VSS | 0.3 | No
U2.2 |  | G5 | L | 245 | VSS | 0.3 | No
U2.2 |  | G6 | L | 246 | CLK_CORE0 | 0.45 | No
U2.2 |  | G7 | L | 247 | VSS | 0.3 | No
U2.2 |  | G8 | L | 248 | VSS | 0.3 | No
U2.2 |  | G9 | L | 249 | DINOUT2 | 0.4 | No
U2.2 |  | G10 | L | 250 | DINOUT3 | 0.4 | No
U2.2 |  | G11 | L | 251 | VSS | 0.3 | No
U2.2 |  | G12 | L | 252 | DINOUT6 | 0.4 | No
U2.2 |  | G13 | L | 253 | DINOUT7 | 0.4 | No
U2.2 |  | G14 | L | 254 | VSS | 0.3 | No
U2.2 |  | G15 | L | 255 | DINOUT10 | 0.4 | No
U2.2 |  | G16 | L | 256 | DINOUT11 | 0.4 | No
U2.2 |  | G17 | L | 257 | VSS | 0.3 | No
U2.2 |  | G18 | L | 258 | DINOUT14 | 0.4 | No
U2.2 |  | G19 | L | 259 | DINOUT15 | 0.4 | No
U2.2 |  | G20 | L | 260 | VSS | 0.3 | No
U2.2 |  | G21 | L | 261 | DINOUT34 | 0.4 | No
U2.2 |  | G22 | L | 262 | DINOUT35 | 0.4 | No
U2.2 |  | G23 | L | 263 | VSS | 0.3 | No
U2.2 |  | G24 | L | 264 | DINOUT38 | 0.4 | No
U2.2 |  | G25 | L | 265 | DINOUT39 | 0.4 | No
U2.2 |  | G26 | L | 266 | VSS | 0.3 | No
U2.2 |  | G27 | L | 267 | DINOUT42 | 0.4 | No
U2.2 |  | G28 | L | 268 | DINOUT43 | 0.4 | No
U2.2 |  | G29 | L | 269 | VSS | 0.3 | No
U2.2 |  | G30 | L | 270 | DINOUT46 | 0.4 | No
U2.2 |  | G31 | L | 271 | DINOUT47 | 0.4 | No
U2.2 |  | G32 | L | 272 | VSS | 0.3 | No
U2.2 |  | G33 | L | 273 | DINOUT58 | 0.4 | No
U2.2 |  | G34 | L | 274 | DINOUT59 | 0.4 | No
U2.2 |  | G35 | L | 275 | VSS | 0.3 | No
U2.2 |  | G36 | L | 276 | DINOUT62 | 0.4 | No
U2.2 |  | G37 | L | 277 | DINOUT63 | 0.4 | No
U2.2 |  | G38 | L | 278 | VSS | 0.3 | No
U2.2 |  | G39 | L | 279 |  |  | No
U2.2 |  | G40 | L | 280 | VSS | 0.3 | No
U2.2 |  | H1 | L | 281 |  |  | No
U2.2 |  | H2 | L | 282 |  |  | No
U2.2 |  | H3 | L | 283 | VSS | 0.3 | No
U2.2 |  | H4 | L | 284 |  |  | No
U2.2 |  | H5 | L | 285 |  |  | No
U2.2 |  | H6 | L | 286 | VSS | 0.3 | No
U2.2 |  | H7 | L | 287 | DINOUT0 | 0.5 | No
U2.2 |  | H8 | L | 288 | DINOUT1 | 0.5 | No
U2.2 |  | H9 | L | 289 | VSS | 0.3 | No
U2.2 |  | H10 | L | 290 | DINOUT4 | 0.5 | No
U2.2 |  | H11 | L | 291 | DINOUT5 | 0.5 | No
U2.2 |  | H12 | L | 292 | VSS | 0.3 | No
U2.2 |  | H13 | L | 293 | DINOUT8 | 0.5 | No
U2.2 |  | H14 | L | 294 | DINOUT9 | 0.5 | No
U2.2 |  | H15 | L | 295 | VSS | 0.3 | No
U2.2 |  | H16 | L | 296 | DINOUT12 | 0.5 | No
U2.2 |  | H17 | L | 297 | DINOUT13 | 0.5 | No
U2.2 |  | H18 | L | 298 | VSS | 0.3 | No
U2.2 |  | H19 | L | 299 | DINOUT52 | 0.4 | No
U2.2 |  | H20 | L | 300 | DINOUT53 | 0.4 | No
U2.2 |  | H21 | L | 301 | VSS | 0.3 | No
U2.2 |  | H22 | L | 302 | DINOUT32 | 0.5 | No
U2.2 |  | H23 | L | 303 | DINOUT33 | 0.5 | No
U2.2 |  | H24 | L | 304 | VSS | 0.3 | No
U2.2 |  | H25 | L | 305 | DINOUT36 | 0.5 | No
U2.2 |  | H26 | L | 306 | DINOUT37 | 0.5 | No
U2.2 |  | H27 | L | 307 | VSS | 0.3 | No
U2.2 |  | H28 | L | 308 | DINOUT40 | 0.5 | No
U2.2 |  | H29 | L | 309 | DINOUT41 | 0.5 | No
U2.2 |  | H30 | L | 310 | VSS | 0.3 | No
U2.2 |  | H31 | L | 311 | DINOUT44 | 0.5 | No
U2.2 |  | H32 | L | 312 | DINOUT45 | 0.5 | No
U2.2 |  | H33 | L | 313 | VSS | 0.3 | No
U2.2 |  | H34 | L | 314 | DINOUT56 | 0.5 | No
U2.2 |  | H35 | L | 315 | DINOUT57 | 0.5 | No
U2.2 |  | H36 | L | 316 | VSS | 0.3 | No
U2.2 |  | H37 | L | 317 | DINOUT60 | 0.5 | No
U2.2 |  | H38 | L | 318 | DINOUT61 | 0.5 | No
U2.2 |  | H39 | L | 319 | VSS | 0.3 | No
U2.2 |  | H40 | L | 320 |  |  | No
U2.2 |  | E1 | R | 161 | VSS | 0.3 | No
U2.2 |  | E2 | R | 162 | ADDR0 | 0.3 | No
U2.2 |  | E3 | R | 163 | ADDR1 | 0.3 | No
U2.2 |  | E4 | R | 164 | VSS | 0.3 | No
U2.2 |  | E5 | R | 165 | VSS | 0.3 | No
U2.2 |  | E6 | R | 166 | ADDR4 | 0.3 | No
U2.2 |  | E7 | R | 167 | ADDR5 | 0.3 | No
U2.2 |  | E8 | R | 168 | VSS | 0.3 | No
U2.2 |  | E9 | R | 169 | ADDR8 | 0.3 | No
U2.2 |  | E10 | R | 170 | ADDR9 | 0.3 | No
U2.2 |  | E11 | R | 171 | VSS | 0.3 | No
U2.2 |  | E12 | R | 172 | ADDR12 | 0.3 | No
U2.2 |  | E13 | R | 173 | ADDR13 | 0.3 | No
U2.2 |  | E14 | R | 174 | VSS | 0.3 | No
U2.2 |  | E15 | R | 175 | INPUT_FULL | 0.4 | No
U2.2 |  | E16 | R | 176 | OUTPUT_EMPTY | 0.4 | No
U2.2 |  | E17 | R | 177 | VSS | 0.3 | No
U2.2 |  | E18 | R | 178 |  |  | No
U2.2 |  | E19 | R | 179 |  |  | No
U2.2 |  | E20 | R | 180 | VSS | 0.3 | No
U2.2 |  | E21 | R | 181 |  |  | No
U2.2 |  | E22 | R | 182 |  |  | No
U2.2 |  | E23 | R | 183 | VSS | 0.3 | No
U2.2 |  | E24 | R | 184 |  |  | No
U2.2 |  | E25 | R | 185 |  |  | No
U2.2 |  | E26 | R | 186 | VSS | 0.3 | No
U2.2 |  | E27 | R | 187 |  |  | No
U2.2 |  | E28 | R | 188 |  |  | No
U2.2 |  | E29 | R | 189 | VSS | 0.3 | No
U2.2 |  | E30 | R | 190 |  |  | No
U2.2 |  | E31 | R | 191 |  |  | No
U2.2 |  | E32 | R | 192 | VSS | 0.3 | No
U2.2 |  | E33 | R | 193 |  |  | No
U2.2 |  | E34 | R | 194 |  |  | No
U2.2 |  | E35 | R | 195 | VSS | 0.3 | No
U2.2 |  | E36 | R | 196 |  |  | No
U2.2 |  | E37 | R | 197 |  |  | No
U2.2 |  | E38 | R | 198 | VSS | 0.3 | No
U2.2 |  | E39 | R | 199 |  |  | No
U2.2 |  | E40 | R | 200 | VSS | 0.3 | No
U2.2 |  | F1 | R | 201 |  |  | No
U2.2 |  | F2 | R | 202 | VSS | 0.3 | No
U2.2 |  | F3 | R | 203 | VSS | 0.3 | No
U2.2 |  | F4 | R | 204 | RST_N_CORE | 0.3 | No
U2.2 |  | F5 | R | 205 | RST_N_IO | 0.3 | No
U2.2 |  | F6 | R | 206 | VSS | 0.3 | No
U2.2 |  | F7 | R | 207 | ADDR2 | 0.3 | No
U2.2 |  | F8 | R | 208 | ADDR3 | 0.3 | No
U2.2 |  | F9 | R | 209 | VSS | 0.3 | No
U2.2 |  | F10 | R | 210 | ADDR6 | 0.3 | No
U2.2 |  | F11 | R | 211 | ADDR7 | 0.3 | No
U2.2 |  | F12 | R | 212 | VSS | 0.3 | No
U2.2 |  | F13 | R | 213 | ADDR10 | 0.3 | No
U2.2 |  | F14 | R | 214 | ADDR11 | 0.3 | No
U2.2 |  | F15 | R | 215 | VSS | 0.3 | No
U2.2 |  | F16 | R | 216 | ADDR14 | 0.3 | No
U2.2 |  | F17 | R | 217 | ADDR15 | 0.3 | No
U2.2 |  | F18 | R | 218 | VSS | 0.3 | No
U2.2 |  | F19 | R | 219 | MACMACHINE_DONE | 0.3 | No
U2.2 |  | F20 | R | 220 | MACMACHINE_ERROR | 0.3 | No
U2.2 |  | F21 | R | 221 | VSS | 0.3 | No
U2.2 |  | F22 | R | 222 |  |  | No
U2.2 |  | F23 | R | 223 |  |  | No
U2.2 |  | F24 | R | 224 | VSS | 0.3 | No
U2.2 |  | F25 | R | 225 |  |  | No
U2.2 |  | F26 | R | 226 |  |  | No
U2.2 |  | F27 | R | 227 | VSS | 0.3 | No
U2.2 |  | F28 | R | 228 |  |  | No
U2.2 |  | F29 | R | 229 |  |  | No
U2.2 |  | F30 | R | 230 | VSS | 0.3 | No
U2.2 |  | F31 | R | 231 |  |  | No
U2.2 |  | F32 | R | 232 |  |  | No
U2.2 |  | F33 | R | 233 | VSS | 0.3 | No
U2.2 |  | F34 | R | 234 |  |  | No
U2.2 |  | F35 | R | 235 |  |  | No
U2.2 |  | F36 | R | 236 | VSS | 0.3 | No
U2.2 |  | F37 | R | 237 |  |  | No
U2.2 |  | F38 | R | 238 |  |  | No
U2.2 |  | F39 | R | 239 | VSS | 0.3 | No
U2.2 |  | F40 | R | 240 |  |  | No

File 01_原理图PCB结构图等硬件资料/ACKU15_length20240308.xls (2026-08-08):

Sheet: BANK64
FPGA管脚号 | 网络名 | 线长（mils)
AV22 | B64_L1_N | 2349.624
AU22 | B64_L1_P | 2350.582
AL21 | B64_L10_N | 2346.749
AK21 | B64_L10_P | 2346.168
AN20 | B64_L11_N | 2306.581
AN21 | B64_L11_P | 2307.992
AM20 | B64_L12_N | 2378.629
AL20 | B64_L12_P | 2379.052
AR19 | B64_L13_N | 2301.853
AP19 | B64_L13_P | 2302.4
AP18 | B64_L14_N | 2321.599
AN18 | B64_L14_P | 2321.894
AT19 | B64_L15_N | 2347.539
AT20 | B64_L15_P | 2348.157
AU17 | B64_L16_N | 2334.557
AT17 | B64_L16_P | 2334.694
AU18 | B64_L17_N | 2356.26
AU19 | B64_L17_P | 2356.829
AR17 | B64_L18_N | 2354.389
AR18 | B64_L18_P | 2354.68
AJ21 | B64_L19_N | 2398.936
AH21 | B64_L19_P | 2399.186
AV20 | B64_L2_N | 2313.476
AU20 | B64_L2_P | 2313.738
AM19 | B64_L20_N | 2355.583
AL19 | B64_L20_P | 2355.256
AJ19 | B64_L21_N | 2379.504
AJ20 | B64_L21_P | 2379.895
AK18 | B64_L22_N | 2310.991
AK19 | B64_L22_P | 2309.499
AJ18 | B64_L23_N | 2455.08
AH18 | B64_L23_P | 2456.344
AM17 | B64_L24_N | 2333.866
AM18 | B64_L24_P | 2332.887
AW21 | B64_L3_N | 2308.563
AV21 | B64_L3_P | 2308.652
AW19 | B64_L4_N | 2331.146
AW20 | B64_L4_P | 2331.084
AT21 | B64_L5_N | 2318.683
AT22 | B64_L5_P | 2317.811
AW18 | B64_L6_N | 2332.143
AV18 | B64_L6_P | 2331.336
AR21 | B64_L7_N | 2414.039
AR22 | B64_L7_P | 2414.25
AM22 | B64_L8_N | 2302.981
AL22 | B64_L8_P | 2302.901
AP20 | B64_L9_N | 2475.917
AP21 | B64_L9_P | 2477.845

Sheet: BANK65
FPGA管脚号 | 网络名 | 线长（mils)
AW10 | B65_L1_N | 2517.772
AW11 | B65_L1_P | 2519.244
AR16 | B65_L10_N | 2543.094
AP16 | B65_L10_P | 2543.66
AT14 | B65_L11_N | 2571.789
AR14 | B65_L11_P | 2571.863
AP14 | B65_L12_N | 2526.094
AP15 | B65_L12_P | 2526.634
AL14 | B65_L13_N | 2543.083
AL15 | B65_L13_P | 2543.247
AN15 | B65_L14_N | 2507.309
AM15 | B65_L14_P | 2507.909
AK14 | B65_L15_N | 2539.333
AJ14 | B65_L15_P | 2539.464
AL17 | B65_L16_N | 2499.848
AK17 | B65_L16_P | 2499.084
AJ15 | B65_L17_N | 2594.357
AJ16 | B65_L17_P | 2594.191
AL16 | B65_L18_N | 2548.234
AK16 | B65_L18_P | 2546.859
AT11 | B65_L19_N | 2516.644
AT12 | B65_L19_P | 2516.481
AP13 | B65_L20_N | 2518.256
AN13 | B65_L20_P | 2518.805
AR11 | B65_L23_N | 2546.491
AP11 | B65_L23_P | 2546.19
AM13 | B65_L24_N | 2505.928
AM14 | B65_L24_P | 2506.404
AW13 | B65_L3_N | 2518.468
AW14 | B65_L3_P | 2517.853
AV10 | B65_L4_N | 2613.235
AU10 | B65_L4_P | 2613.18
AV12 | B65_L5_N | 2526.461
AV13 | B65_L5_P | 2526.059
AU13 | B65_L6_N | 2557.449
AU14 | B65_L6_P | 2556.608
AW16 | B65_L7_N | 2512.165
AV16 | B65_L7_P | 2512.814
AU15 | B65_L8_N | 2572.908
AT15 | B65_L8_P | 2573.851
AW15 | B65_L9_N | 2505.374
AV15 | B65_L9_P | 2505.877
AN16 | B65_T2U | 2496.7
AP10 | B65_T3U | 2508.8

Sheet: BANK69
FPGA管脚号 | 网络名 | 线长（mils)
M26 | B69_L1_N | 2269.75
M25 | B69_L1_P | 2269.175
F31 | B69_L10_N | 2250.703
G31 | B69_L10_P | 2250.746
F27 | B69_L11_N | 2257.258
G27 | B69_L11_P | 2257.312
G30 | B69_L12_N | 2255.37
G29 | B69_L12_P | 2255.467
F29 | B69_L13_N | 2275.271
F28 | B69_L13_P | 2274.854
E29 | B69_L14_N | 2267.95
E28 | B69_L14_P | 2267.688
D31 | B69_L15_N | 2250.189
E31 | B69_L15_P | 2251.675
D30 | B69_L16_N | 2236.292
E30 | B69_L16_P | 2236.524
D26 | B69_L17_N | 2277.292
E26 | B69_L17_P | 2276.747
D28 | B69_L18_N | 2252.806
D27 | B69_L18_P | 2251.981
B29 | B69_L19_N | 2257.596
C29 | B69_L19_P | 2257.748
H27 | B69_L2_N | 2229.966
J27 | B69_L2_P | 2231.219
C28 | B69_L20_N | 2250.626
C27 | B69_L20_P | 2249.605
A31 | B69_L21_N | 2258.655
B31 | B69_L21_P | 2259.652
A27 | B69_L22_N | 2269.061
B27 | B69_L22_P | 2270.111
A26 | B69_L23_N | 2245.288
B26 | B69_L23_P | 2245.471
A29 | B69_L24_N | 2258.134
A28 | B69_L24_P | 2258.583
L27 | B69_L3_N | 2278.637
L26 | B69_L3_P | 2278.509
H25 | B69_L4_N | 2266.622
J25 | B69_L4_P | 2265.391
J26 | B69_L5_N | 2250.22
K26 | B69_L5_P | 2250.613
G26 | B69_L6_N | 2243.352
G25 | B69_L6_P | 2244.221
J31 | B69_L7_N | 2265.036
J30 | B69_L7_P | 2265.074
H30 | B69_L8_N | 2254.828
H29 | B69_L8_P | 2255.06
H28 | B69_L9_N | 2248.335
J28 | B69_L9_P | 2249.359

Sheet: BANK70
FPGA管脚号 | 网络名 | 线长（mils)
M22 | B70_L1_N | 2100.935
M21 | B70_L1_P | 2100.918
G20 | B70_L10_N | 2077.254
H20 | B70_L10_P | 2078.242
F21 | B70_L11_N | 2072.922
G21 | B70_L11_P | 2073.304
F22 | B70_L12_N | 2088.301
G22 | B70_L12_P | 2088.352
F24 | B70_L13_N | 2096.38
F23 | B70_L13_P | 2096.438
E24 | B70_L14_N | 2074.964
E23 | B70_L14_P | 2075.735
D25 | B70_L15_N | 2085.046
E25 | B70_L15_P | 2085.685
D23 | B70_L16_N | 2090.355
D22 | B70_L16_P | 2091.264
D21 | B70_L17_N | 2077.354
E21 | B70_L17_P | 2077.773
D20 | B70_L18_N | 2094.252
E20 | B70_L18_P | 2094.989
C23 | B70_L19_N | 2079.759
C22 | B70_L19_P | 2079.764
M20 | B70_L2_N | 2073.038
M19 | B70_L2_P | 2072.544
B20 | B70_L20_N | 2070.041
C20 | B70_L20_P | 2070.746
A21 | B70_L21_N | 2080.05
B21 | B70_L21_P | 2080.285
A22 | B70_L22_N | 2078.751
B22 | B70_L22_P | 2077.816
B25 | B70_L23_N | 2082.417
B24 | B70_L23_P | 2083.018
A24 | B70_L24_N | 2068.965
A23 | B70_L24_P | 2064.132
L24 | B70_L3_N | 2096.72
L23 | B70_L3_P | 2096.479
L22 | B70_L4_N | 2091.953
L21 | B70_L4_P | 2091.487
K24 | B70_L5_N | 2078.799
K23 | B70_L5_P | 2079.299
K21 | B70_L6_N | 2075.215
K20 | B70_L6_P | 2074.993
H22 | B70_L7_N | 2098.046
J22 | B70_L7_P | 2098.704
J21 | B70_L8_N | 2073.967
J20 | B70_L8_P | 2073.918
G24 | B70_L9_N | 2083.829
H24 | B70_L9_P | 2084.309

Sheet: BANK71
FPGA管脚号 | 网络名 | 线长（mils)
M15 | B71_L1_N | 2219.893
M16 | B71_L1_P | 2220.065
F14 | B71_L10_N | 2196.832
G15 | B71_L10_P | 2196.983
G16 | B71_L11_N | 2196.064
G17 | B71_L11_P | 2196.754
G19 | B71_L12_N | 2204.962
H19 | B71_L12_P | 2205
F18 | B71_L13_N | 2192.958
F19 | B71_L13_P | 2193.281
F16 | B71_L14_N | 2191.544
F17 | B71_L14_P | 2191.733
E18 | B71_L15_N | 2200.327
E19 | B71_L15_P | 2199.665
E15 | B71_L16_N | 2195.841
E16 | B71_L16_P | 2195.983
D17 | B71_L17_N | 2205.712
D18 | B71_L17_P | 2205.112
D15 | B71_L18_N | 2194.869
D16 | B71_L18_P | 2195.474
C17 | B71_L19_N | 2198.487
C18 | B71_L19_P | 2198.037
K19 | B71_L2_N | 2194.872
L19 | B71_L2_P | 2195.715
C14 | B71_L20_N | 2195.304
C15 | B71_L20_P | 2195.127
A19 | B71_L21_N | 2203.437
B19 | B71_L21_P | 2204.221
B15 | B71_L22_N | 2195.66
B16 | B71_L22_P | 2196.869
A17 | B71_L23_N | 2211.81
A18 | B71_L23_P | 2211.303
A16 | B71_L24_N | 2197.164
B17 | B71_L24_P | 2198.339
K18 | B71_L3_N | 2243.11
L18 | B71_L3_P | 2243.732
L16 | B71_L4_N | 2198.414
L17 | B71_L4_P | 2198.661
J16 | B71_L5_N | 2196.062
K16 | B71_L5_P | 2196.331
K14 | B71_L6_N | 2177.14
K15 | B71_L6_P | 2176.813
H15 | B71_L7_N | 2200.523
J15 | B71_L7_P | 2201.005
H17 | B71_L8_N | 2208.625
H18 | B71_L8_P | 2208.825
G14 | B71_L9_N | 2185.594
H14 | B71_L9_P | 2186.616

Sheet: BANK90~94
FPGA管脚号 | 网络名 | 线长（mils)
E4 | B90_L1_N | 2343.994
E5 | B90_L1_P | 2343.79
B4 | B90_L10_N | 2278.158
B5 | B90_L10_P | 2278.673
A3 | B90_L11_N | 2273.916
A4 | B90_L11_P | 2274.513
A6 | B90_L12_N | 2285.824
B6 | B90_L12_P | 2285.411
E3 | B90_L2_N | 2277.014
F4 | B90_L2_P | 2276.893
F2 | B90_L3_N | 2276.636
F3 | B90_L3_P | 2276.443
E1 | B90_L4_N | 2275.452
F1 | B90_L4_P | 2274.143
D5 | B90_L5_N | 2301.048
D6 | B90_L5_P | 2301.146
D1 | B90_L6_N | 2271.237
D2 | B90_L6_P | 2271.643
C3 | B90_L7_N | 2278.034
D3 | B90_L7_P | 2277.782
C4 | B90_L8_N | 2274.666
C5 | B90_L8_P | 2274.864
B2 | B90_L9_N | 2272.31
C2 | B90_L9_P | 2272.011
E6 | B91_L1_N | 2795.588
F6 | B91_L1_P | 2795.369
A8 | B91_L10_N | 2792.972
B9 | B91_L10_P | 2793.173
A9 | B91_L11_N | 2796.156
B10 | B91_L11_P | 2796.779
A11 | B91_L12_N | 2794.548
B11 | B91_L12_P | 2793.572
F7 | B91_L2_N | 2797.289
F8 | B91_L2_P | 2796.631
E8 | B91_L3_N | 2796.089
F9 | B91_L3_P | 2796.61
E9 | B91_L4_N | 2793.71
E10 | B91_L4_P | 2793.306
D7 | B91_L5_N | 2814.248
D8 | B91_L5_P | 2814.723
D10 | B91_L6_N | 2817.679
D11 | B91_L6_P | 2818.372
C7 | B91_L7_N | 2790.496
C8 | B91_L7_P | 2791.07
C9 | B91_L8_N | 2801.625
C10 | B91_L8_P | 2802.282
A7 | B91_L9_N | 2794.411
B7 | B91_L9_P | 2794.232
P15 | B93_L1_N | 2499.898
R15 | B93_L1_P | 2498.846
K13 | B93_L10_N | 2497.728
L13 | B93_L10_P | 2498.347
L11 | B93_L11_N | 2491.497
L12 | B93_L11_P | 2491.431
K10 | B93_L12_N | 2496.735
K11 | B93_L12_P | 2497.455
R13 | B93_L2_N | 2492.17
R14 | B93_L2_P | 2492.223
P12 | B93_L3_N | 2496.589
P13 | B93_L3_P | 2496.462
P10 | B93_L4_N | 2498.214
P11 | B93_L4_P | 2498.362
N14 | B93_L5_N | 2513.502
N15 | B93_L5_P | 2514.581
N12 | B93_L6_N | 2499.342
N13 | B93_L6_P | 2499.648
L14 | B93_L7_N | 2497.492
M14 | B93_L7_P | 2497.599
M11 | B93_L8_N | 2494.099
M12 | B93_L8_P | 2494.737
M10 | B93_L9_N | 2497.896
N10 | B93_L9_P | 2498.038
J12 | B94_L1_N | 1673.266
J13 | B94_L1_P | 1673.586
J10 | B94_L2_N | 1697.184
J11 | B94_L2_P | 1697.56
H12 | B94_L3_N | 1674.55
H13 | B94_L3_P | 1674.313
G10 | B94_L4_N | 1673.423
H10 | B94_L4_P | 1673.265
E11 | B94_L6_N | 1672.86
F11 | B94_L6_P | 1672.918
F12 | B94_L7_N | 1668.123
F13 | B94_L7_P | 1668.071
D13 | B94_L8_N | 1673.383
E13 | B94_L8_P | 1673.659
C12 | B94_L9_N | 1675.963
D12 | B94_L9_P | 1676.804

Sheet: MGTY127~132
FPGA管脚号 | 网络名 | 线长（mils)
AE30 | MGT127_CLK0_N | 1008.559
AE29 | MGT127_CLK0_P | 1009.131
AC30 | MGT127_CLK1_N | 1086.834
AC29 | MGT127_CLK1_P | 1087.423
AH37 | MGT127_RX0_N | 1386.863
AH36 | MGT127_RX0_P | 1388.544
AG39 | MGT127_RX1_N | 1386.545
AG38 | MGT127_RX1_P | 1387.481
AF37 | MGT127_RX2_N | 1384.809
AF36 | MGT127_RX2_P | 1385.34
AE39 | MGT127_RX3_N | 1381.203
AE38 | MGT127_RX3_P | 1381.456
AF32 | MGT127_TX0_N | 1375.565
AF31 | MGT127_TX0_P | 1376.222
AE34 | MGT127_TX1_N | 1372.506
AE33 | MGT127_TX1_P | 1372.709
AD32 | MGT127_TX2_N | 1372.27
AD31 | MGT127_TX2_P | 1372.578
AC34 | MGT127_TX3_N | 1373.491
AC33 | MGT127_TX3_P | 1373.618
AB28 | MGT128_CLK0_N | 1282.512
AB27 | MGT128_CLK0_P | 1282.316
AA30 | MGT128_CLK1_N | 1416.269
AA29 | MGT128_CLK1_P | 1415.419
AD37 | MGT128_RX0_N | 1541.69
AD36 | MGT128_RX0_P | 1541.741
AC39 | MGT128_RX1_N | 1538.835
AC38 | MGT128_RX1_P | 1539.568
AB37 | MGT128_RX2_N | 1537.242
AB36 | MGT128_RX2_P | 1537.337
AA39 | MGT128_RX3_N | 1539.805
AA38 | MGT128_RX3_P | 1539.229
AB32 | MGT128_TX0_N | 1618.877
AB31 | MGT128_TX0_P | 1619.253
AA34 | MGT128_TX1_N | 1614.013
AA33 | MGT128_TX1_P | 1614.477
Y32 | MGT128_TX2_N | 1617.363
Y31 | MGT128_TX2_P | 1617.547
W34 | MGT128_TX3_N | 1617.656
W33 | MGT128_TX3_P | 1617.997
Y28 | MGT129_CLK0_N | 1138.527
Y27 | MGT129_CLK0_P | 1139.401
W30 | MGT129_CLK1_N | 1096.206
W29 | MGT129_CLK1_P | 1097.019
Y37 | MGT129_RX0_N | 1277.199
Y36 | MGT129_RX0_P | 1277.827
W39 | MGT129_RX1_N | 1280.698
W38 | MGT129_RX1_P | 1281.348
V37 | MGT129_RX2_N | 1278.387
V36 | MGT129_RX2_P | 1278.773
U39 | MGT129_RX3_N | 1279.773
U38 | MGT129_RX3_P | 1280.365
V32 | MGT129_TX0_N | 1348.242
V31 | MGT129_TX0_P | 1348.458
U34 | MGT129_TX1_N | 1338.862
U33 | MGT129_TX1_P | 1339.469
T32 | MGT129_TX2_N | 1344.236
T31 | MGT129_TX2_P | 1344.758
R34 | MGT129_TX3_N | 1351.272
R33 | MGT129_TX3_P | 1352.401
V28 | MGT130_CLK0_N | 1236.342
V27 | MGT130_CLK0_P | 1237.357
U30 | MGT130_CLK1_N | 1269.42
U29 | MGT130_CLK1_P | 1267.999
T37 | MGT130_RX0_N | 1481.445
T36 | MGT130_RX0_P | 1481.413
R39 | MGT130_RX1_N | 1474.416
R38 | MGT130_RX1_P | 1474.663
P37 | MGT130_RX2_N | 1480.551
P36 | MGT130_RX2_P | 1480.827
N39 | MGT130_RX3_N | 1481.392
N38 | MGT130_RX3_P | 1480.864
P32 | MGT130_TX0_N | 1636.363
P31 | MGT130_TX0_P | 1636.736
N34 | MGT130_TX1_N | 1633.638
N33 | MGT130_TX1_P | 1632.805
M32 | MGT130_TX2_N | 1632.337
M31 | MGT130_TX2_P | 1632.326
L34 | MGT130_TX3_N | 1637.71
L33 | MGT130_TX3_P | 1638.429
T28 | MGT131_CLK0_N | 1072.269
T27 | MGT131_CLK0_P | 1072.038
R30 | MGT131_CLK1_N | 1052.05
R29 | MGT131_CLK1_P | 1052.872
M37 | MGT131_RX0_N | 1321.175
M36 | MGT131_RX0_P | 1322.302
L39 | MGT131_RX1_N | 1320.015
L38 | MGT131_RX1_P | 1320.64
K37 | MGT131_RX2_N | 1316.368
K36 | MGT131_RX2_P | 1316.826
J39 | MGT131_RX3_N | 1321.774
J38 | MGT131_RX3_P | 1321.91
J34 | MGT131_TX0_N | 1524.298
J33 | MGT131_TX0_P | 1524.622
G34 | MGT131_TX1_N | 1525.431
G33 | MGT131_TX1_P | 1525.795
F36 | MGT131_TX2_N | 1529.345
F35 | MGT131_TX2_P | 1529.58
E34 | MGT131_TX3_N | 1524.166
E33 | MGT131_TX3_P | 1524.477
P28 | MGT132_CLK0_N | 1307.236
P27 | MGT132_CLK0_P | 1307.591
N30 | MGT132_CLK1_N | 1344.885
N29 | MGT132_CLK1_P | 1345.243
H37 | MGT132_RX0_N | 1559.102
H36 | MGT132_RX0_P | 1558.208
G39 | MGT132_RX1_N | 1558.477
G38 | MGT132_RX1_P | 1558.086
E39 | MGT132_RX2_N | 1557.095
E38 | MGT132_RX2_P | 1557.26
C39 | MGT132_RX3_N | 1558.515
C38 | MGT132_RX3_P | 1559.11
D36 | MGT132_TX0_N | 1864.766
D35 | MGT132_TX0_P | 1865.359
C34 | MGT132_TX1_N | 1862.821
C33 | MGT132_TX1_P | 1863.062
B36 | MGT132_TX2_N | 1863.343
B35 | MGT132_TX2_P | 1863.579
A34 | MGT132_TX3_N | 1862.653
A33 | MGT132_TX3_P | 1862.966

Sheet: MGTH224~231
FPGA管脚号 | 网络名 | 线长（mils)
AM9 | MGT224_CLK0_N | 1325.114
AM10 | MGT224_CLK0_P | 1325.074
AK9 | MGT224_CLK1_N | 1525.635
AK10 | MGT224_CLK1_P | 1525.673
AW3 | MGT224_RX0_N | 2112.427
AW4 | MGT224_RX0_P | 2112.199
AV1 | MGT224_RX1_N | 2114.376
AV2 | MGT224_RX1_P | 2114.608
AU3 | MGT224_RX2_N | 2122.488
AU4 | MGT224_RX2_P | 2122.462
AT1 | MGT224_RX3_N | 2127.87
AT2 | MGT224_RX3_P | 2127.84
AW7 | MGT224_TX0_N | 1928.975
AW8 | MGT224_TX0_P | 1929.093
AV5 | MGT224_TX1_N | 1928.598
AV6 | MGT224_TX1_P | 1928.542
AU7 | MGT224_TX2_N | 1929.596
AU8 | MGT224_TX2_P | 1929.713
AT5 | MGT224_TX3_N | 1930.591
AT6 | MGT224_TX3_P | 1930.55
AJ11 | MGT225_CLK0_N | 1765.752
AJ12 | MGT225_CLK0_P | 1765.79
AH9 | MGT225_CLK1_N | 1805.242
AH10 | MGT225_CLK1_P | 1805.28
AR3 | MGT225_RX0_N | 1926.734
AR4 | MGT225_RX0_P | 1926.784
AP1 | MGT225_RX1_N | 1929.987
AP2 | MGT225_RX1_P | 1930.304
AN3 | MGT225_RX2_N | 1929.011
AN4 | MGT225_RX2_P | 1929.079
AM1 | MGT225_RX3_N | 1930.691
AM2 | MGT225_RX3_P | 1930.999
AR7 | MGT225_TX0_N | 1971.847
AR8 | MGT225_TX0_P | 1971.965
AP5 | MGT225_TX1_N | 1974.871
AP6 | MGT225_TX1_P | 1974.818
AN7 | MGT225_TX2_N | 1975.284
AN8 | MGT225_TX2_P | 1975.391
AM5 | MGT225_TX3_N | 1976.734
AM6 | MGT225_TX3_P | 1976.672
AG11 | MGT226_CLK0_N | 1980.679
AG12 | MGT226_CLK0_P | 1980.717
AF9 | MGT226_CLK1_N | 2025.146
AF10 | MGT226_CLK1_P | 2025.184
AL3 | MGT226_RX0_N | 2324.416
AL4 | MGT226_RX0_P | 2324.461
AK1 | MGT226_RX1_N | 2326.355
AK2 | MGT226_RX1_P | 2326.673
AJ3 | MGT226_RX2_N | 2329.168
AJ4 | MGT226_RX2_P | 2329.224
AH1 | MGT226_RX3_N | 2329.54
AH2 | MGT226_RX3_P | 2329.858
AL7 | MGT226_TX0_N | 2319.161
AL8 | MGT226_TX0_P | 2319.277
AK5 | MGT226_TX1_N | 2320.81
AK6 | MGT226_TX1_P | 2320.767
AJ7 | MGT226_TX2_N | 2320.078
AJ8 | MGT226_TX2_P | 2319.597
AH5 | MGT226_TX3_N | 2321.824
AH6 | MGT226_TX3_P | 2321.773
AE11 | MGT227_CLK0_N | 1664.494
AE12 | MGT227_CLK0_P | 1662.065
AD9 | MGT227_CLK1_N | 1498.793
AD10 | MGT227_CLK1_P | 1499.069
AG3 | MGT227_RX0_N | 1951.391
AG4 | MGT227_RX0_P | 1951.748
AF1 | MGT227_RX1_N | 1949.497
AF2 | MGT227_RX1_P | 1950.079
AE3 | MGT227_RX2_N | 1947.949
AE4 | MGT227_RX2_P | 1948.731
AD1 | MGT227_RX3_N | 1949.105
AD2 | MGT227_RX3_P | 1949.267
AG7 | MGT227_TX0_N | 1848.371
AG8 | MGT227_TX0_P | 1848.699
AF5 | MGT227_TX1_N | 1845.12
AF6 | MGT227_TX1_P | 1845.2
AE7 | MGT227_TX2_N | 1848.478
AE8 | MGT227_TX2_P | 1848.551
AD5 | MGT227_TX3_N | 1846.404
AD6 | MGT227_TX3_P | 1846.787
AC11 | MGT228_CLK0_N | 1773.561
AC12 | MGT228_CLK0_P | 1773.434
AB9 | MGT228_CLK1_N | 1669.797
AB10 | MGT228_CLK1_P | 1669.423
AC3 | MGT228_RX0_N | 1940.057
AC4 | MGT228_RX0_P | 1940.19
AB1 | MGT228_RX1_N | 1938.044
AB2 | MGT228_RX1_P | 1938.201
AA3 | MGT228_RX2_N | 1937.503
AA4 | MGT228_RX2_P | 1937.734
Y1 | MGT228_RX3_N | 1936.622
Y2 | MGT228_RX3_P | 1936.734
AC7 | MGT228_TX0_N | 1814.488
AC8 | MGT228_TX0_P | 1814.757
AB5 | MGT228_TX1_N | 1810.362
AB6 | MGT228_TX1_P | 1811.086
AA7 | MGT228_TX2_N | 1811.714
AA8 | MGT228_TX2_P | 1811.938
Y5 | MGT228_TX3_N | 1809.797
Y6 | MGT228_TX3_P | 1809.883
AA11 | MGT229_CLK0_N | 1420.478
AA12 | MGT229_CLK0_P | 1421.222
Y9 | MGT229_CLK1_N | 1433.301
Y10 | MGT229_CLK1_P | 1434.003
W3 | MGT229_RX0_N | 1793.618
W4 | MGT229_RX0_P | 1793.464
V1 | MGT229_RX1_N | 1796.821
V2 | MGT229_RX1_P | 1796.894
U3 | MGT229_RX2_N | 1787.04
U4 | MGT229_RX2_P | 1787.394
T1 | MGT229_RX3_N | 1792.101
T2 | MGT229_RX3_P | 1792.53
W7 | MGT229_TX0_N | 1678.871
W8 | MGT229_TX0_P | 1679.105
V5 | MGT229_TX1_N | 1685.07
V6 | MGT229_TX1_P | 1685.343
U7 | MGT229_TX2_N | 1680.852
U8 | MGT229_TX2_P | 1680.951
T5 | MGT229_TX3_N | 1685.272
T6 | MGT229_TX3_P | 1685.467
W11 | MGT230_CLK0_N | 1309.421
W12 | MGT230_CLK0_P | 1308.152
V9 | MGT230_CLK1_N | 1318.284
V10 | MGT230_CLK1_P | 1314.608
R3 | MGT230_RX0_N | 1709.194
R4 | MGT230_RX0_P | 1709.74
P1 | MGT230_RX1_N | 1711.721
P2 | MGT230_RX1_P | 1711.922
N3 | MGT230_RX2_N | 1701.308
N4 | MGT230_RX2_P | 1701.453
M1 | MGT230_RX3_N | 1706.018
M2 | MGT230_RX3_P | 1706.454
R7 | MGT230_TX0_N | 1619.364
R8 | MGT230_TX0_P | 1619.095
P5 | MGT230_TX1_N | 1620.579
P6 | MGT230_TX1_P | 1620.144
N7 | MGT230_TX2_N | 1623.637
N8 | MGT230_TX2_P | 1623.998
M5 | MGT230_TX3_N | 1615.482
M6 | MGT230_TX3_P | 1616.627
U11 | MGT231_CLK0_N | 1685.677
U12 | MGT231_CLK0_P | 1686.112
T9 | MGT231_CLK1_N | 1515.163
T10 | MGT231_CLK1_P | 1515.83
L3 | MGT231_RX0_N | 1712.117
L4 | MGT231_RX0_P | 1712.077
K1 | MGT231_RX1_N | 1711.318
K2 | MGT231_RX1_P | 1711.406
J3 | MGT231_RX2_N | 1713.604
J4 | MGT231_RX2_P | 1714.029
H1 | MGT231_RX3_N | 1712.511
H2 | MGT231_RX3_P | 1712.886
L7 | MGT231_TX0_N | 1656.107
L8 | MGT231_TX0_P | 1656.962
K5 | MGT231_TX1_N | 1654.61
K6 | MGT231_TX1_P | 1655.233
J7 | MGT231_TX2_N | 1658.999
J8 | MGT231_TX2_P | 1658.966
H5 | MGT231_TX3_N | 1657.362
H6 | MGT231_TX3_P | 1657.872

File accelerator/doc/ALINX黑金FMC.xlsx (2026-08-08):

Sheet: FH9702
Pin Number | Signal Name | Z7
G2 | FMC_CLK1_M2C_P | #REF!
G3 | FMC_CLK1_M2C_N | #REF!
G6 | GO1_SDA | #REF!
G7 | GO1_SCL | #REF!
G9 | GO2_SDA | #REF!
G10 | GO2_SCL | #REF!
G12 | GO2_DB1P | #REF!
G13 | GO2_DB1N | #REF!
G15 | GO2_CKBP | #REF!
G16 | GO2_CKBN | #REF!
G18 | GO1_DB2P | #REF!
G19 | GO1_DB2N | #REF!
G21 | GO4_DB1P | #REF!
G22 | GO4_DB1N | #REF!
G24 | CSI0_D3P | #REF!
G25 | CSI0_D3N | #REF!
G27 | G1_SDA | #REF!
G28 | G1_SCL | #REF!
G30 | CSI2_CLK0P | #REF!
G31 | CSI2_CLK0N | #REF!
G33 | CSI2_D3P | #REF!
G34 | CSI2_D3N | #REF!
G36 | CSI2_D1P | #REF!
G37 | CSI2_D1N | #REF!
G39 | VADJ | #REF!
S1 | DGND | #REF!
S2 | DGND | #REF!
H2 | FMC_PRSNT | #REF!
H4 | FMC_CLK0_M2C_P | #REF!
H5 | FMC_CLK0_M2C_N | #REF!
H7 | GO3_SDA | #REF!
H8 | GO3_SCL | #REF!
H10 | GO4_SDA | #REF!
H11 | GO4_SCL | #REF!
H13 | GO2_DB0P | #REF!
H14 | GO2_DB0N | #REF!
H16 | GO1_DB1P | #REF!
H17 | GO1_DB1N | #REF!
H19 | GO1_DB0P | #REF!
H20 | GO1_DB0N | #REF!
H22 | FMC_LA19_P | #REF!
H23 | FMC_LA19_N | #REF!
H25 | CSI0_D2P | #REF!
H26 | CSI0_D2N | #REF!
H28 | GO4_DB2P | #REF!
H29 | GO4_DB2N | #REF!
H31 | GO4_DB3P | #REF!
H32 | GO4_DB3N | #REF!
H34 | CSI2_D2P | #REF!
H35 | CSI2_D2N | #REF!
H37 | CSI2_D0P | #REF!
H38 | CSI2_D0N | #REF!
H40 | VADJ | #REF!
J6 | G1_GPIO3_O | #REF!
J7 | G1_GPIO4_O | #REF!
J9 | G1_GPIO5_I | #REF!
J10 | G1_PWDN_N | #REF!
J12 | GO3_DB3P | #REF!
J13 | GO3_DB3N | #REF!
J15 | CSI1_D1P | #REF!
J16 | CSI1_D1N | #REF!
J18 | FMC_HA18_P | #REF!
J19 | FMC_HA18_N | #REF!
J21 | FMC_HA22_P | #REF!
J22 | FMC_HA22_N | #REF!
K7 | CSI1_D2P | #REF!
K8 | CSI1_D2N | #REF!
K10 | FMC_HA06_P | #REF!
K11 | FMC_HA06_N | #REF!
K13 | FMC_HA10_P | #REF!
K14 | FMC_HA10_N | #REF!
K16 | GO3_DB2P | #REF!
K17 | GO3_DB2N | #REF!
K19 | FMC_HA21_P | #REF!
K20 | FMC_HA21_N | #REF!
E2 | FMC_HA01_CC_P | #REF!
E3 | FMC_HA01_CC_N | #REF!
E6 | CSI1_CLK0P | #REF!
E7 | CSI1_CLK0N | #REF!
E9 | GO3_DB1P | #REF!
E10 | GO3_DB1N | #REF!
E12 | GO1_GPIO3_O | #REF!
E13 | GO2_GPIO3_O | #REF!
E15 | CSI1_D0P | #REF!
E16 | CSI1_D0N | #REF!
E18 | GO3_GPIO3_O | #REF!
E19 | GO4_GPIO3_O | #REF!
F4 | GO3_CKBP | #REF!
F5 | GO3_CKBN | #REF!
F7 | CSI1_D3P | #REF!
F8 | CSI1_D3N | #REF!
F10 | GO3_DB0P | #REF!
F11 | GO3_DB0N | #REF!
F13 | FMC_HA12_P | #REF!
F14 | FMC_HA12_N | #REF!
F16 | FMC_HA15_P | #REF!
F17 | FMC_HA15_N | #REF!
F19 | FMC_HA19_P | #REF!
F20 | FMC_HA19_N | #REF!
C2 | FMC_DP0_C2M_P | #REF!
C3 | FMC_DP0_C2M_N | #REF!
C6 | FMC_DP0_M2C_P | #REF!
C7 | FMC_DP0_M2C_N | #REF!
C10 | GO2_DB3P | #REF!
C11 | GO2_DB3N | #REF!
C14 | POC_SDA | #REF!
C15 | POC_SCL | #REF!
C18 | GO1_CKBP | #REF!
C19 | GO1_CKBN | #REF!
C22 | GO4_CKBP | #REF!
C23 | GO4_CKBN | #REF!
C26 | CSI0_D0P | #REF!
C27 | CSI0_D0N | #REF!
C30 | FMC_SCL | #REF!
C31 | FMC_SDA | #REF!
C34 | GA0 | #REF!
C35 | +12V | #REF!
C37 | +12V | #REF!
D4 | FMC_GBTCLK0_M2C_P | #REF!
D5 | FMC_GBTCLK0_M2C_N | #REF!
D8 | GO3_PWDN_B | #REF!
D9 | GO4_PWDN_B | #REF!
D11 | GO1_PWDN_B | #REF!
D12 | GO2_PWDN_B | #REF!
D14 | GO2_DB2P | #REF!
D15 | GO2_DB2N | #REF!
D17 | GO1_DB3P | #REF!
D18 | GO1_DB3N | #REF!
D20 | GO4_DB0P | #REF!
D21 | GO4_DB0N | #REF!
D23 | CSI0_D1P | #REF!
D24 | CSI0_D1N | #REF!
D26 | CSI0_CLK0P | #REF!
D27 | CSI0_CLK0N | #REF!

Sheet: PA1296
FMC管脚序号 | 网络名 | FPGA芯片管脚
C35 | +12V
C37 | +12V
D32 | +3.3V
H5 | FMC_CLK0_N | K3
H4 | FMC_CLK0_P | K4
G3 | FMC_CLK1_N | H8
G2 | FMC_CLK1_P | H9
C3 | FMC_DP0_C2M_N
C2 | FMC_DP0_C2M_P
C7 | FMC_DP0_M2C_N
C6 | FMC_DP0_M2C_P
D5 | FMC_GBTCLK0_M2C_N
D4 | FMC_GBTCLK0_M2C_P
G7 | FMC_LA00_CC_N | L2
G6 | FMC_LA00_CC_P | L3
D9 | FMC_LA01_CC_N | H1
D8 | FMC_LA01_CC_P | J1
H8 | FMC_LA02_N | H3
H7 | FMC_LA02_P | H4
G10 | FMC_LA03_N | L8
G9 | FMC_LA03_P | M8
H11 | FMC_LA04_N | K1
H10 | FMC_LA04_P | L1
D12 | FMC_LA05_N | J2
D11 | FMC_LA05_P | K2
C11 | FMC_LA06_N | T8
C10 | FMC_LA06_P | R8
H14 | FMC_LA07_N | T7
H13 | FMC_LA07_P | R7
G13 | FMC_LA08_N | V8
G12 | FMC_LA08_P | U8
D15 | FMC_LA09_N | V9
D14 | FMC_LA09_P | U9
C15 | FMC_LA10_N | T6
C14 | FMC_LA10_P | R6
H17 | FMC_LA11_N | J9
H16 | FMC_LA11_P | K9
G16 | FMC_LA12_N | Y8
G15 | FMC_LA12_P | W8
D18 | FMC_LA13_N | H6
D17 | FMC_LA13_P | J6
C19 | FMC_LA14_N | J4
C18 | FMC_LA14_P | J5
H20 | FMC_LA15_N | K7
H19 | FMC_LA15_P | K8
G19 | FMC_LA16_N | H7
G18 | FMC_LA16_P | J7
D21 | FMC_LA17_CC_N | L5
D20 | FMC_LA17_CC_P | M6
C23 | FMC_LA18_CC_N | L6
C22 | FMC_LA18_CC_P | L7
H23 | FMC_LA19_N | F5
H22 | FMC_LA19_P | G5
G22 | FMC_LA20_N | P6
G21 | FMC_LA20_P | P7
H26 | FMC_LA21_N | E3
H25 | FMC_LA21_P | E4
G25 | FMC_LA22_N | F3
G24 | FMC_LA22_P | G3
D24 | FMC_LA23_N | E2
D23 | FMC_LA23_P | F2
H29 | FMC_LA24_N | N8
H28 | FMC_LA24_P | N9
G28 | FMC_LA25_N | C2
G27 | FMC_LA25_P | C3
D27 | FMC_LA26_N | F1
D26 | FMC_LA26_P | G1
C27 | FMC_LA27_N | D1
C26 | FMC_LA27_P | E1
H32 | FMC_LA28_N | N6
H31 | FMC_LA28_P | N7
G31 | FMC_LA29_N | B1
G30 | FMC_LA29_P | C1
H35 | FMC_LA30_N | A3
H34 | FMC_LA30_P | B3
G34 | FMC_LA31_N | A4
G33 | FMC_LA31_P | B4
H38 | FMC_LA32_N | A1
H37 | FMC_LA32_P | A2
G37 | FMC_LA33_N | C4
G36 | FMC_LA33_P | D4
H2 | FMC_PRSNT | C12
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

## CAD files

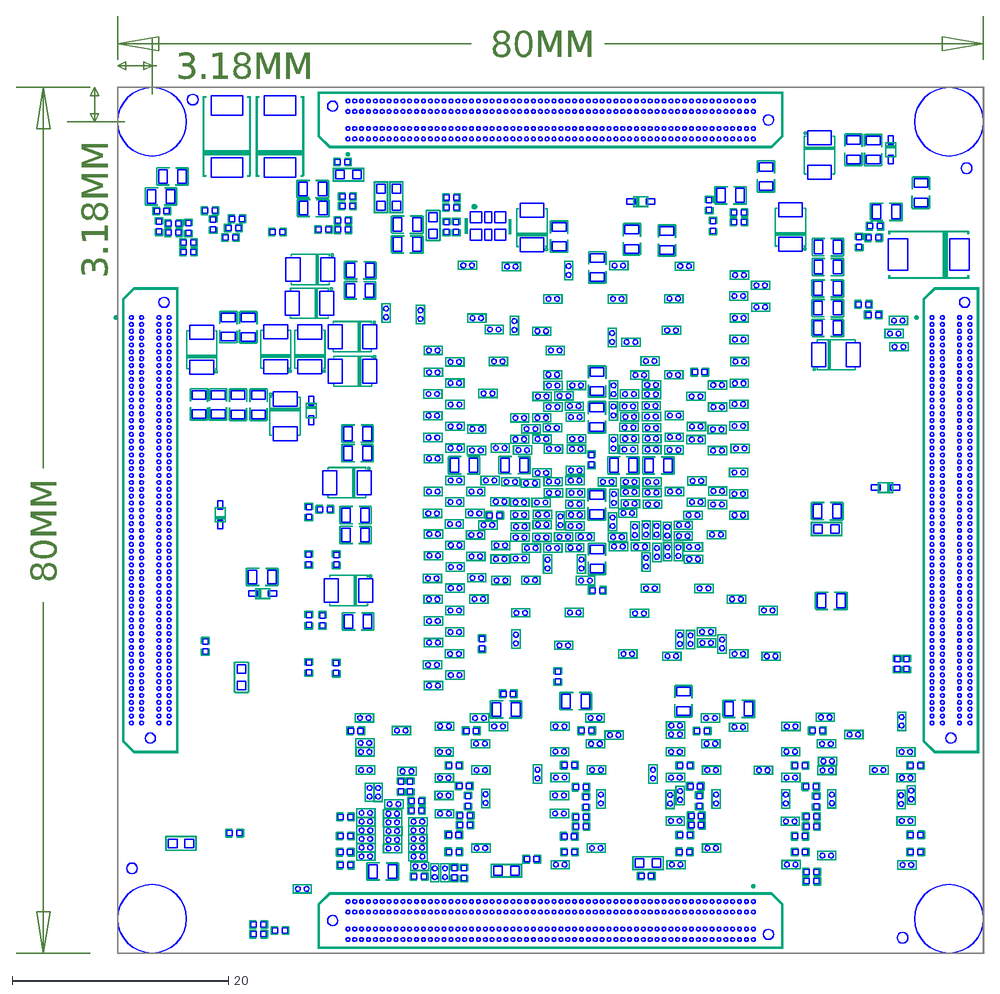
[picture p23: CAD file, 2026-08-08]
01_原理图PCB结构图等硬件资料/ACKU15尺寸图-BOT.dxf
3.18MM
80MM

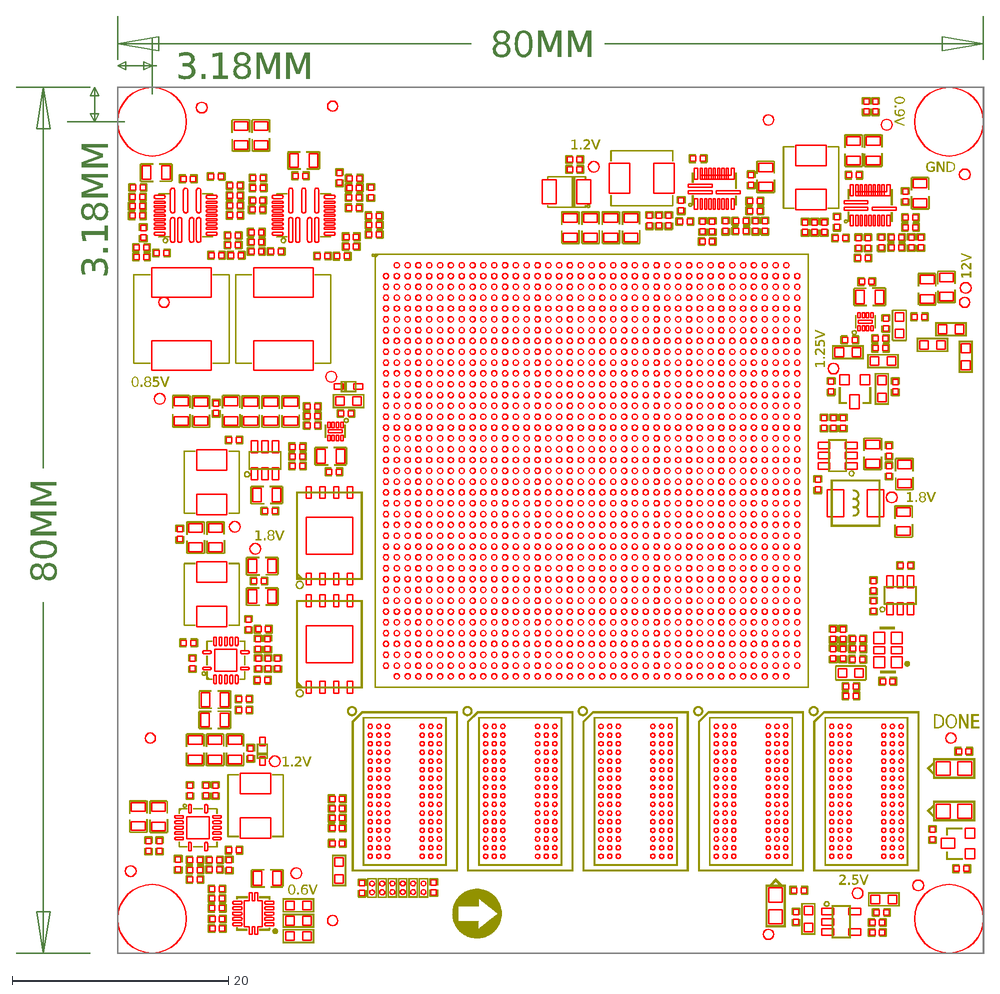
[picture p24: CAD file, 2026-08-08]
01_原理图PCB结构图等硬件资料/ACKU15尺寸图-TOP.dxf
3.18MM
80MM
DONE
GND
2.5V
0.6V
1.2V
0.9V
12V
1.25V
1.8V
0.85V

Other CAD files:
01_原理图PCB结构图等硬件资料/AXKU15尺寸图-TOP.dxf

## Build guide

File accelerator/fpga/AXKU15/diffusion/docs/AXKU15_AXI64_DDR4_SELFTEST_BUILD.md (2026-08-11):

# AXKU15 AXI64 DDR4 self-test build

## Inputs and ownership

The harness is deliberately outside the official demo directory. Normal
validation requires the project-owned Vivado 2024.2 IP copy:

- `ip/ddr4_core_2024_2/ddr4_core.xci`, its sibling `ddr4_core.dcp`,
  `par/ddr4_core.xdc`, and `manifest.json`;
- the board DDR4 XDC supplied by the official demo as a read-only input;
- generated `Axi64DdrSelfTest.v` from this repository.

The official demo XCI is only an input to the copy-and-upgrade command below;
it is never modified. The self-test Tcl flow rejects an XCI without the
project-owned DCP, IP XDC, and manifest. Generated IP products remain ignored
by Git; only the upgraded XCI and manifest are versioned.
## Generate the self-test RTL

```powershell
Set-Location accelerator
$env:SBT_OPTS='-Dsbt.server.autostart=false'
sbt 'runMain FLOOD_Accelerator.diffusion.GenerateAxi64DdrSelfTestVerilog'
```

The default output is
`target/generated/axi64-ddr4-selftest/Axi64DdrSelfTest.v`.

## Create or refresh the owned IP copy

```powershell
$official = 'D:\work-yanjiusheng\graduate\01_demo_document\01_demo_document\demo\ddr_test\ddr_test\ddr_test.srcs\sources_1\ip\ddr4_core\ddr4_core.xci'
& 'C:\Xilinx\Vivado\2024.2\bin\vivado.bat' -mode batch `
  -source fpga/AXKU15/diffusion/scripts/upgrade_ddr4_core_2024_2.tcl `
  -tclargs -source-xci $official `
  -output-dir fpga/AXKU15/diffusion/ip/ddr4_core_2024_2
Get-Content fpga/AXKU15/diffusion/ip/ddr4_core_2024_2/manifest.json
```

The command copies the XCI, upgrades the copy, generates its OOC DCP with
`synth_ip`, and writes all generated products below the owned IP directory.

## Elaboration-only check

```powershell
vivado -mode batch -source fpga/AXKU15/diffusion/scripts/build_axi64_ddr4_selftest.tcl -tclargs `
  -ddr4-xci fpga/AXKU15/diffusion/ip/ddr4_core_2024_2/ddr4_core.xci `
  -ddr4-xdc <official-demo/ddr4_test.xdc> `
  -selftest-rtl target/generated/axi64-ddr4-selftest/Axi64DdrSelfTest.v
```

Without `-run-impl`, the Tcl flow attaches the owned OOC DCP at
`u_ddr4_core/inst`, reads the generated IP XDC, then stops after
`synth_design -rtl`. This checks the wrapper/interface composition but does not
produce a bitstream. Add `-run-impl` only to request synthesis, placement,
routing, reports, checkpoint, and bitstream generation.
## Interpretation and LED status

| LED | Meaning |
| --- | --- |
| 0 | `c0_init_calib_complete` is high |
| 1 | self-test has started and is waiting for AXI completion |
| 2 | matching 512-bit readback passed |
| 3 | AXI response error or readback mismatch |

An elaboration or implementation result is only tool-flow evidence.  A board
must still be explicitly programmed and observed: LED0 alone indicates
calibration, while LED2 is the write/read transport result.  The existing
64-bit demo versus documented 80-bit/DRAM-part discrepancy remains an
unresolved physical validation condition.

## Verified elaboration evidence

On 2026-08-11, Vivado 2024.2 upgraded the project-owned copy from DDR4 IP
revision 17 to revision 24 and generated its OOC DCP with `synth_ip`.
The non-`-run-impl` self-test flow attached that DCP explicitly and completed
`synth_design -rtl` with **0 critical warnings and 0 errors**; no implementation
or bitstream was requested.

The log contains 101 ordinary warnings. The decisive board gate remains: the
XDC has unmatched DQ64--79/DQS8--9 constraints while the core exports only
64 DQ/8 DQS. This result validates tool-version-compatible IP, DCP attachment,
and wrapper composition only. It does not establish DDR4 calibration, timing
closure, or readback on a board.

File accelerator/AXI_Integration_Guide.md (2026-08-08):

# E203 AXI接口集成指南

## 1. ICB总线接口位置分析

### 1.1 E203 ICB总线架构
E203处理器使用ICB（Internal Chip Bus）作为片内总线，核心的ICB接口位于：

- **CPU核心到BIU**：`rtl/e203/core/e203_biu.v`
- **BIU分路器**：将ICB请求分发到不同目标
- **ICB转换器**：`rtl/e203/general/sirv_gnrl_icbs.v`

### 1.2 现有ICB分路目标
BIU中的ICB分路器当前支持以下目标：
1. `ifuerr_icb` - IFU错误处理
2. `ppi_icb` - 私有外设接口  
3. `clint_icb` - 核心本地中断控制器
4. `plic_icb` - 平台级中断控制器
5. `fio_icb` - 快速I/O（可选）
6. `mem_icb` - 内存接口（可选）

## 2. 添加AXI接口的具体步骤

### 2.1 方案1：在BIU层添加（推荐）

#### 步骤1：修改宏定义
在`rtl/e203/core/config.v`中添加：
```verilog
// 启用AXI接口
`define E203_HAS_AXI_ITF
```

#### 步骤2：修改BIU模块端口
在`rtl/e203/core/e203_biu.v`的模块声明中添加：
```verilog
`ifdef E203_HAS_AXI_ITF //{
//////////////////////////////////////////////////////////////
// AXI Master Interface
input [`E203_ADDR_SIZE-1:0]    axi_region_indic,
input                          axi_icb_enable,

// AXI4 Master接口
output                         m_axi_awvalid,
input                          m_axi_awready,
output [`E203_ADDR_SIZE-1:0]   m_axi_awaddr,
output [3:0]                   m_axi_awcache,
output [2:0]                   m_axi_awprot,
output [1:0]                   m_axi_awlock,
output [1:0]                   m_axi_awburst,
output [3:0]                   m_axi_awlen,
output [2:0]                   m_axi_awsize,

output                         m_axi_wvalid,
input                          m_axi_wready,
output [`E203_XLEN-1:0]        m_axi_wdata,
output [`E203_XLEN/8-1:0]      m_axi_wstrb,
output                         m_axi_wlast,

input                          m_axi_bvalid,
output                         m_axi_bready,
input  [1:0]                   m_axi_bresp,

output                         m_axi_arvalid,
input                          m_axi_arready,
output [`E203_ADDR_SIZE-1:0]   m_axi_araddr,
output [3:0]                   m_axi_arcache,
output [2:0]                   m_axi_arprot,
output [1:0]                   m_axi_arlock,
output [1:0]                   m_axi_arburst,
output [3:0]                   m_axi_arlen,
output [2:0]                   m_axi_arsize,

input                          m_axi_rvalid,
output                         m_axi_rready,
input  [`E203_XLEN-1:0]        m_axi_rdata,
input  [1:0]                   m_axi_rresp,
input                          m_axi_rlast,
`endif//}
```

#### 步骤3：修改分路器数量
在BIU中找到分路器数量定义（大约第230行）：
```verilog
`ifdef E203_HAS_AXI_ITF //{
    localparam BIU_SPLT_I_NUM_3 = (BIU_SPLT_I_NUM_2 + 1);
`else//}{
    localparam BIU_SPLT_I_NUM_3 = BIU_SPLT_I_NUM_2;
`endif//}

localparam BIU_SPLT_I_NUM = BIU_SPLT_I_NUM_3;
```

#### 步骤4：添加AXI ICB信号
```verilog
`ifdef E203_HAS_AXI_ITF //{
wire                         axi_icb_cmd_valid;
wire                         axi_icb_cmd_ready;
wire [`E203_ADDR_SIZE-1:0]   axi_icb_cmd_addr; 
wire                         axi_icb_cmd_read; 
wire [`E203_XLEN-1:0]        axi_icb_cmd_wdata;
wire [`E203_XLEN/8-1:0]      axi_icb_cmd_wmask;
wire [1:0]                   axi_icb_cmd_burst;
wire [1:0]                   axi_icb_cmd_beat;
wire                         axi_icb_cmd_lock;
wire                         axi_icb_cmd_excl;
wire [1:0]                   axi_icb_cmd_size;

wire                         axi_icb_rsp_valid;
wire                         axi_icb_rsp_ready;
wire                         axi_icb_rsp_err  ;
wire                         axi_icb_rsp_excl_ok;
wire [`E203_XLEN-1:0]        axi_icb_rsp_rdata;
`endif//}
```

#### 步骤5：修改分路器信号分配
找到分路器信号分配（大约第610行），在每个assign语句中添加AXI接口：
```verilog
assign {
         ifuerr_icb_cmd_valid
       , ppi_icb_cmd_valid
       , clint_icb_cmd_valid
       , plic_icb_cmd_valid
       `ifdef E203_HAS_FIO //{
       , fio_icb_cmd_valid
       `endif//}
       `ifdef E203_HAS_MEM_ITF //{
       , mem_icb_cmd_valid
       `endif//}
       `ifdef E203_HAS_AXI_ITF //{
       , axi_icb_cmd_valid
       `endif//}
       } = splt_bus_icb_cmd_valid;
```

#### 步骤6：修改地址译码逻辑
找到地址译码逻辑（大约第856行）：
```verilog
wire [BIU_SPLT_I_NUM-1:0] buf_icb_splt_indic =
{
   `ifdef E203_HAS_AXI_ITF //{
   (arbt_icb_cmd_addr[`E203_ADDR_SIZE-1:`E203_ADDR_SIZE-8] == axi_region_indic[`E203_ADDR_SIZE-1:`E203_ADDR_SIZE-8]) & axi_icb_enable,
   `endif//}
   // ... 其他接口的地址译码 ...
};
```

#### 步骤7：实例化ICB到AXI转换器
在BIU中添加转换器实例：
```verilog
`ifdef E203_HAS_AXI_ITF //{
sirv_gnrl_icb2axi # (
  .AXI_FIFO_DP         (2),
  .AXI_FIFO_CUT_READY  (1),
  .AW                  (`E203_ADDR_SIZE),
  .FIFO_OUTS_NUM       (8),
  .FIFO_CUT_READY      (0),
  .DW                  (`E203_XLEN)
) u_axi_icb2axi (
  .i_icb_cmd_valid     (axi_icb_cmd_valid),
  .i_icb_cmd_ready     (axi_icb_cmd_ready),
  .i_icb_cmd_read      (axi_icb_cmd_read ),
  .i_icb_cmd_addr      (axi_icb_cmd_addr ),
  .i_icb_cmd_wdata     (axi_icb_cmd_wdata),
  .i_icb_cmd_wmask     (axi_icb_cmd_wmask),
  .i_icb_cmd_size      (axi_icb_cmd_size ),

  .i_icb_rsp_valid     (axi_icb_rsp_valid),
  .i_icb_rsp_ready     (axi_icb_rsp_ready),
  .i_icb_rsp_err       (axi_icb_rsp_err  ),
  .i_icb_rsp_rdata     (axi_icb_rsp_rdata),

  .o_axi_arvalid       (m_axi_arvalid),
  .o_axi_arready       (m_axi_arready),
  .o_axi_araddr        (m_axi_araddr ),
  .o_axi_arcache       (m_axi_arcache),
  .o_axi_arprot        (m_axi_arprot ),
  .o_axi_arlock        (m_axi_arlock ),
  .o_axi_arburst       (m_axi_arburst),
  .o_axi_arlen         (m_axi_arlen  ),
  .o_axi_arsize        (m_axi_arsize ),

  .o_axi_awvalid       (m_axi_awvalid),
  .o_axi_awready       (m_axi_awready),
  .o_axi_awaddr        (m_axi_awaddr ),
  .o_axi_awcache       (m_axi_awcache),
  .o_axi_awprot        (m_axi_awprot ),
  .o_axi_awlock        (m_axi_awlock ),
  .o_axi_awburst       (m_axi_awburst),
  .o_axi_awlen         (m_axi_awlen  ),
  .o_axi_awsize        (m_axi_awsize ),

  .o_axi_rvalid        (m_axi_rvalid ),
  .o_axi_rready        (m_axi_rready ),
  .o_axi_rdata         (m_axi_rdata  ),
  .o_axi_rresp         (m_axi_rresp  ),
  .o_axi_rlast         (m_axi_rlast  ),

  .o_axi_wvalid        (m_axi_wvalid ),
  .o_axi_wready        (m_axi_wready ),
  .o_axi_wdata         (m_axi_wdata  ),
  .o_axi_wstrb         (m_axi_wstrb  ),
  .o_axi_wlast         (m_axi_wlast  ),

  .o_axi_bvalid        (m_axi_bvalid ),
  .o_axi_bready        (m_axi_bready ),
  .o_axi_bresp         (m_axi_bresp  ),

  .clk                 (clk),
  .rst_n               (rst_n)
);
`endif//}
```

### 2.2 修改上层模块

#### 修改CPU模块
在`rtl/e203/core/e203_cpu.v`中添加AXI接口端口并连接到BIU。

#### 修改子系统模块
在`rtl/e203/subsys/e203_subsys_main.v`中添加AXI接口端口。

#### 修改顶层模块
在`rtl/e203/soc/e203_soc_top.v`或您的顶层模块中暴露AXI接口。

## 3. 地址空间配置

根据您之前的需求，配置AXI地址空间为`0x4000_0000 ~ 0x4FFF_FFFF`：

```verilog
// 在CPU实例化时配置
.axi_region_indic (32'h4000_0000),
.axi_icb_enable   (1'b1),
```

## 4. 验证和调试

### 4.1 添加调试信号
```verilog
// 在BIU中添加调试信号
wire axi_access = (arbt_icb_cmd_addr[31:28] == 4'h4) & arbt_icb_cmd_valid & arbt_icb_cmd_ready;
```

### 4.2 仿真验证
1. 创建测试用例访问AXI地址空间
2. 验证ICB到AXI的转换正确性
3. 检查时序和握手信号

## 5. 参数配置建议

### 5.1 ICB2AXI转换器参数
```verilog
.AXI_FIFO_DP         (2),        // AXI管线深度
.AXI_FIFO_CUT_READY  (1),        // 切断ready信号
.FIFO_OUTS_NUM       (8),        // Outstanding事务数
.FIFO_CUT_READY      (0),        // ICB FIFO ready信号
.DW                  (32)        // 数据宽度（32位）
```

### 5.2 地址译码位宽
使用高8位进行地址译码（[31:24]），支持256MB地址空间粒度。

## 6. 注意事项

1. **时钟域**：确保AXI接口与CPU核心同时钟
2. **复位同步**：AXI接口需要同步复位
3. **Outstanding事务**：根据外部AXI从设备能力配置
4. **数据宽度**：E203为32位，确保AXI接口匹配
5. **地址对齐**：注意AXI访问的地址对齐要求

通过以上步骤，您就可以成功将AXI接口集成到E203处理器中，并将其连接到外部AXI总线系统。

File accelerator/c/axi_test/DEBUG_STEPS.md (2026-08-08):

# 仿真问题诊断和修复步骤

## 问题描述
- PC卡在 `0x00001000`，未跳转到ITCM (`0x80000000`)
- 程序执行超时
- 文件加载警告（第4099行）

---

## 步骤1：验证文件格式和内容

### 1.1 检查 verilog 文件格式
```bash
cd c/axi_test
# 检查文件行数
wc -l axi_test.verilog

# 检查文件中的地址标记
grep "^@" axi_test.verilog

# 检查文件末尾是否有格式问题
tail -20 axi_test.verilog
```

**预期结果：**
- 文件应该有4个地址标记：`@00000000`, `@000000BC`, `@00002370`, `@0000262C`
- 文件末尾应该是正常的数据行，没有空行或格式错误

### 1.2 验证文件中的数据
```bash
# 查看文件前几行，确认数据格式正确
head -20 axi_test.verilog
```

**预期格式：**
```
@00000000
73 70 04 30 73 50 40 30 97 11 00 10 93 81 81 85
...
```

---

## 步骤2：检查ITCM加载的数据

### 2.1 修改testbench添加详细调试信息

编辑 `tb/tb_top.v`，在加载数据后添加更多调试输出：

```verilog
// 在第352行之后添加
$display("=== ITCM加载验证 ===");
$display("ITCM数组大小: %d", `E203_ITCM_RAM_DP);
$display("ITCM[0] (对应PC=0x80000000): 0x%016h", `ITCM.mem_r[0]);
$display("ITCM[1] (对应PC=0x80000008): 0x%016h", `ITCM.mem_r[1]);
$display("ITCM[2] (对应PC=0x80000010): 0x%016h", `ITCM.mem_r[2]);

// 验证地址映射
$display("=== 地址映射验证 ===");
$display("PC=0x80000000 -> ITCM索引=%d", 32'h80000000[13:3]);
$display("PC=0x00001000 -> ITCM索引=%d", 32'h00001000[13:3]);
```

### 2.2 重新编译和运行仿真
```bash
# 重新编译（如果需要）
cd vsim/run
make clean
make

# 运行仿真并查看输出
# 注意观察ITCM加载的数据是否正确
```

**检查点：**
- ITCM[0] 应该包含程序的第一个64位指令
- 确认数据不是全0或全X

---

## 步骤3：检查MROM跳转逻辑

### 3.1 验证MROM代码
MROM应该包含跳转到ITCM的代码：
- 地址0: `auipc t0, 0x7ffff` (0x7ffff297)
- 地址4: `jr t0` (0x00028067)

### 3.2 添加MROM执行监控

在 `tb/tb_top.v` 中添加MROM访问监控：

```verilog
// 在initial块中添加
wire [`E203_PC_SIZE-1:0] mrom_pc;
assign mrom_pc = `CPU_TOP.u_e203_ifu.u_e203_ifu_ift2icb.ifu_req_pc;

always @(posedge hfclk) begin
    if (rst_n && (mrom_pc < 32'h00001000)) begin
        $display("MROM访问: PC=0x%08h", mrom_pc);
        if (mrom_pc == 32'h00000000) begin
            $display("  -> 执行MROM[0]: auipc t0, 0x7ffff");
        end
        if (mrom_pc == 32'h00000004) begin
            $display("  -> 执行MROM[1]: jr t0");
            $display("  -> 应该跳转到: 0x80000000");
        end
    end
end
```

### 3.3 检查跳转是否执行

**检查点：**
- MROM[0] 是否被执行
- MROM[1] 是否被执行
- PC是否从0x00000004跳转到0x80000000

---

## 步骤4：验证地址映射

### 4.1 理解地址映射关系

- **ITCM物理地址**: `0x80000000` ~ `0x8000FFFF` (64KB)
- **ITCM数组索引**: `0` ~ `8191` (64KB / 8字节 = 8192个64位字)
- **地址转换**: `PC[13:3]` 用于索引ITCM数组

**关键公式：**
```
ITCM索引 = (PC - 0x80000000) >> 3
         = PC[13:3]  (当PC在ITCM范围内)
```

### 4.2 验证PC=0x80000000的映射

```verilog
// 在testbench中添加
$display("PC=0x80000000的地址映射:");
$display("  PC[31:14] = 0x%05h (应该是0x20000)", 32'h80000000[31:14]);
$display("  PC[13:3]  = 0x%03h (应该是0x000)", 32'h80000000[13:3]);
$display("  -> ITCM索引 = %d", 32'h80000000[13:3]);
```

**预期结果：**
- PC=0x80000000 -> ITCM索引=0
- PC=0x80000008 -> ITCM索引=1
- PC=0x80000010 -> ITCM索引=2

---

## 步骤5：检查CPU复位和启动流程

### 5.1 验证复位地址

E203 CPU复位后应该从 `0x00000000` 开始执行（MROM）。

### 5.2 添加复位监控

```verilog
// 监控复位和PC变化
reg [31:0] last_pc;
always @(posedge hfclk) begin
    if (rst_n == 1'b0) begin
        last_pc <= 32'hFFFFFFFF;
        $display("=== CPU复位 ===");
    end
    else if (pc_vld && (pc != last_pc)) begin
        $display("PC变化: 0x%08h -> 0x%08h", last_pc, pc);
        last_pc <= pc;
        
        // 检查是否卡在某个地址
        if (pc == 32'h00001000) begin
            $display("警告: PC卡在0x00001000!");
            $display("  当前指令: 0x%016h", `ITCM.mem_r[pc[13:3]]);
        end
    end
end
```

---

## 步骤6：修复方案

### 方案A：如果MROM跳转未执行

**可能原因：**
1. MROM代码错误
2. 跳转指令执行失败
3. 地址映射问题

**解决方法：**
1. 检查 `rtl/e203/mems/sirv_mrom.v` 中的跳转代码
2. 确认MROM地址映射正确
3. 检查CPU的指令执行路径

### 方案B：如果ITCM数据未正确加载

**可能原因：**
1. `$readmemh` 读取失败
2. 地址偏移计算错误
3. 数据格式不匹配

**解决方法：**
1. 检查 `axi_test.verilog` 文件格式
2. 确认 `$readmemh` 正确解析地址标记
3. 验证数据加载到正确的数组索引

### 方案C：如果地址映射错误

**可能原因：**
1. ITCM地址基址配置错误
2. PC地址计算错误

**解决方法：**
1. 检查 `rtl/e203/core/config.v` 中的 `E203_CFG_ITCM_ADDR_BASE`
2. 确认地址译码逻辑正确
3. 验证PC到ITCM索引的转换

---

## 步骤7：重新生成verilog文件（如果需要）

### 7.1 检查链接脚本
```bash
cd c/axi_test
cat link.ld | grep ORIGIN
```

**预期：**
- ITCM ORIGIN = 0x80000000

### 7.2 重新编译
```bash
make clean
make all
make sim
```

### 7.3 检查生成的verilog文件
```bash
head -5 axi_test.verilog
# 应该看到 @00000000（这是LMA，不是VMA）
```

**注意：** `objcopy -O verilog` 生成的是LMA（Load Memory Address），不是VMA（Virtual Memory Address）。虽然链接脚本定义VMA为0x80000000，但objcopy可能生成从0x00000000开始的地址。这是正常的，因为testbench会将数据加载到ITCM数组索引0，而ITCM物理地址是0x80000000。

---

## 步骤8：最终验证

### 8.1 运行完整仿真
```bash
cd vsim/run
# 运行仿真
# 观察输出日志
```

### 8.2 检查关键指标

1. **MROM执行：**
   - PC从0x00000000开始
   - 执行MROM[0]和MROM[1]
   - 跳转到0x80000000

2. **ITCM加载：**
   - ITCM[0]包含有效指令
   - 数据不是全0或全X

3. **程序执行：**
   - PC跳转到0x80000000
   - 执行ITCM中的指令
   - 程序正常运行

---

## 常见问题排查

### Q1: PC一直卡在0x00001000
**可能原因：**
- MROM跳转未执行
- ITCM地址映射错误
- CPU执行路径问题

**解决方法：**
- 检查MROM代码
- 验证地址映射
- 添加更多调试信息

### Q2: ITCM数据全0或全X
**可能原因：**
- 文件加载失败
- 地址偏移错误
- 数据格式问题

**解决方法：**
- 检查文件格式
- 验证加载逻辑
- 添加数据验证

### Q3: 文件加载警告
**可能原因：**
- 文件格式错误
- 地址标记问题
- 数据行格式错误

**解决方法：**
- 检查文件格式
- 验证地址标记
- 检查数据行

---

## 调试技巧

1. **使用波形查看器：**
   - 查看PC信号变化
   - 查看ITCM数据
   - 查看MROM访问

2. **添加断点：**
   - 在关键地址设置断点
   - 观察寄存器值
   - 检查内存内容

3. **逐步调试：**
   - 先验证文件加载
   - 再验证MROM执行
   - 最后验证程序执行

---

## 联系信息

如果问题仍未解决，请提供：
1. 完整的仿真日志
2. ITCM加载的数据
3. PC执行轨迹
4. 相关配置文件

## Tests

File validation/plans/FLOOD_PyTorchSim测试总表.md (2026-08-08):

# FLOOD HPCA 重投：PyTorchSim 测试总表

> 本表用于统一确认“从哪些方面测试、测试哪些对象、采集哪些数据”。  
> 具体执行方法见 [FLOOD_PyTorchSim测试执行方案.md](./FLOOD_PyTorchSim测试执行方案.md)，结果填写见 [FLOOD_HPCA测试结果清单.md](./FLOOD_HPCA测试结果清单.md)。

## 一、完整测试表

| 编号 | 测试方面 | 测试目的 | 测试对象/模型 | 对比配置 | 需要采集的数据 |
|---|---|---|---|---|---|
| T1 | 端到端性能 | 证明 FLOOD 对 Diffusion 推理整体有效 | SD v1.5 UNet、VAE、DiT-B/4、DiT-S/4 | Base FLOOD、Full FLOOD、DiT-Accel-like、通用 systolic baseline | latency、throughput、speedup、energy、power、EDP、compute utilization、DRAM traffic、SRAM traffic、stall cycles |
| T2 | 算子级性能分解 | 确定 FLOOD 在不同算子上的收益来源 | Conv2d、Linear/GEMM、BMM、Softmax、Norm、Activation | Base vs Full；FLOOD-only vs PLANE-only | per-op cycles、compute cycles、memory cycles、stall cycles、op latency 占比、op energy 占比、MAC utilization |
| T3 | 稀疏分布统计 | 证明 Diffusion workload 中存在可利用的真实稀疏性 | SD UNet、VAE、DiT-B/4，不同 timestep | 原始模型 trace | activation sparsity、weight sparsity、32-channel group sparsity、layer-wise sparsity、timestep-wise sparsity、可跳过 MAC 比例 |
| T4 | 细粒度跳零收益 | 证明 zero skipping、adder pruning 和 GCSE 能转化为周期及能耗收益 | SD UNet、DiT-B/4 | Dense、ValueSkip、ValueSkip+AdderPrune、GCSE、FullSparse | skipped MAC ratio、cycle reduction、energy reduction、power reduction、SRAM traffic reduction、NoC traffic reduction、metadata overhead |
| T5 | GCSE 结构化稀疏 | 证明 channel-group sparsity 能减少取数和控制开销 | Conv 层、Linear 层、SD UNet 重点层 | no GCSE、GCSE group=8/16/32/64 | group sparsity、bitmap size、bitmap fetch cycles、weight SRAM access reduction、NoC traffic reduction、latency reduction、energy reduction |
| T6 | 混合精度收益 | 证明 INT4/INT8 mixed precision 存在性能与质量的最优点 | SD UNet、DiT-B/4、CelebA-HQ/FFHQ 子集 | FP16、INT8 all、INT4 all、10%/30%/50%/70% INT4、sensitivity-based mixed | latency、throughput、energy、peak memory、DRAM traffic、quality drop、FID、CLIP Score、PSNR、SSIM、LPIPS |
| T7 | Outlier bypass | 证明 outlier 模块能以低硬件成本恢复量化质量 | SD UNet、DiT-B/4、CelebA-HQ | INT8 truncation、mixed w/o outlier、mixed+outlier、wide-MAC baseline | outlier ratio、outlier collision ratio、extra cycles、queue occupancy、PSNR、SSIM、LPIPS、FID、extra area、extra power |
| T8 | Softmax 支持 | 证明 DiT/Attention 中 Softmax 的硬件近似精度与性能可接受 | DiT-B/4、DiT-S/4、SD UNet attention | FP16 Softmax、I-BERT-like、linear attention、FLOOD INT8 Softmax | vector length、Softmax latency、approximation error、KL divergence、max error、energy、area、generation quality drop |
| T9 | 双 dataflow 选择 | 证明 FLOOD/PLANE 自适应切换对混合 Conv/Matrix workload 必要 | SD UNet、VAE、DiT-B/4 | FLOOD-only、PLANE-only、rule-based adaptive、oracle adaptive、wrong mapping | selected dataflow per layer、switch count、switch overhead、latency、stall cycles、buffer usage、bandwidth demand、utilization |
| T10 | 存储和带宽敏感性 | 证明 FLOOD 在有限片上存储和外部带宽下仍有效 | SD UNet、DiT-B/4、完整 LDM pipeline | 不同 SRAM size、不同 DRAM bandwidth | latency、stall ratio、DRAM traffic、SRAM traffic、NoC traffic、ping-pong margin、buffer occupancy、utilization |
| T11 | 系统级增量消融 | 分解每项机制带来的系统级收益 | SD UNet、DiT-B/4 | Base、+Sparse、+GCSE、+Mixed Precision、+Outlier、+Softmax、+Adaptive Dataflow、Full | latency、energy、utilization、memory traffic、quality drop、各模块增量收益 |
| T12 | Leave-one-out 消融 | 证明每个模块在完整系统中的必要性 | SD UNet、DiT-B/4 | Full、Full-GCSE、Full-Mixed Precision、Full-Outlier、Full-Softmax、Full-Adaptive Dataflow | latency loss、energy loss、utilization loss、quality loss、traffic increase |
| T13 | 错误组合反例 | 证明 co-design 的必要性，而非简单叠加机制 | SD UNet、DiT-B/4 | 高稀疏+错误 dataflow、高 INT4 无 outlier、只跳 MAC 不跳 weight fetch | latency penalty、energy penalty、quality drop、extra traffic、stall cycles、utilization drop |
| T14 | Timestep 敏感性 | 分析 Diffusion 不同阶段的稀疏、outlier 和性能变化 | SD UNet，不同 denoising step | early、middle、late timestep | activation sparsity、outlier ratio、layer latency、total latency、energy、selected precision、selected dataflow |
| T15 | 模型规模扩展 | 证明结果不是单一模型特例 | SD v1.5、VAE、DiT-S/4、DiT-B/4、可选 DiT-XL/2 | Base FLOOD vs Full FLOOD | latency、speedup、energy、utilization、traffic、quality metrics、参数量、MACs |
| T16 | Baseline 公平性 | 回应 baseline 配置不清楚和比较不公平的问题 | 所有主实验 | Base FLOOD、Full FLOOD、DiT-Accel-like、systolic baseline、software reference | 工艺、频率、面积、PE/MAC 数、SRAM、DRAM 带宽、精度、稀疏支持、Softmax 支持、dataflow、数据来源 |
| T17 | 面积与功耗开销 | 证明新增模块实现成本可控 | GCSE 控制、Outlier bypass、Softmax、dataflow switch logic | Base hardware vs Full hardware | area、area breakdown、power、power breakdown、critical path、frequency、extra registers、extra SRAM/metadata storage |
| T18 | 数据来源与复现性 | 保证 HPCA 版本实验结果可信且可追溯 | 全部实验 | PyTorchSim、RTL、FPGA、ASIC synthesis/P&R | simulator version、hardware config、model config、seed、input size、data source、config hash、CSV 原始数据、图表生成脚本 |

## 二、结合讨论手稿的优先级分类

讨论手稿中的实验逻辑可以归纳为三条创新主线：

1. **稀疏优化**：主动稀疏（GCSE）与被动稀疏（运行时 zero/slice skipping）；
2. **低成本量化**：INT4/INT8 可配置计算与高精度 outlier 补偿；
3. **架构扩展**：FLOOD/PLANE 双 dataflow、Softmax、片上存储和多核调度。

实验优先级不按实现难度划分，而按“是否直接支撑论文核心创新和主图”划分。

### P0：必须完成——直接支撑三项创新和论文主结论

| 类别 | 测试内容 | 对应测试 | 必须获得的数据 | 预期支撑 |
|---|---|---|---|---|
| 系统主结果 | 多模型下 FLOOD 与 Base/baseline 的端到端对比 | T1、T2 | latency、energy/power、utilization、speedup、traffic、stall cycles | 手稿中的端到端“大图”，支撑摘要核心数字 |
| 创新一：被动稀疏 | 运行时 zero skipping、adder pruning、无效 slice/group 跳过 | T3、T4 | activation/weight sparsity、skipped MAC、cycle reduction、power reduction | 证明真实稀疏能够转化为计算和功耗收益 |
| 创新一：主动稀疏 | GCSE 训练形成硬件对齐的 channel-group sparsity | T5 | group sparsity、bitmap overhead、SRAM/NoC reduction、latency、energy | 证明 GCSE 不只是普通非结构化剪枝 |
| 创新二：4/8-bit 量化 | INT4/INT8 可配置和 sensitivity-based mixed precision | T6 | INT4 layer ratio、latency、throughput、memory、FID/CLIP/PSNR/SSIM/LPIPS | 找到性能—生成质量 Pareto 最优点 |
| 创新二：高精度 outlier | 少量高精度 outlier 的旁路补偿 | T7 | outlier ratio、quality recovery、extra cycles、area、power | 证明不扩大主计算阵列也能维持质量 |
| 创新三：双 dataflow | FLOOD/PLANE 固定映射、自适应映射和错误映射 | T9 | per-layer dataflow、switch count、latency、utilization、wrong-mapping penalty | 证明 Conv/Matrix 混合负载需要自适应 dataflow |
| 创新三：存储调度 | Buffer、带宽、ping-pong 和多核调度 | T10 | buffer occupancy、bandwidth demand、traffic、stall ratio、ping-pong margin | 支撑手稿中的存储与调度设计 |
| 系统协同 | 三项创新的增量消融和完整系统结果 | T11 | Base 到 Full 的 latency、energy、utilization、traffic、quality 变化 | 回应“创新点只是简单拼装” |
| 实现开销 | 三项创新集成后的面积、功耗和时序 | T17 | area/power breakdown、critical path、frequency、模块开销 | 证明“低成本”和可实现性 |
| 实验可信度 | 固定硬件参数、统一数据源和 baseline 配置 | T16、T18 | 工艺、频率、MAC 数、SRAM、带宽、版本、config hash、数据来源 | 回应 MICRO 审稿中的公平性和可信度质疑 |

### P1：强烈建议——用于证明联合设计必要性

| 类别 | 测试内容 | 对应测试 | 需要获得的数据 | 主要作用 |
|---|---|---|---|---|
| 完整系统反向消融 | 从 Full FLOOD 中逐项移除 GCSE、量化、outlier、dataflow | T12 | latency/energy/utilization/quality 损失 | 证明每个模块在完整系统中不可替代 |
| 错误组合反例 | 高稀疏+错误 dataflow；高 INT4 无 outlier；只跳 MAC 不跳访存 | T13 | latency/energy penalty、quality drop、extra traffic | 最直接回应“已有技术拼装”的质疑 |
| Diffusion 阶段变化 | early/middle/late timestep 的稀疏和 outlier 变化 | T14 | timestep-wise sparsity、outlier、latency、precision/dataflow selection | 证明动态策略比固定策略更合理 |
| Softmax 支持 | 32–2048 长度下 INT8 Softmax 的性能和精度 | T8 | latency、energy、KL divergence、approximation error、质量下降 | 完善 DiT/attention 的端到端算子支持 |
| 模型扩展 | LDM 与不同规模 DiT 的结果 | T15 | speedup、energy、utilization、quality、traffic | 证明结果不是单一 UNet 模型特例 |

### P2：补充实验——用于增强完整性，不阻塞论文主线

| 类别 | 测试内容 | 对应测试或扩展项 | 需要获得的数据 | 使用位置 |
|---|---|---|---|---|
| 更大模型 | DiT-XL/2 或更大分辨率 Stable Diffusion | T15 扩展 | scaling trend、memory、latency、energy | 扩展性图或附录 |
| 大范围参数扫描 | 11×11 稀疏网格、更多 group size、更多 SRAM/带宽点 | T4、T5、T10 扩展 | heatmap 数据、敏感性曲线 | 机制图或附录 |
| 软件参考 | A100、TensorRT、xDiT、PipeFusion 等 | T16 扩展 | software latency、throughput、GPU 配置 | 单独参考，不与等资源硬件结果混比 |
| 通用模型验证 | CNN、ViT、BERT | 可选扩展 | throughput、accuracy、energy | 仅在仍保留“通用性”主张时使用 |
| 更多质量样本 | 扩大生成图像数量和数据集 | T6、T7 扩展 | FID、CLIP、LPIPS 置信区间 | 质量评估附录 |

## 三、按三项创新组织测试

### 创新一：主动与被动稀疏协同

| 层次 | 配置 | 重点数据 |
|---|---|---|
| 稀疏基础特征 | 原始 dense/pruned 模型 | 每层 activation、weight、channel-group sparsity |
| 被动稀疏 | ValueSkip | skipped MAC、动态功耗，不应夸大访存收益 |
| 被动稀疏增强 | ValueSkip + AdderPrune | adder activity、energy、critical path |
| 主动稀疏 | GCSE | group sparsity、bitmap、weight fetch、NoC traffic |
| 主动+被动 | GCSE + ValueSkip + AdderPrune | latency、energy、utilization、traffic |
| 参数选择 | group=8/16/32/64 | sparsity enrichment、metadata 和执行收益的权衡 |

必须区分：

- ValueSkip 主要减少无效计算和动态翻转；
- GCSE 可以进一步减少权重读取、NoC 传输和控制状态；
- 只有二者结合后，才能同时覆盖非结构化动态零值和结构化静态零组。

### 创新二：4/8-bit 量化与高精度 outlier

| 层次 | 配置 | 重点数据 |
|---|---|---|
| 精度基线 | FP16、INT8 all、INT4 all | latency、energy、memory、生成质量 |
| 固定比例混合 | 10%/30%/50%/70% INT4 | quality–performance 曲线 |
| 敏感度量化 | sensitivity-based INT4/INT8 | layer assignment、Pareto 最优点 |
| 无 outlier 补偿 | mixed w/o outlier | outlier 分布、质量损失 |
| 高精度补偿 | mixed + outlier bypass | quality recovery、extra cycles、queue collision |
| 高成本对照 | wide-MAC baseline | area、power、frequency、quality |

必须证明：

- INT4/INT8 的切换带来实际吞吐和访存收益；
- outlier 数量足够少，使共享高精度通路不会成为瓶颈；
- bypass 相比统一加宽 MAC 具有更好的面积/功耗收益。

### 创新三：FLOOD 架构、双 dataflow 与存储调度

| 层次 | 配置 | 重点数据 |
|---|---|---|
| 固定 dataflow | FLOOD-only、PLANE-only | Conv/Matrix 各自 latency、utilization、traffic |
| 自适应 dataflow | rule-based adaptive | 每层选择结果、端到端收益、切换次数 |
| 理想上界 | oracle adaptive | rule-based 与 oracle 的差距 |
| 错误映射 | wrong mapping | latency、stall、utilization penalty |
| 存储敏感性 | SRAM 0.5×/1×/2× | buffer occupancy、spill traffic、latency |
| 带宽敏感性 | 8/16/32/64 B/cycle | stall ratio、ping-pong margin、throughput |
| Softmax | vector length 32–2048 | latency、energy、误差和端到端质量 |

必须给出清晰的 dataflow 选择准则，例如依据算子类型、矩阵维度、数据复用、SRAM 容量和带宽压力进行选择。

## 四、数据类别汇总

| 数据类别 | 具体指标 |
|---|---|
| 性能 | latency、throughput、speedup、compute utilization、MAC utilization |
| 能耗 | energy、power、EDP、各模块 energy/power breakdown |
| 周期 | compute cycles、memory cycles、stall cycles、switch cycles、metadata cycles、outlier cycles |
| 访存 | DRAM traffic、SRAM traffic、NoC traffic、buffer occupancy、bandwidth demand |
| 稀疏 | activation sparsity、weight sparsity、group sparsity、skipped MAC ratio、bitmap overhead |
| 量化质量 | FID、CLIP Score、PSNR、SSIM、LPIPS、quality drop |
| Outlier | outlier ratio、collision ratio、queue occupancy、extra cycles、quality recovery |
| Dataflow | per-layer selection、switch count、switch overhead、wrong-mapping penalty |
| 硬件开销 | area、power、critical path、frequency、register/SRAM/metadata overhead |
| 公平性 | 工艺、频率、面积、MAC 数、SRAM、带宽、精度、baseline 功能支持 |
| 复现信息 | simulator version、config hash、model/input/seed、数据来源、原始 CSV |

## 五、数据来源标签

每项结果必须明确使用以下一种数据来源，禁止笼统标注为“实验结果”：

| 标签 | 含义 |
|---|---|
| PyTorch measurement | PyTorch 模型运行、质量评估或张量统计 |
| PyTorchSim cycle simulation | PyTorchSim 周期、利用率和活动统计 |
| RTL simulation | RTL 功能或功耗活动仿真 |
| FPGA measurement | FPGA 板级实测 |
| ASIC synthesis | ASIC 综合结果 |
| Post-layout estimate | 布局布线后估算 |
| Analytical estimate | 公式或解析模型估算 |
| Literature-reported | 直接引用已有论文公开结果 |

## 六、测试结果统一记录字段

```text
experiment_id
model
model_version
input_resolution
batch_size
diffusion_steps
seed
precision_config
sparsity_config
dataflow_config
hardware_config
baseline
latency
throughput
energy
power
utilization
dram_traffic
sram_traffic
noc_traffic
quality_metrics
data_source
simulator_version
config_hash
notes
```

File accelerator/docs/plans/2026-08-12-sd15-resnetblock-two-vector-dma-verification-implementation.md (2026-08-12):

# SD1.5 ResNetBlock Two-Vector AXI64 DMA Verification Implementation Plan

**Goal:** Add a directed AXI64 Chisel simulation that verifies two ordered
512-bit vectors traverse the existing ResNetBlock flow from two-beat DMA read
to two-beat writeback under independent channel backpressure.

**Architecture:** Production RTL remains unchanged. The test-side AXI64 memory
model gains accepted full-burst address history; a second test in the existing
ResNetBlock E2E suite drives public Decoupled controls with `vectors = 2`,
records output handshakes in order, and compares both stored words with the
integer reference.

**Tech Stack:** Scala 2.12.13, Chisel 3.5.3, chiseltest 0.5.3, ScalaTest,
SBT 1.12.15.

## Global constraints

- DUT: `new DiffusionAccelTop(memoryBackend = DiffusionMemoryBackend.Axi64)`.
- Do not change production RTL, AXKU15 demo/IP, Vivado Tcl, implementation,
  bitstream, or FPGA flows.
- Each 512-bit bridge request remains exactly eight ordered AXI4 64-bit beats
  with `len == 7` and `size == 3`.
- The two input words are at `0x400` and `0x440`; output words are at `0x800`
  and `0x840`.
- Input zero is 16 lanes `-1` then 16 lanes `+1`; input one reverses that
  order. Aggregate GroupNorm statistics are `(sum = 0, sumSquare = 64,
  count = 64)`.
- Diagonal Conv1/Conv2 weights equal one; all shifts are zero; GN2 affine is
  gamma 256/beta zero; `temb = +3`, `residual = -2`, and residual addition is
  enabled.
- Every wait has an explicit finite bound. Output data is recorded only on a
  Decoupled `fire`.

---

### Task 1: Record accepted AXI64 burst addresses

**Files:**
- Modify: `accelerator/src/test/scala/diffusion/ResNetBlockE2ETestSupport.scala`
- Modify: `accelerator/src/test/scala/diffusion/Axi64MemoryModelSpec.scala`

**Interfaces:**
- Consumes: existing `Axi64MemoryModel` channel driving and protocol checks.
- Produces: `readBurstAddresses: Vector[BigInt]` and
  `writeBurstAddresses: Vector[BigInt]`, each recording the accepted AR/AW
  base address exactly once.

- [ ] **Step 1: Write the failing address-history test**

Add one `Axi64MemoryModelSpec` test that completes two reads at `0x400`,
`0x440` and two writes at `0x800`, `0x840`, then asserts:

```scala
memory.readBurstAddresses shouldBe Vector(BigInt(0x400), BigInt(0x440))
memory.writeBurstAddresses shouldBe Vector(BigInt(0x800), BigInt(0x840))
```

Drive the current DMA/helper protocol. Each transfer waits for its `done` with
a bounded loop; no fixed-cycle completion assumption is allowed.

- [ ] **Step 2: Verify RED**

Run:

```powershell
$env:SBT_OPTS='-Dsbt.server.autostart=false -Xms512m -Xmx4G'
sbt 'testOnly FLOOD_Accelerator.diffusion.Axi64MemoryModelSpec'
```

Expected: compilation failure because the address-history accessors are absent.

- [ ] **Step 3: Add minimal test-side address history**

Add to `Axi64MemoryModel`:

```scala
private val readAddressHistory = scala.collection.mutable.ArrayBuffer.empty[BigInt]
private val writeAddressHistory = scala.collection.mutable.ArrayBuffer.empty[BigInt]
def readBurstAddresses: Vector[BigInt] = readAddressHistory.toVector
def writeBurstAddresses: Vector[BigInt] = writeAddressHistory.toVector
```

At the existing AR fire branch append `axi.ar.bits.addr.peek().litValue`; at
the existing AW fire branch append `axi.aw.bits.addr.peek().litValue`. Do not
append for valid-only, W, B, R, or any retry cycle.

- [ ] **Step 4: Verify GREEN**

Run the Step 2 command.

Expected: all `Axi64MemoryModelSpec` cases pass and address history contains
exactly the four accepted base addresses in direction-local order.

- [ ] **Step 5: Commit**

```powershell
git add accelerator/src/test/scala/diffusion/ResNetBlockE2ETestSupport.scala accelerator/src/test/scala/diffusion/Axi64MemoryModelSpec.scala
git commit -m "test: record AXI64 burst address history"
```

### Task 2: Add the two-vector, two-beat ResNetBlock E2E test

**Files:**
- Modify: `accelerator/src/test/scala/diffusion/DiffusionAccelTopResNetBlockE2ESpec.scala`
- Uses: `accelerator/src/test/scala/diffusion/ResNetBlockE2ETestSupport.scala`

**Interfaces:**
- Consumes: `load512`, `read512`, `readBurstAddresses`,
  `writeBurstAddresses`, `assertNoProtocolError`, and
  `ResNetBlockE2EReference.finalLanes`.
- Produces: one two-vector E2E case covering ordered DMA read, GN1, Conv1,
  GN2, activation, Conv2/residual, internal store, and ordered DMA writeback.

- [ ] **Step 1: Write the failing test shell**

Add this named test:

```scala
it should "preserve two DMA vectors and write both fixed-point results in order" in
```

Seed inputs and expected values:

```scala
val input0 = Vector.fill(16)(-1) ++ Vector.fill(16)(1)
val input1 = Vector.fill(16)(1) ++ Vector.fill(16)(-1)
val inputs = Vector(input0, input1)
val temb = Vector.fill(32)(3)
val residual = Vector.fill(32)(-2)
val expected = inputs.map(ResNetBlockE2EReference.finalLanes(_, temb, residual))
memory.load512(0x400, ResNetBlockE2EReference.packLanes(input0))
memory.load512(0x440, ResNetBlockE2EReference.packLanes(input1))
```

Issue read and write commands with addresses `0x400`, `0x800` and `beats = 2`.

- [ ] **Step 2: Verify RED**

Run:

```powershell
$env:SBT_OPTS='-Dsbt.server.autostart=false -Xms512m -Xmx4G'
sbt 'testOnly FLOOD_Accelerator.diffusion.DiffusionAccelTopResNetBlockE2ESpec -- -z "preserve two DMA vectors"'
```

Expected: FAIL because all two-vector phase commands and handshake handling
are not present yet.

- [ ] **Step 3: Implement the bounded two-vector driver**

Use the suite's existing one-cycle memory tick discipline. Define:

```scala
val commandLimit = 128
val phaseLimit = 256
val dmaLimit = 1024
val computeLimit = 1024
val conv1Outputs = scala.collection.mutable.ArrayBuffer.empty[Vector[Int]]
val activationOutputs = scala.collection.mutable.ArrayBuffer.empty[Vector[Int]]
val conv2Outputs = scala.collection.mutable.ArrayBuffer.empty[Vector[Int]]
```

Drive the current scheduler phases in this exact order:

1. Start AXI-Lite control and submit `tensorReadCommand(0x400, 2)`.
2. In GN1, submit `gn1StatsCommand(vectors = 2)`, consume one statistics
   handshake, and require `(0, 64, 64)`.
3. Write 32 diagonal Conv1 weights, submit `gn1ConvCommand(vectors = 2)`,
   and collect exactly two fired Conv1 results. Require `conv1Outputs ==
   inputs`.
4. In GN2 stats, submit `gn2StatsCommand(vectors = 2)`, consume one
   handshake, and require `(0, 64, 64)`.
5. Write 32 GN2 affine entries; write 32 diagonal Conv2 weights; drive all
   `temb` and residual lanes; submit both `gn2ActivationCommand(vectors = 2)`
   and `gn2ConvCommand(vectors = 2)` during the existing combined phase.
   Collect two fired activation and Conv2 outputs. Require activation outputs
   equal the reference variance-one SiLU vectors and Conv2 outputs equal
   `expected`, each in input order.
6. In StoreOutput, submit `tensorWriteCommand(0x800, 2)` and wait for one
   `done` pulse.

After completion require:

```scala
memory.read512(0x800) shouldBe ResNetBlockE2EReference.packLanes(expected(0))
memory.read512(0x840) shouldBe ResNetBlockE2EReference.packLanes(expected(1))
memory.readBurstAddresses shouldBe Vector(BigInt(0x400), BigInt(0x440))
memory.writeBurstAddresses shouldBe Vector(BigInt(0x800), BigInt(0x840))
memory.delayedChannels shouldBe Set("AW", "W", "B", "AR", "R")
memory.assertNoProtocolError()
```

No file under `accelerator/src/main` may change.

- [ ] **Step 4: Verify GREEN**

Run the Step 2 command.

Expected: the selected test passes under staggered AW/W/B/AR/R delays, with
both 512-bit result words and all four full-burst addresses exact.

- [ ] **Step 5: Commit**

```powershell
git add accelerator/src/test/scala/diffusion/DiffusionAccelTopResNetBlockE2ESpec.scala
git commit -m "test: verify two-vector ResNetBlock DMA flow"
```

### Task 3: Run focused regression and record evidence

**Files:**
- Modify: `accelerator/docs/plans/2026-08-12-sd15-resnetblock-two-vector-dma-verification-design.md`

**Interfaces:**
- Consumes: passing address-history and two-vector E2E cases.
- Produces: reproducible simulation evidence while retaining FPGA exclusions.

- [ ] **Step 1: Run focused regression**

```powershell
$env:SBT_OPTS='-Dsbt.server.autostart=false -Xms512m -Xmx4G'
sbt 'testOnly FLOOD_Accelerator.diffusion.DiffusionAccelTopResNetBlockE2ESpec FLOOD_Accelerator.diffusion.Axi64MemoryModelSpec FLOOD_Accelerator.diffusion.DiffusionAccelTopAxi64Spec FLOOD_Accelerator.diffusion.MigAppToAxi64BridgeSpec FLOOD_Accelerator.diffusion.ConvToGroupNormStatsPathSpec FLOOD_Accelerator.diffusion.Conv2ResidualPathSpec FLOOD_Accelerator.diffusion.GroupNormActivationPathSpec'
```

Expected: every selected suite passes with zero failures.

- [ ] **Step 2: Regenerate unchanged AXI64 top**

```powershell
$env:SBT_OPTS='-Dsbt.server.autostart=false -Xms512m -Xmx4G'
sbt 'runMain FLOOD_Accelerator.diffusion.GenerateDiffusionAccelAxi64TopVerilog'
git status --short
```

Expected: elaboration succeeds. Do not stage generated outputs or Vivado
journal files.

- [ ] **Step 3: Update evidence wording**

Set the design status to `Implemented and simulation-validated`. Record the
exact Step 1 command and passing count. State that ordered read addresses
`0x400`, `0x440`, ordered write addresses `0x800`, `0x840`, both expected
512-bit words, and every staggered AXI64 channel were verified. Preserve all
existing exclusions.

- [ ] **Step 4: Final verification**

```powershell
git diff --check
git status --short
```

Expected: no whitespace errors; only intended test/evidence files are
candidates for staging, apart from pre-existing untracked Vivado journals.

- [ ] **Step 5: Commit and push**

```powershell
git add accelerator/docs/plans/2026-08-12-sd15-resnetblock-two-vector-dma-verification-design.md
git commit -m "test: validate two-vector ResNetBlock DMA flow"
git push origin sd15-resnetblock
```

## Plan self-review

- Coverage: Task 1 verifies accepted bridge transaction addresses; Task 2
  proves ordered dual-vector DMA and compute behavior under independent
  backpressure; Task 3 supplies regression and elaboration evidence.
- Scope: no production RTL, Vivado, bitstream, or FPGA operation is included.
- Consistency: all tasks use `Vector[BigInt]` address history and the existing
  `BigInt` lane-packed reference words; all command vector counts are two.
- No incomplete requirements, ambiguous addresses, or open placeholders are
  present.

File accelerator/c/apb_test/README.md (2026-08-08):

# AXI Test Project for E203 RISC-V Processor

## 项目概述

这是一个专为E203 RISC-V处理器设计的裸机C程序，用于测试APB接口连通性。

## 内存布局

| 内存区域 | 起始地址 | 大小 | 用途 |
|---|---|---|---|
| ITCM | 0x80000000 | 64KB | 指令存储，程序代码 |
| DTCM | 0x90000000 | 64KB | 数据存储，变量和栈 |
| APB目标 | 0x50000000 | - | 外设测试地址 |

## 文件结构

```
application/custom/apb_test/
├── main.c           # 主程序，AXI接口测试
├── startup.S        # 启动汇编代码
├── link.ld          # 自定义链接脚本
├── Makefile         # 构建脚本
└── README.md        # 项目说明
```

## 编译和运行

### 环境准备
```bash
# Windows环境下设置SDK环境
setup.bat
```

### 编译项目
```bash
cd application/custom/apb_test
make all
```

### 生成仿真文件
```bash
make sim
```

### 查看内存分布
```bash
make memmap
```

### 生成调试信息
```bash
make debug
```

## 输出文件

| 文件类型 | 文件名 | 用途 |
|---|---|---|
| ELF | apb_test.elf | 调试用可执行文件 |
| HEX | apb_test.hex | Intel HEX格式，用于$readmemh() |
| Verilog | apb_test.verilog | Verilog内存格式 |
| Binary | apb_test.bin | 纯二进制文件 |
| Dump | apb_test.dump | 反汇编文件 |

## $readmem系列函数区别

### $readmemh vs $readmemb

| 函数 | 格式 | 用途 | 示例 |
|---|---|---|---|
| `$readmemh` | 十六进制ASCII | 读取.hex文件 | `$readmemh("apb_test.hex", memory);` |
| `$readmemb` | 二进制ASCII | 读取二进制文本 | `$readmemb("data.txt", memory);` |

### 在Testbench中使用

```verilog
// 方法1：使用HEX文件
reg [31:0] itcm_memory [0:16383];  // 64KB ITCM
initial begin
    $readmemh("apb_test.hex", itcm_memory);
end

// 方法2：使用Verilog格式文件
reg [31:0] dtcm_memory [0:16383];  // 64KB DTCM  
initial begin
    $readmemh("apb_test.verilog", dtcm_memory);
end
```

## 测试内容

程序会执行以下APB接口测试：

1. **基本读写测试**：向0x50000000写入0xDEADBEEF并读回验证
2. **不同模式测试**：向0x50000004写入0xCAFEBABE并读回验证  
3. **序列模式测试**：向0x50000008写入0x12345678并读回验证
4. **交替模式测试**：向0x5000000C写入0xA5A5A5A5并读回验证
5. **连续地址测试**：向0x50000000-0x5000003F写入递增数据并验证

## 程序特性

- ✅ **无标准库依赖**：不使用printf、malloc等标准库函数
- ✅ **自定义启动代码**：完全控制初始化过程
- ✅ **严格内存限制**：代码64KB，数据64KB
- ✅ **直接硬件访问**：使用volatile指针直接访问内存映射寄存器
- ✅ **仿真友好**：生成适合Verilog testbench的内存文件

## 返回值

- `0`：所有测试通过
- `-1`：有测试失败

## 注意事项

### 1. **程序入口地址** 
- 固定在 `0x80000000`（ITCM起始地址）
- 链接脚本强制将 `.text.init` 段放在ITCM首地址
- 复位后处理器从此地址开始执行

### 2. **栈指针配置**
- 初始化为 `0x90010000`（DTCM顶部）
- DTCM范围：`0x90000000` ~ `0x9000FFFF` (64KB)
- 栈向下增长，4KB栈空间足够裸机程序使用

### 3. **内存初始化**
- **BSS段自动清零**：全局未初始化变量被清零
- **数据段复制**：已初始化数据从ITCM复制到DTCM（当前程序无初始化数据）
- **栈区域**：不需要初始化，使用时自动分配

### 4. **AXI接口规格**
- **数据位宽**：32bit（4字节）
- **地址对齐**：所有访问必须4字节对齐
- **访问模式**：使用 `volatile unsigned int*` 确保每次访问都直接操作硬件

### 5. **中断和异常**
- **全局中断禁用**：`mstatus = 0`
- **中断源禁用**：`mie = 0`  
- **纯轮询模式**：不依赖任何中断机制

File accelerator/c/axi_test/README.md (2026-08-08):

# AXI Test Project for E203 RISC-V Processor

## 项目概述

这是一个专为E203 RISC-V处理器设计的裸机C程序，用于测试AXI接口连通性。

## 内存布局

| 内存区域 | 起始地址 | 大小 | 用途 |
|---|---|---|---|
| ITCM | 0x80000000 | 64KB | 指令存储，程序代码 |
| DTCM | 0x90000000 | 64KB | 数据存储，变量和栈 |
| AXI目标 | 0x40000000 | - | 外设测试地址 |

## 文件结构

```
application/custom/axi_test/
├── main.c           # 主程序，AXI接口测试
├── startup.S        # 启动汇编代码
├── link.ld          # 自定义链接脚本
├── Makefile         # 构建脚本
└── README.md        # 项目说明
```

## 编译和运行

### 环境准备
```bash
# Windows环境下设置SDK环境
setup.bat
```

### 编译项目
```bash
cd application/custom/axi_test
make all
```

### 生成仿真文件
```bash
make sim
```

### 查看内存分布
```bash
make memmap
```

### 生成调试信息
```bash
make debug
```

## 输出文件

| 文件类型 | 文件名 | 用途 |
|---|---|---|
| ELF | axi_test.elf | 调试用可执行文件 |
| HEX | axi_test.hex | Intel HEX格式，用于$readmemh() |
| Verilog | axi_test.verilog | Verilog内存格式 |
| Binary | axi_test.bin | 纯二进制文件 |
| Dump | axi_test.dump | 反汇编文件 |

## $readmem系列函数区别

### $readmemh vs $readmemb

| 函数 | 格式 | 用途 | 示例 |
|---|---|---|---|
| `$readmemh` | 十六进制ASCII | 读取.hex文件 | `$readmemh("axi_test.hex", memory);` |
| `$readmemb` | 二进制ASCII | 读取二进制文本 | `$readmemb("data.txt", memory);` |

### 在Testbench中使用

```verilog
// 方法1：使用HEX文件
reg [31:0] itcm_memory [0:16383];  // 64KB ITCM
initial begin
    $readmemh("axi_test.hex", itcm_memory);
end

// 方法2：使用Verilog格式文件
reg [31:0] dtcm_memory [0:16383];  // 64KB DTCM  
initial begin
    $readmemh("axi_test.verilog", dtcm_memory);
end
```

## 测试内容

程序会执行以下AXI接口测试：

1. **基本读写测试**：向0x40000000写入0xDEADBEEF并读回验证
2. **不同模式测试**：向0x40000004写入0xCAFEBABE并读回验证  
3. **序列模式测试**：向0x40000008写入0x12345678并读回验证
4. **交替模式测试**：向0x4000000C写入0xA5A5A5A5并读回验证
5. **连续地址测试**：向0x40000000-0x4000003F写入递增数据并验证

## 程序特性

- ✅ **无标准库依赖**：不使用printf、malloc等标准库函数
- ✅ **自定义启动代码**：完全控制初始化过程
- ✅ **严格内存限制**：代码64KB，数据64KB
- ✅ **直接硬件访问**：使用volatile指针直接访问内存映射寄存器
- ✅ **仿真友好**：生成适合Verilog testbench的内存文件

## 返回值

- `0`：所有测试通过
- `-1`：有测试失败

## 注意事项

### 1. **程序入口地址** 
- 固定在 `0x80000000`（ITCM起始地址）
- 链接脚本强制将 `.text.init` 段放在ITCM首地址
- 复位后处理器从此地址开始执行

### 2. **栈指针配置**
- 初始化为 `0x90010000`（DTCM顶部）
- DTCM范围：`0x90000000` ~ `0x9000FFFF` (64KB)
- 栈向下增长，4KB栈空间足够裸机程序使用

### 3. **内存初始化**
- **BSS段自动清零**：全局未初始化变量被清零
- **数据段复制**：已初始化数据从ITCM复制到DTCM（当前程序无初始化数据）
- **栈区域**：不需要初始化，使用时自动分配

### 4. **AXI接口规格**
- **数据位宽**：32bit（4字节）
- **地址对齐**：所有访问必须4字节对齐
- **访问模式**：使用 `volatile unsigned int*` 确保每次访问都直接操作硬件

### 5. **中断和异常**
- **全局中断禁用**：`mstatus = 0`
- **中断源禁用**：`mie = 0`  
- **纯轮询模式**：不依赖任何中断机制

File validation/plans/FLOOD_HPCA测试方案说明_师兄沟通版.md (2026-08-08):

# FLOOD HPCA 重投 — 测试方案说明（师兄沟通版）

> **文档目的**：与师兄对齐 HPCA 重投实验方向、分工优先级和需要确认的事项。  
> **论文定位**：FLOOD 作为 **Diffusion 加速器**（面向 LDM/DiT 推理），而非通用 DNN 加速器。  
> **配套文档**：[FLOOD_HPCA测试结果清单.md](./FLOOD_HPCA测试结果清单.md)（填表用）

---

## 1. 背景与问题

MICRO 审稿 5 人中 3 人拒稿、4 人质疑 novelty。核心问题不是单一性能数字，而是**论文可信度不足**：

| 审稿关切 | 具体表现 | 对测试的影响 |
|:---|:---|:---|
| 实验来源混杂 | FPGA、ASIC、仿真、估算边界不清 | 必须统一用 PyTorchSim 作为主数据源，并明确标注 |
| Baseline 不公平 | 配置不明，难以判断比较是否合理 | 必须补 baseline 配置表（E9） |
| 创新点像拼装 | 稀疏、量化、dataflow 被视为独立堆叠 | 必须做系统级消融（E7）和错误组合代价 |
| 精度退化未充分报告 | 缺少量化后的质量损失数据 | E3、E4 必须补 FID/PSNR/SSIM 等 |
| 单位口径不一致 | TOPS/GOPS/mm² 混用 | 全文统一单位，测试阶段就按统一口径记录 |

**转投 HPCA 的前提**：按"重投新稿"处理，实验部分需要实质性补强，而非局部改图。

**HPCA 定位调整（相对 MICRO）**：FLOOD 不再主打"通用 DNN 加速器"，而是定位为 **Diffusion 加速器**，专门面向 LDM/DiT 混合 Conv/Matrix 推理。实验、baseline、叙事均围绕 diffusion workload 组织。

---

## 2. 测试策略

### 2.1 核心思路

用**开源 PyTorchSim** 建立统一、可复现的端到端仿真评测，回应审稿人对实验可信度和 baseline 公平性的质疑。

```
PyTorch 模型 → operator trace → FLOOD mapping → PyTorchSim 仿真 → 统一 CSV → 论文图表
```

### 2.2 三条测试主线

| 主线 | 目的 | 对应实验组 |
|:---|:---|:---:|
| **端到端系统级结果** | 支撑摘要核心数字（latency -28%、power -32%、utilization +40%） | E1, E7 |
| **创新点组合有效性** | 证明三项机制联合设计必要，而非简单堆叠 | E2, E3, E4, E5, E6, E7 |
| **审稿驳回点补证据** | 统一数据来源、透明 baseline、规范单位 | E9 + 全文标注 |

### 2.3 与 MICRO 版本的差异

| 维度 | MICRO 版本 | HPCA 重投目标 |
|:---|:---|:---|
| **论文定位** | 通用 DNN 加速器（LDM 为主，扩展到 CNN/ViT/BERT） | **Diffusion 加速器**（LDM + DiT 为核心） |
| 数据来源 | FPGA + ASIC synthesis + 理论估算混写 | PyTorchSim 统一端到端仿真为主 |
| Baseline | NVDLA + DiT-Accelerator，描述不完整 | **Diffusion 专用 baseline 为主**（DiT-Accel、xDiT 等），配置表透明（E9） |
| 消融 | 有但不系统 | 完整 E7 消融 + 错误组合代价 |
| 扩展验证 | ResNet/ViT/BERT 泛化 | **LDM vs DiT 族内多模型对比**（E8） |
| 图表 | 部分实验图缺失 | 按 Fig. 10–17 重新组织 |

---

## 3. 实验组概览（9 组）

| 编号 | 名称 | 优先级 | 核心模型 | 一句话目的 |
|:---:|:---|:---:|:---|:---|
| E1 | 端到端主结果 | **P0** | SD UNet, VAE, DiT-B/4 | 证明 Full FLOOD 系统级收益 |
| E2 | 细粒度稀疏 | **P0** | SD UNet, DiT-B/4 | 证明跳零/GCSE 在真实 workload 有效 |
| E3 | 混合量化 | **P0** | SD UNet, CelebA-HQ | 量化性能与质量 trade-off |
| E4 | Outlier bypass | P1 | SD UNet, CelebA-HQ | 低成本保精度 |
| E5 | Softmax 支持 | **P0** | DiT-B/4, DiT-S/4, SD UNet attention | DiT attention 算子支持可信 |
| E6 | Dataflow 与存储 | **P0** | SD UNet, DiT, LDM pipeline | FLOOD/PLANE 对 mixed Conv/Matrix diffusion 必要性 |
| E7 | 系统级消融 | **P0** | SD UNet, DiT-B/4 | 回应"创新点拼装"质疑 |
| E8 | Diffusion 族内扩展 | P1 | SD v1.5, DiT-B/4, DiT-S/4 | LDM 与 DiT 两类架构均适用 |
| E9 | Baseline 公平性 | **P0** | 全部 diffusion 实验 | 配置透明、比较公平 |

**P0 共 7 组**（E1, E2, E3, E5, E6, E7, E9）— 时间紧时至少完成这些。

---

## 4. 模型选择 rationale

> **原则**：所有主测试模型均为 **diffusion 推理 workload**，不再以 ResNet/ViT/BERT 作为主实验对象。

### 4.1 主测试模型（必做）

| 模型 | 选择理由 | 覆盖算子 | 架构类型 |
|:---|:---|:---|:---:|
| **Stable Diffusion v1.5 UNet** | Diffusion 核心 backbone，Conv+Matrix 混合 | Conv, Attention, Linear, Norm | LDM |
| **Stable Diffusion VAE** | LDM pipeline 编码/解码阶段 | Conv, Deconv | LDM |
| **DiT-B/4** | Diffusion Transformer 代表 | Matrix, Attention, Softmax, MLP | DiT |
| **DiT-S/4** | 较小 DiT 规模，验证 scaling | Matrix, Attention, Softmax | DiT |

### 4.2 扩展模型（建议做，E8）

| 模型 | 选择理由 |
|:---|:---|
| DiT-XL/2 | 更大规模 DiT，验证 scaling |
| 完整 LDM pipeline（UNet+VAE） | 端到端 diffusion 推理 |

### 4.3 不再作为主实验对象

| 模型 | 原因 |
|:---|:---|
| ResNet-50 | 非 diffusion workload，与论文定位不符 |
| ViT-B/16 | 纯分类 Transformer，非 generative |
| BERT-base | NLP 任务，与 diffusion 无关 |

> 若审稿人追问泛化性，可回应：FLOOD 的设计动机来自 diffusion 推理的 mixed Conv/Matrix 特性，实验聚焦 LDM 与 DiT 两类主流 diffusion 架构即可证明适用性。

---

## 5. Baseline 设计

> **原则**：baseline 以 **diffusion 加速器** 为主，不再以 NVDLA 等通用加速器作为主对比对象。

| Baseline | 定位 | 优先级 | 实现方式 |
|:---|:---|:---:|:---|
| **Base FLOOD** | 无三项优化的 FLOOD 原始架构 | 必做 | PyTorchSim 配置 |
| **DiT-Accelerator-like** | 面向 DiT/LDM 的专用 diffusion 加速器 | **必做** | PyTorchSim modeled baseline 或文献数据 |
| **通用 diffusion baseline** | 不针对 mixed Conv/Matrix 优化的 diffusion 加速器 | 建议 | PyTorchSim modeled baseline（同硬件约束） |
| **Software reference** | xDiT、PipeFusion、DistriFusion、TensorRT 等 | 可选 | 单独标注，不与硬件直接公平比较 |
| ~~NVDLA-like~~ | ~~经典通用 DNN 加速器~~ | **不做主 baseline** | 与 diffusion 定位不符，仅可在 related work 中讨论 |

**关键原则**：
- 所有硬件 baseline 在**同一工艺、频率、面积预算、带宽**下比较
- 主对比对象是 **diffusion 领域已有加速器**，而非通用 DNN 加速器
- 若无法完整复现 prior work，写成 "modeled baseline under matched hardware constraints"

---

## 6. 时间线与分工建议

### 6.1 阶段划分

| 阶段 | 时间 | 内容 | 依赖 |
|:---|:---|:---|:---|
| **Phase 0** | 第 1 周 | 确认 FLOOD 硬件参数定稿；选定 PyTorchSim 版本；搭建环境 | 师兄确认硬件参数 |
| **Phase 1** | 第 2–3 周 | PyTorch trace extractor；跑 SD UNet / DiT trace；统计 sparsity/outlier | PyTorchSim 可用 |
| **Phase 2** | 第 4–5 周 | 完成 P0 实验（E1, E2, E3, E6, E7, E9） | Phase 1 完成 |
| **Phase 3** | 第 6 周 | 完成 P1 实验（E4, E5, E8）；汇总填表；出图 | Phase 2 完成 |

### 6.2 分工建议（待与师兄确认）

| 任务 | 建议负责人 | 说明 |
|:---|:---|:---|
| FLOOD 硬件参数定稿 | 师兄 | 频率、Tile 数、buffer、带宽等 |
| PyTorchSim 环境搭建 | 我 | 开源版本选型、配置、验证 |
| Trace extractor | 我 | PyTorch hook 抓 op/shape/sparsity |
| E1–E3 主结果跑数 | 我 | PyTorchSim 端到端仿真 |
| E4–E6 机制实验 | 我 + 师兄 review | 需要确认机制开关配置 |
| E7 消融 | 我 | 按配置逐项开关 |
| E8 泛化 | 我 | 轻量验证 |
| E9 baseline 表 | 师兄主导 | 需要师兄确认 prior work 配置 |
| 论文图表 | 共同 | 我出数据，师兄定图号/布局 |
| 实验段落写作 | 共同 | 我提供数据表，师兄整合 |

---

## 7. 需要与师兄确认的事项

### 7.1 必须确认（阻塞实验启动）

- [ ] **FLOOD 固定硬件参数表**：频率（330 MHz?）、Tile/PE 数、buffer size、SRAM/DRAM 带宽、面积预算（3 mm²?）
- [ ] **开源 PyTorchSim 版本**：GitHub 链接或项目名；输入格式；能否输出 cycle/memory/energy
- [ ] **HPCA 版本三项创新点最终表述**：是否与 MICRO 一致，还是按新手稿重组（稀疏分主动/被动、量化 4/8b、FLOOD 架构提升）
- [ ] **图表安排**：是否沿用 Fig. 10–17 结构，还是按讨论手稿重新编号

### 7.2 建议确认（影响实验设计）

- [ ] **Diffusion baseline 选型**：DiT-Accelerator-like 具体指哪篇 prior work？通用 diffusion baseline 如何建模？
- [ ] **ASIC/FPGA 结果口径**：HPCA 版本中 FPGA 实测、ASIC synthesis 是否保留，还是全部改为 PyTorchSim
- [ ] **精度指标选择**：FID vs PSNR/SSIM 为主（讨论手稿倾向 PSNR/SSIM）
- [ ] **A100 级算力对标**：讨论手稿提到算力与 A100 相当，是否作为 software reference baseline
- [ ] **参考文献 audit**：是否由师兄负责，还是需要我配合核查

### 7.3 讨论手稿中的特殊要求

根据手写讨论记录，以下点需要在实验中体现：

| 讨论要点 | 对应实验 | 状态 |
|:---|:---|:---:|
| 稀疏分主动（GCSE）和被动（slice 跳过） | E2 | 待确认机制开关 |
| 量化 4/8b + outlier 高熵处理 | E3, E4 | 待确认 |
| 延时/功耗/面积三指标 | E1, E9 | 待确认硬件参数 |
| 大图：多模型下 FLOOD vs 他人对比 | E1 + E8 | 待确认对比对象 |
| FID 改 PSNR | E3 | 待确认 |
| Diffusion 模型替换 F16 | E1, E3 | 待确认具体模型 |

---

## 8. 风险与应对

| 风险 | 影响 | 应对 |
|:---|:---|:---|
| PyTorchSim 搭建周期长 | 延迟全部实验 | Phase 1 先用 PyTorch trace 独立推进，不阻塞 |
| PyTorchSim 不支持 energy 输出 | E1/E7 缺 energy 数据 | 自建 energy model（power × latency） |
| NVDLA/DiT-Accel baseline 无法复现 | E1/E9 缺外部对比 | 优先 DiT-Accel-like；通用 diffusion baseline 用 analytical comparison |
| DiT 规模过大跑不动 | E8 scaling 不完整 | 至少覆盖 DiT-B/4 和 DiT-S/4 |
| 时间不够做完全部 9 组 | 实验不完整 | 优先 P0（6 组），P1 酌情砍掉 E5 |

---

## 9. 预期产出

| 产出 | 格式 | 用途 |
|:---|:---|:---|
| 9 组实验 CSV 数据 | `01_trace_layers.csv` 等 | 论文数据来源 |
| 填好的测试结果清单 | `FLOOD_HPCA测试结果清单.md` | 实验章节写作素材 |
| Baseline 配置表 | E9 表格 | 回应审稿人 baseline 质疑 |
| 论文图表数据 | 按 Fig. 10–17 | 直接绑图 |
| 实验方法段落 | LaTeX | 说明数据来源和公平性 |

---

## 10. 一句话总结（给师兄的快速版）

> HPCA 重投将 FLOOD 定位为 **Diffusion 加速器**，用开源 PyTorchSim + 固定硬件参数跑 7 组 P0 实验，主对比对象是 DiT-Accelerator-like 等 diffusion 专用 baseline，主测试模型为 SD UNet/VAE 和 DiT 系列。我负责 PyTorchSim 搭建和跑数，需要师兄确认硬件参数、diffusion baseline 选型和创新点表述。

---

## 附录：与审稿意见的对应关系

| 审稿意见 | 对应实验 | 如何回应 |
|:---|:---:|:---|
| 实验来源混杂 | E9 + 全文标注 | 统一 PyTorchSim，明确标注每类数据来源 |
| Baseline 配置不明 | E9 | 配置表透明 |
| 创新点像拼装 | E7 | 系统级消融 + 错误组合代价 |
| 缺少精度退化数据 | E3, E4 | FID/PSNR/SSIM/LPIPS 全报 |
| 跳零延迟收益不清 | E2 | 真实 workload 层级统计 |
| co-design 论证不足 | E6, E7 | dataflow 选择准则 + 组合必要性 |
| 单位不一致 | 全文 | 测试阶段统一口径 |
| 泛化性不足 | E8 | LDM vs DiT 多模型对比，证明 diffusion 族内适用性 |

---

*文档版本：v1.1 | 定位：Diffusion Accelerator | 生成日期：2026-06-23*

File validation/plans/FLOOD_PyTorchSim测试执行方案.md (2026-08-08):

# FLOOD HPCA 重投：PyTorchSim 测试执行方案

## 1. 测试目标

本轮测试不是简单补充更多性能数字，而是用一条统一、可复现的数据链证明三件事：

1. FLOOD 在真实 Diffusion 工作负载上获得端到端收益；
2. 稀疏、混合精度、outlier、Softmax 与双 dataflow 之间存在协同关系，而非独立模块拼装；
3. 所有主结果都能追溯到明确的模型、层、硬件配置和仿真版本。

统一数据链：

```text
PyTorch 模型与输入
  -> 算子与张量 trace
  -> 精度/稀疏/映射标注
  -> PyTorchSim 映射与周期仿真
  -> SRAM/DRAM/NoC 活动统计
  -> 能耗模型
  -> 分层 CSV
  -> 端到端汇总与论文图表
```

## 2. 核心研究问题

| ID | 研究问题 | 需要给出的证据 |
|---|---|---|
| RQ1 | FLOOD 是否真正改善端到端 Diffusion 推理？ | latency、energy、utilization、traffic 的端到端比较 |
| RQ2 | 收益来自哪些模块？ | 逐项消融和增量收益 |
| RQ3 | 各模块为什么必须联合设计？ | 错误组合、固定策略和 oracle 上界对比 |
| RQ4 | 细粒度稀疏是否转化为实际周期和访存收益？ | 真实层级 sparsity、skip ratio、cycle/traffic reduction |
| RQ5 | INT4/INT8 是否在可接受质量损失下带来系统收益？ | quality–latency–energy Pareto 曲线 |
| RQ6 | FLOOD/PLANE 自适应映射是否优于固定 dataflow？ | per-op 最优选择、切换开销、端到端收益 |
| RQ7 | 结论是否只对单一模型成立？ | LDM 与 DiT 两类模型、多分辨率/序列长度结果 |

## 3. 测试对象与固定输入

### 3.1 主模型

| 模型 | 建议配置 | 用途 |
|---|---|---|
| Stable Diffusion v1.5 UNet | batch=1，512×512，固定 20/50 steps | Conv、attention、timestep 变化、端到端主结果 |
| Stable Diffusion v1.5 VAE Decoder | batch=1，512×512 | Conv/upsample 与完整 LDM pipeline |
| DiT-B/4 | batch=1，256×256 | Matrix、attention、Softmax 主结果 |
| DiT-S/4 | batch=1，256×256 | 小模型/规模变化验证 |
| DiT-XL/2 | batch=1，256×256，可选 | 大模型 scaling |

第一轮只跑代表性单步和完整单次网络前向，用于调通；正式结果再按固定 diffusion steps 汇总。所有软件质量实验必须固定 seed、prompt、scheduler、step 数和数据集子集。

### 3.2 建议的正式输入集

- 性能仿真：每个模型至少 3 个固定 seed；由于硬件周期主要由 shape 和稀疏模式决定，报告均值并给出稀疏导致的波动。
- 生成质量：至少 1,000 张用于初步筛选，最终关键配置建议 5,000–10,000 张。
- 重建质量：CelebA-HQ/FFHQ 固定子集，报告 PSNR、SSIM、LPIPS。
- 文生图质量：优先 FID、CLIP Score；PSNR/SSIM 不适合作为无配对文生图的唯一指标。

## 4. 统一硬件配置

正式跑数前冻结 `hardware_config.yaml`，至少包含：

```yaml
technology_nm:
frequency_mhz:
num_cores:
tiles_per_core:
macs_per_tile:
int8_peak_ops:
int4_peak_ops:
weight_sram_kb:
activation_sram_kb:
output_sram_kb:
noc_width_bit:
dram_bandwidth_gbps:
softmax_lanes: 32
precision_switch_cycles: 2
dataflow_switch_cycles:
bitmap_fetch_cycles:
outlier_queue_depth:
```

测试必须区分两类比较：

- **等资源比较**：相同 PE/MAC 数、SRAM、带宽、频率，比较架构和调度效率；
- **实现结果比较**：使用各设计真实综合/P&R 参数，比较面积、功耗和 TOPS/W。

两类结果不能混在同一柱状图中。

## 5. Trace 获取方案

### 5.1 算子级静态字段

每个算子记录：

```text
model, sample_id, diffusion_step, layer_id, op_type,
input_shape, weight_shape, output_shape,
kernel, stride, padding, groups,
M, N, K, heads, sequence_length,
weight_bits, activation_bits, accumulator_bits,
candidate_dataflows
```

覆盖 `Conv2d`、`Linear/GEMM`、`BMM`、Softmax、LayerNorm/GroupNorm、激活、残差加法、上/下采样和数据搬移。非 MAC 算子不能直接忽略，否则端到端 latency 会被高估加速比。

### 5.2 动态统计字段

```text
activation_zero_ratio,
weight_zero_ratio,
zero_channel_group_ratio,
effective_skipped_mac_ratio,
outlier_ratio,
outlier_collision_ratio,
activation_min/max,
percentile_99/99.9/99.99,
selected_precision,
selected_dataflow
```

动态激活建议至少在早、中、晚三个 diffusion step 取样，验证稀疏度和 outlier 是否随 timestep 变化。若变化明显，端到端仿真必须按 step 加权，不能只用单一步骤代表整条采样链。

### 5.3 Trace 正确性检查

每个模型先完成以下校验：

1. PyTorch 统计的总 MAC 数与独立 profiler 误差小于 1%；
2. 各算子输入输出 shape 连续一致；
3. 总参数量与官方模型一致；
4. trace 重放后的算子顺序与原始 forward 一致；
5. dense 配置下 PyTorchSim 周期趋势与理论 roofline 一致。

## 6. PyTorchSim 建模

### 6.1 每层周期分解

每层至少输出：

```text
compute_cycles
weight_load_cycles
activation_load_cycles
output_store_cycles
metadata_cycles
softmax_cycles
outlier_cycles
precision_switch_cycles
dataflow_switch_cycles
stall_cycles
total_cycles
```

若计算与搬移可重叠，使用事件时间线计算总周期，不能简单相加。

### 6.2 稀疏机制开关

| 配置 | 行为 |
|---|---|
| Dense | 不跳零、不门控 |
| ValueSkip | 动态零值不触发 MAC，但仍产生必要取数/控制开销 |
| ValueSkip+Prune | 同时缩短无效加法树活动 |
| GCSE | 全零 32-channel group 跳过 weight SRAM、NoC 和计算 |
| FullSparse | ValueSkip + Prune + GCSE |

关键是把“省 MAC”和“省周期/访存”分开记录。Value-level gating 可能主要省动态能耗，而 GCSE 才可能减少执行周期和数据搬移。

### 6.3 精度和 outlier 开关

| 配置 | 主数据通路 | Outlier |
|---|---|---|
| FP16 reference | FP16 | 无 |
| INT8 | INT8 | 截断/饱和 |
| INT4 | INT4 | 截断/饱和 |
| Mixed | layer-wise INT4/INT8 | 无 |
| Mixed+Outlier | layer-wise INT4/INT8 | bypass 补偿 |

outlier 仿真需要建模共享资源排队。如果同周期多个 lane 出现 outlier，应统计 arbitration collision、队列占用和额外周期，不能只按 outlier 数量线性加一个常数。

### 6.4 Dataflow 开关

| 配置 | 说明 |
|---|---|
| FLOOD-only | 全部算子固定 FLOOD dataflow |
| PLANE-only | 全部算子固定 PLANE dataflow |
| Rule-based adaptive | 按算子 shape、复用和带宽压力选择 |
| Oracle adaptive | 每层分别仿真两种 dataflow，选择总周期较小者 |
| Wrong mapping | 故意选择较差 dataflow，量化错误选择代价 |

建议先用 Oracle 得到性能上界，再设计可解释的 rule-based 策略。论文必须报告 rule-based 与 oracle 的差距，证明选择准则足够有效。

## 7. 实验矩阵

### P0-1：端到端主结果

模型：SD UNet、SD VAE、DiT-B/4、DiT-S/4。

对比：

1. Dense Base FLOOD；
2. Base + 统一 INT8；
3. Full FLOOD；
4. 等资源固定 systolic/GEMM baseline；
5. 可可靠复现时，再加入 diffusion accelerator modeled baseline。

指标：latency、speedup、energy、EDP、utilization、DRAM traffic、SRAM traffic、stall ratio。

### P0-2：稀疏收益

- 真实 workload：逐层 weight/activation/group sparsity 与 cycle/energy reduction；
- synthetic sweep：activation sparsity × weight sparsity 的 11×11 网格；
- group size sweep：8/16/32/64，验证 32-channel 选择；
- metadata 开销：bitmap 容量、fetch 周期和带宽占比。

需要同时给出：

- 稀疏度；
- 理论可跳 MAC；
- 实际跳过 MAC；
- 实际周期减少；
- 实际能耗减少。

### P0-3：混合精度 Pareto

配置：FP16、INT8、INT4、固定比例 Mixed、sensitivity-based Mixed、Mixed+Outlier。

输出：

- x 轴：quality drop；
- y 轴：latency 或 energy；
- 气泡大小：peak memory 或 DRAM traffic。

不要只测“30% INT4”一个点。至少给出 0%、10%、30%、50%、70%、100% INT4，并标出最终选择。

### P0-4：双 dataflow 与存储系统

- FLOOD-only、PLANE-only、adaptive、oracle；
- DRAM bandwidth sweep：8/16/32/64 B/cycle 或对应 GB/s；
- SRAM capacity sweep：0.5×/1×/2×；
- 报告每类算子的 dataflow 选择比例和切换次数；
- 报告切换开销占总周期比例。

### P0-5：系统级消融与协同

建议采用增量和 leave-one-out 两种消融：

```text
Base
+ ValueSkip
+ GCSE
+ Mixed Precision
+ Outlier
+ Softmax
+ Adaptive Dataflow
= Full FLOOD
```

以及：

```text
Full FLOOD
- GCSE
- Mixed Precision
- Outlier
- Adaptive Dataflow
```

增量消融显示收益来源，leave-one-out 显示每个模块在完整系统中的必要性。

重点增加三个“反例”：

1. 高稀疏但固定错误 dataflow；
2. 高 INT4 比例但无 outlier；
3. 只跳 MAC、仍搬运零 weight。

这些反例直接用于回应“只是把已有模块拼起来”的审稿意见。

### P0-6：Softmax

- vector length：32、64、128、256、512、1024、2048；
- 比较标准 FP32/FP16 Softmax、I-BERT-like、FLOOD INT8；
- 指标：最大/平均相对误差、KL divergence、延迟、能耗；
- 在 DiT-B/4 上报告端到端质量影响，而不仅是算子误差。

### P1：Timestep、分辨率与规模敏感性

- SD：256/512/768 分辨率；
- DiT：S/4、B/4、XL/2；
- diffusion early/middle/late timestep；
- batch size 1 为主，可附 batch 2/4；
- 带宽和 SRAM 容量敏感性。
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

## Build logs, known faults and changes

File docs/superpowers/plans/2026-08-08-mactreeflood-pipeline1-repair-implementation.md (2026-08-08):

# MACTreeFlood 单级流水修复 Implementation Plan

> **For agentic workers:** REQUIRED SUB-SKILL: Use superpowers:subagent-driven-development (recommended) or superpowers:executing-plans to implement this plan task-by-task. Steps use checkbox (`- [ ]`) syntax for tracking.

**Goal:** 使 `MACTreeFlood(pipeline = 1)` 完成合法的时分复用乘加并输出量化结果，不再在 elaboration 阶段访问不存在的第二级流水状态。

**Architecture:** 在 `MACTreeFlood` 内以 Scala elaboration-time 的 `if (pipeline == 1)` 分出单级状态机；该分支只使用第 0 级状态、输入 B 寄存器、累加寄存器和既有输出 FIFO。现有 `pipeline >= 2` 多级路径保持逻辑不变，端口与默认 `Config` 不变。

**Tech Stack:** Scala 2.12.13、Chisel 3.5.3、chiseltest、SBT 2.0.6、Temurin JDK 17。

## Global Constraints

- `MACTreeFlood` 的公开参数契约仍为 `pipeline >= 1`。
- 默认 `Config.pipeline = 2`、`Config.tLatency = 4` 与 AXKU15 设计参数不得修改。
- `pipeline == 1` 的 elaborated 硬件不得引用 `stageStates(1)`、`stageCounters(1)` 或 `stageRegistersOut(1)`。
- `pipeline >= 2` 的既有多级流水 RTL 不得改变。
- 不修改 `MACTreeRefine`、MacMachineWrapper 或 SBT/JVM 全局配置；wrapper OOM 与 SBT JAR 替换问题不属于本任务。
- 测试命令使用前台 SBT：`sbt --server --no-colors`；若先于测试出现 Windows JAR `AccessDeniedException`，记录为环境阻塞，不能标记 RTL 验证为通过。

---

## File Structure

- `accelerator/src/main/scala/core/CIMcore.scala`：`MACTreeFlood` 的参数化状态机；新增单级专用 elaboration 分支并保留多级代码。
- `accelerator/src/test/scala/core/CIMCoreTest.scala`：已有 `CIMCoreSpec` 的 `pipeline = 1` 矩阵向量 golden 回归；仅在必要时将其测试名称明确为单级回归，不改变 golden 数据语义。

### Task 1: Repair and Verify the Single-Stage MACTreeFlood Path

**Files:**
- Modify: `accelerator/src/main/scala/core/CIMcore.scala:301-502`
- Modify only if needed for an explicit regression name: `accelerator/src/test/scala/core/CIMCoreTest.scala:86-151`

**Interfaces:**
- Consumes: `MACTreeFlood(paral, dataWidth, outputWidth, pipeline, tLatency)` and its existing `io.inA`, `io.inB`, `io.out` ports.
- Produces: the same `Decoupled[SInt]` result for `pipeline = 1`; `CIMCore` continues to collect one result from each column MAC into `io.vectorOut`.

- [ ] **Step 1: Establish the RED regression using the existing real golden test**

The existing first `CIMCoreSpec` case constructs:

```scala
test(new CIMCore(
  rowSize = 2,
  colSize = 2,
  dataWidth = 8,
  outputWidth = 16,
  weightBandWidth = 8,
  pipeline = 1,
  tLatency = 2
))
```

It writes a deterministic `2 x 2` weight matrix, supplies a deterministic two-element vector, and checks both matrix-vector outputs. Do not weaken it or change its golden calculations.

- [ ] **Step 2: Run the RED regression and verify the expected failure**

Run from `accelerator/` after shutting down any old SBT server:

```powershell
& 'C:\Program Files (x86)\sbt\bin\sbt.bat' shutdown
$env:JAVA_HOME = 'C:\Program Files\Eclipse Adoptium\jdk-17.0.20.8-hotspot'
$env:JAVA_OPTS = '-Xms1G -Xmx8G -Xss4M -XX:ReservedCodeCacheSize=128m'
& 'C:\Program Files (x86)\sbt\bin\sbt.bat' --server --no-colors 'testOnly CIMCoreSpec'
```

Expected before the RTL change: `java.lang.IndexOutOfBoundsException: 1` at the `MACTreeFlood` first-stage handoff, because `pipeline = 1` creates only index 0.

- [ ] **Step 3: Add the minimal single-stage elaboration branch**

In `MACTreeFlood`, replace the unconditional first-stage/middle-stage/final-stage block with an elaboration-time branch:

```scala
if (pipeline == 1) {
  switch(stageStates(0)) {
    is(idle) {
      stageCounters(0) := 0.U
      when(io.inB.fire) {
        inputBReg := io.inB.bits
        accReg := 0.S
        stageStates(0) := computing
      }
    }
    is(computing) {
      val processInThisCycle = paral / tLatency
      when(stageCounters(0) < tLatency.U) {
        val baseIdx = (processInThisCycle.U * stageCounters(0))(log2Ceil(paral) - 1, 0)
        val partialSum = VecInit((0 until processInThisCycle).map { offset =>
          io.inA(baseIdx + offset.U) * inputBReg(baseIdx + offset.U)
        }).reduce(_ +& _)
        when(stageCounters(0) === 0.U) {
          accReg := partialSum.asSInt
        }.otherwise {
          accReg := (accReg + partialSum).asSInt
        }
        stageCounters(0) := stageCounters(0) + 1.U
      }.otherwise {
        outputFifo.io.enq.bits := accReg(tmpDataWidth - 1, tmpDataWidth - outputWidth).asSInt
        outputFifo.io.enq.valid := true.B
        stageStates(0) := outputting
      }
    }
    is(outputting) {
      when(outputFifo.io.enq.ready) {
        stageStates(0) := idle
      }
    }
  }
} else {
  // Preserve the pre-existing first/middle/final multi-stage state-machine code verbatim.
}
```

Keep the existing output FIFO wiring and `io.inB.ready := stageStates(0) === idle` after the branch. Do not add a second-stage access anywhere in the `pipeline == 1` branch.

- [ ] **Step 4: Run the focused GREEN regression**

Run the Step 2 command again.

Expected: the `correctly compute matrix-vector multiplication` case completes without `IndexOutOfBoundsException`, and both `vectorOut` expectations match the existing golden outputs.

- [ ] **Step 5: Run the remaining CIMCore regressions**

Run:

```powershell
& 'C:\Program Files (x86)\sbt\bin\sbt.bat' shutdown
$env:JAVA_HOME = 'C:\Program Files\Eclipse Adoptium\jdk-17.0.20.8-hotspot'
$env:JAVA_OPTS = '-Xms1G -Xmx8G -Xss4M -XX:ReservedCodeCacheSize=128m'
& 'C:\Program Files (x86)\sbt\bin\sbt.bat' --server --no-colors 'testOnly CIMCoreSpec'
```

Expected: all three `CIMCoreSpec` cases pass: matrix-vector, streaming, and ping-pong switching. The multi-stage cases use `pipeline = 2`, so this confirms the preserved path has not regressed.

- [ ] **Step 6: Inspect the scoped diff and commit**

Run:

```powershell
git diff --check
git diff -- accelerator/src/main/scala/core/CIMcore.scala accelerator/src/test/scala/core/CIMCoreTest.scala
git status --short
```

Expected: only the single-stage branch and, if used, an explicit test-name clarification are changed; no generated Verilog, `target/`, `test_run_dir/`, or `project/` output is staged.

Commit:

```bash
git add accelerator/src/main/scala/core/CIMcore.scala accelerator/src/test/scala/core/CIMCoreTest.scala
git commit -m "fix: support MACTreeFlood pipeline-1 execution"
```

## Plan Self-Review

- Spec coverage: Task 1 preserves the `pipeline >= 1` contract, prevents second-stage indexing in the single-stage branch, leaves the default two-stage configuration unchanged, and specifies real golden plus multi-stage regression coverage.
- Scope: wrapper heap usage and SBT JAR replacement are explicitly excluded; no unrelated accelerator refactor is planned.
- Type consistency: the plan uses existing Chisel `Vec`, `SInt`, `Queue`, `Decoupled`, `stageStates`, `stageCounters`, `accReg`, and `outputFifo` names from `MACTreeFlood`.
- Placeholder scan: no incomplete implementation steps or undecided APIs remain.

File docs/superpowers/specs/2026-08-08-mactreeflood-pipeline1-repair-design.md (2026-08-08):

# MACTreeFlood 单级流水修复设计

## 背景与证据

`CIMCoreSpec` 以 `pipeline = 1` 构造 `CIMCore`，其内部实例化 `MACTreeFlood`。`MACTreeFlood` 的构造参数契约允许 `pipeline >= 1`，但其第一级完成分支无条件读取和写入 `stageStates(1)`、`stageCounters(1)`。当 `pipeline = 1` 时，这些 `Vec` 仅有索引 0，Chisel elaboration 在 `CIMcore.scala:410` 抛出 `IndexOutOfBoundsException: 1`。

同文件的既有参考实现对单级流水有独立分支，说明单级参数并非无效测试输入。

## 目标

保持 `MACTreeFlood(pipeline = 1)` 的已声明能力：对一组 `paral` 输入执行时分复用乘加，在 `tLatency` 个周期完成累计，经现有量化/输出路径输出一个结果。

## 非目标

- 不改变默认 `Config.pipeline = 2`、`Config.tLatency = 4` 或 AXKU15 架构。
- 不重构多级流水路径，不改动 `MACTreeRefine`。
- 不在本修复中处理 `MacMachineWrapperTest` 的 Treadle 堆内存需求或 SBT JAR 替换竞态；它们作为独立环境问题保留。

## 方案比较

1. **推荐：实现单级专用分支。** 当 `pipeline == 1` 时，使用现有输入握手、累加寄存器、量化与 FIFO 输出接口，且绝不索引第 1 级；`pipeline >= 2` 时保留当前多级实现。这与模块公开契约和既有参考模式一致。
2. **收紧参数约束为 `pipeline >= 2`。** 代码改动小，但会使现有 `CIMCoreSpec` 的合法场景失效，并与构造函数当前声明及参考实现不一致。
3. **只改测试为 `pipeline = 2`。** 掩盖模块参数契约缺陷，且丢失单级路径回归覆盖。

采用方案 1。

## 接口与时序约束

- 模块端口、寄存器宽度与 `Decoupled` 握手语义保持不变。
- `pipeline == 1` 分支的状态存取只能使用索引 0；不能构造或访问不存在的第二级状态。
- 单级路径按 `paral / tLatency` 划分每周期操作数；不足整除时，必须在 elaboration 时拒绝非法参数或明确处理余数。本次回归参数 `paral = 2, tLatency = 2` 可整除。
- 完成时复用既有输出 FIFO 和量化截断定义，避免新增数值语义。

## 测试与验收

1. 先运行现有 `CIMCoreSpec` 中 `pipeline = 1` 的矩阵向量测试，确认它因数组越界失败（RED）。
2. 最小实现单级分支后，重复运行该测试，验证无 elaboration 越界且数值输出与测试中的矩阵向量 golden 一致（GREEN）。
3. 再运行 `CIMCoreSpec` 全部测试，确认 `pipeline = 2` 的流式和 ping-pong 测试不回归。
4. 所有验证使用可观察的 SBT 前台模式；若 Windows JAR 原子替换竞态再次阻塞，将记录为环境阻塞，不将其归因于 RTL。

## 风险控制

单级与多级路径由 Scala elaboration-time 的 `if (pipeline == 1)` 分开，避免为不存在的级创建硬件索引。改动只限 `MACTreeFlood` 与与之对应的定向测试。

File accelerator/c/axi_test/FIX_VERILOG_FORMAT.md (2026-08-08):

# Verilog文件格式修复说明

## 问题诊断

### 发现的问题：

1. **文件包含.rodata段（字符串数据）**
   - `@00000000` ~ `@000009A0`：代码段（.text），约2464字节
   - `@000009A0` ~ 文件末尾：只读数据段（.rodata），包含字符串常量
   - 第4099行位于.rodata段，包含ASCII字符串数据

2. **`$readmemh`警告原因**
   - `.rodata`段包含ASCII字符串（如`"MCAUSE"`, `"MEPC"`等）
   - 这些数据不是有效的机器码，导致`$readmemh`解析失败

3. **PC卡在0x00001000的原因**
   - 指令值`0x0000000000300000`看起来无效
   - 可能是MROM跳转未正确执行

## 解决方案

### 方案1：只提取代码段（已实施）

已修改`Makefile`，只提取`.text`段：

```makefile
$(OBJCOPY) -j .text -O verilog $< $@
```

**优点：**
- 文件只包含机器码，没有字符串数据
- `$readmemh`可以正确解析
- 文件大小减小

**缺点：**
- 如果程序需要访问.rodata中的字符串，可能会出问题
- 但通常.rodata字符串在运行时不需要，或者可以移到DTCM

### 方案2：修改链接脚本（备选）

如果需要保留.rodata，可以将其移到DTCM：

```ld
.text : ALIGN(4)
{
    KEEP(*(.text.init))
    *(.text)
    *(.text.*)
    . = ALIGN(4);
    __text_end = .;
} > itcm

.rodata : ALIGN(4)
{
    *(.rodata)
    *(.rodata.*)
} > dtcm AT > itcm
```

## 操作步骤

### 1. 重新生成verilog文件

```bash
cd c/axi_test
make clean
make verilog
# 或者
make sim
```

### 2. 验证新文件

```bash
# 检查文件大小（应该比之前小很多）
wc -l axi_test.verilog

# 检查地址标记（应该只有@00000000）
grep "^@" axi_test.verilog

# 查看文件末尾（应该是正常的十六进制数据）
tail -10 axi_test.verilog
```

**预期结果：**
- 文件应该只有几百行（而不是8637行）
- 只有一个地址标记：`@00000000`
- 文件末尾是正常的十六进制数据

### 3. 重新运行仿真

```bash
cd vsim/run
# 运行仿真
# 检查是否还有警告
```

**预期结果：**
- 不应该再有"Illegal entry"警告
- ITCM数据应该正确加载

## 验证检查点

### ✅ 文件格式检查
- [ ] 文件只有`.text`段数据
- [ ] 没有.rodata段数据
- [ ] 只有一个`@00000000`地址标记
- [ ] 所有数据都是有效的十六进制

### ✅ 仿真检查
- [ ] 没有`$readmemh`警告
- [ ] ITCM数据正确加载
- [ ] PC能够正确跳转到0x80000000
- [ ] 程序能够正常执行

## 如果仍有问题

### PC仍然卡在0x00001000

如果修复后PC仍然卡在0x00001000，可能的原因：

1. **MROM跳转未执行**
   - 检查MROM代码是否正确
   - 验证CPU是否从0x00000000开始执行

2. **ITCM地址映射问题**
   - 检查ITCM物理地址是否正确映射
   - 验证PC=0x80000000时ITCM索引是否正确

3. **数据加载问题**
   - 检查ITCM[0]是否包含有效指令
   - 验证数据是否正确加载到ITCM数组

### 调试建议

1. **添加调试输出**
   ```verilog
   $display("ITCM[0] = 0x%016h", `ITCM.mem_r[0]);
   $display("PC=0x80000000 -> ITCM索引=%d", 32'h80000000[13:3]);
   ```

2. **检查MROM执行**
   ```verilog
   if (pc < 32'h00001000) begin
       $display("MROM执行: PC=0x%08h", pc);
   end
   ```

3. **查看波形**
   - 使用Verdi查看PC信号
   - 检查ITCM数据
   - 验证MROM访问

## 总结

主要修复：
- ✅ 修改Makefile，只提取`.text`段
- ✅ 排除`.rodata`段（字符串数据）
- ✅ 生成纯机器码文件

下一步：
1. 重新生成verilog文件
2. 验证文件格式
3. 重新运行仿真
4. 如果PC仍然卡住，检查MROM和地址映射

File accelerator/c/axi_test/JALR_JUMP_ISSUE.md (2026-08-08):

# JALR跳转问题分析

## 当前状态

### ✅ 已解决的问题
1. **文件格式问题**：已修复，ITCM数据成功加载
2. **MROM执行**：MROM[0]和MROM[1]都正确执行
3. **寄存器值**：t0寄存器值正确（0x80000000）

### ❌ 仍存在的问题
**PC卡在0x00001004，JALR指令执行后跳转未发生**

## 问题详细分析

### MROM代码
- **MROM[0]** (0x00001000): `auipc t0, 0x7ffff` (0x7ffff297)
  - 执行结果：`t0 = 0x00001000 + 0x7ffff000 = 0x80000000` ✅
- **MROM[1]** (0x00001004): `jr t0` (0x00028067 = `jalr x0, 0(t0)`)
  - t0值：0x80000000 ✅
  - 跳转目标：0x80000000 ✅
  - **但跳转未发生** ❌

### JALR指令执行流程（根据代码分析）

1. **IFU阶段（指令获取）**：
   - JALR指令被识别
   - 如果rs1 != x0或x1（这里是x5），需要等待EXU阶段解析
   - BPU设置`bpu_wait`信号，等待寄存器值

2. **EXU阶段（指令执行）**：
   - 读取t0寄存器值
   - 计算跳转目标地址 = rs1 + imm = t0 + 0 = 0x80000000
   - 将最低位清零（地址对齐）

3. **流水线刷新**：
   - JALR指令在EXU阶段执行后，需要检查预测是否正确
   - 如果预测正确，不需要刷新流水线
   - 如果预测错误，需要刷新流水线

### 可能的原因

#### 1. JALR指令预测问题
- JALR指令在IFU阶段被预测为跳转，但目标地址可能不正确
- 在EXU阶段执行后，发现预测正确，但跳转没有发生

#### 2. 流水线刷新问题
- JALR指令执行后，流水线刷新没有正确执行
- 跳转目标地址计算正确，但PC没有更新

#### 3. 地址映射问题
- 跳转目标地址0x80000000可能不在正确的地址映射范围内
- ITCM地址映射可能有问题

#### 4. 指令提交问题
- JALR指令可能没有正确提交
- 指令执行完成，但PC没有更新

## 调试建议

### 1. 检查JALR指令的实际执行路径

添加监控代码检查：
- JALR指令是否被正确识别
- 跳转目标地址计算是否正确
- 流水线刷新是否发生

### 2. 检查地址映射

确认：
- 地址0x80000000是否在ITCM地址范围内
- ITCM地址映射配置是否正确

### 3. 检查指令提交

监控：
- JALR指令是否提交（`cmt_i_valid`）
- 跳转预测是否正确（`cmt_i_bjp_prdt` vs `cmt_i_bjp_rslv`）
- 流水线刷新请求是否发出（`pipe_flush_req`）

### 4. 检查MROM代码

验证：
- MROM[1]的指令编码是否正确（0x00028067）
- 指令解码是否正确（`jalr x0, 0(t0)`）

## 下一步操作

1. **添加更详细的监控**：
   - 监控JALR指令的执行状态
   - 监控流水线刷新信号
   - 监控跳转目标地址计算

2. **检查地址映射配置**：
   - 确认ITCM地址范围
   - 检查地址解码逻辑

3. **分析仿真波形**：
   - 使用Verdi查看波形
   - 检查JALR指令执行时的信号变化
   - 检查PC更新逻辑

4. **可能的解决方案**：
   - 如果JALR指令预测有问题，可能需要修改MROM代码
   - 如果地址映射有问题，可能需要修改地址映射配置
   - 如果流水线刷新有问题，可能需要检查流水线刷新逻辑

## 关键检查点

- [ ] JALR指令是否被正确识别
- [ ] 跳转目标地址计算是否正确（0x80000000）
- [ ] 流水线刷新是否发生
- [ ] PC是否更新到0x80000000
- [ ] ITCM地址映射是否正确
- [ ] 指令提交是否成功

## 参考代码位置

- JALR指令预测：`rtl/e203/core/e203_ifu_litebpu.v`
- JALR指令执行：`rtl/e203/core/e203_exu_alu.v`
- 流水线刷新：`rtl/e203/core/e203_exu_branchslv.v`
- PC更新：`rtl/e203/core/e203_ifu_ifetch.v`

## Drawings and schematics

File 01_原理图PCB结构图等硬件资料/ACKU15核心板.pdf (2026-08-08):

D | D

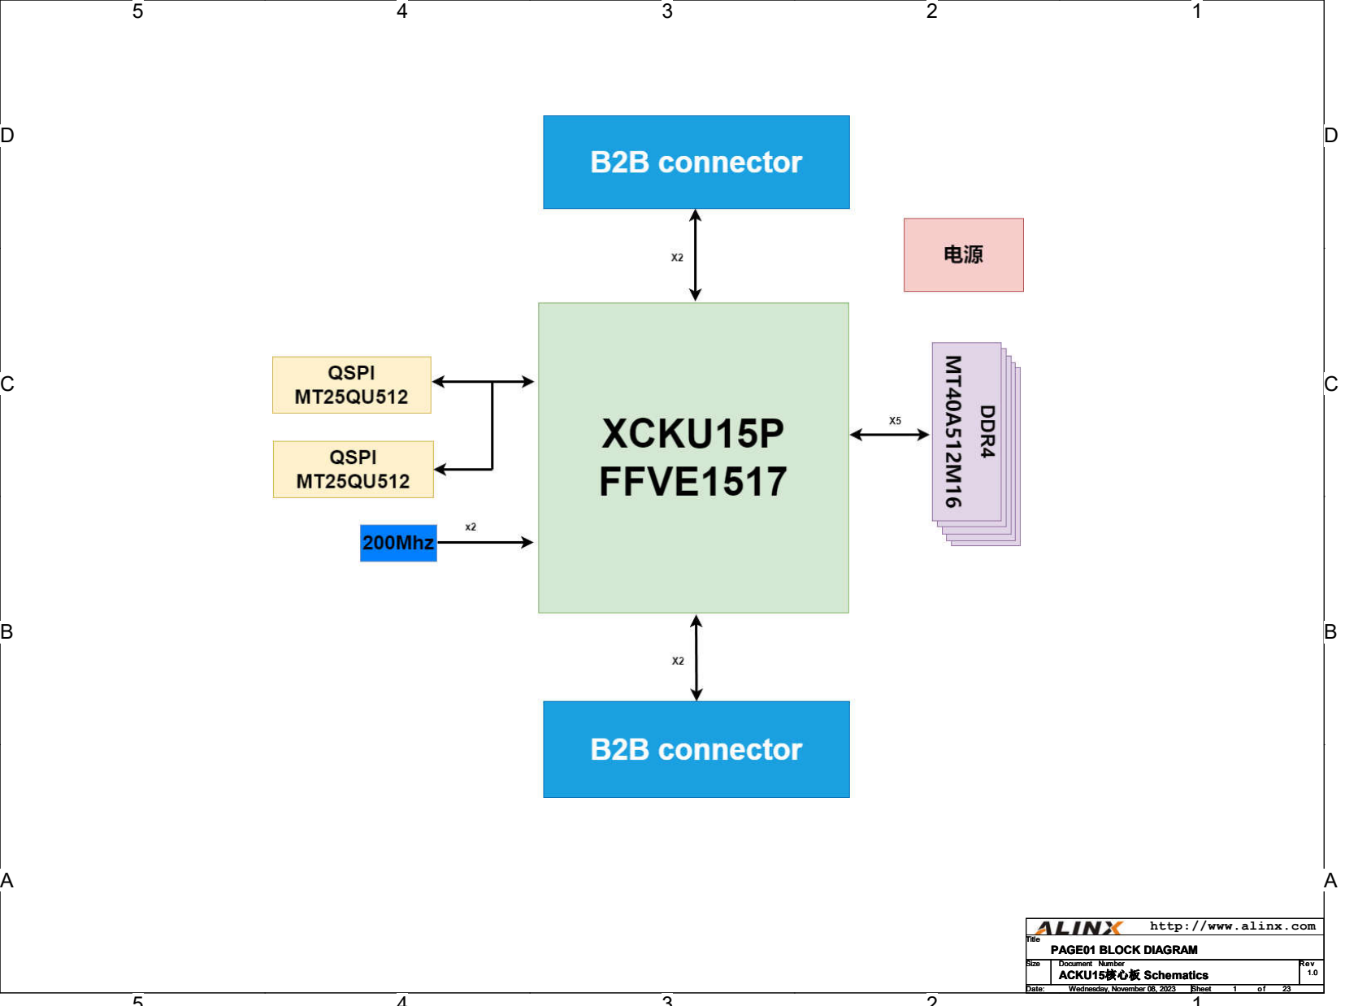
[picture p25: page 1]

C | C
B | B
A | A

## http://www.alinx.com Title

Size | Document Number ACKU15核心板 Schematics ACKU15核心板 Schematics ACKU15核心板 Schematics | R ev 1.0 1.0 1.0
Date: Wednesday, November 08, 2023 Wednesday, November 08, 2023 Wednesday, November 08, 2023 | Sheet 1 1 1 o f 23 23 23

## PAGE01 BLOCK DIAGRAM

Title

## PAGE01 BLOCK DIAGRAM

## PAGE01 BLOCK DIAGRAM

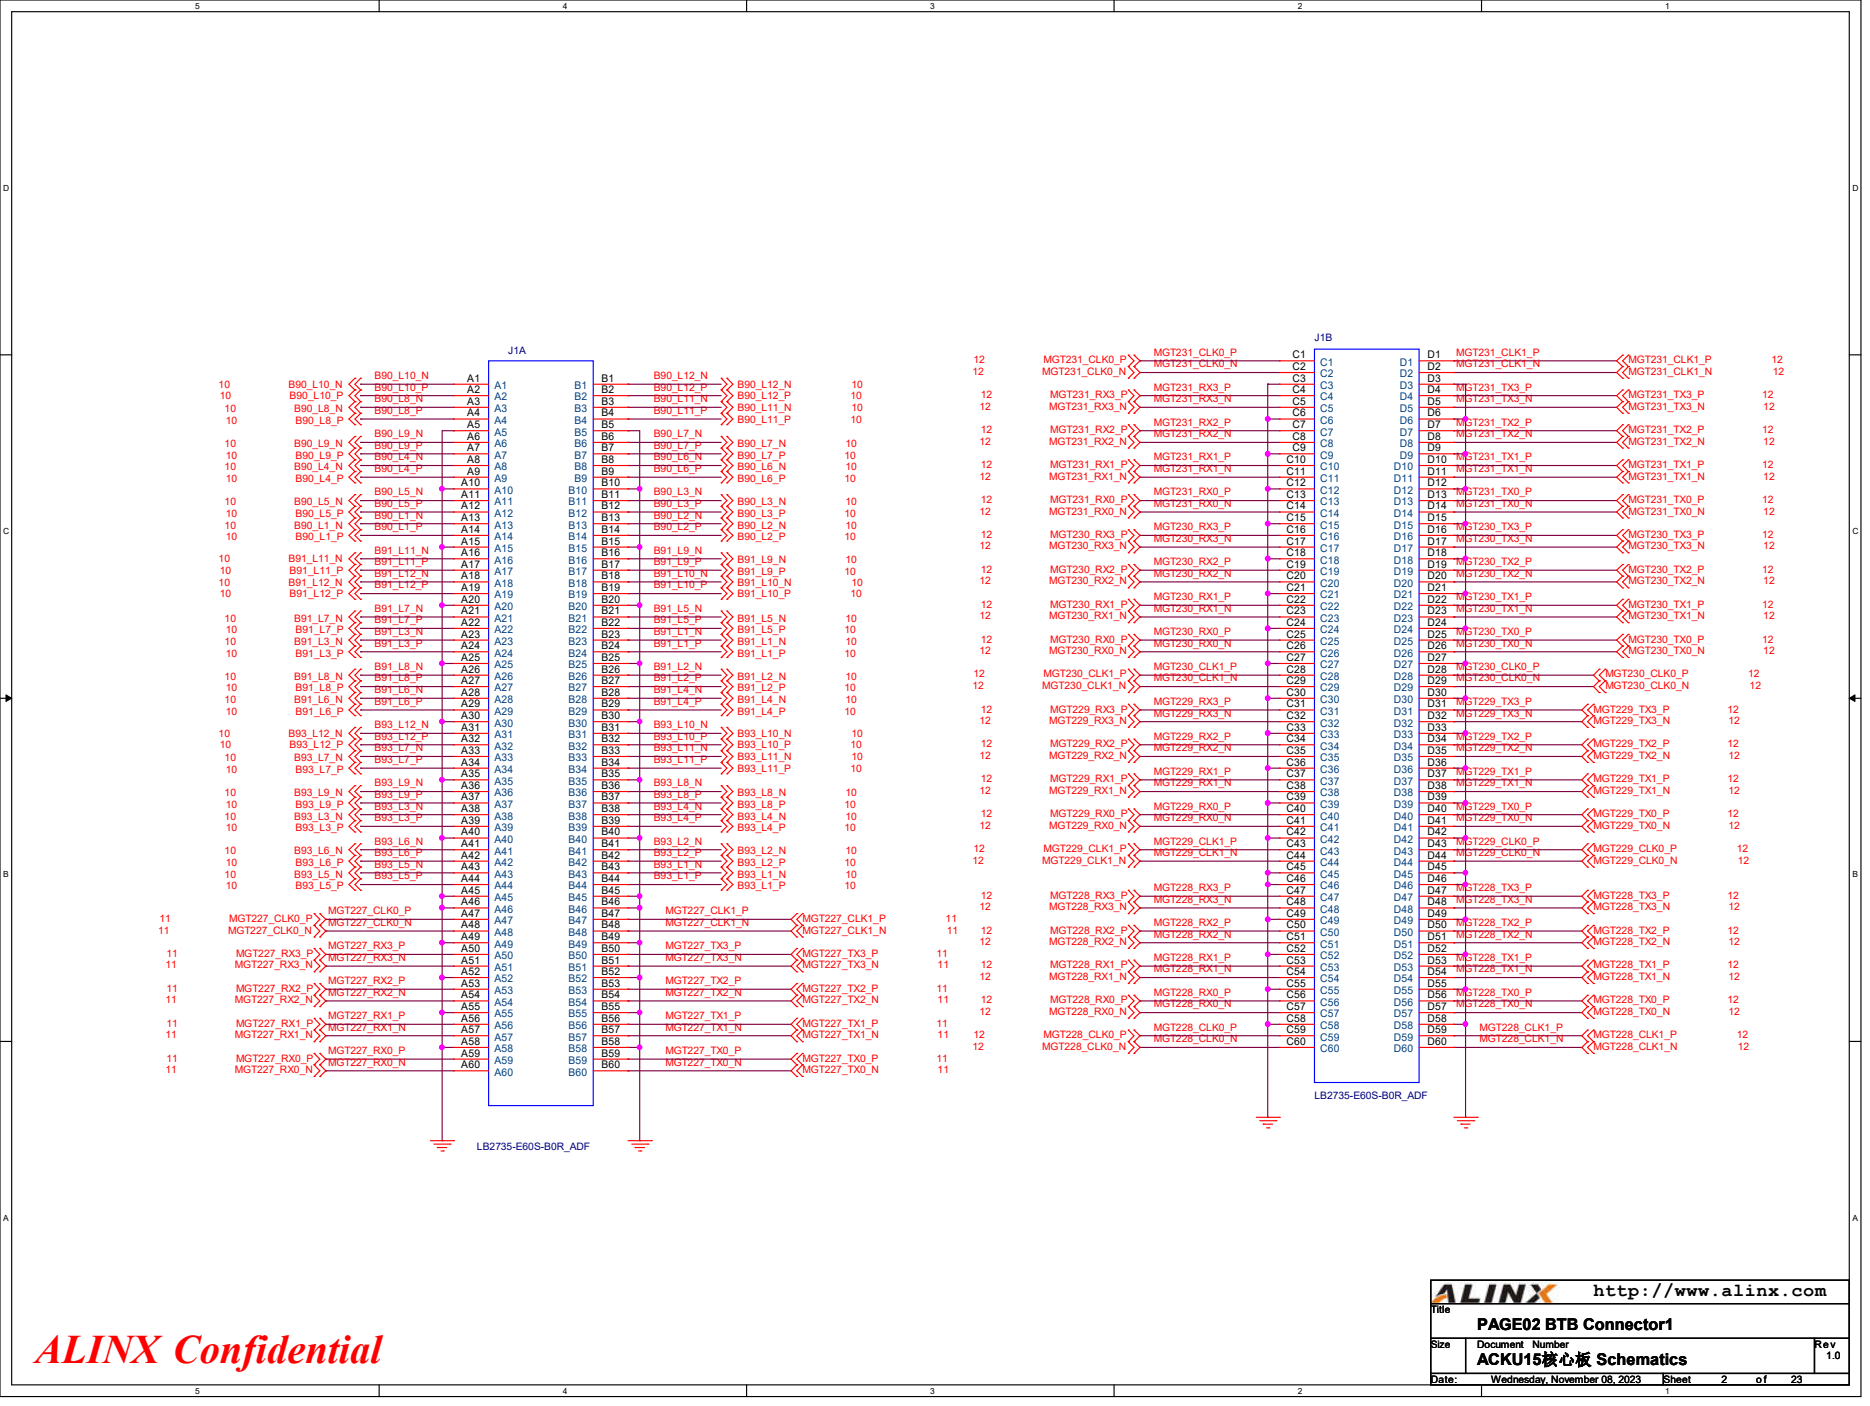
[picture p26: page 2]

http://www.alinx.com

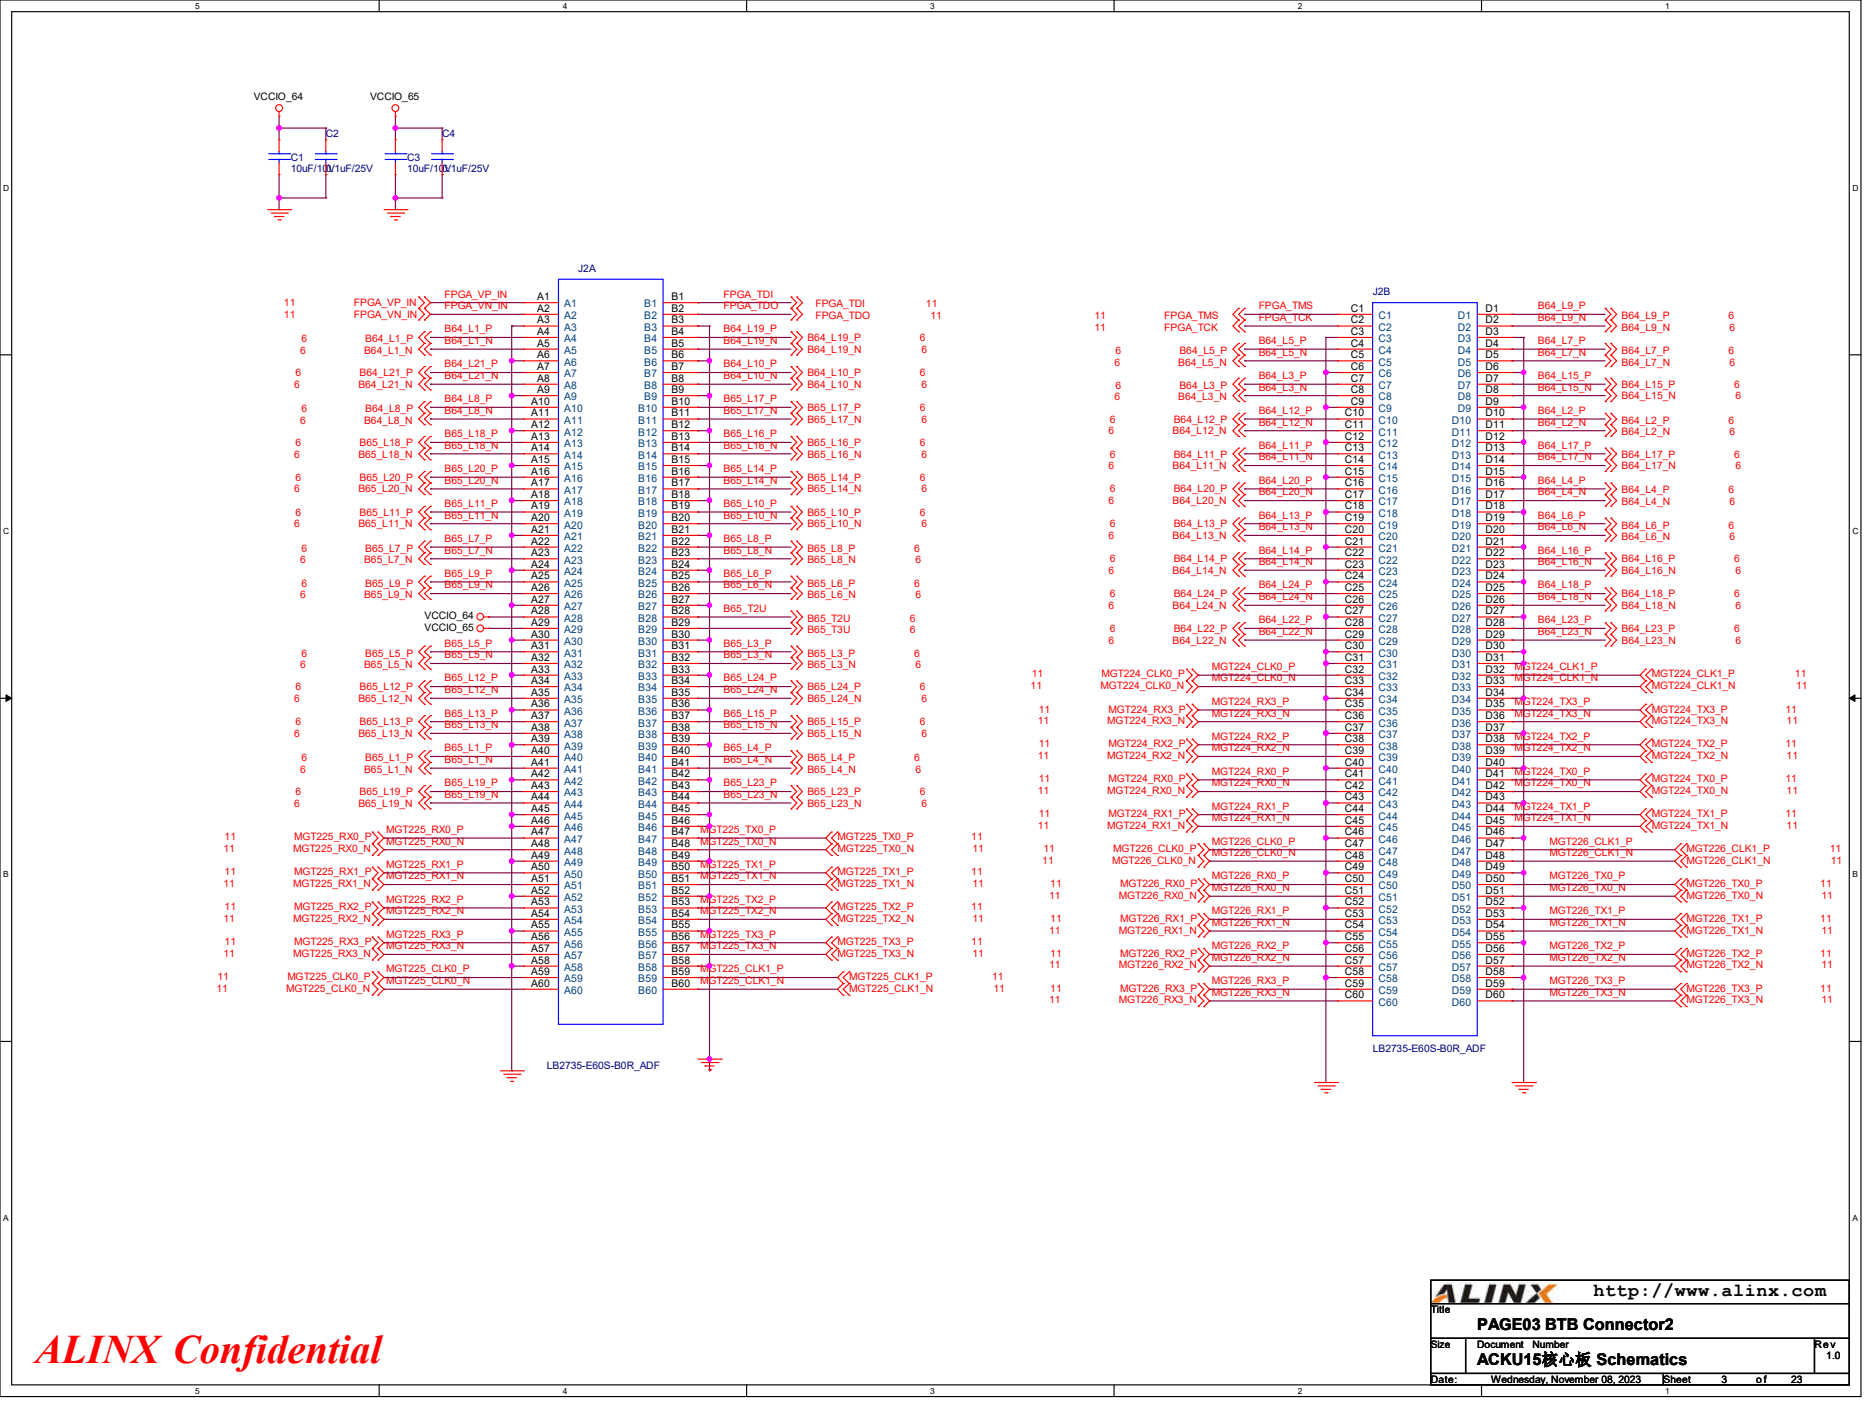
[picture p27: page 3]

http://www.alinx.com

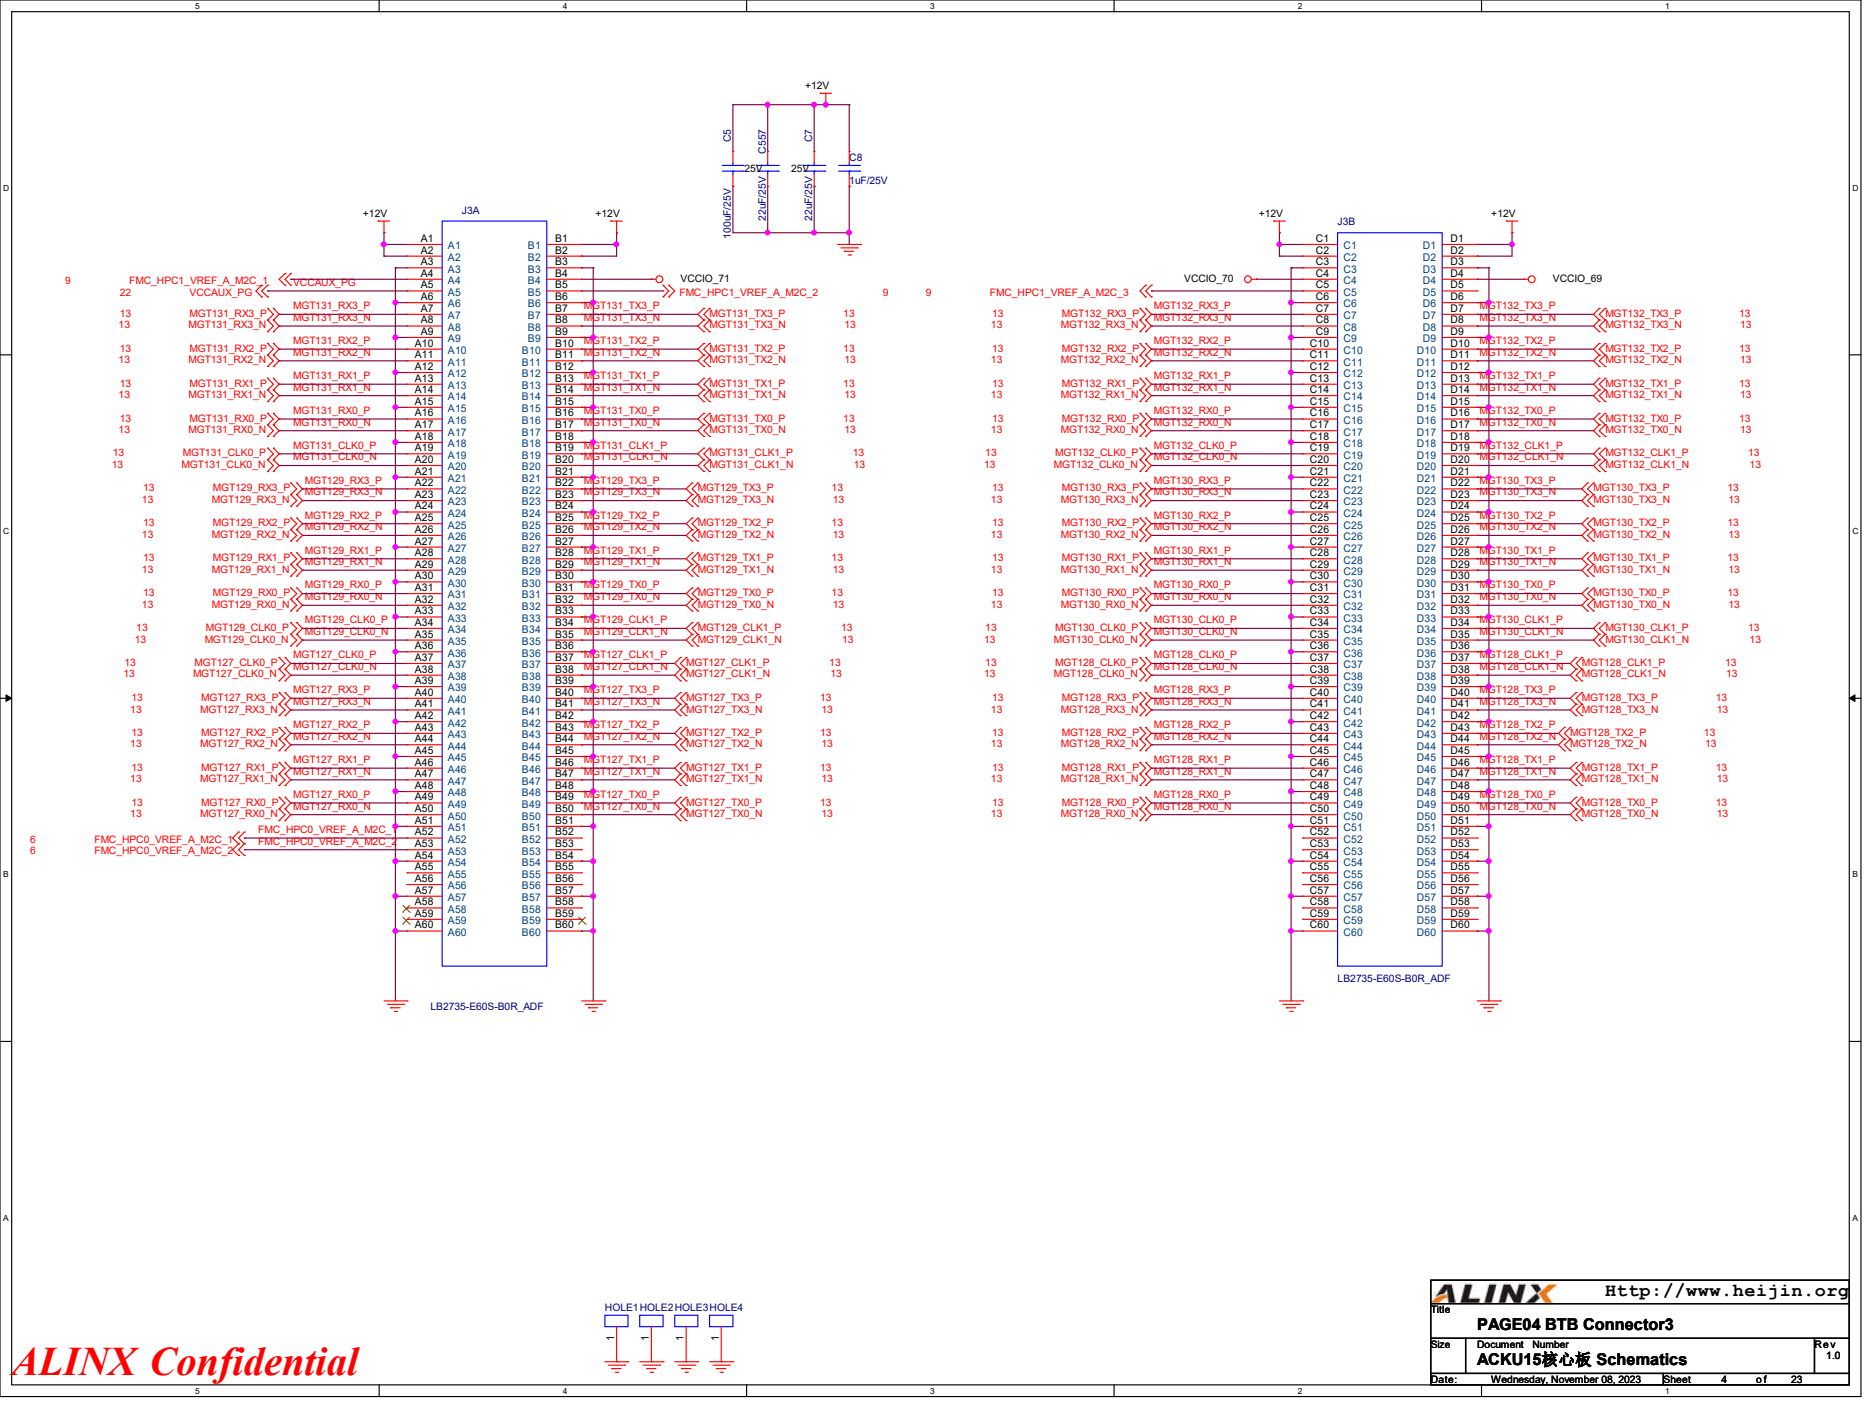
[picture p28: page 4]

Http://www.heijin.org

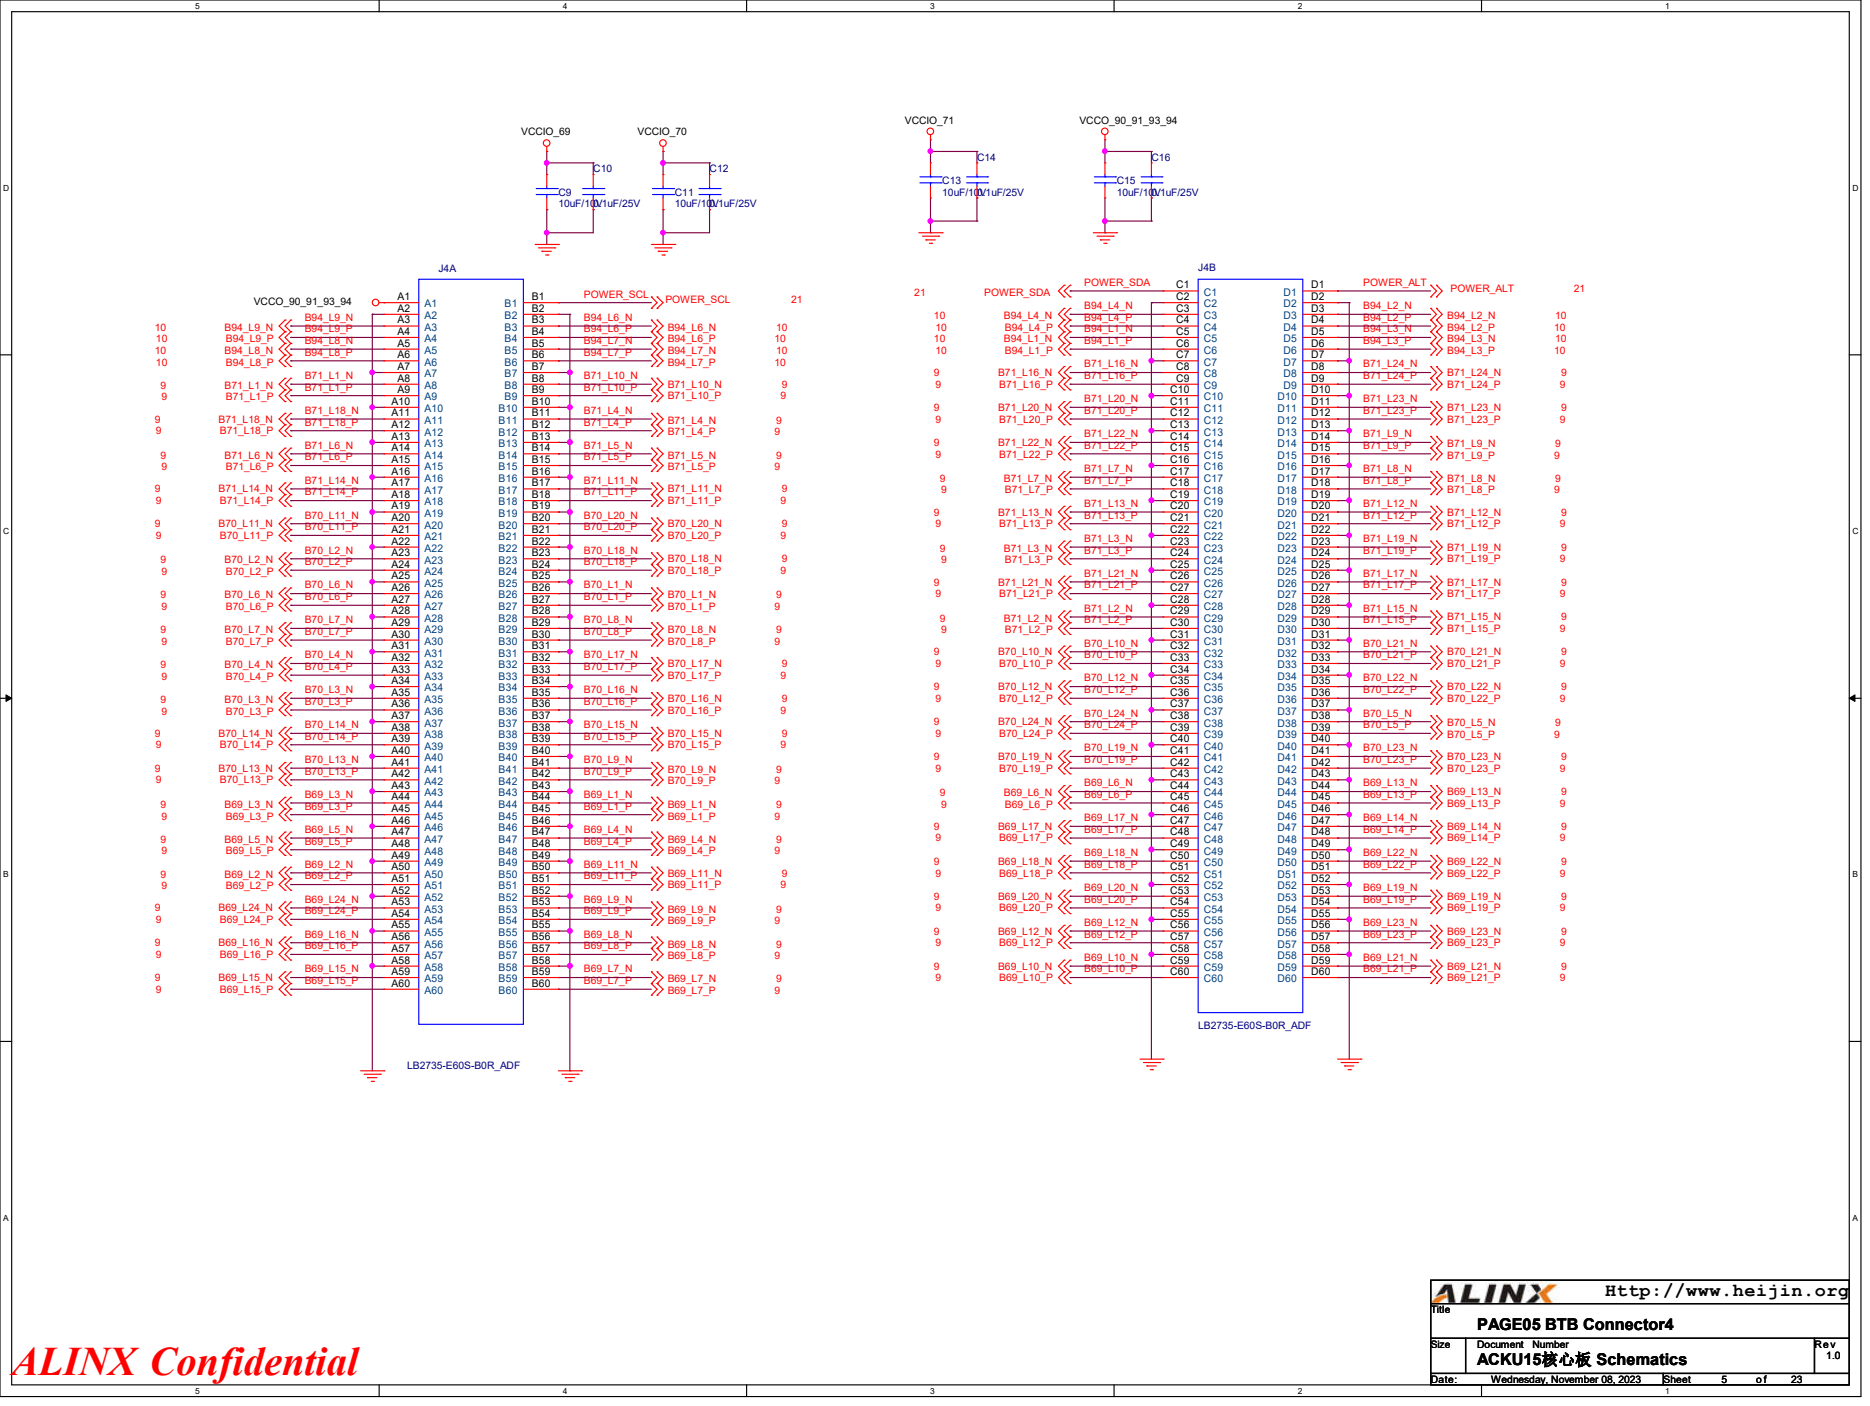
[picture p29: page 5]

Http://www.heijin.org

# C458 4.7uF/25V

# C459 0.1uF/25V

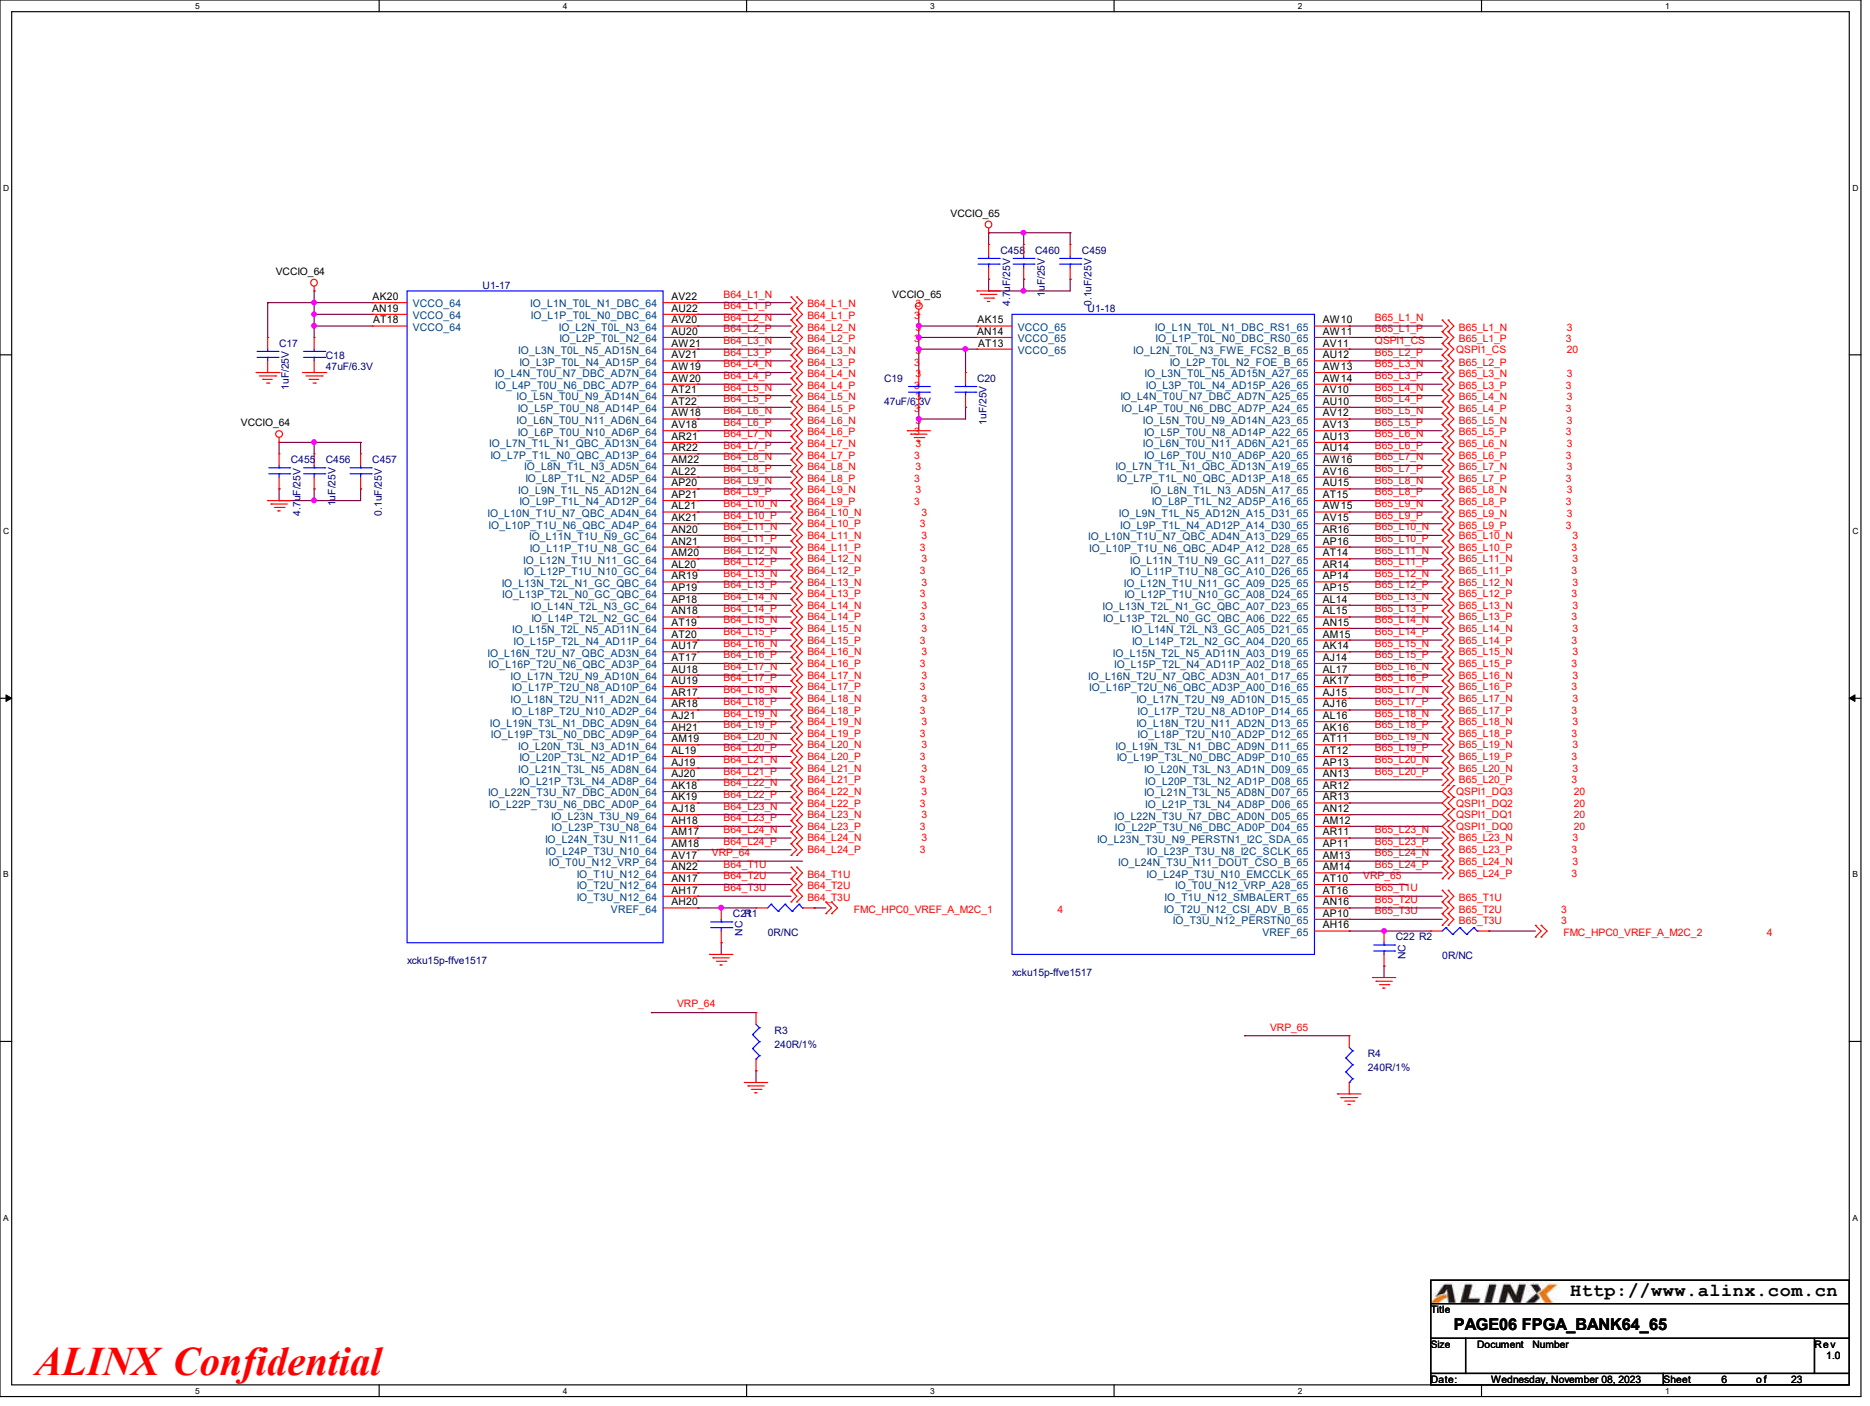
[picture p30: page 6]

Http://www.alinx.com.cn

# 80bit DDR4

# C254.7uF/25V

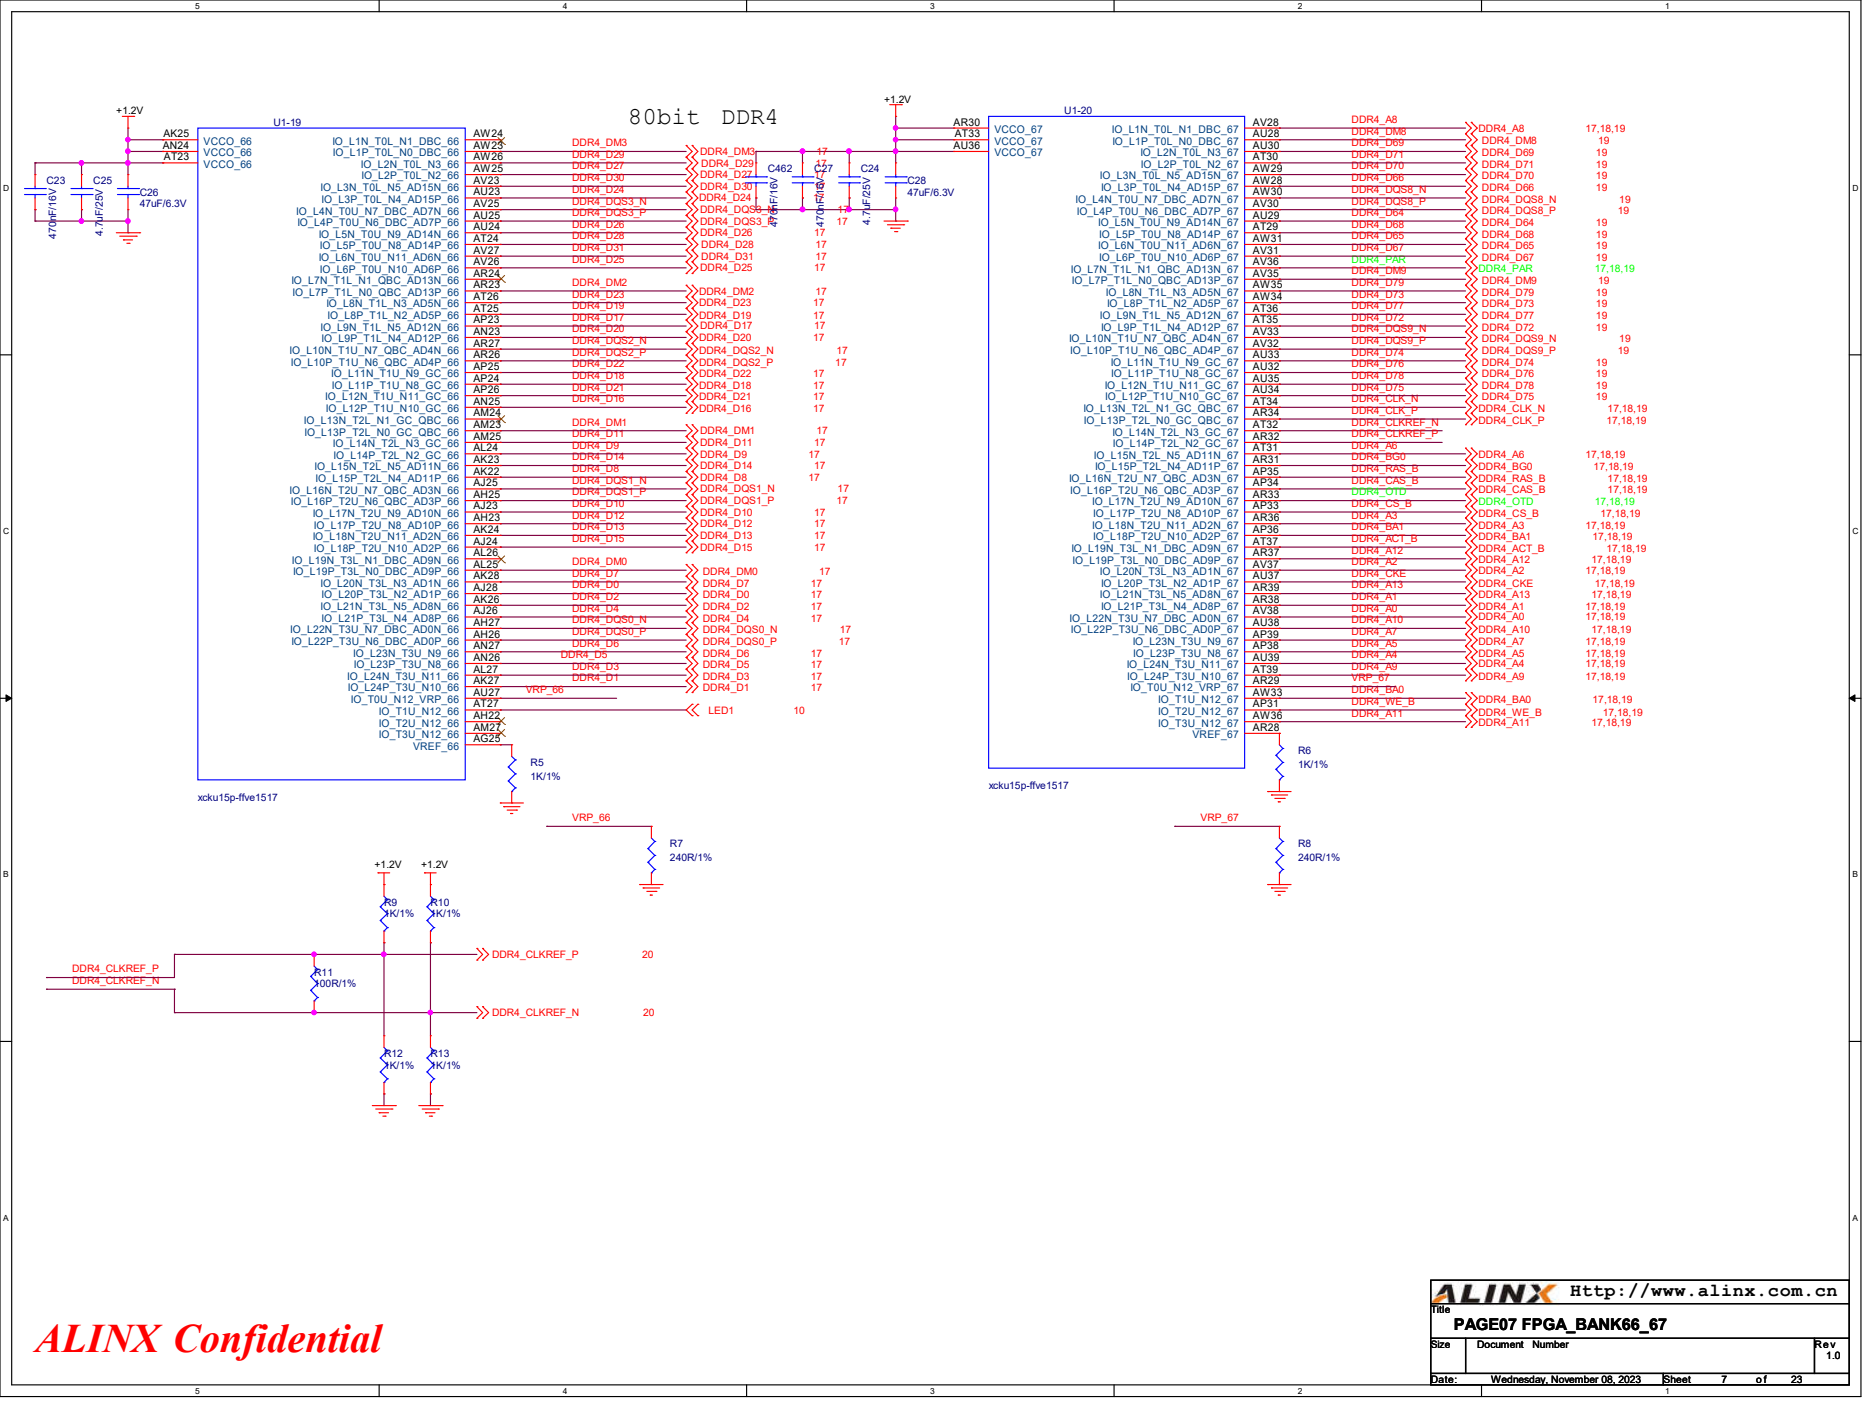
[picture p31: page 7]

Http://www.alinx.com.cn

# C461 470nF/16V

# C29470nF/16V

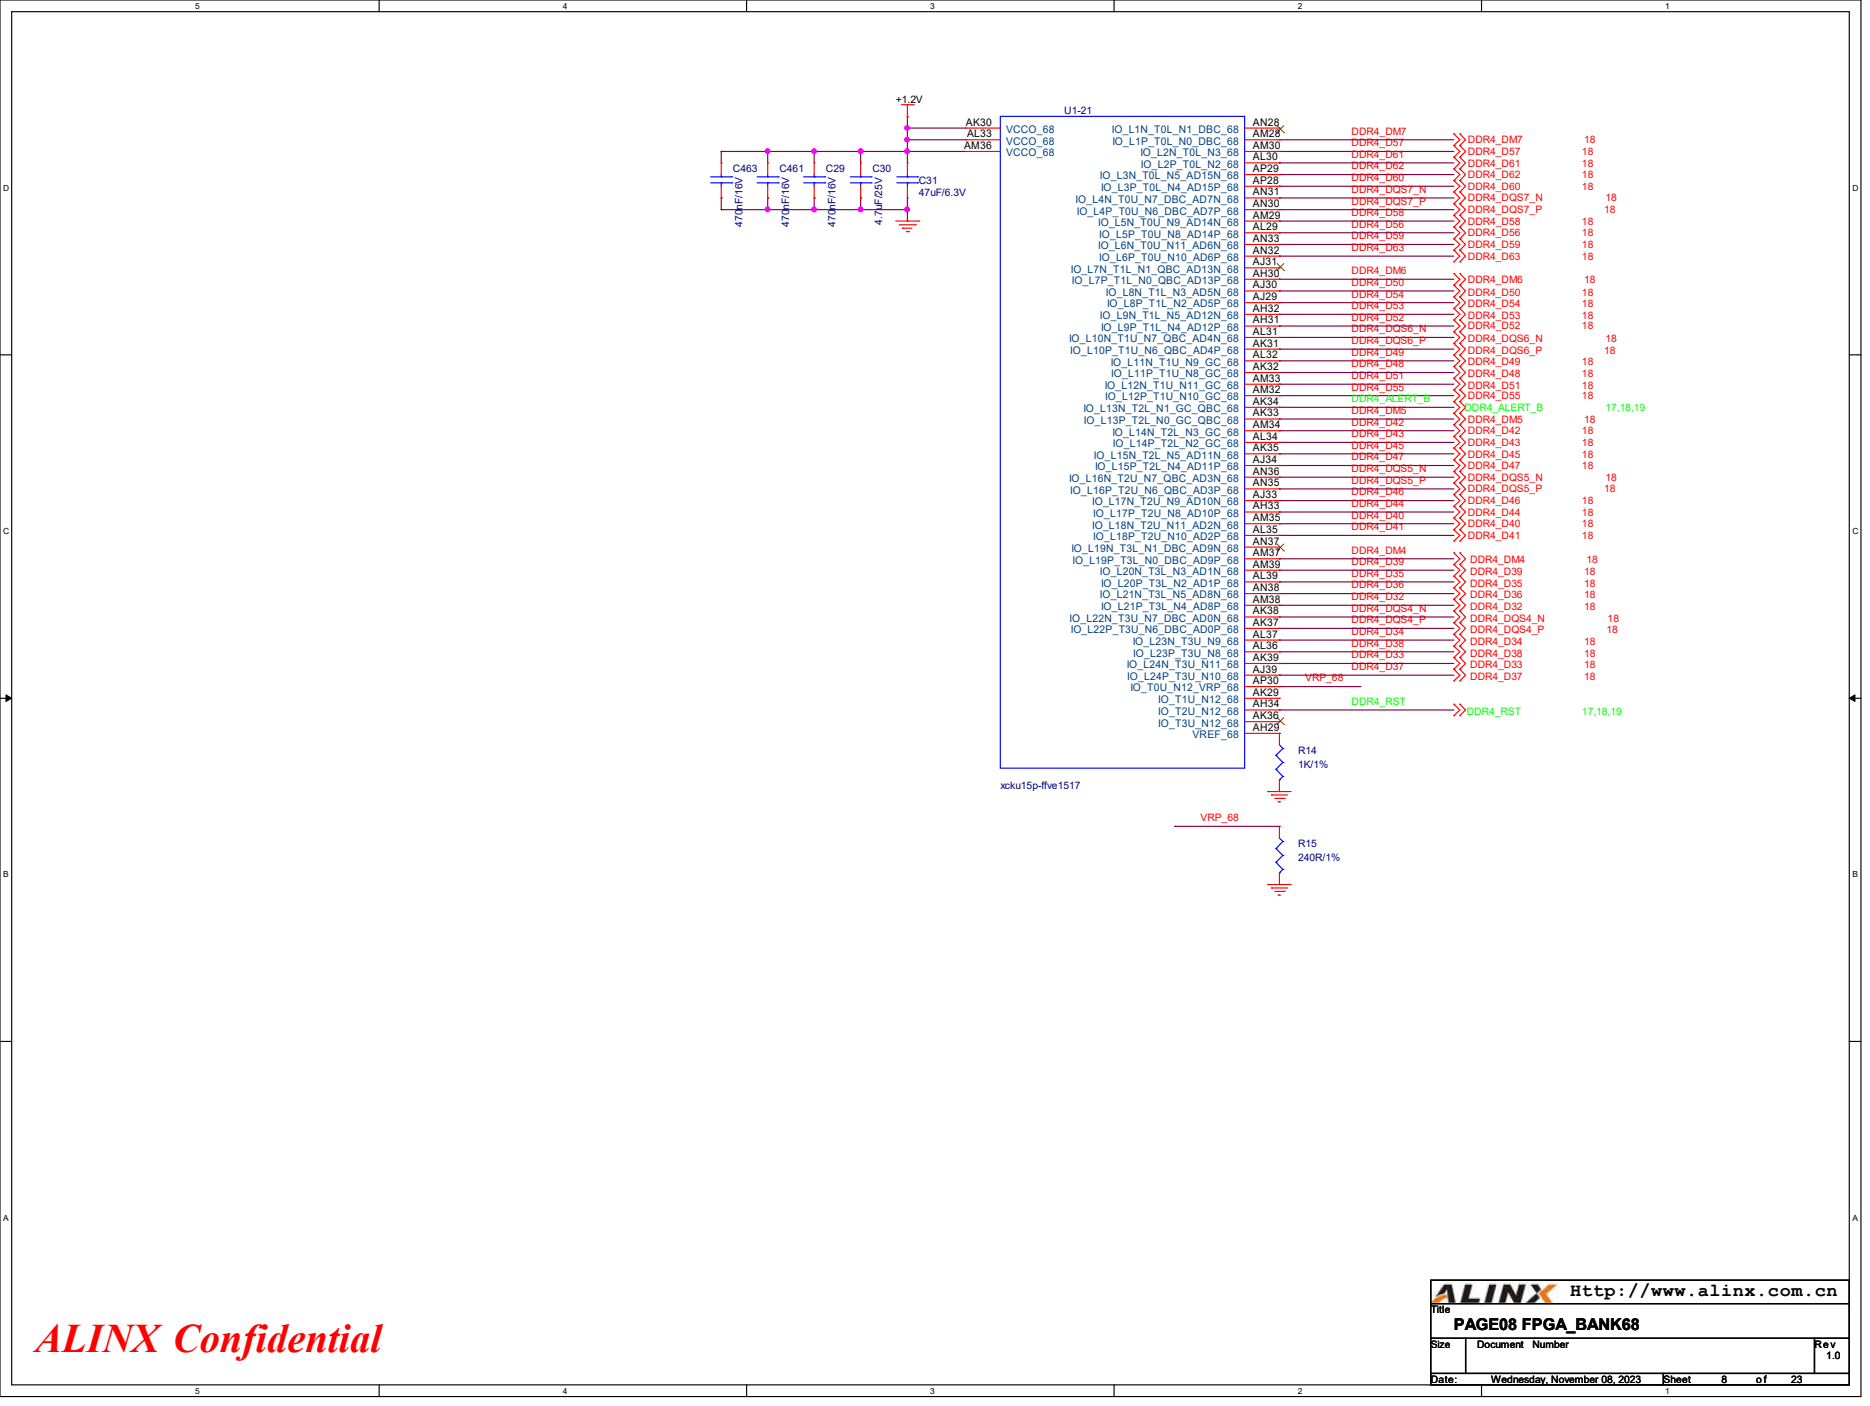
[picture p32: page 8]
VRP_68; DDR4_D59; DDR4_D57; DDR4_DM7; DDR4_D35; DDR4_D34; DDR4_D39; DDR4_D38; DDR4_D37; DDR4_D33; DDR4_DM4; DDR4_D36 DDR4_D32; DDR4_D51; DDR4_D50 DDR4_D54; DDR4_D55; DDR4_D53; DDR4_D49; DDR4_D42 DDR4_D43; DDR4_D41; DDR4_D47; DDR4_D46; DDR4_D40; DDR4_DM5; DDR4_D44; DDR4_D62 DDR4_D60; DDR4_D61; DDR4_D63; DDR4_D56; DDR4_D58; DDR4_DQS4_P; DDR4_DQS4_N; DDR4_DQS7_N DDR4_DQS7_P; DDR4_DQS5_N DDR4_DQS5_P; DDR4_D45; DDR4_DQS6_N DDR4_DQS6_P; DDR4_D52; DDR4_DM6; DDR4_D48; DDR4_RST; DDR4_ALERT_B; DDR4_D36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

Http://www.alinx.com.cn

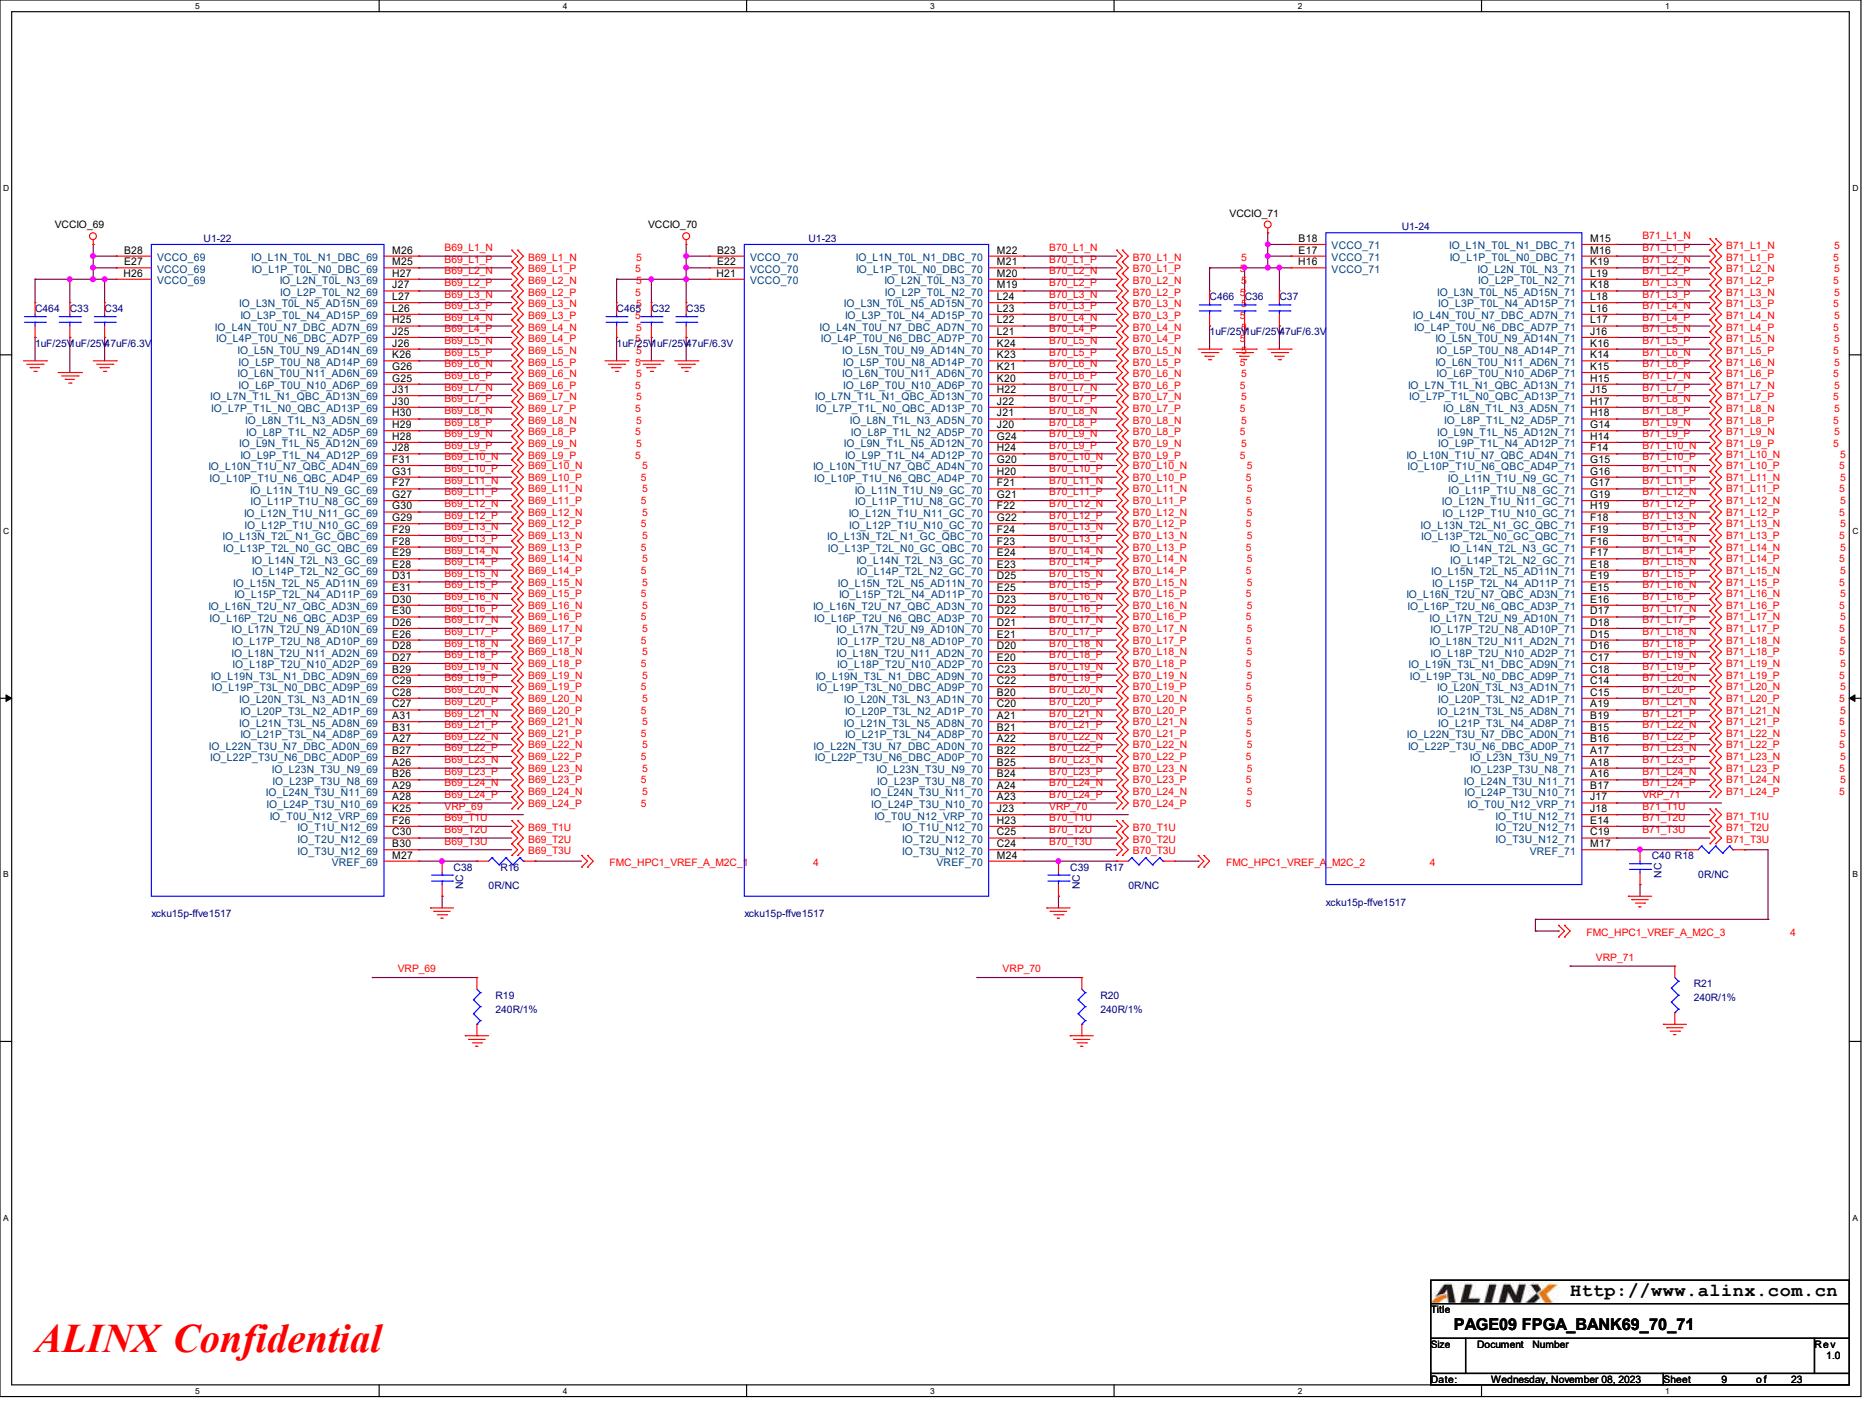
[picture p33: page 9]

Http://www.alinx.com.cn

# C411uF/25V

# C440.1uF/25V

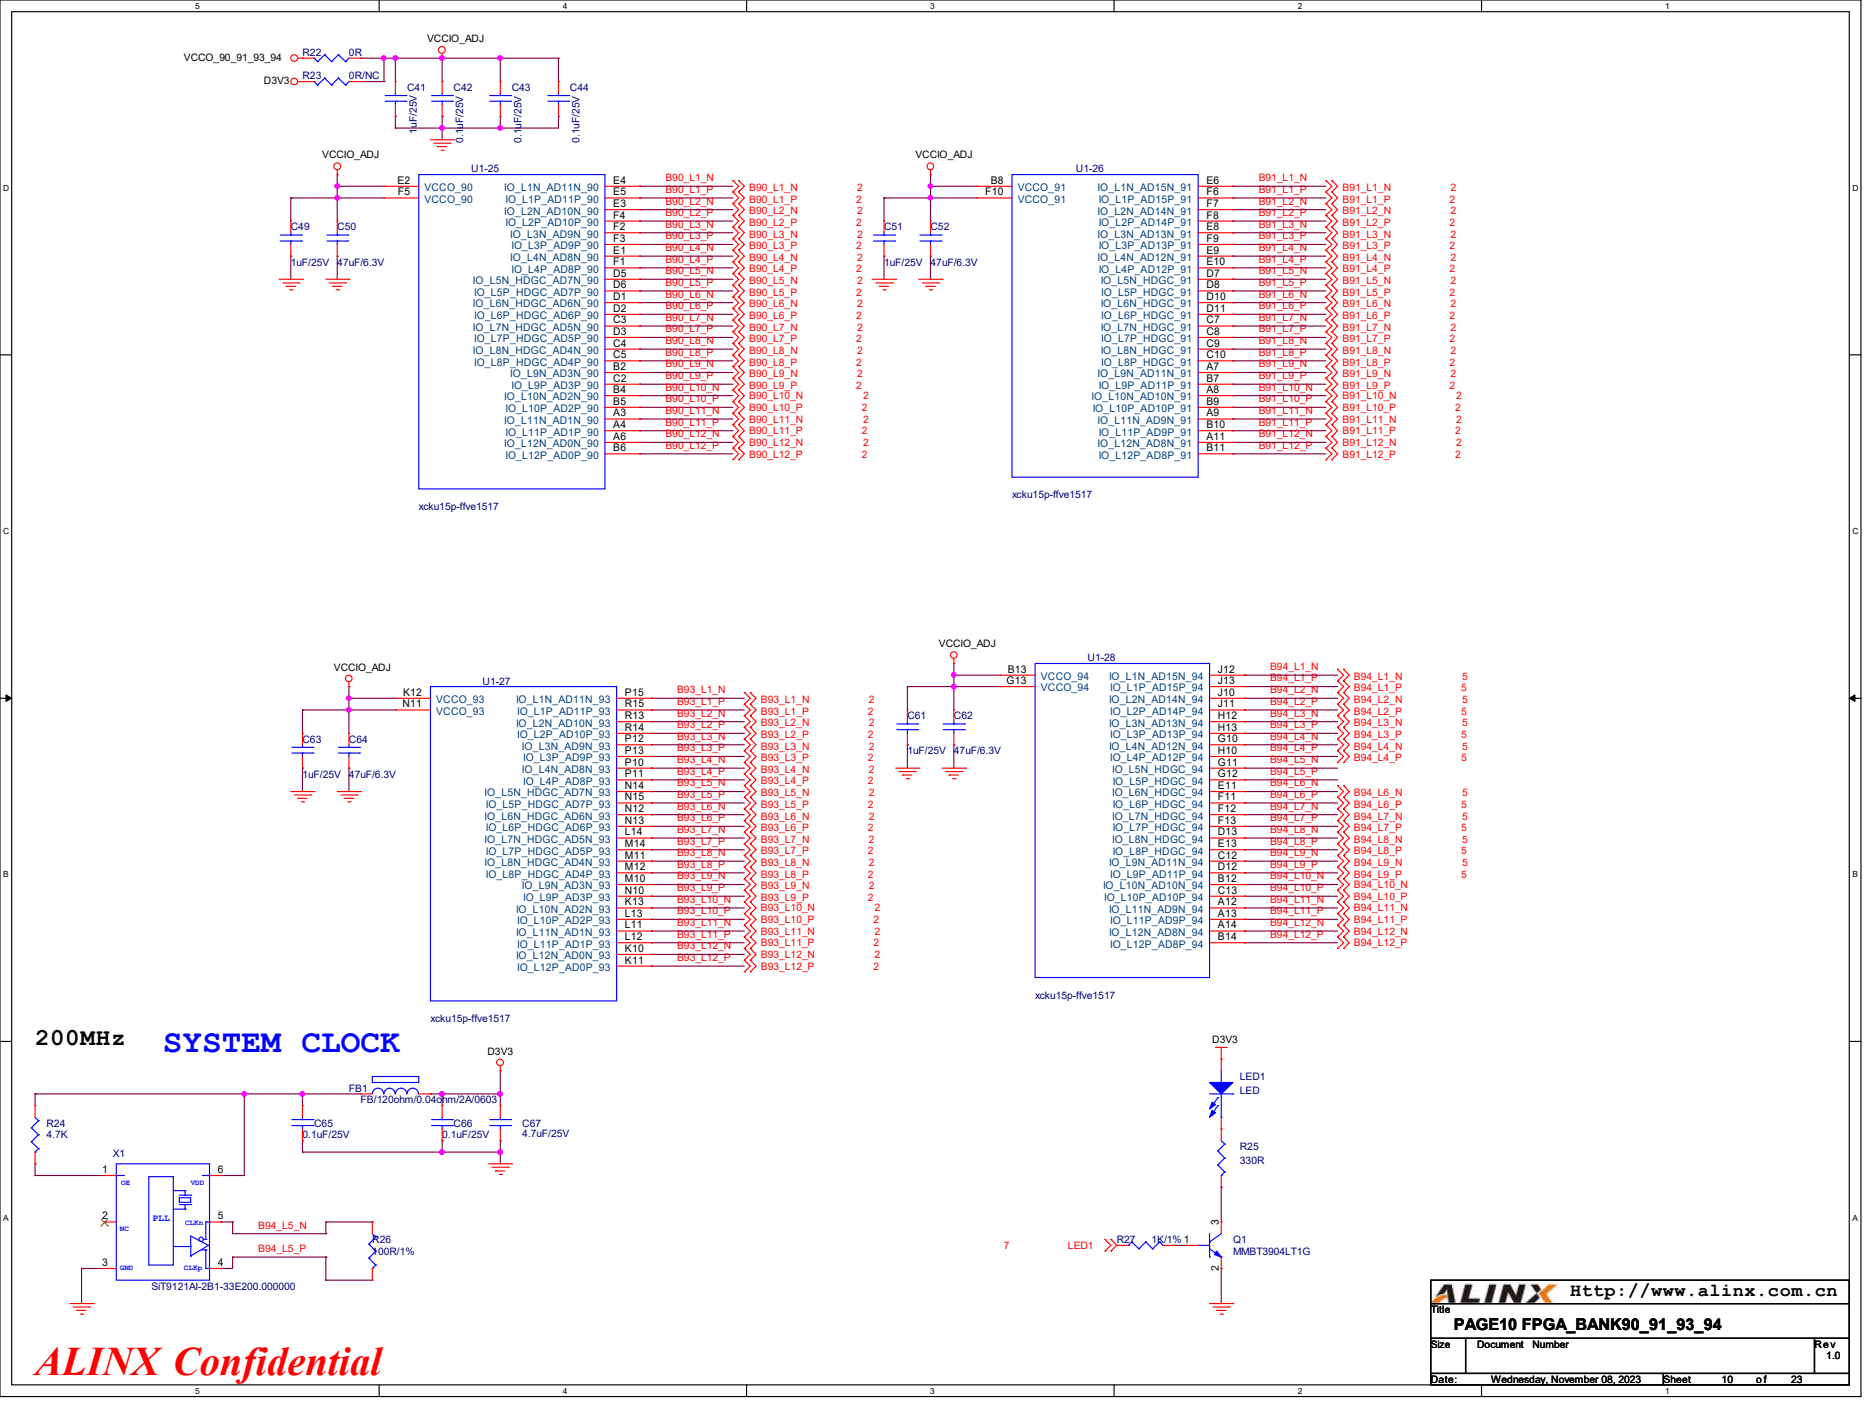
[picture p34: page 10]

Http://www.alinx.com.cn

# adc test

# C760.1uF/25V

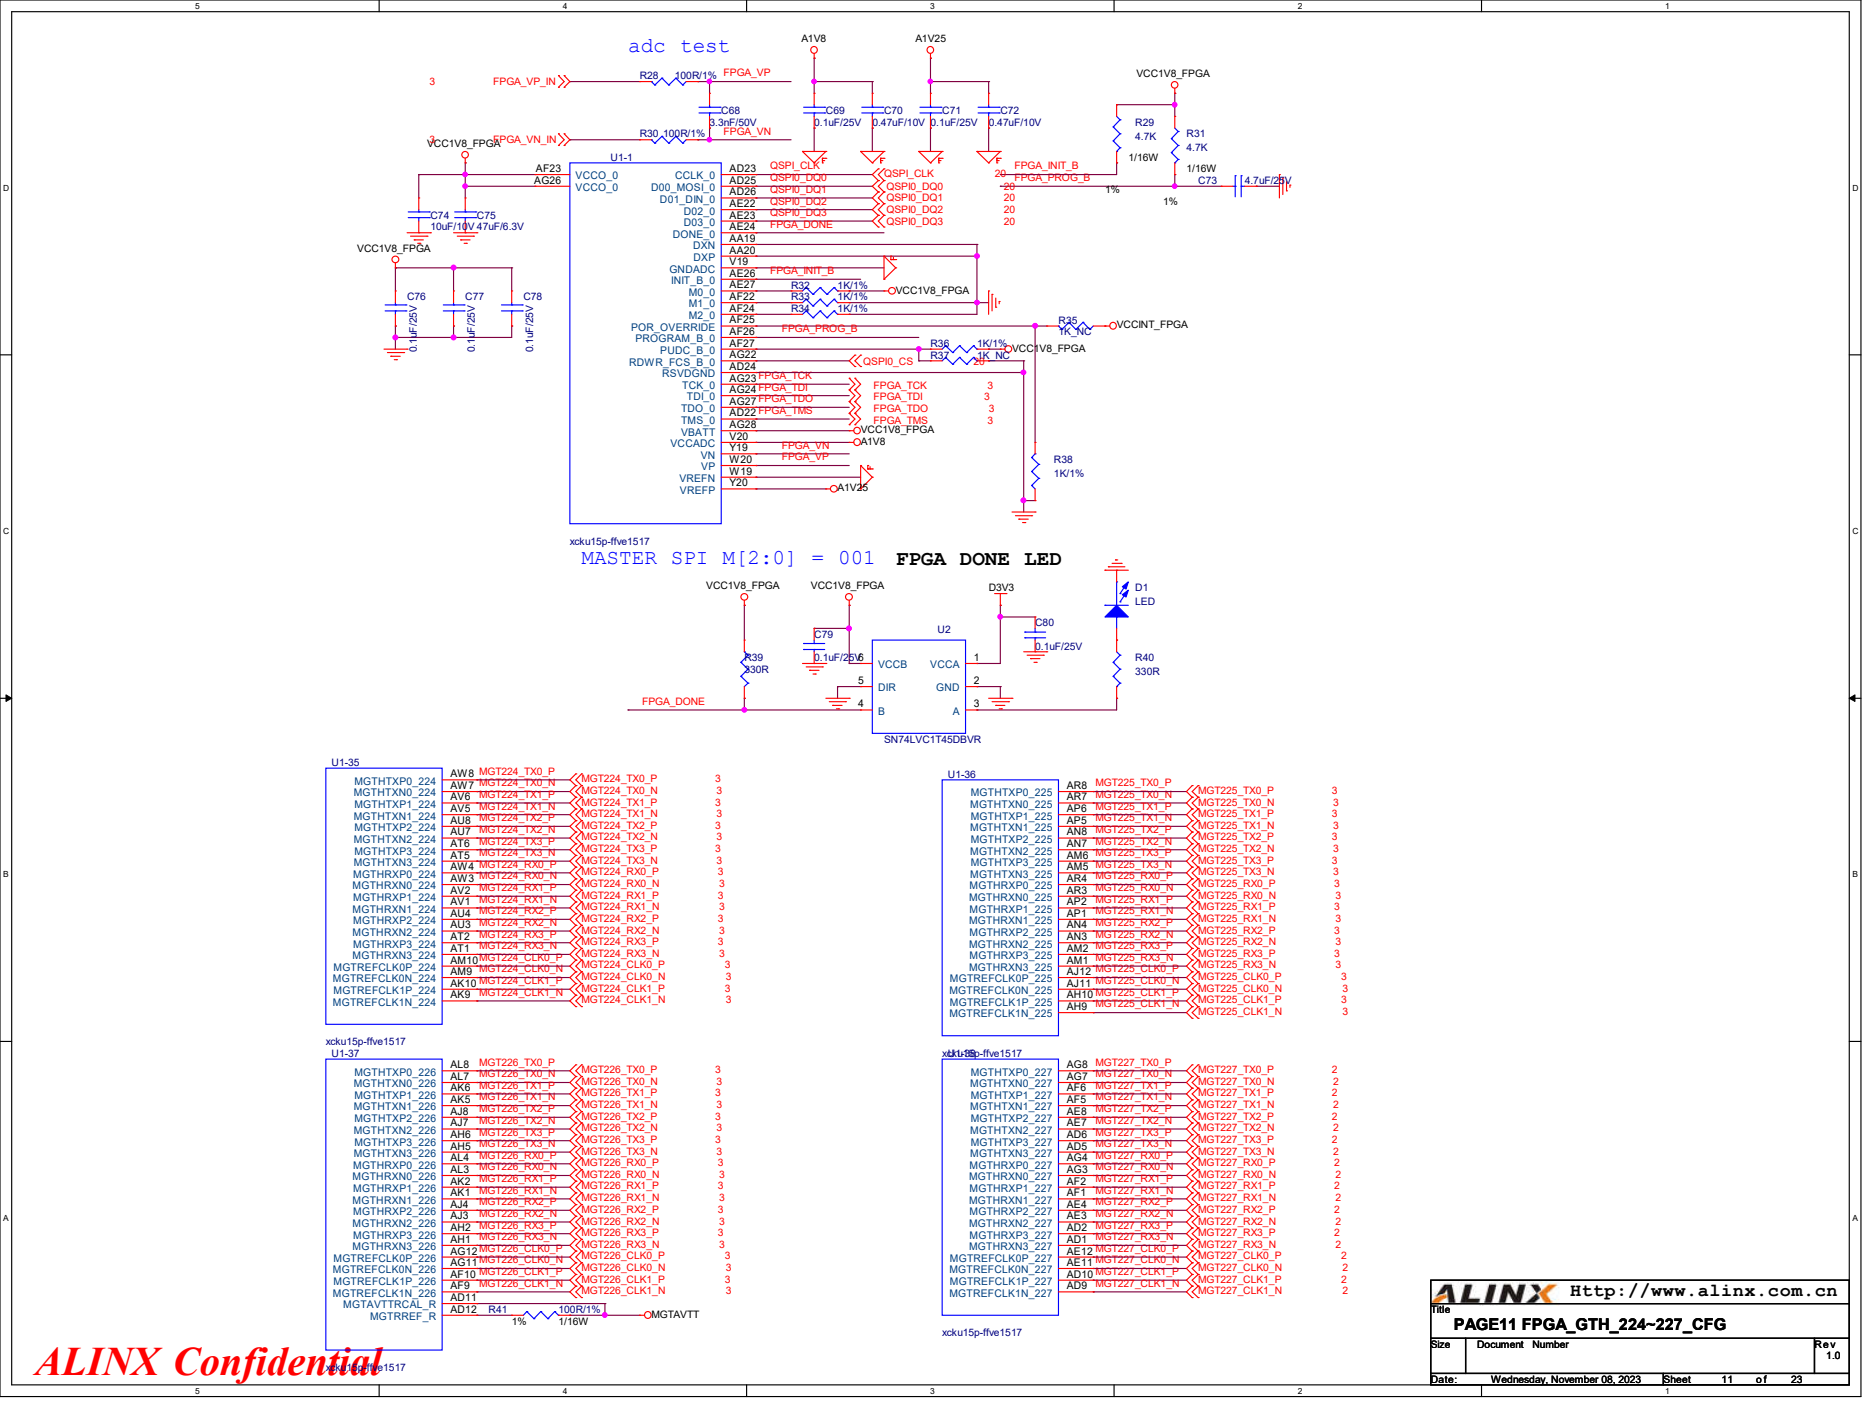
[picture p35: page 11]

xcku15p-ffve1517
MASTER SPI M[2:0] = 001 FPGA DONE LED

Http://www.alinx.com.cn

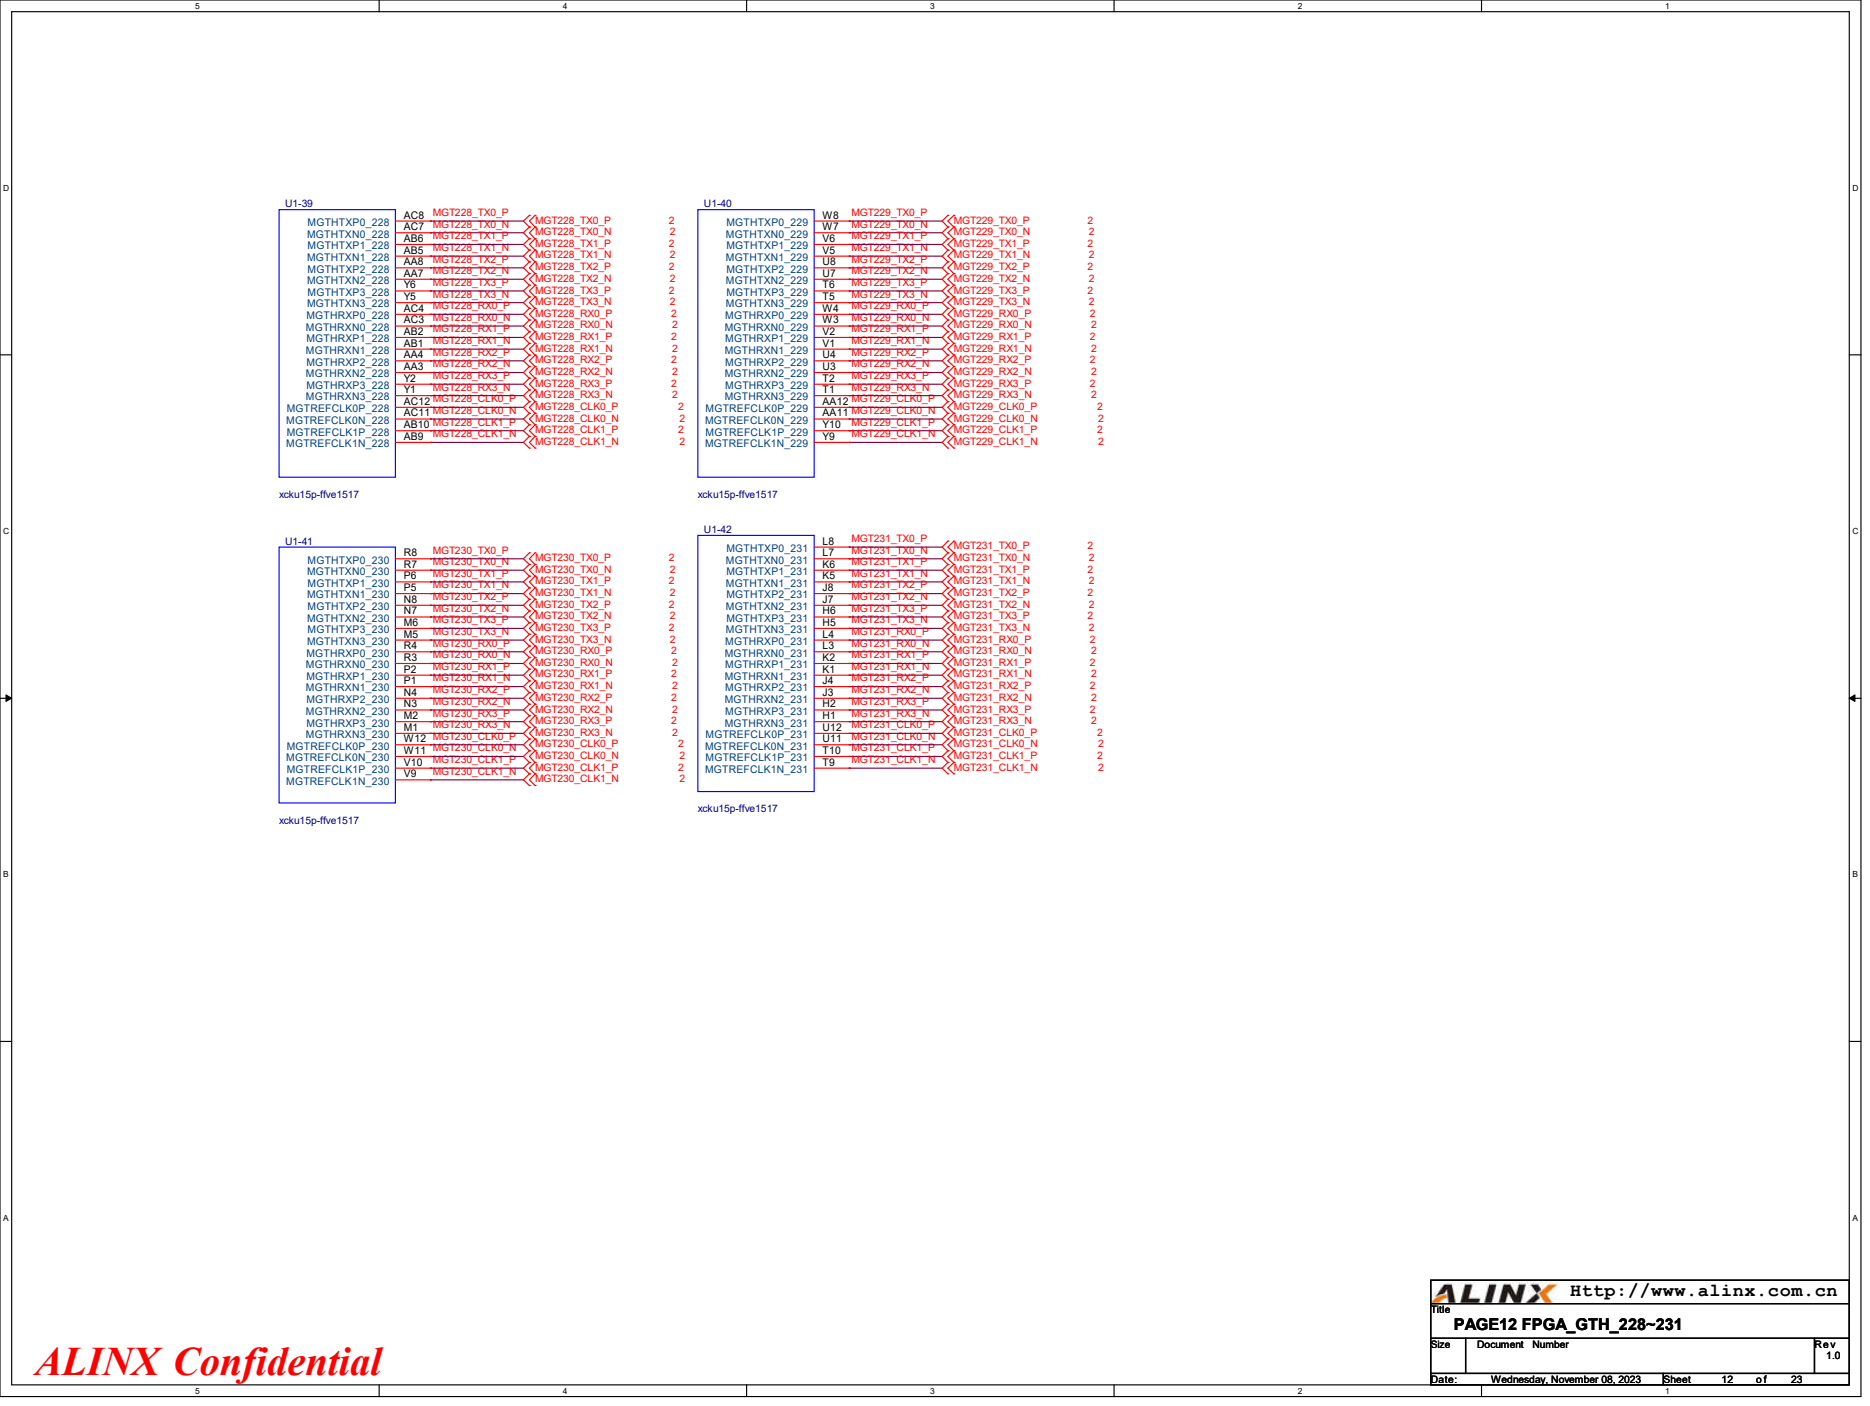
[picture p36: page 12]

Http://www.alinx.com.cn


Http://www.alinx.com.cn

VCCINTIO_BRAM_FPGA 0.85V@3A | VCCINT/VCCINT_IO/VCC_BRAM | together @20~30A

0.85V


Http://www.alinx.com.cn


Http://www.alinx.com.cn


GND AE5 GND AE9 GND AF11 GND AF13 GND AF15 GND AF17 GND AF19 GND AF21 GND AF28 GND AF29 GND AF3 GND AF30 GND AF33 GND AF34 GND AF35 GND AF38 GND AF39 GND AF4 GND AF7 GND AG1 GND AG13 GND AG14 GND AG16 GND AG18 GND AG2 GND AG20 GND AG29 GND AG30 GND AG31 GND AG32 GND AG33 GND AG34 GND AG35 GND AG36 GND AG37 GND AG5 GND AG9 GND AH11 GND AH13 GND AH15 GND AH19 GND AH24 GND AH28

GND A32 GND A35 GND A36 GND A37 GND A38 GND A5 GND AA1 GND AA13 GND AA14 GND AA16 GND AA18 GND AA2 GND AA22 GND AA24 GND AA26 GND AA28 GND AA32 GND AA35 GND AA36 GND AA37 GND AA5 GND AA9 GND AB11 GND AB13 GND AB15 GND AB17 GND AB19 GND AB21 GND AB23 GND AB25 GND AB26 GND AB3 GND AB30 GND AB34 GND AB35 GND AB38

GND T23 GND T25 GND T26 GND T3 GND T30 GND T34 GND T35


DDR POWER For VTT/VREF

http://www.alinx.com



# FPGA CONFIG SPI


Http://www.alinx.com.cn

# +12V POWER INPUT



# VCCINT>MGTAVCC(0.9V)>MGTAVTT(1.2V)


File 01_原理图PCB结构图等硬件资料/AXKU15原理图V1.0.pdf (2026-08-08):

ALINX Confidential; Title; Size; Document Number; Date:; Sheet; AXKU15扩展板Schematics; PAGE01 BLOCK DIAGRAM; Friday, November 24, 2023


Http://www.alinx.com.cn



Http://www.alinx.com.cn


# Ethernet Port

## Disable internal LDO


V_SEL=10: RGMII IO Voltage is 3.3V

Http://www.alinx.com.cn

# PCIE X16


Http://www.alinx.com.cn

# Digital Temperature Sensor


Http://www.alinx.com.cn

# USB Uart

# JTAG Connector


Http://www.alinx.com.cn


Http://www.alinx.com.cn


Http://www.alinx.com


Http://www.alinx.com

FMC1_GBTCLK1_M2C_P FMC1_GBTCLK1_M2C_N; FMC1_GBTCLK1_M2C_P; FMC1_GBTCLK1_M2C_N; FMC1_DP1_M2C_P; FMC1_DP1_M2C_N; FMC1_DP2_M2C_P; FMC1_DP2_M2C_N; FMC1_DP3_M2C_P; FMC1_DP3_M2C_N; FMC1_DP4_M2C_P; FMC1_DP4_M2C_N; FMC1_DP5_M2C_P; FMC1_DP5_M2C_N; FMC1_DP1_C2M_P; FMC1_DP1_C2M_N; FMC1_DP2_C2M_P; FMC1_DP2_C2M_N; FMC1_DP3_C2M_P; FMC1_DP3_C2M_N; FMC1_DP4_C2M_P; FMC1_DP4_C2M_N; FMC1_DP5_C2M_P; FMC1_DP5_C2M_N; FMC1_DP6_M2C_P; FMC1_DP6_M2C_N; FMC1_DP7_M2C_P; FMC1_DP7_M2C_N; FMC1_DP6_C2M_P; FMC1_DP6_C2M_N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

Http://www.alinx.com


Http://www.alinx.com


Http://www.alinx.com

FMC2_DP1_M2C_N; FMC2_DP1_M2C_P; FMC2_DP2_M2C_N; FMC2_DP2_M2C_P; FMC2_DP3_M2C_N; FMC2_DP3_M2C_P; FMC2_DP4_M2C_P FMC2_DP4_M2C_N; FMC2_DP5_M2C_N; FMC2_DP5_M2C_P; FMC2_DP6_M2C_N; FMC2_DP6_M2C_P; FMC2_DP7_M2C_N; FMC2_DP7_M2C_P; FMC2_DP1_C2M_P FMC2_DP1_C2M_N; FMC2_DP2_C2M_P FMC2_DP2_C2M_N; FMC2_DP3_C2M_P FMC2_DP3_C2M_N; FMC2_DP4_C2M_P FMC2_DP4_C2M_N; FMC2_DP5_C2M_P FMC2_DP5_C2M_N; FMC2_DP6_C2M_P FMC2_DP6_C2M_N; FMC2_DP7_C2M_P FMC2_DP7_C2M_N; FMC2_GBTCLK1_M2C_P FMC2_GBTCLK1_M2C_N; FMC2_GBTCLK1_M2C_P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

Http://www.alinx.com



# QSFP 1


Http://www.alinx.com

# SATA POWER


Http://www.alinx.com

# 12V/5A AC Adapter


Http://www.alinx.com

# default: +1.8V POWER




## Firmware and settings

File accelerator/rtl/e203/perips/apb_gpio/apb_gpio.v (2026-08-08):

// Copyright 2017 ETH Zurich and University of Bologna.
// -- Adaptable modifications made for hbirdv2 SoC. -- 
// Copyright 2020 Nuclei System Technology, Inc.
// Copyright and related rights are licensed under the Solderpad Hardware
// License, Version 0.51 (the “License”); you may not use this file except in
// compliance with the License.  You may obtain a copy of the License at
// http://solderpad.org/licenses/SHL-0.51. Unless required by applicable law
// or agreed to in writing, software, hardware and materials distributed under
// this License is distributed on an “AS IS” BASIS, WITHOUT WARRANTIES OR
// CONDITIONS OF ANY KIND, either express or implied. See the License for the
// specific language governing permissions and limitations under the License.

`define REG_PADDIR      4'b0000 //BASEADDR+0x00
`define REG_PADIN       4'b0001 //BASEADDR+0x04
`define REG_PADOUT      4'b0010 //BASEADDR+0x08
`define REG_INTEN       4'b0011 //BASEADDR+0x0C
`define REG_INTTYPE0    4'b0100 //BASEADDR+0x10
`define REG_INTTYPE1    4'b0101 //BASEADDR+0x14
`define REG_INTSTATUS   4'b0110 //BASEADDR+0x18
`define REG_IOFCFG      4'b0111 //BASEADDR+0x1C

`define REG_PADCFG0     4'b1000 //BASEADDR+0x20
`define REG_PADCFG1     4'b1001 //BASEADDR+0x24
`define REG_PADCFG2     4'b1010 //BASEADDR+0x28
`define REG_PADCFG3     4'b1011 //BASEADDR+0x2C
`define REG_PADCFG4     4'b1100 //BASEADDR+0x30
`define REG_PADCFG5     4'b1101 //BASEADDR+0x34
`define REG_PADCFG6     4'b1110 //BASEADDR+0x38
`define REG_PADCFG7     4'b1111 //BASEADDR+0x3C

module apb_gpio
#(
    parameter APB_ADDR_WIDTH = 12  //APB slaves are 4KB by default
)
(
    input  wire                        HCLK,
    input  wire                        HRESETn,
    input  wire [APB_ADDR_WIDTH - 1:0] PADDR,
    input  wire [31:0]                 PWDATA,
    input  wire                        PWRITE,
    input  wire                        PSEL,
    input  wire                        PENABLE,
    output reg  [31:0]                 PRDATA,
    output wire                        PREADY,
    output wire                        PSLVERR,

    input  wire [31:0]                 gpio_in,
    output wire [31:0]                 gpio_in_sync,
    output wire [31:0]                 gpio_out,
    output wire [31:0]                 gpio_dir,
    output reg  [191:0]                gpio_padcfg,
    output wire [31:0]                 gpio_iof,
    output reg                         interrupt
);

    reg [31:0]  r_gpio_inten;
    reg [31:0]  r_gpio_inttype0;
    reg [31:0]  r_gpio_inttype1;
    reg [31:0]  r_gpio_out;
    reg [31:0]  r_gpio_dir;
    reg [31:0]  r_gpio_sync0;
    reg [31:0]  r_gpio_sync1;
    reg [31:0]  r_gpio_in;
    reg [31:0]  r_iofcfg;
    wire [31:0] s_gpio_rise;
    wire [31:0] s_gpio_fall;
    wire [31:0] s_is_int_rise;
    wire [31:0] s_is_int_fall;
    wire [31:0] s_is_int_lev0;
    wire [31:0] s_is_int_lev1;
    wire [31:0] s_is_int_all;
    wire        s_rise_int;

    wire [3:0]  s_apb_addr;
    reg [31:0]  r_status;

    assign s_apb_addr    = PADDR[5:2];
    assign gpio_in_sync  = r_gpio_sync1;
    assign s_gpio_rise   = r_gpio_sync1 & ~r_gpio_in;    //foreach input check if rising edge
    assign s_gpio_fall   = ~r_gpio_sync1 & r_gpio_in;    //foreach input check if falling edge

    assign s_is_int_rise = (r_gpio_inttype1 & ~r_gpio_inttype0) & s_gpio_rise;    // inttype 01 rise
    assign s_is_int_fall = (r_gpio_inttype1 & r_gpio_inttype0) & s_gpio_fall;     // inttype 00 fall
    assign s_is_int_lev0 = (~r_gpio_inttype1 & r_gpio_inttype0) & ~r_gpio_in;     // inttype 10 level 0
    assign s_is_int_lev1 = (~r_gpio_inttype1 & ~r_gpio_inttype0) & r_gpio_in;     // inttype 11 level 1

    //check if bit if interrupt is enable and if interrupt specified by inttype occurred
    assign s_is_int_all  = r_gpio_inten & (((s_is_int_rise | s_is_int_fall) | s_is_int_lev0) | s_is_int_lev1);
    
    //is any bit enabled and specified interrupt happened?
    assign s_rise_int    = |s_is_int_all;


    always @(posedge HCLK or negedge HRESETn) begin
        if (~HRESETn) begin
            interrupt <= 1'b0;
            r_status  <= 'h0;
	end else if (!interrupt && s_rise_int) begin //rise interrupt if not already rise
            interrupt <= 1'b1;
            r_status  <= s_is_int_all;
	end else if ((((interrupt && PSEL) && PENABLE) && !PWRITE) && (s_apb_addr == `REG_INTSTATUS)) begin    //clears int if status is read
            interrupt <= 1'b0;
            r_status  <= 'h0;
        end
    end

    always @(posedge HCLK or negedge HRESETn) begin
        if (~HRESETn) begin
            r_gpio_sync0 <= 'h0;
            r_gpio_sync1 <= 'h0;
            r_gpio_in    <= 'h0;
	end else begin
            r_gpio_sync0 <= gpio_in;          //first 2 sync for metastability resolving
            r_gpio_sync1 <= r_gpio_sync0;
            r_gpio_in    <= r_gpio_sync1;     //last reg used for edge detection
        end
    end
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

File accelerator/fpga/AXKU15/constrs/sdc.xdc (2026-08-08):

# AXKU15版本引脚约束文件

# Clock signal - 200MHz差分时钟（只在输入端口定义主时钟）
create_clock -period 5.000 -name sys_clk [get_ports sys_clk_p]
set_property PACKAGE_PIN AR32 [get_ports sys_clk_p]
set_property PACKAGE_PIN AT32 [get_ports sys_clk_n]
set_property IOSTANDARD DIFF_SSTL12 [get_ports sys_clk_p]
set_property IOSTANDARD DIFF_SSTL12 [get_ports sys_clk_n]

set_property CLOCK_DEDICATED_ROUTE FALSE [get_nets dut_io_pads_jtag_TCK_i_ival]
set_property CLOCK_DEDICATED_ROUTE FALSE [get_nets IOBUF_jtag_TCK/O]

# 设置输入时钟抖动
set_input_jitter [get_clocks sys_clk] 0.1

# 定义MMCM输出时钟（派生时钟）
# 200MHz -> 16MHz: 200 * 2 / 25 = 16MHz
create_generated_clock -name clk_16M -source [get_ports sys_clk_p] -divide_by 25 -multiply_by 2 [get_pins ip_mmcm/inst/clk_out1]

# 32.768KHz时钟：16MHz / 488 ≈ 32.787KHz
# 暂时注释掉，如果需要可以手动添加
# create_generated_clock -name CLK32768KHZ -source [get_pins ip_mmcm/inst/clk_out1] -divide_by 488 [get_nets CLK32768KHZ]

# 添加时钟组约束，确保不同时钟域之间的正确处理
# set_clock_groups -asynchronous -group [get_clocks sys_clk] -group [get_clocks clk_16M]

# Reset - 使用用户按键作为复位信号（文档中有明确定义）
  # KEY1 -> fpga_rst
set_property -dict {PACKAGE_PIN A8 IOSTANDARD LVCMOS33} [get_ports fpga_rst]
   # KEY2 -> mcu_rst
set_property -dict {PACKAGE_PIN B9 IOSTANDARD LVCMOS33} [get_ports mcu_rst]

# QSPI Flash接口 - 使用正确的数组索引语法
# QSPI0_DQ0
set_property -dict {PACKAGE_PIN AM12 IOSTANDARD LVCMOS18} [get_ports {qspi0_dq[0]}]
# QSPI0_DQ1
set_property -dict {PACKAGE_PIN AN12 IOSTANDARD LVCMOS18} [get_ports {qspi0_dq[1]}]
# QSPI0_DQ2
set_property -dict {PACKAGE_PIN AR13 IOSTANDARD LVCMOS18} [get_ports {qspi0_dq[2]}]
# QSPI0_DQ3
set_property -dict {PACKAGE_PIN AR12 IOSTANDARD LVCMOS18} [get_ports {qspi0_dq[3]}]
# QSPI0_CS
set_property -dict {PACKAGE_PIN AV11 IOSTANDARD LVCMOS18} [get_ports qspi0_cs]

# JTAG连接（如果需要）
set_property -dict {PACKAGE_PIN K23 IOSTANDARD LVCMOS18} [get_ports mcu_TDO]
set_property -dict {PACKAGE_PIN K24 IOSTANDARD LVCMOS18} [get_ports mcu_TCK]
set_property -dict {PACKAGE_PIN K20 IOSTANDARD LVCMOS18} [get_ports mcu_TDI]
set_property -dict {PACKAGE_PIN K21 IOSTANDARD LVCMOS18} [get_ports mcu_TMS]
set_property KEEPER true [get_ports mcu_TMS]
# PMU唤醒信号 - 使用用户LED作为输出指示
   # LED1
set_property -dict {PACKAGE_PIN D8 IOSTANDARD LVCMOS33} [get_ports pmu_paden]
  # LED2
set_property -dict {PACKAGE_PIN D7 IOSTANDARD LVCMOS33} [get_ports pmu_padrst]
  # LED3
set_property -dict {PACKAGE_PIN D11 IOSTANDARD LVCMOS33} [get_ports mcu_wakeup]

# 异步复位路径约束
set_false_path -from [get_ports fpga_rst]
set_false_path -from [get_ports mcu_rst]

# Bitstream配置（参考LED例程）
set_property CONFIG_MODE SPIx8 [current_design]
set_property BITSTREAM.CONFIG.CONFIGFALLBACK Enable [current_design]
set_property BITSTREAM.CONFIG.CONFIGRATE 85.0 [current_design]
set_property BITSTREAM.CONFIG.SPI_32BIT_ADDR YES [current_design]
set_property BITSTREAM.CONFIG.SPI_BUSWIDTH 8 [current_design]
set_property BITSTREAM.CONFIG.SPI_FALL_EDGE YES [current_design]
set_property BITSTREAM.GENERAL.COMPRESS TRUE [current_design]
set_property BITSTREAM.CONFIG.UNUSEDPIN Pulldown [current_design]

# 调试串口配置 - 使用开发板专用串口引脚_cy
set_property -dict {PACKAGE_PIN D2 IOSTANDARD LVCMOS33} [get_ports uart_tx]
set_property -dict {PACKAGE_PIN D1 IOSTANDARD LVCMOS33} [get_ports uart_rx]

# UART时序约束_cy (暂时注释掉，避免引用不存在的时钟)
# set_input_delay -clock [get_clocks clk_16M] -min 1.000 [get_ports uart_rx]
# set_input_delay -clock [get_clocks clk_16M] -max 3.000 [get_ports uart_rx]
# set_output_delay -clock [get_clocks clk_16M] -min 1.000 [get_ports uart_tx]
# set_output_delay -clock [get_clocks clk_16M] -max 3.000 [get_ports uart_tx]

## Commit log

2026-08-08 chore: import graduate workspace baseline
    [ACKU15_length20240308.xls, ACKU15尺寸图-BOT.dxf, ACKU15尺寸图-TOP.dxf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]
2026-08-08 build: pin FLOOD to sbt 1.12.15
2026-08-08 feat: add fused elementwise diffusion rtl
2026-08-09 feat: schedule fused block with tile buffers
2026-08-09 feat: add dma planning and performance counters
2026-08-09 feat: add AXKU15 board bringup flow
2026-08-09 feat: add tensor read DMA over MIG
2026-08-09 feat: add tensor write DMA over MIG
2026-08-09 feat: bind DMA completion to block phases
2026-08-09 feat: add tensor DMA load buffer
2026-08-09 feat: buffer DMA load beats before compute
2026-08-09 feat: assemble buffered tensor vectors
2026-08-10 feat: stream fused vectors into store DMA
2026-08-10 test: cover internal fused result store path
2026-08-11 feat: count external backpressure stalls
2026-08-11 docs: defer board integration until RTL verification
2026-08-11 test: verify full AXI64 ResNetBlock flow
2026-08-12 docs: design two-vector DMA verification
2026-08-12 docs: plan two-vector DMA verification
2026-08-12 test: verify two-vector ResNetBlock DMA flow
2026-08-12 test: validate two-vector ResNetBlock DMA flow
2026-08-12 test: verify three-vector ResNetBlock DMA flow
2026-08-12 test: verify nonzero-mean ResNetBlock flow
